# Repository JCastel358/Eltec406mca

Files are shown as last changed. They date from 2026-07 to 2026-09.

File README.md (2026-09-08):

# Eltec sensor test rigs

Bench rigs and software that qualify Eltec pyroelectric IR sensors. Two rigs
live in this repository, one top-level folder each:

- **`single_detector_rig/`** — an ESP32 chops an IR emitter and streams a
  24-bit ADS1256 ADC to a laptop; one Python desktop application runs the
  test procedure for the sensor model chosen in a dropdown, judges each part,
  and writes a CSV row per sensor.
- **`array_rig/`** — fifty detectors at once: a 50-position buffer PCB read
  by an ACCES USB-AIO16-64MA DAQ; the same selector-plus-model-directory
  structure, testing offset and noise per tray (sensitivity waits for the
  emitter board).

Windows 11 and Xubuntu are both supported.

| Sensor model | Procedure | Status (2026-09-02) | Results folder (`Documents\…`) |
| --- | --- | --- | --- |
| **405 M22** (1 Hz) | TP412 — offset, emitter-off noise, sensitivity/polarity | production; sensitivity factor 4.30 from lot 500 | `Eltec_405M22_Test_Results\405m22_esp32` |
| **406 MCA** (10 Hz) | offset, sensitivity/polarity, v6.1 stability policy | production; factor 1.582 from lot 520 | `Eltec_406MCA_Test_Results\v6_1_esp32` |
| **449 M18** (5 + 18 Hz) | TP443 frequency tracking | **calibration pending** (K_5 / K_18 not derived; needs firmware v3.2, not yet flashed) | `Eltec_449M18_Test_Results\449m18_esp32` |
| **40623 array** (50 positions, DAQ) | TP120 offset check + noise, fifty at a time | **calibration pending** (noise limits not derived, offset limits provisional; raw captures saved for the paired lot) | `Eltec_40623_Test_Results\40623_array_daq` |

---

## I'm a technician — run a batch

1. Laptop on AC power, ESP32 USB cable in, both batteries connected, no fans near the fixture.
2. Double-click the **Eltec Test Rig** desktop icon (or `single_detector_rig\run_eltec_rig_tester.cmd` / `.sh`). For a tray of fifty on the array rig use the **Eltec Array Rig** icon (`array_rig\run_eltec_array_tester.cmd` / `.sh`) — runbook §3b.
3. Pick the sensor model → **Start tester** → batch number, your name, filter setup → load a part → **Enter**.
4. Read the banner (PASS / PASS · NEAR LIMIT / FAIL) → load the next sensor →
   **Next (Enter)**. The number only advances when a part passes.

Everything else — verdicts, the Stop / Next buttons, where files go,
what to do when something fails — is in
**[docs/TECHNICIAN_RUNBOOK.md](docs/TECHNICIAN_RUNBOOK.md)**.

## I'm the engineer taking over

Start with **[docs/ENGINEER_HANDOVER.md](docs/ENGINEER_HANDOVER.md)** (what
you are inheriting, architecture, the copy-per-model rule, firmware lifecycle,
open work). Then **[docs/CALIBRATION_RECORD.md](docs/CALIBRATION_RECORD.md)**
before touching any limit.

## Repository map

```
README.md                    this file — the index
CHANGELOG.md                 dated history, newest first (one entry per behavioural change)
CLAUDE.md                    ground rules for AI-assisted sessions
run_all_tests.py|.cmd|.sh    runs every test suite of both rigs, prints a summary
docs/
  TECHNICIAN_RUNBOOK.md      operator instructions
  ENGINEER_HANDOVER.md       engineering manual + open work
  CALIBRATION_RECORD.md      every limit/factor/gate state with provenance  ← source of truth for numbers
  DATA_MAP.md                where results & evidence live (outside the repo) + backup routine
  TP120(40623).pdf           test procedure of the 40623 (array rig); daq_usb_aio16_64ma/ = DAQ vendor docs
single_detector_rig/         THE single-detector application — selector + one directory per sensor model
  eltec_rig_tester.py        selector GUI (dropdown → launches the model app)
  sensor_versions.py         model registry + required firmware
  attempt_history.py         per-batch attempt log (shared)
  v1_single_sensor/          vendored signal-math engine (shared, frozen)
  m405m22/ m406mca/ m449m18/ one qualified tester each: GUI, backend, analysis, tests, launchers, README
  run_eltec_rig_tester.*     launchers; install_*_launcher.* = optional desktop icon
array_rig/                   THE array application — selector + one directory per detector model (same pattern)
  eltec_array_tester.py      selector GUI (model dropdown → launches the model app)
  sensor_versions.py         model registry + required hardware (DAQ)
  tray_history.py            per-lot tray event log (shared)
  m40623/                    the 40623 build: GUI, DAQ backend (ctypes AIOUSB.dll), numpy noise port, probe, bench readout + live viewer, tests, launchers
Arduino/Eltec/               firmware (single rig today; the array rig's emitter board will use it later)
  Eltec.ino                  live sketch (v3.2)        README.md = protocol, flashing, troubleshooting
  versions/                  frozen copy of every build + which firmware belongs on which rig
  flash_firmware.py          one-command compile/upload/verify (+ run_flash_firmware.cmd/.sh)
  esp32_rig_readout.py, live_waveform.py   bench tools
  ESP32_ADS1256_Wiring_v2_0.md             current wiring (…_legacy_v1_9.md = retired standalone 406 rigs)
engineer_tools/              engineering-only tools, one folder per topic (README.md inside lists them)
  noise_band/                replot_noise_capture.py (replay raw noise captures under any band), filter_response_analysis.py
  array_parity/              array_noise_parity.py (derive the array rig's pin-level noise limits from a paired lot)
  emitter/                   emitter_waveform_comparison.py (legacy chopper vs rig emitter waveform shape)
  reference_unit/            reference_candidate_qualifier.py (pick the detector to mount as the AIN1 reference unit)
analysis/
  405M22_Data/               lot-500 paired-fixture data behind the 4.30 factor
  reports/                   noise-filtering explainer, historical buffer/SNR write-ups
assets/eltec_logo.png        logo loaded by the apps
```

Retired applications (LabJack-era v1–v4, ESP32 v5/v6/v6.1, the standalone
405m22 build, the pre-v2.0 unified app) were removed from the tree on
2026-08-28 and are preserved at git tag **`archive/pre-cleanup-2026-08-28`**:
`git show archive/pre-cleanup-2026-08-28:<path>`.

## Firmware

The single-detector bench board must run `Arduino/Eltec/Eltec.ino` **v3.2** for all three
models (the array rig has no firmware: its DAQ loads its own from the ACCES driver package) (it currently runs v3.1; the 405 M22 and 406 MCA modes work on
v2.1–v3.2, the 449 M18 mode needs v3.2). Flash and verify with one command:

```
python Arduino/Eltec/flash_firmware.py          # --check to only ask what the board runs
```

Firmware guide: [Arduino/Eltec/README.md](Arduino/Eltec/README.md). Which
build belongs on which rig (legacy 406 rigs stay on v1.9):
[Arduino/Eltec/versions/README.md](Arduino/Eltec/versions/README.md).

## Tests

```
python run_all_tests.py
```

Six `unittest` suites (four for the single rig, two for the array rig), 705
tests, no hardware needed. On Windows the 406 MCA suite reports two known
environment-only cases (they pass on Xubuntu) — see the handover doc §7.

## Where the data is

Results, attempt logs, waveform snapshots, raw noise captures and calibration
files are written **outside this repository** under
`Documents\Eltec_<model>_Test_Results\`. They are the only copy of the evidence
behind the production constants — the backup routine is in
[docs/DATA_MAP.md](docs/DATA_MAP.md).

## Documentation index

| Document | Audience | Contents |
| --- | --- | --- |
| [docs/TECHNICIAN_RUNBOOK.md](docs/TECHNICIAN_RUNBOOK.md) | technician | start, run a batch, read verdicts, troubleshoot |
| [docs/ENGINEER_HANDOVER.md](docs/ENGINEER_HANDOVER.md) | engineer | architecture, policies, procedures, open work, conventions |
| [docs/CALIBRATION_RECORD.md](docs/CALIBRATION_RECORD.md) | engineer | constants + provenance + gate states per model |
| [docs/DATA_MAP.md](docs/DATA_MAP.md) | engineer | results layout, evidence, backup |
| [single_detector_rig/README.md](single_detector_rig/README.md) | engineer | the selector app, launchers, v2.0 skip/attempt features |
| [m405m22/README.md](single_detector_rig/m405m22/README.md) · [m406mca/README.md](single_detector_rig/m406mca/README.md) · [m449m18/README.md](single_detector_rig/m449m18/README.md) | engineer | per-model test mechanics |
| [array_rig/README.md](array_rig/README.md) · [m40623/README.md](array_rig/m40623/README.md) | engineer | the array rig: selector, DAQ chain, the 40623 flow, colours, files, PENDING status, the engineering tools (bench probe, readout, live viewer) |
| [docs/TP120(40623).pdf](docs/TP120(40623).pdf) · [docs/daq_usb_aio16_64ma/](docs/daq_usb_aio16_64ma/) | engineer | the 40623 test procedure; DAQ datasheet, DAQ-PACK guide, letter of volatility |
| [Arduino/Eltec/README.md](Arduino/Eltec/README.md) · [versions/README.md](Arduino/Eltec/versions/README.md) | engineer | firmware, protocol, flashing, version archive |
| [CHANGELOG.md](CHANGELOG.md) | both | what changed, when, why |

## Dependencies

Python 3 with `tkinter`, `numpy`, `pyserial`, `matplotlib` (optional, nicer
snapshots). The array rig additionally needs the ACCES **USB-AIO16-64MA
Install** driver package (provides `AIOUSB.dll`) and a **64-bit** Python; no
extra Python packages. Xubuntu: `sudo apt install python3 python3-tk python3-numpy
python3-serial python3-matplotlib`, user in `dialout`. Flashing needs the
Arduino IDE 2.x installed (its bundled `arduino-cli` is used).

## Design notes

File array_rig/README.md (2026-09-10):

# Eltec Array Rig — fifty detectors at once on a USB DAQ

The second test rig of this repository. A 50-position PCB (5 rows × 10
columns, one unity-gain buffer per position) feeds the 64 single-ended inputs
of an **ACCES I/O USB-AIO16-64MA DAQ-PACK**; one Python desktop application
tests a whole tray of detectors per run. It mirrors the single-detector rig
(`../single_detector_rig/`) in structure: a **selector** with a model
dropdown, a **registry**, and **one directory per detector model** that is a
deliberate near-copy of its siblings. The two rigs share nothing but the
repository, the docs and (later) the ESP32 firmware for the emitter board.

| Model | Procedure | What it measures today | Status | Results (`Documents\…`) |
| --- | --- | --- | --- | --- |
| **40623** | TP120 rev W | offset check (0.3–1.2 V) and noise, fifty at a time | **CALIBRATION PENDING** — noise limits not derived, offset limits provisional | `Eltec_40623_Test_Results\40623_array_daq` |

Sensitivity / polarity (TP120's 3 Hz chopper test) waits for the emitter
board. The operator screen focuses on offset and noise, with the Eltec logo
and a 5 × 10 map of round detector sockets labelled by row and column.
Sockets always show numerical offsets and, after capture, noise alongside status.
**Show more** adds assigned sensor numbers. **Choose loaded sockets** supports
partial trays; changes require a fresh offset measurement.

## Technician flow

1. Enter **Tech name** and **Batch number**. Load up to fifty detectors.
2. Use the rig's **physical power switch immediately before pressing
   Measure offset**. The app connects to the DAQ and reads the signals; it
   does not switch detector power or vacuum. Empty-looking sockets are
   rechecked together after two seconds and marked grey automatically.
   Green means offset in range; red means out of range. Low or dead-looking
   readings can still settle: recheck before discarding a part.
3. Replace red parts and press **Measure offset** again, as often as needed.
   If replacements run out, remove the remaining bad parts and measure
   offset again so empty sockets are detected. A socket marked loaded again
   requires a fresh offset read.
4. Turn on the vacuum, wait for the gauge to reach the required setting,
   and confirm both the vacuum setting and that the detected detector count
   and map match the physical tray. Press **Measure noise** once all loaded
   sockets have good offsets. The app checks waveform settling for 3–20
   seconds, then captures sixty seconds of noise.
5. Read the socket colours and status. Use **Show more** for measurements
   and assigned sensor numbers. Results save automatically; use
   **Next tray** after the save completes. **Stop** interrupts a measurement
   so it can be retried.

Tray and sensor numbers are automatic. Every offset read is retained for
audit, including reads taken before a detector is replaced. Automatic empty
detection is an inference: both median offset reads must be within one ADC
code of zero (about 76 µV on the 0–5 V range). A dead or shorted detector can
also read zero, so check the detected map and count before noise. Click a
socket containing a detector to mark it loaded; that manual choice wins
over automatic detection. The vacuum check is the operator's gauge
confirmation; the app has no pressure telemetry or configured vacuum setpoint.

Settling compares each loaded channel's one-second waveform maximum and
minimum. Two consecutive changes within 0.1 mV allow capture to start after
three seconds. At twenty seconds capture starts with a recorded warning
if the signal has not settled. This tolerance schedules capture and does
not decide pass/fail. The user's 2026-09-08 timing decision removes the
app's five-minute countdown: TP120 itself separately calls for five minutes
after power-on and 15–20 seconds after switching detectors on the legacy
fixture. The changed timing policy and settling evidence are logged.

Noise uses the nominal **3 Hz/Q=3 band-pass** from fixture 9000232, with RMS
and rectified metrics. Paired legacy/background qualification is still pending:
valid measurements show amber **REVIEW**, and both the app and CSV explicitly
withhold PASS. Short/clipped/unresolved data remains NOT MEASURED. See
[m40623/NOISE_METHOD.md](m40623/NOISE_METHOD.md) for the method, calibration
contract and replay tool. Simulation demonstrates example passes and failures.

## Run it

- Windows: double-click the **Eltec Array Rig** desktop icon, or
  `array_rig\run_eltec_array_tester.cmd`. Install the icon once with
  `powershell -ExecutionPolicy Bypass -File array_rig\install_windows_launcher.ps1`.
- Xubuntu: `./array_rig/run_eltec_array_tester.sh`; icon via
  `./array_rig/install_xubuntu_launcher.sh` (`--uninstall` removes it).
- The selector remembers the last model (`%LOCALAPPDATA%\eltec-array-rig\state.json`
  / `~/.local/state/eltec-array-rig/state.json`) and launches the model app
  as a **subprocess** with the model directory as cwd. Launcher logs:
  `…\eltec-array-rig\launcher.log`. The model app can also be started
  directly (`array_rig\m40623\run_eltec_40623_array_tester.cmd`). Check
  **Simulation** in the selector, or use `--simulate` (or
  `ELTEC_ARRAY_SIMULATE=1`), to run without hardware.
- Hardware: the ACCES **"USB-AIO16-64MA Install"** driver package must be
  installed (it provides `AIOUSB.dll`; the DAQ loads its firmware from the
  host at every plug-in, so allow a few seconds after connecting). A 64-bit
  Python is required (the 64-bit DLL lives in `System32`). No extra Python
  packages beyond the single rig's (`numpy`, `tkinter`, `matplotlib` for
  the grid snapshot).
- Engineering tools (no verdicts, files only at explicit paths), all in
  `array_rig\m40623\` and all with `--simulate`: `daq_bench_probe.py` (bench
  checks), `daq_rig_readout.py` (offsets, captures to CSV / npz, text-mode
  watch) and `daq_live_waveform.py` (rolling scope of any position) — see the
  m40623 README. Only one program can own the DAQ: close the tester before
  running one of them, and vice versa (a second program is not refused — it
  silently takes the stream away from the first).

The single-detector rig and this rig can run at the same time — different
hardware, different state folders.

Simulation shows a **SIMULATION** badge and runs the same operator flow on
a fast virtual clock. Click a red or empty socket to simulate loading a
replacement, then measure offset again; right-click to mark a socket empty.
Demo noise limits belong only to that simulator instance and results carry
a simulation flag and **SIMULATION ONLY** noise-limit provenance. Demo
files go under `tempfile.gettempdir()/eltec-array-simulation`, or the
`simulation` subfolder when `ELTEC_ARRAY_RESULTS_ROOT` is set.

## Layout

```
array_rig/
  eltec_array_tester.py      selector GUI: model dropdown → launches the model app as a SUBPROCESS
  sensor_versions.py         registry (one SensorVersion per model) + REQUIRED_HARDWARE
  tray_history.py            shared: <lot>_attempts.csv writer (tray events) + numbering helpers
  run_eltec_array_tester.*   launchers; install_*_launcher.* = optional desktop icon
  tests/                     selector glue + tray history
  m40623/                    the 40623 build (TP120) — see its README
      eltec_40623_array_tester.py   GUI + flow + limits + CSV/npz/PNG writers (TrayController is the Tk-free core)
      daq_backend.py                ctypes wrapper over AIOUSB.dll, de-interleave, stream integrity, SimulatedDaq
      array_analysis.py             numpy port of the single rig's noise DSP + TP120 offset classes + verdict model
      daq_bench_probe.py            engineering CLI (never issues verdicts)
      daq_rig_readout.py            engineering readout: ArrayRig API + CLI (offsets, captures to CSV / npz, text-mode watch) — the ESP32 readout's counterpart
      daq_live_waveform.py          engineering live viewer: matplotlib rolling scope of any position + the 5 x 10 grid — live_waveform.py's counterpart
      tests/                        unit + flow tests; golden_noise_reference.py is the frozen DSP oracle
      run_… / install_…             per-model launchers
```

Ownership rule inside a model directory: `daq_backend.py` is the hardware
boundary (no Tk), `array_analysis.py` is pure math (no I/O, no hardware), the
tester owns orchestration, UI and files; the probe, the readout and the live
viewer are engineering only — no verdicts, output files only at explicit
paths (never under `Documents`), and only one program on the DAQ at a time.

## Adding a model

The single rig's copy-per-model rule applies here, and additionally
**nothing is imported across the two rigs** (the only link is a frozen copy
of the 405 M22 noise functions used as a test oracle).

1. Copy `m40623/` to `m<model>/`, rename the tester and launcher identities
   (`eltec-<model>-array`, `com.eltec.<model>-array-tester.desktop`), and
   replace the spec constants in `array_analysis.py` (offset window, noise
   limits — `None` until derived) with provenance comments.
2. Append a `SensorVersion` to `sensor_versions.py` and extend the expected
   key set in `tests/test_eltec_array_rig.py`.
3. Add the suite to `run_all_tests.py`, a section to
   `docs/CALIBRATION_RECORD.md` (CALIBRATION PENDING until a paired lot
   exists — the 40623 section shows the pattern) and the results root to
   `docs/DATA_MAP.md`. CHANGELOG entry in the same commit.

## Tests

```
python run_all_tests.py                                        # every suite of both rigs
python -m unittest discover -s array_rig/tests                 # selector glue + tray history
python -m unittest discover -s array_rig/m40623/tests          # backend, analysis (golden parity), tester flow, readout, live viewer (Agg), engineer tools
```

Stdlib `unittest`, from the repository root, no hardware needed (the tests
use a scripted fake DLL and `SimulatedDaq`, and redirect the results root to
a temporary directory).

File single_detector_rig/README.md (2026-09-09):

# Eltec Test Rig — unified sensor tester

**2026-09-02 — two buttons (Stop, Next) and a number only a PASS can spend.**
See [Test flow](#test-flow) below; the v2.0 skip queue it replaced is in
`CHANGELOG.md`. Every
older app (`405m22_esp32`, `v6_1_esp32`, `v6_esp32`, `v5_esp32`, the v1–v4
LabJack apps, `v6_1_failure_calibration`) and a frozen snapshot of this app
as it was before v2.0 (`eltec_rig_v1`) were removed from the working tree on
2026-08-28; they are preserved in full at git tag
`archive/pre-cleanup-2026-08-28`
(`git show archive/pre-cleanup-2026-08-28:tech_app/deprecated/<app>/<file>`).

One desktop application for every sensor model the ESP32/ADS1256 rig can
test. It opens **maximized** and shows a **sensor version dropdown**; picking a
version and pressing **Start tester** runs that model's qualified tester
application unchanged — same test flow, thresholds, per-batch filter-setup dropdowns, CSV
format, and results folders as before. The selection is remembered between
sessions.

```
single_detector_rig/
├── eltec_rig_tester.py          # the selector GUI (this app's entry point)
├── sensor_versions.py           # registry: one entry per testable model
├── attempt_history.py           # per-batch *_attempts.csv event log (shared by all models)
├── m405m22/                     # Model 405 M22 (1 Hz, TP412) tester + its 165-test suite
├── m406mca/                     # Model 406 MCA (10 Hz, v6.1 policy) tester + its 99-test suite
├── m449m18/                     # Model 449 M18 (5 Hz + 18 Hz, TP443 frequency tracking) tester + suite
├── v1_single_sensor/            # shared 406MCA analysis/pass-fail engine (vendored)
├── assets/                      # desktop icon (.png for Linux, .ico for Windows)
├── run_eltec_rig_tester.sh      # Xubuntu launcher        ┐ double-click either
├── run_eltec_rig_tester.cmd     # Windows launcher        ┘ on its platform
├── install_xubuntu_launcher.sh  # opt-in Desktop + menu entry (`--uninstall` removes)
├── install_windows_launcher.ps1 # opt-in Desktop + Start Menu (`-Uninstall` removes)
└── tests/                       # selector/registry/launcher glue tests
```

## Sensor versions

| Dropdown entry | App | Emitter drive | ADS1256 front end | Results |
| --- | --- | --- | --- | --- |
| Model 405 M22 (1 Hz, TP412) | `m405m22/` | DUT 1 Hz, reference phases 10 Hz | firmware boot default (gain 1, buffer off) | `Documents/Eltec_405M22_Test_Results/405m22_esp32` |
| Model 406 MCA (10 Hz) | `m406mca/` | 10 Hz (boot default) | app sends `FE,V19` after connect → gain 2, buffer on (the qualified v1.9 front end) | `Documents/Eltec_406MCA_Test_Results/v6_1_esp32` |
| Model 449 M18 (5 Hz + 18 Hz, TP443) | `m449m18/` | DUT 5 Hz then 18 Hz, **20 % ON / 80 % OFF** (`PWM,DUTY`, firmware **v3.2**); reference phases 10 Hz / 50 % | firmware boot default (gain 1, buffer off) | `Documents/Eltec_449M18_Test_Results/449m18_esp32` |

The 449 M18 entry (added 2026-08-26) runs TP443 "449M18 Frequency Tracking":
sensitivity at 5 Hz, sensitivity at 18 Hz, and the 18/5 ratio, with the
spec-4 "measure the tray 100 %" flag. It is **calibration pending** — the
per-frequency fixture factors have not been derived yet, so it records raw
readings and the raw ratio and does not enforce the TP443 limits. See
[`m449m18/README.md`](m449m18/README.md).

Model-specific dropdowns (filter cap / filter setup, simulator cases, etc.)
live **inside** each model's app, exactly where they were before — choose the
sensor version first, then the batch's filter setup on the Batch information
screen.

## Firmware

The bench board runs the unified **`Arduino/Eltec/Eltec.ino` v3.2** baseline
(single-channel streaming, `PWM,FREQ`, `PWM,DUTY` (v3.2), runtime `FE,...`
front-end switch; the IR telescope's dual-channel code is *not* in it — that
lives in the separate `Eltec_IR_Telescope` workspace on firmware v2.2). The
405 M22 and 406 MCA modes also run on v2.1–v3.1; the 449 M18 mode refuses
anything older than v3.2 because it needs the duty-cycle command. Model
differences are selected at runtime over serial:

- **405 M22**: never sends `FE`; every port open resets the board to the
  boot-default gain-1 unbuffered front end, and the app programs `PWM,FREQ,1`
  for the DUT phases.
- **449 M18**: never sends `FE` either; programs `PWM,FREQ,5` + `PWM,DUTY,20`
  and then `PWM,FREQ,18` + `PWM,DUTY,20` for the two TP443 drives (the legacy
  fixture's 20/80 blade), `PWM,FREQ,10` + `PWM,DUTY,50` for the reference
  phases. A port open resets the board to 50 %, so the other models never
  see the changed duty.
- **406 MCA**: sends `FE,V19` right after the `IDN?` handshake on any
  firmware ≥ v2.1 and hard-verifies the `FE?` read-back — measuring a 406MCA
  on the wrong front end would invalidate every qualified threshold, so a
  mismatch refuses the connection. On a legacy standalone rig still flashed
  with v1.9, no `FE` command is sent (that firmware is natively the
  qualified front end).

Flash/verify - one command, no Arduino IDE needed (it finds the IDE's bundled
`arduino-cli`, auto-detects the board's port, compiles, uploads, then confirms
`IDN?`/`GATE?` over serial):

```bash
python3 Arduino/Eltec/flash_firmware.py
```

Windows: double-click `Arduino\Eltec\run_flash_firmware.cmd`. Xubuntu:
`Arduino/Eltec/run_flash_firmware.sh`. Useful flags: `--list` (show serial
ports), `--check` (report what the board runs, flash nothing), `--port COM7`,
`--sketch versions/Eltec_v2_2` (put the board on an archived build). The
equivalent by hand:

```bash
arduino-cli compile --fqbn esp32:esp32:esp32doit-devkit-v1 Arduino/Eltec
arduino-cli upload -p COM3 --fqbn esp32:esp32:esp32doit-devkit-v1 Arduino/Eltec
# then confirm: IDN? -> ELTEC-ESP32-ADS1256,v3.1
```

## Fixture notes (2026-08-18)

- **Battery monitoring is disabled in both models** (`BATTERY_MONITORING_ENABLED
  = False` in each tester): since the 2026-08-12 rewiring the 6.5 V battery
  drives the emitters only, the 9 V battery drives the sensors, and neither is
  measurable on the legacy AIN7 divider. The header shows "Battery: not
  monitored". Re-enable per model once the sensor battery is measurable (the
  plan is AIN6 through a ≥4:1 divider).
- **All three models' reference gates are live again** (`REFERENCE_GATE_ENABLED
  = True` since 2026-09-09, on the channel-isolated buffer board). AIN1 is
  read before every sensor and must hold its ±25 % window, so a failing
  emitter is caught by the rig instead of showing up as a run of
  low-sensitivity parts. **Every rig must run "Calibrate reference unit"
  before its next batch**: the stored baselines were all recorded through the
  old shared op-amp buffer and are refused on load (schema bump), so testing
  stays locked until a fresh one exists. The crosstalk re-check on the new
  board is still outstanding — if the reference turns out to still follow the
  loaded part, set the flag back to `False` rather than widening the window
  (calibration record §2.4).

## Running it

| | Xubuntu | Windows |
| --- | --- | --- |
| run | `./single_detector_rig/run_eltec_rig_tester.sh` | double-click `single_detector_rig\run_eltec_rig_tester.cmd` |
| desktop icon | `./single_detector_rig/install_xubuntu_launcher.sh` | `powershell -ExecutionPolicy Bypass -File single_detector_rig\install_windows_launcher.ps1` |
| log | `~/.local/state/eltec-rig/launcher.log` | `%LOCALAPPDATA%\eltec-rig\launcher.log` |

Both installers are opt-in and per-user (`--uninstall` / `-Uninstall` to
remove). `ELTEC_PYTHON` overrides the interpreter on both platforms;
`ELTEC_LAUNCHER_NO_DIALOG=1` suppresses the Windows error popup for headless
runs. Dependencies are the same as the individual apps: Python 3 with
`tkinter`, `numpy`, `pyserial`, and `matplotlib` (see each model's README).

The selector remembers the last-used sensor version in
`~/.local/state/eltec-rig/state.json` (Xubuntu) /
`%LOCALAPPDATA%\eltec-rig\state.json` (Windows). Only one tester can run at a
time — both models share the same board and serial port.

## Test flow

### Two screens and two buttons (2026-09-02)

There are two steps — **Batch information** and **Measure & result** — and
the action bar carries exactly two controls:

| Button | Colour | When shown | What it does |
| --- | --- | --- | --- |
| **Stop** / **Stop batch (Esc)** | **red** | every moment of a batch, never disabled | mid-capture: abandons the reading (nothing recorded, the number does not move). Idle: writes an unsaved verdict (no prompt since 2026-09-03), then ends the batch |
| **Start (Enter)** → **Next sensor (Enter)** | blue → **green** | setup → result | reads the sensor that is in the rig now; on a verdict it writes the row first |

The technician loads a part, presses Start (first) or Next (every one after)
and the read begins immediately — there is no "load the next sensor" screen
in between, because the part is loaded before the button is pressed. The old
load STEP's card (rig picture, and the 405's noise-soak toggle) moved onto
the setup screen; the 405 soak toggle also sits on the result card, where it
arms the read **Next** is about to take, and `run_measurement` clears it as
it starts so it never carries into a second part.

**Stop is the only control that is never disabled.** It works mid-capture
because it bumps `measure_token`, which the capture loops already poll
through their `cancelled=` callback: the loop raises at its next chunk
boundary, the worker's own `finally` blocks stop the stream and switch the
emitter off, and every callback that worker posts afterwards is ignored by
the token guard. A `stopped` row goes into the attempt log; no verdict row is
written.

**The bar always fits the window** (`_fit_footer`, all models). Two full-size
buttons fit any rig screen, but the blocked-measure labels ("Calibrate
reference unit to test") still need the ladder the six-button bar did: it
measures what the visible buttons need and takes the first
`FOOTER_VARIANTS` step that fits, preferring big buttons over spelled-out
labels:

1. full labels, one row;
2. drop the `(Enter)` / `(Esc)` hints (the shortcuts still work);
3. compact wording — *Next*, *Stop*, *Calibrate reference first*;
4. wrap the action buttons onto their own row, still full size;
5. only then step the buttons down a size.

It is bound to the footer's `<Configure>`, so it re-fits when the window is
maximized or resized — including growing back to full labels — and it works
the same on Windows and Xubuntu (the fit is measured from the actual font
metrics, not a hardcoded width). The "nothing was recorded" view keeps its
**Record as NOT MEASURED** option (writes the NOT MEASURED verdict row);
Next there simply reads the same sensor again.

There is no Re-measure button, which is a real trade-off: a verdict already
on screen cannot be discarded. It is saved as what it says — on a FAIL that
costs nothing, because the number stays open — or the reading is stopped
before it finishes so nothing is written at all.

### A sensor number is only spent by a PASS

`next_sensor_number_for_batch` returns one past the highest **PASSED** number
in the batch CSV. A FAIL, or a NOT MEASURED row, leaves the number open: the
next part loaded into the rig is tested as the same number, which is what the
bench already does physically — a bad part is set aside and another takes its
place. Whichever part finally passes is the one that ships under that number.

Consequences:

- A batch CSV is **one row per test**, not one row per number. `500-7` can
  appear several times, the last of them the PASS. Yield counts rows, so the
  failures are still all in it.
- **`number_attempt`** (1-based) says which part under that number a row is;
  **`measure_attempts`** counts the reads of one part and starts over for
  each replacement. Both are the last two CSV columns; `number_attempt`
  replaced `skip_count` in the same position on 2026-09-02.
- Deriving from the highest PASSED number (not from a count of passes) leaves
  batches written before the rule intact: their numbers were handed out per
  row, so a file whose last pass is `500-9` continues at `500-10`.

### Attempt history (what happened to this part?)

Each batch has a sibling **`<lot>_attempts.csv`** next to its results CSV
with one row per event: `measured` (every finished measurement with its
verdict, offset, sensitivity, polarity, noise worst pk-pk, fail reasons),
`measure_error` (nothing recorded + the rig error), `stopped` (the
technician pressed Stop during a capture), `saved`. Older batch CSVs keep
their header (rows stay aligned, newer columns are simply absent). Autosave
payloads carry `measure_attempts` and `number_attempt`.

### Shorted / dead sensor vs. empty slot (both models)

A shorted or dead part floats AIN0 exactly like an empty slot. Instead of a
hard "No sensor detected" wiring error, the app now asks **"Is a sensor
loaded?"** — *Yes* records the part as a FAIL with no offset (failure mode
preset to **SB - Sensor bad**, reason "No offset: AIN0 reads x V with a
sensor loaded"), ready to save; *No* keeps the old behaviour (nothing
recorded, seat the sensor and measure again).

### Reference gates disabled (2026-08-17 / 08-24), re-enabled (2026-09-09)

The shared dual op-amp buffer had no channel isolation, so the sensor under
test coupled into AIN1 and the reference could not be calibrated:
`REFERENCE_GATE_ENABLED = False` on the 405 M22 from 2026-08-17 and on the
406 MCA and 449 M18 from 2026-08-24. No calibration was required to test, the
setup card said "Reference gate disabled (op-amp crosstalk)", and the
`reference_*` CSV columns stayed blank.

With the buffer replaced by a channel-isolated **TI OPA2196** (the old one
let a shorted DUT pull AIN1 down ~90 %), all three flags went back to
`True` on **2026-09-09** and the `reference_*` columns are populated again;
a reference lockout now also writes a `measure_error` row to `_attempts.csv`.
The stored baselines are refused (schema 4 → 5 on the 405/449, 2 → 3 on the
406) because they were measured through the old shared buffer, so each rig
locks testing until "Calibrate reference unit" is run fresh; the old files
stay in the results folders as evidence. The gate-off path is still
unit-tested in every model, so the flag can go back to `False` in one line if
the outstanding crosstalk re-check shows AIN1 still following the DUT — that,
not a wider `REFERENCE_TOLERANCE_PERCENT`, is the correct response.

### Selector opens full screen (2026-08-25)

`eltec_rig_tester.py` starts maximized like each model's tester (Windows
`state("zoomed")`, X11 `-zoomed` applied once mapped, screen-sized geometry
as a last resort), and re-applies it when a tester closes and the selector
un-minimizes. The window is resizable now (a fixed-size window cannot be
maximized) with a 640×520 floor, and its one content block is centered by
weighted spacer rows/columns so a wide monitor grows the margins, not the
card. Type is a step larger to stay readable full screen.

### Tests

`tests/test_attempt_history.py` (23 tests: the attempt-log module, and the
earned-number rule plus the Stop / Next flow driven through ALL THREE
models' real `EmitterTesterApp` methods, plus the footer palette). Each
model suite carries the same numbering / Stop / Next checks against its own
copy of the app. Existing verdict logic, thresholds and calibrations are
untouched.

## Tests

```bash
python3 -m unittest discover -s single_detector_rig/tests            # selector glue
python3 -m unittest discover -s single_detector_rig/m405m22/tests    # run from the repo root
python3 -m unittest discover -s single_detector_rig/m406mca/tests    # run from the repo root
python3 -m unittest discover -s single_detector_rig/m449m18/tests    # run from the repo root
```

On Windows the m406mca suite reports one long-standing environment-only
error (the POSIX bash-installer test); it passes on Xubuntu.

## Adding the next sensor version

See the docstring at the top of `sensor_versions.py`. Short version: add an
app directory (copy the closest model), append one `SensorVersion` entry, and
extend the firmware with runtime commands only if the model needs behavior
the unified v3.x firmware cannot already select over serial. Also register the
suite in `run_all_tests.py` and add the model to `docs/CALIBRATION_RECORD.md`
and `docs/DATA_MAP.md`.

## History

Created 2026-08-18 by unifying `tech_app/405m22_esp32` and
`tech_app/v6_1_esp32` behind one selector. Those original directories were
kept untouched as the qualified standalone builds (moved to
`tech_app/deprecated/` with v2.0 on 2026-08-24) until 2026-08-28, when the
whole deprecated tree was removed from the working tree — it is preserved at
git tag `archive/pre-cleanup-2026-08-28`. New work on every model happens
**here**. The changes made to the bundled copies relative to the originals:

- `m406mca/esp32_backend.py`: selects the qualified front end (`FE,V19` +
  `FE?` verification) on firmware ≥ v2.1.
- `m406mca/eltec_406mca_esp32_tester.py` and `m406mca/stability_calibration.py`:
  battery gate behind `BATTERY_MONITORING_ENABLED = False` (mirroring the
  405 M22 build), because the unified fixture has no battery on AIN7.
- `m406mca` tests updated for both changes (99 tests); `m405m22` is
  byte-identical to `405m22_esp32` apart from the removed `prompt.txt`.
- `v1_single_sensor/eltec_406mca_tester.py` vendored so the package is
  self-contained.

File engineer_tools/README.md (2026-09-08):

# engineer_tools — engineering-only tools, one folder per topic

Nothing here issues a part verdict or is run by a technician. Every tool is
run from the repository root with the bench Python (stdlib + numpy;
matplotlib optional for plots) and reads the production code of the rig it
belongs to **by import, never by copy**, so a change in an app is picked up
automatically. Outputs go to explicit paths or to their own folder under
`Documents` — never into an `Eltec_*_Test_Results` evidence folder unless the
tool's docstring says so (the parity tool writes `calibration/` under the
array results root, by design; see `docs/DATA_MAP.md`).

| Folder | Tool | What it is for | Rig |
| --- | --- | --- | --- |
| `noise_band/` | `replot_noise_capture.py` | Replay saved raw noise captures (405 `*_noise_raw.npz`, array `tray_*_raw.npz`) through the production pipeline and any other band / boxcar; verdict comparison table + PNG per capture. | 405 M22, 40623 array |
| `noise_band/` | `filter_response_analysis.py` | Measure the noise pipeline's real passband and aliasing; test legacy-amplifier passband hypotheses against a capture's spectrum. | 405 M22 |
| `array_parity/` | `array_noise_parity.py` | Derive the array rig's pin-level noise limits from a lot measured on both the legacy fixture and the array rig (CALIBRATION_RECORD §4b.2). | 40623 array |
| `emitter/` | `emitter_waveform_comparison.py` | Legacy chopper vs rig emitter waveform *shape* (rise/fall, harmonics) — the 18 Hz pre-qualification for the 449 M18 app. | 449 M18 |
| `reference_unit/` | `reference_candidate_qualifier.py` | Measure candidate 406MCA detectors through the production 406 MCA path (offset settling, 10 Hz response stabilization, repeatability, drive-hold drift, post-emitter recovery) and rank them for the permanently mounted AIN1 reference unit. `README.md` in the folder is the bench procedure. | 406 MCA (single rig) |

Each moved tool keeps its own docstring with the exact command lines. Tests:
`array_rig/m40623/tests/test_engineer_tools_array.py` (parity, replot) and
`single_detector_rig/m406mca/tests/test_reference_candidate_qualifier.py`
(reference-unit qualifier, simulated round trip).

Adding a tool: put it in the folder of the topic it belongs to (or a new
folder if none fits), set `REPO_ROOT = Path(__file__).resolve().parents[2]`
and import the production module it needs from the model directory, add a
row here and in `docs/DATA_MAP.md` §4 / `docs/ENGINEER_HANDOVER.md` §9, and
give it a test in the suite of the rig whose code it imports.

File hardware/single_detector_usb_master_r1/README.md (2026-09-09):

# Single detector rig — USB master power, revision 1

**Routed engineering prototype candidate. Not a fabrication release.**

This separate project replaces the supplied ESP32 carrier while preserving the original files in `source_reference/`. Its required behavior is that the upstream USB switch starts and stops the complete rig, including both HeyFuture LiFePO4 6.4 V, 6 Ah battery domains, with the ADC protected throughout startup and shutdown. The emitter maximum stated current is 200 mA. Component selection is independent of the IRLB8748s available for the earlier perfboard idea.

The deliverable is an editable, electrically connected KiCad design with routed PCB, project libraries, assembly BOM/CPL, assembly views, draft fabrication exports, and reproducible ERC/DRC/parity checks. All physical board components are to be populated except the ESP32 module, ADS1256 module, and two barrel jacks. Module sockets are populated components. Original wire solder lands are copper features, not fictitious purchased parts.

Use `PLAN.md` for milestone status, `DECISIONS.md` for choices and assumptions, and `research/` for source-backed engineering evidence. Reports must identify the design revision/hash they validate. Absence of an error report is not a pass.

The original board is 86 × 103 mm. Until mating-part and enclosure evidence is confirmed, trial layouts using those coordinates remain preliminary. No enclosure fit, prototype timing, actual module internals, production sourcing, or manufacturing release is implied by CAD checks.

The trial outline is 86 × 145 mm, growing only perpendicular to the ESP32's
long axis. The 213-symbol schematic passes native ERC and 272 exported
connectivity checks. All 15 schematic PDF pages have been visually reviewed.
The 206-footprint, four-layer board is fully routed: native KiCad 10.0.6 reports
zero DRC violations, zero unrouted connections and zero schematic mismatches
after filling its ten ground/thermal zones. Exact report hashes identify the
checked revision. These are CAD results; physical sequencing is not yet tested.

Start with `single_detector_usb_master/single_detector_usb_master.kicad_pro`.
Keep the adjacent `libraries/` directory with the project. `REPRODUCE.md`
describes validation; `BRINGUP.md` records the unperformed hardware checks.
Use the separate `firmware/Eltec_USB_Master/Eltec_USB_Master.ino` for the R1
carrier after confirming the ESP32 configuration. It compiled and passed 24
host-protocol checks; nothing was flashed.

The draft assembly contains 195 fitted components in 68 BOM groups. Seven exact
manufacturer part numbers (nine references) need JLC catalog/sourcing
confirmation, and C12's identified catalog entry was out of stock at the public
check. Prepared sourcing requests are in `research/global_sourcing_prepared.csv`;
none was submitted. All vendor placement rotations still need assembly-preview
confirmation. These files are not an immediately approved populated-board order.

Mechanical fit, actual battery endpoints, module internals, USB switch behavior,
thermal performance and measurement calibration remain unverified. In particular,
the stacked static ADC supply corner leaves only 4.64 mV below its 5.25 V
operating ceiling; actual module AVDD transients must be measured before using
the prototype for accepted detector measurements.

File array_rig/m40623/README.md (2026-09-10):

# Eltec 40623 Array Tester (TP120) — 50 positions on the DAQ array rig

The 40623 build of the array rig. It measures the two TP120 tests that need
no emitter, fifty detectors at a time: the **offset check** and the **noise
test**. Sensitivity / polarity (the 3 Hz chopper test) waits for the emitter
board. Everything it records is **CALIBRATION PENDING / PROVISIONAL** — see
"Limits" below and `docs/CALIBRATION_RECORD.md` §4b.

Normally launched from the array selector (`../eltec_array_tester.py`); runs
standalone with this directory as cwd:

```
array_rig\m40623\run_eltec_40623_array_tester.cmd          (Windows)
./array_rig/m40623/run_eltec_40623_array_tester.sh         (Xubuntu)
python array_rig/m40623/eltec_40623_array_tester.py --simulate   (no hardware; ELTEC_ARRAY_SIMULATE=1 does the same)
```

`ELTEC_ARRAY_RESULTS_ROOT=<dir>` redirects the results folder. For a
hardware-free demonstration, check **Simulation** in the array selector or
use `--simulate` above. The demo uses a fast virtual clock and isolated
example noise limits to show red and green results; production noise limits
remain unset. The badge reads **SIMULATION**; files carry a simulation flag
and **SIMULATION ONLY** noise-limit provenance. Demo files go under
`tempfile.gettempdir()/eltec-array-simulation`, or `<dir>/simulation` when
`ELTEC_ARRAY_RESULTS_ROOT` is set.

## September 10 readout and noise update

Offset checks now use the working waveform viewer's bulk stream, preserving
channel order and discarding startup/MUX transients. Numerical offset and noise
readings remain visible on each socket. Choose loaded sockets provides an
explicit partial-tray map and requires a fresh offset check after changes.

Noise now uses a nominal **3 Hz/Q=3 band-pass** with RMS and rectified metrics.
No paired legacy/background references are available yet; valid noise readings
remain **REVIEW / CALIBRATION PENDING**, including in CSV, never PASS.
See [NOISE_METHOD.md](NOISE_METHOD.md) for the measurement, qualification,
replay instructions and the bench check still required for the readout repair.

## Hardware chain

```
detector (row r, column c)  ->  unity-gain buffer  ->  DAQ single-ended input CH((r-1)*10 + (c-1))
5 rows x 10 columns                                    ACCES USB-AIO16-64MA DAQ-PACK, USB 2.0
positions labelled row-col (TP120: "1-3" = row 1, part 3)   two DB37s: CH0-CH49
```

The two DB37 cables are **not** a contiguous split of the fifty channels, and
this is the easiest thing on the rig to get wrong. The DAQ splits its 64
single-ended inputs across the two connectors in two blocks of sixteen each
(DAQ-PACK M Series guide, tables 5-1 and 5-2), so each cable carries two
disjoint blocks of the tray rather than one half of it:

| DAQ DB37 | DB37 pins 1-8, 10-17 | DB37 pins 20-35 | array positions |
| --- | --- | --- | --- |
| J2 (AIMUX-64 J3) | CH0-CH15 | CH32-CH47 | 1-1 .. 2-6 and 4-3 .. 5-8 |
| J1 (AIMUX-64 J4) | CH16-CH31 | CH48, CH49, rest unused | 2-7 .. 4-2 and 5-9, 5-10 |

Pins 9, 18, 19 and 36 of each DB37 are AGND, so the channel numbers step over
them. The breakout PCB already follows this pinout - the mapping above is the
board as fabricated, traced from the KiCad netlist - which is why the software
needs no remap: it asks the DAQ for the contiguous scan CH0-CH49 and the
driver returns them in channel order whichever cable each one arrived on. The
connector split matters when you meter a pin by hand, not when you read a
capture.

DAQ facts the code is built around (`docs/daq_usb_aio16_64ma/`, bench-verified
2026-09-02): 16-bit SAR behind two multiplexer stages; the input range is
set per **group of four** channels; the scan is one **contiguous** range;
hardware oversampling = extra back-to-back conversions per channel that
arrive **raw** in streamed mode; **no anti-alias filter**; the device loads
its firmware from the host at plug-in and re-enumerates. Volts are always
computed here from raw counts with our own range table, never taken from
the driver's `ADC_GetScanV` (a `-HG` high-gain unit would mis-scale those;
the bench probe's known-voltage check tells the two apart). Two more facts
found on the unit 2026-09-02: the DLL's immediate-read entry points
(`ADC_GetScan` / `ADC_GetScanV`) rewrite the device's configuration block
(trigger byte 0x05 → 0x04: the pacing clock no longer triggers a scan) and
never restore it, so `AiousbDaq._reassert_config()` re-writes and
read-back-verifies the block after every immediate read and before every
stream start; and a stream that delivers nothing for `STREAM_NO_DATA_TIMEOUT_S`
(5 s) during the quiet wait or the capture is abandoned into the retry path
(`StreamTimeoutError`, "no data from the stream …") instead of holding the
tray.

## DAQ configuration (recorded on every row)

| Constant | Value | Why |
| --- | --- | --- |
| `DAQ_RANGE_CODE` | 2 = 0–5 V on all groups | TP120 offsets (0.3–1.2 V) and a railed part (~5 V) both visible; 76.3 µV/LSB |
| `DAQ_SCAN_HZ` | 1000 scans/s per channel | the noise pipeline then runs with the single rig's exact numbers (decimate 20, 621 taps, 310-sample edge context) |
| `DAQ_OVERSAMPLE` / `DAQ_DROP_CONVERSIONS_AFTER_MUX` | 3 / 1 | 4 conversions per channel per scan, the first (right after the mux hop) dropped, the rest averaged; 200 kS/s aggregate, 400 KB/s USB (~40 % of each ceiling) |
| `STREAM_BUFFER_BYTES` × `STREAM_BUFFER_COUNT` | 64 000 × 32 | multiple of 512 B and of the 400-byte scan; ~5 s of slack before the driver reports data loss |
| `STREAM_RETRY_LIMIT` | 2 | a stream that fails the integrity check (rate off > 1 %, driver pool exhausted, callback error) is retried, then the tray is NOT MEASURED |
| `STREAM_NO_DATA_TIMEOUT_S` | 5.0 s | a stream that delivers nothing for this long during the quiet wait or the capture is abandoned (`StreamTimeoutError`, "no data from the stream …") so the retry policy above runs and the tray ends NOT MEASURED instead of hanging; generous next to the ~0.16 s callback buffers |
| trigger byte | 0x05 | onboard 8254 pacing clock triggers one whole scan per tick |
| engineering immediate reads (operator now uses bulk) | `ADC_GetScan` | the DLL rewrites the trigger byte on every immediate read (0x05 → 0x04, scan mode without the timer; oversample forced to at least 1) and never restores it; the backend re-writes its block after each read and before every stream start (bench finding 2026-09-02: three offset reads followed by a stream started without re-writing the block gave 0 scans in 12 s) |

`daq_bench_probe.py` proves these on the real unit (`info`, `selfcal`,
`config`, `scan` = own-scale volts per channel (the -HG question is settled
only by a known, metered voltage on an input: the driver's `ADC_GetScanV`
uses the same counts × span / 65536 formula, so its column is a sanity check
of our arithmetic, never a gain check), `slots` = which conversion slot is
unsettled, `floor` = instrument noise via the onboard full-scale reference
(the ground reference clips at code 0 on a unipolar range), `stream 60` =
rate / pool / leftover, `crosstalk`). Its numbers go into
`docs/CALIBRATION_RECORD.md` §6.

## The flow (what the technician sees)

The Eltec-branded screen has two entry fields, **Tech name** and **Batch
number**, and a 5 × 10 map of round sockets. Each socket keeps its row-column
position label, numeric offset/noise and result status visible by default.
**Show more** adds assigned sensor numbers; **Show less** hides those numbers.
Click a completed socket for measurements and quality/calibration details. Shading gives the sockets depth
while keeping every row and column visible.

1. **Load the tray.** Load as many detectors as needed, up to fifty. Tray
   and sensor numbers are assigned automatically.
2. **Measure offset.** Switch the rig's physical power on immediately
   before pressing the button. The app connects, configures and calibrates
   the DAQ on demand, then reads all fifty offsets. Empty-looking sockets
   are rechecked together after two seconds and marked grey automatically.
   Green means in range;
   red means out of range. Low or dead-looking readings may still be
   settling after power-on: recheck before discarding a detector. Every
   offset read is retained for audit, including reads before replacements.
3. **Replace and repeat.** Replace red detectors and press **Measure
   offset** again until the loaded sockets are green. If replacements run
   out, remove the remaining bad detectors and measure offset again to
   detect the newly empty sockets.
   Marking a socket loaded again requires a new offset read before noise.
   In simulation, click a red or empty socket to simulate loading a
   replacement; right-click to mark a socket empty.
4. **Confirm vacuum.** Turn on the vacuum yourself and wait for the gauge
   to reach the required setting, then confirm the vacuum setting and that
   the detected count and socket map match the physical tray. This records
   operator confirmation; there is no pressure
   telemetry or configured setpoint. The app only observes detector signals
   and does not switch rig power or vacuum.
5. **Measure noise.** This becomes available only after successful offsets
   for every loaded socket and vacuum/map confirmation. The app runs an
   adaptive waveform settling check (3–20 s), then a
   sixty-second capture at 1000 scans/s per channel, with 310 samples of real
   context on either side for the anti-alias filter. Integrity failures are
   retried. **Stop** interrupts the run and allows a retry.
6. **Read the results.** The map shows failures in red and passes in green
   when limits are defined. Production noise limits are pending, so a part
   with valid data and no other failure shows amber **REVIEW**. Measurements
   remain visible; **Show more** displays assigned sensor numbers.
   The settled offset (mean of the last two seconds) is checked again;
   HO / LO / D fail. Results save automatically: CSV rows, raw capture
   (`.npz`), grid snapshot (`.png`) and the tray event log. **Next tray** is
   available after saving completes.

The operator does not need separate connect, lock, save, capture-duration or
skip-wait controls. `TrayController` retains its legacy engineering API;
the desktop workflow above applies the fixed operator procedure.

Automatic empty detection uses two median-of-three offset reads, separated
by two seconds on hardware (the simulator advances virtually). Both must
be at or below one ADC code above zero, about 76 µV on the 0–5 V range.
This is a provisional empty inference, not proof of physical absence: a
dead/shorted detector or an unpowered fixture can produce the same signal.
The existing vacuum confirmation therefore also confirms the detector
count and map. A manual **loaded** choice always wins over the inference;
if a grey socket contains a detector, click it and recheck its offset.
The existing < 0.05 V dead-detector threshold and offset limits are unchanged.

The settling check compares both raw maxima and minima in consecutive
one-second blocks, on loaded channels only. Capture can begin after three
seconds when both extrema changed by at most 0.1 mV across two consecutive
block pairs. Monitoring minima as well as maxima catches changes in
amplitude or baseline that equal block means could miss. Noise transients
can use the full twenty seconds; reaching that deadline records a warning
and starts the full sixty-second capture, without changing the verdict.
Callback chunks are split at the settling boundary so the final quiet
samples, captured waveform and filter edge context remain contiguous.

This is an explicit operator-requested timing change dated 2026-09-08.
TP120's photographed noise procedure specifies five minutes after power-on
and separately 15–20 seconds after selecting a detector on the switch box.
The array app now uses `NOISE_STABILISATION_S = 0` and the bounded check
above rather than another five-minute countdown. The policy is archived as
`adaptive_extrema_v1_2026-09-08`; the inherited 0.1 mV tolerance schedules
capture only and is not a calibrated noise acceptance limit.

## Limits and what "provisional" means

| Test | Applied now | Provenance | Status |
| --- | --- | --- | --- |
| Offset | 0.3–1.2 V; < 0.05 V on a loaded socket = D; ≥ 4.9 V = HO (railed) | TP120 rev W offset check (fixture 9000054: +8 V, 100 kΩ source resistor) | **PROVISIONAL** until the PCB loading is confirmed to match 9000054 |
| Noise | none — `NOISE_PP_LIMIT_LOW_MV = NOISE_PP_LIMIT_HIGH_MV = None` | TP120's 10.0–37.9 mV are DMM readings behind amplifier 9000232 + rectifier-hold 9000272 (under vacuum, 60 s hold); no pin-level equivalent exists | **PENDING** — qualify a named 3 Hz metric with paired legacy/background readings, then supply a versioned calibration JSON (NOISE_METHOD.md) |

The active noise measurement is the causal 3 Hz/Q=3 method in
`legacy_noise.py`; see [NOISE_METHOD.md](NOISE_METHOD.md). Qualification
requires paired legacy readings and a demonstrated background/resolution
floor for a named software metric. A strict JSON calibration can be supplied
through `ELTEC_ARRAY_NOISE_CALIBRATION`; malformed/mismatched records cannot
silently enable acceptance. The old 0.85-22 Hz windowed peak-to-peak pipeline
and its frozen golden tests remain diagnostics and simulator-demo behavior.
Its 15% window allowance is not the hardware 40623 noise acceptance rule.

Because the raw capture is saved, `replay_legacy_noise.py` can produce 3 Hz
JSON/CSV evidence from an existing NPZ without changing the original.

## Colours

| Socket | Meaning |
| --- | --- |
| neutral, **WAITING** / **RECHECK** | loaded, awaiting its first or a fresh measurement |
| red | offset out of range (HO / LO / D), or failed noise when limits are defined |
| green | offset OK during screening; overall PASS after noise when limits are defined |
| amber, **REVIEW** | noise measured, but production noise limits are not set; not a noise pass |
| grey, **EMPTY** | marked empty or inferred near zero; confirm against the physical tray |
| **NOT READ** | incomplete measurement or rig fault; retry after resolving the cause |

## Files written (outside the repository — `docs/DATA_MAP.md`)

```
Documents\Eltec_40623_Test_Results\40623_array_daq\
├── 40623_array_lot_<lot>.csv               one row per loaded position per tray attempt
├── 40623_array_lot_<lot>_attempts.csv      tray events, offset-read audit and capture/save history
├── noise_captures\lot_<lot>\tray_<n>_raw.npz   waveform_v float32 [50, N] + left/right_context_v [50, 310],
│                                               channels, positions, sensor_numbers, occupancy, metadata strings
└── grid_snapshots\lot_<lot>\tray_<n>.png       the coloured grid as a data sheet
```

The GUI calls the lot identifier **Batch number**; filenames and CSV fields
retain `lot` for compatibility. Every screening read remains in the offset
audit even when the detector is replaced before noise. Each
`offset_measured` event stores all fifty position readings, occupancy,
offset class and applied bounds in its JSON `detail`, together with the
read number, out-of-range positions and simulation flag. The empty-detection
policy, threshold, both reads, recheck wait, occupancy source and inferred
empty positions are retained as well. Screening reads
do not reserve sensor numbers; the final loaded sockets receive their
numbers when noise starts.

CSV columns (`CSV_FIELDS`): identity (lot, tray, attempt, position, row,
col, DAQ channel, sensor number/id, tester, model, procedure, occupancy),
offsets (insertion read, settled value, settle delta, class, limits, gate
status), noise (worst/median pk-pk mV, windows total/over/clipped, limits,
allowance, provenance, verdict, band note), timing (stabilisation wait,
quiet wait + settled flag, capture seconds, versioned noise timing policy,
settling criterion/delta/block count, minimum/maximum wait and stop reason), verdict (pass_fail, verdict,
verdict_status, structured fail reasons, warnings, failure-mode tag,
comments), stamps (`calibration_status`, `calibration_id`), DAQ (serial,
range code, oversample, dropped conversions, scan rate, granted timer Hz,
pool events, stream attempts), file paths, app version, simulated flag.
Older files keep their header when columns are added.

The `noise_settled` tray event and raw capture's `quiet_diagnostics_json`
retain the loaded channel list and every one-second window's maxima,
minima, corresponding deltas, elapsed time and settled/deadline outcome.
These records preserve the evidence even when an older batch CSV header
does not include the new timing columns.

## Failure modes (TP120 page 7)

HO high offset, LO low offset, SH shorted FET, D dead / no output (→ replace
FET); N noisy (→ replace crystal); NL noise low (this rig's name for "under
the low limit"); NM not measured (rig fault); Drop (handling). The saved
failure tag is derived from the measurement verdict.

## Engineering

Engineering tools only: none issues a verdict, none writes a file unless
given an explicit output path (never under `Documents`), and only one
program can own the DAQ at a time — close the tester before running the
probe, the readout or the viewer, and vice versa. The DLL does not refuse a
second program (bench check 2026-09-02): its configuration and stream calls
go through and the first program's stream silently stops delivering (its
integrity check then fails, or the tester's no-data timeout trips), and a
self-calibration attempted while another program streams fails with Win32
status 13. All three take
`--simulate` (no hardware) and default to the tester's acquisition constants
(`--range --hz --oversample --drop --start --end --connect-timeout`; the
readout and the viewer also `--no-selfcal`).

- `daq_bench_probe.py` — see above; `--simulate` runs every command on `SimulatedDaq`.
- `daq_rig_readout.py` — the array rig's counterpart of
  `Arduino/Eltec/esp32_rig_readout.py`, built on `daq_backend.py` only.
  Python API: `ArrayRig(simulate=False, range_code=2, scan_hz=1000,
  oversample=3, drop_first=1, start_channel=0, end_channel=49,
  self_calibrate=True, …)` with `connect()` (connect → configure →
  `ADC_SetCal(':AUTO:')` → configure, the tester's order), `close()` / a
  context manager, `read_offset_voltage(position, reads=24)` and
  `read_offsets()` (median of 24 immediate scans — the ESP32 `OFFSET?`
  depth — all fifty from one read set), `capture(seconds, positions=None,
  quiet_wait_s=0)` → `Capture` (own-scale volts `[channels, N]`; `t_s` /
  `t_us` synthesised from the granted pacing-clock frequency — the DAQ has
  no per-sample timestamps; `channel()`, `means()`, `peak_to_peak_mv()`,
  `band_limited_pp_mv()` = the tester's judged-band pipeline, `subset()`,
  `to_csv()` = `t_us,<position>,…` volts to 6 decimals, `to_npz()` = the
  bench probe's key layout + `drop_first`, replayable by
  `engineer_tools/noise_band/replot_noise_capture.py` given the file path),
  `set_range(code)`, `live_stream(buffer_s=60)` → `LiveStream` (a thread
  owning every device call: `start()`, `wait_ready()`, `snapshot()`,
  `latest()`, `stats()` — the delivery rate between the first and the newest
  chunk, lag, chunks, error, diagnostics — and `stop()`). A capture whose
  stream diagnostics report a problem raises. Honest differences from the
  ESP32 tool: no emitter / PWM / gate / sync (no emitter board yet — the
  tester's `DriveDevice` slot is where it will plug in), and all fifty
  channels always stream together, so selecting a position is free. CLI
  (positions as `row-col`, `CHn` or a channel number; the acquisition
  options above plus `--reads`, accepted before or after the command; exit
  0, 2 on a DAQ error):

  ```
  python array_rig/m40623/daq_rig_readout.py info
  python array_rig/m40623/daq_rig_readout.py offset                 # all fifty as a 5 x 10 table (context flags, never a verdict)
  python array_rig/m40623/daq_rig_readout.py offset 2-4 CH13 13     # one line per position
  python array_rig/m40623/daq_rig_readout.py stream -s 8 [-p 2-4 3-6] [-o cap.csv] [--npz cap.npz]
  python array_rig/m40623/daq_rig_readout.py noise -s 20 [--quiet-wait 3] [-p ...] [-o ...] [--npz ...]
  python array_rig/m40623/daq_rig_readout.py watch [-p 2-4 4-7] [-s 30] [--interval 1]   # text-mode live readout, Ctrl+C
  python array_rig/m40623/daq_rig_readout.py test -s 20             # identity -> offsets -> noise capture
  ```

- `daq_live_waveform.py` — counterpart of `Arduino/Eltec/live_waveform.py`:
  a matplotlib rolling scope of ANY position, switched live. Panels: (1) the
  wideband trace of the selected position with a stats box (mean, raw pk-pk,
  judged-band worst/median, rate, lag, chunks, errors); (2) the 5 × 10 grid
  of all positions coloured by the live offset in TP120's PROVISIONAL bands
  (grey < 0.05 V, amber < 0.3 V, blue 0.3–1.2 V, red > 1.2 V, dark red
  ≥ 4.9 V — context, never a verdict) or, with `g`, by judged-band pk-pk
  with NO limit (sequential colour, never pass/fail); (3) the judged-band
  trace of the selected position (the tester's pipeline on the displayed
  window, per-window pk-pk listed), in place of the ESP32 viewer's
  cycle-average panel. Keys: arrow keys move the selection on the grid
  (wrapping), `n` / `p` next / previous channel, a click on a tile, or the
  "Pos" button; SPACE = Hold / Run (the display freezes, the stream keeps
  running); `]` / `+` / `=` wider, `[` / `-` / `_` narrower, the "Window"
  button cycles the ladder 0.25 0.5 1 2 4 6 8 10 15 20 30 45 60 s clamped to
  `--max-window`; `g` toggles the grid metric; `s` saves the whole buffer of
  all channels to `<save-dir>/daq_live_<YYYYmmdd_HHMMSS>.npz` (the readout's
  npz layout); `q` closes. Options: `--position 1-1|CH13|13`,
  `-w/--window 4`, `--max-window 60`, `--grid-metric mean|noise`,
  `--save-dir DIR` (default: the current working directory), `--save-on-exit`,
  `--exit-after SECONDS` (unattended runs; works headless with
  `MPLBACKEND=Agg`), `--fps 20`, plus the acquisition options above. The
  closing line — "Stream closed: N scans received, rate …, lag …, chunks,
  <diagnostics>, integrity OK" — is the stream's health record. Drawing is a
  canvas timer with blitting, and the y-scale holds with hysteresis like a
  scope.

  ```
  python array_rig/m40623/daq_live_waveform.py --position 2-4 -w 8
  python array_rig/m40623/daq_live_waveform.py --simulate --exit-after 4     # unattended / headless smoke run
  ```

  Both tools were verified on the real unit 2026-09-02 (every command,
  integrity OK at 999–1000 scans/s; the inputs read ~0 V because the array
  PCB was not connected).
- `engineer_tools/array_parity/array_noise_parity.py` — pairs legacy-fixture readings with
  array captures and proposes the pin-level limits.
- `engineer_tools/noise_band/replot_noise_capture.py --position 2-4` — replays a saved
  tray capture through the production pipeline or alternative bands.

## Tests

```
python -m unittest discover -s array_rig/m40623/tests
```

`test_daq_backend.py` (fake DLL + fake clock, including the immediate-read
side effect and the block re-assert), `test_array_analysis.py` (golden
parity + verdicts), `test_array_tester.py` (paths, CSV, numbering, lock,
noise phase with retries and the no-data timeout, save, re-measure, GUI
smoke; results root redirected to a temporary directory and a guard asserts
nothing lands in Documents), `test_adaptive_settling.py` (extrema stability,
loaded-channel masking, 3–20 s timing, cancellation, contiguous sixty-second
capture across arbitrary callback sizes, and saved diagnostic evidence),
`test_daq_rig_readout.py` (59: position tokens,
connect / configuration / self-cal, immediate reads, captures and their CSV /
npz files with an npz replay through the replot tool, `LiveStream` fill /
wrap / stop / error paths and the rate rule, the CLI parser and every command
under `--simulate`, constants drift against the tester, a Documents guard),
`test_daq_live_waveform.py` (40, Agg backend — no window ever opens: the
window ladder, selection, judged-band trace and grid-metric helpers, tile
colours, the text formatters, viewer updates with hold, grid metric and
save, the CLI parser, the headless `--exit-after` path, a Documents guard)
and `test_engineer_tools_array.py` (the parity and replot tools on synthetic
tray captures).

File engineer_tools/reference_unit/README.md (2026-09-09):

# Choosing the AIN1 reference unit — bench procedure

`reference_candidate_qualifier.py` measures candidate 406MCA detectors the
way the production 406 MCA app measures a part, records everything, and
ranks the candidates for the job of **permanently mounted reference unit**
on AIN1 (the emitter-health gate, `REFERENCE_GATE_ENABLED`). The buffer board
now has one independent op-amp per channel, and the gate went back **on for
all three models on 2026-09-09** — ahead of the crosstalk re-check, which is
still outstanding (CALIBRATION_RECORD §2.4). So the remaining work below is
live production work, not preparation: until the chosen part is mounted and a
fresh **Calibrate reference unit** has been run, each rig refuses its stored
(pre-isolation) baseline and locks testing.

## Precision retest on AIN0 (recommended for the final selection)

Use this mode for refD, refC and refA. The part stays in the **AIN0 DUT
socket throughout its session**; no AIN1 access is needed. Close the tester
and other serial-port apps, seat the candidate, then run one command at a
time and swap the candidate only after its command finishes:

```powershell
python engineer_tools/reference_unit/reference_candidate_qualifier.py capture --precision --label refD
python engineer_tools/reference_unit/reference_candidate_qualifier.py capture --precision --label refC
python engineer_tools/reference_unit/reference_candidate_qualifier.py capture --precision --label refA
python engineer_tools/reference_unit/reference_candidate_qualifier.py compare --precision refD refC refA --show
```

Each session takes **30 readings**, all driven at **10 Hz / 50% duty**.
Twenty cycles means two seconds of measurement **after** stabilization;
30 readings means 30 separate emitter activations to test repeatability.

1. Prompt once to seat the part. Let the insertion offset settle once.
2. Start the emitter and acquire the existing production DUT measurement:
   ten confirming deltas at the tracked DUT threshold, then 20 fresh cycles,
   including production stability retries and signal-quality checks.
3. On the same saved waveform, select the **earlier reference reading** using
   the app's reference settings (currently five confirming deltas at 0.250 mV,
   then the mean of five fresh cycle peak-to-peak values). This is a replay
   on AIN0, not a change to the production capture policy or AIN1 routing.
4. Keep the emitter driven for a further **20 s** to measure hold drift and
   exercise heating. Switch it off and take the production offset re-read;
   do not add the screening mode's extra wait for a quiet offset.
5. Leave the part seated. Alternate minimum emitter-off intervals of
   **2, 10 and 60 s** before the remaining readings. This probes rapid use,
   ordinary pauses and longer pauses without grouping all cold readings at
   one end of the session. Actual off-times are saved, including processing
   and offset-read time. The first reading is reported separately as `initial`.

Budget approximately **25 minutes per candidate** with typical 3–6 s driven
captures. This is a repeatable thermal exercise on the reference candidate,
not an exact replay of every model's DUT sequence. Keep optics, supply,
airflow and the test options the same for all three candidates. A second
complete session on another day adds useful evidence about longer-term
consistency; do not reseat during either session.

`--runs N`, `--hold-s S` and `--off-intervals-s 2,10,60` customize this mode.
Use identical options for all candidates. Fewer than 30 readings produces a
warning; one reading cannot estimate precision. `--port COM3` selects a
port explicitly. `--auto` skips the initial seating prompt only.

Results go to **`~/Documents/Eltec_ReferenceCandidates/precision/<label>/`**.
`--out` changes the parent of `precision`, for both capture and compare.
Original insertion-screening results are retained and never pooled with
precision records. Each reading saves its raw NPZ, five-cycle selection,
20-cycle results, interval, run number, planned session length and session ID.
Ctrl+C preserves completed readings. An interrupted session is excluded from
ranking; repeat it in a fresh `--out` folder and use that same folder for the
other candidates. Stream faults still use the production bounded retries;
retry counts remain visible because retries can alter the heating history.

The precision table reports:

| Column | Meaning |
| --- | --- |
| `ref CV %` | Sample standard deviation / mean across complete five-cycle readings, in percent; lower is more repeatable |
| `max dev %` | Largest absolute five-cycle deviation from that candidate's own mean; not an accuracy specification or deviation from a calibrated baseline |
| `ready s`, `worst s` | Median and worst PWM-on time through the fifth fresh cycle; transport/UI completion overhead is excluded |
| `20cy CV %` | Between-reading CV of the later production 20-cycle sensitivities |
| `pause span %` | Highest minus lowest repeated off-interval group mean, divided by the overall reference mean; excludes the initial group |
| `early/late %` | Median signed difference between early reference and later production sensitivity; consistent bias can be calibrated, so this is not ranked as an accuracy error |
| `drift %/min` | Median absolute slope over the 20 s drive holds; a short-hold slope, not a prediction of indefinite drift |
| `retries`, `prod pass` | Recorded stream retries and the original production checks passed |

Condition-specific means, CVs and sample counts print below the table. The
CSV also retains SNR, within-window cycle CV, early/late difference spread
and the original diagnostics. The precision plot shows reading deviations,
completion times, early/late differences and hold drift in acquisition order.

Precision ranking uses weighted metric ranks: five-cycle reading CV **5**,
worst deviation **3**, 20-cycle reading CV **2**, hold drift **2**, worst
ready time **1**, median ready time **1**. Insertion settling and offset
recovery do not earn ranking points. Ranks use 0.01 percentage-point bins
and 0.1 s timing bins to avoid credit for tiny timing differences; full
precision is retained in the files. These are engineering preferences, not
production acceptance limits or statistical significance tests.

All original production disqualifiers remain, including a failed 20-cycle
measurement; a missing five-cycle result or incomplete session also prevents
ranking. The comparison refuses different drive/hold/pause settings,
firmware, channels or mixed hardware/simulation data. Explicitly requested
candidate labels must all have matching data.

After choosing, validate the winner on AIN1 and calibrate it there. AIN0
repeatability cannot establish AIN1 mounting performance or channel isolation.
The production gate flags, thresholds and calibration factors are unchanged.

## Original insertion screening

Without `--precision`, the original three-run reseating procedure below is
preserved. It measures these additional screening properties:

| Property | Why it matters for a reference | Metric in the report |
| --- | --- | --- |
| Offset settles fast after insertion | a reference read is taken at the start of every test; a slow settler keeps the whole bench waiting | `settle s` (time until the level stays within ±10 mV of its final value), `band s`, `prod s` (what the production rule would decide) |
| Offset recovers fast after the emitter | the emitter heats the part every test; the next read must not see the previous test's heat | `recov s`, `shift mV` |
| 10 Hz response stabilizes fast, every time | the reference capture waits for stability inside the 20 s deadline | `stab s`, and any run that never stabilized disqualifies |
| Same amplitude every time | the gate is a ±25 % window around the calibrated baseline; run-to-run spread eats that window | `run CV %` (run-to-run), `cyc CV %` (within the 20 official cycles) |
| No drift while driven | the reference is read while warm | `drift %/min` over the drive hold |
| Clean signal, stable polarity, passes the production test | anything the app itself would reject is no reference | `SNR`, `pol`, `pass` |

## Setup

* Bench ESP32 + ADS1256 rig on COM3 (auto-detected), firmware v2.1 or newer
  (the tool sends `FE,V19` through the production backend exactly as the app
  does; a v1.9 legacy board is refused).
* Candidates go one at a time into the **DUT socket (AIN0)** — the default
  `--channel sensor`. That is the strictest, most discriminating test (DUT
  stability rules) and the socket makes swapping five parts quick.
  `--channel ref` measures a part that is already on the AIN1 mount instead
  (`REF?` / `STREAM,START,REF`, same threshold and cycle count).
* Nothing else on the port: close the tester app, the readout and the live
  viewer first.
* Output root: `~/Documents/Eltec_ReferenceCandidates/<label>/` (change with
  `--out`; a production `Eltec_*_Test_Results` folder is refused).

## Run the insertion screening

For every candidate (label it by its marking, e.g. `refA` … `refE`):

```bash
python engineer_tools/reference_unit/reference_candidate_qualifier.py capture --label refA --runs 3
```

Each run prompts *"remove and RE-SEAT the part, then press Enter"* — do it,
so every run starts with a real insertion event. The run then takes, per
phase:

| Phase | What happens | Typical time |
| --- | --- | --- |
| A | `OFFSET?` polled once a second until the level is quiet for 8 s (max `--offset-max-s`, 60 s) | 10–60 s |
| B | production capture: `PIN,33`, `PWM,ON` (10 Hz / 50 %), `read_waveform_until_stable` with the DUT settings, stream retries and front-end re-checks as in the app | up to 22 s |
| C | drive hold, emitter still on (`--hold-s`, 20 s; `0` skips) | 20 s |
| D | `PWM,OFF`, the production `wait_for_settled_offset` live, then polling until quiet again | 5–60 s |

Three runs of five candidates is roughly 30 minutes. Each run writes
`<label>_run<n>_<stamp>.json` (every number plus the offset and per-cycle
series) and `.npz` (the raw waveforms — `waveform_v`, `sync`,
`sample_rate_hz`, the hold, the offset series).

Then:

```bash
python engineer_tools/reference_unit/reference_candidate_qualifier.py compare
```

prints the table, the weights, the disqualifications and a recommendation,
and writes `comparison_<stamp>.csv` + `.png` (offset settle curves, post-
emitter recovery, per-cycle pk-pk vs PWM-on time, sensitivity per run)
under the output root. `compare refA refC --show` limits it to some labels
and opens the plot window.

## How the ranking works

Candidates are **disqualified** (listed, never ranked) when any run failed
the production test, never stabilized, never entered the 0.3–1.2 V offset
band, or the polarity changed between runs. The rest are ranked per metric
(ties share the average rank; a missing value takes the worst rank), each
rank is multiplied by its weight and the smallest total wins:

| Metric | Weight |
| --- | ---: |
| offset settle s (median over runs) | 3 |
| worst offset settle s | 1 |
| post-emitter recovery s | 2 |
| stabilization s | 2 |
| run-to-run sensitivity CV % | 3 |
| hold drift %/min (absolute) | 2 |
| cycle CV % | 1 |
| 1 / SNR | 1 |

The weights are `SCORE_WEIGHTS` at the top of the script and are printed
with every table. They are an opinion about what a reference is for, not
a calibration constant: read the per-metric columns before deciding, and
treat a recommendation that is "not the best on" a column you care about as
a question, not an answer.

## After choosing

1. Mount the chosen part on AIN1.
2. Re-check crosstalk with the new buffer (TI OPA2196), reproducing the
   original trigger: with a **shorted DUT** seated and the emitter driven,
   `REF?` and an AIN1 stream must not move (the 2026-08-17 finding was
   ~4.94 mV → ~0.30 mV, about −90 %). Through the app only the 406 MCA path
   reads AIN1 with the DUT seated — calibrate first, then load the shorted
   part and Start: clean = "Reference unit passed" then the "Is a sensor
   loaded?" prompt; crosstalk = "outside its window" and a lockout (now also
   a `measure_error` row in `_attempts.csv`). The 405/449 reject a ≈0 V part
   before AIN1 is read, so for them use `Arduino/Eltec/esp32_rig_readout.py ref`
   / `--channel ref` captures with the shorted DUT in place.
3. `REFERENCE_GATE_ENABLED = True` is already set on all three models
   (2026-09-09). Run **Calibrate reference unit** fresh on each rig — the
   schema bump (405/449 v5, 406 v3) refuses every older baseline, so this is
   required before any part can be tested — and record the chosen part, the
   step-2 crosstalk numbers and the new baseline in CALIBRATION_RECORD
   §2.4 / §5 with a CHANGELOG entry.
4. **If step 2 fails** — AIN1 still moves with the DUT — set
   `REFERENCE_GATE_ENABLED = False` again in each model rather than widening
   `REFERENCE_TOLERANCE_PERCENT`: a reference that tracks the loaded part is
   measuring the wrong thing, and no tolerance makes it trustworthy. The
   gate-off path is still unit-tested in all three models.

## Without hardware

```bash
python engineer_tools/reference_unit/reference_candidate_qualifier.py capture --simulate --label demo --sim-profile fast --runs 2 --out <scratch dir>
```

runs a simulated candidate (`fast`, `slow`, `jittery`, `high_offset`,
`never_stable`) on a virtual clock in a second; the suite's round-trip test
does the same.

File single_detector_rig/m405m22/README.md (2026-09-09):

# Eltec 405 M22 ESP32 Tester (1 Hz TP412 evaluation build)

This directory is the **405 M22 model of the unified rig app**
(`single_detector_rig`, normally launched from its selector): the ESP32/ADS1256
tester (derived from the 406MCA v6.1 application) for the **Model 405 M22**
high-gain thermally compensated pyroelectric IR detector, following document
**TP412** (offset, sensitivity/polarity at 1 Hz, and noise). The sensitivity
gate is **live** with the lot-500 pairwise calibration (factor 4.30, see
below); the authoritative list of every limit and its provenance is
[`docs/CALIBRATION_RECORD.md`](../../../docs/CALIBRATION_RECORD.md).

The 406MCA v6/v6.1 standalone applications this build was derived from were
retired on 2026-08-28 (git tag `archive/pre-cleanup-2026-08-28`); the live
406 MCA model is [`../m406mca/`](../m406mca/README.md).

## What is different from the 406MCA builds

| Aspect | 406MCA v6/v6.1 | 405 M22 build |
| --- | --- | --- |
| Emitter chop | fixed 10 Hz / 50% | **1 Hz / 50%** (the 405's responsivity spec frequency) |
| Firmware | v1.7+ (keep on **v1.9**) | **v2.0+** (ADS1256 gain 1, input buffer off, `PWM,FREQ`) |
| Sync validation | 10.0 ± 0.1 Hz | 1.0 ± 0.1 Hz |
| Stability deadline | 20 s | **60 s** (each cycle now takes a full second) |
| DUT qualification | 5 (v6) / 10 (v6.1) deltas ≤ 0.100 mV | 5 consecutive deltas ≤ **0.500 mV** (relaxed for these high-gain parts; the AIN1 reference keeps its own 0.250 mV limit) |
| Measurement window | 10 (v6) / 20 (v6.1) cycles | 10 cycles, 3 attempts (v6.1-style kick/retry) |
| Healthy DC offset | 0.3–1.2 V | **0.8–3.0 V** (full TP412 band; needs firmware v2.0) |
| Filter setups | 406MCA filters | **TP412: -625 / -628 / -629** (see ranges below) |
| Sensitivity gate | calibrated, ±0.10 mV raw near-limit band | calibrated (lot 500, live since 2026-08-17), same ±0.10 mV raw near-limit band |
| Sensitivity factor | 1.582 legacy-equivalent | **4.30** legacy-equivalent (`405m22_tp412_lot500_pairwise_v1`) |
| Noise test | none | **TP412 emitter-off noise test** after the offset gate, BEFORE the sensitivity capture |
| Test order / UI | offset → sensitivity | offset (fail-fast) → noise → sensitivity, with a **step progress bar** |
| Battery gate | 6 V SLA on AIN7 | **disabled — not monitored** (batteries isolated, see below) |
| Reference baseline | own calibration per build | own calibration on firmware v2.0, **reference driven at 10 Hz** (the AIN1 unit is a 406MCA sensor; schema v4) |
| Results root | `~/Documents/Eltec_406MCA_Test_Results/...` | `~/Documents/Eltec_405M22_Test_Results/405m22_esp32/` |

Everything else — the guided flow, mandatory AIN1 reference-unit gate,
serial-integrity checks, robust-peak stability rule, failure modes,
CSV/audit trail, snapshots, and simulator — is carried over intact.

## TP412 sensitivity ranges (operator selects the filter per batch)

| Filter setup | min–max (legacy scope mV) |
| --- | --- |
| -625 filter | 5.99 – 11.98 |
| -628 filter | 4.22 – 8.44 |
| -629 filter | 4.92 – 9.84 |

All three assume the blackened tube + extra -25B filter optics at 10 cm from
the 500 K blackbody. **These ranges gate live since 2026-08-17**, through
the lot-500 pairwise fixture calibration
(`SENSITIVITY_CALIBRATION_ID = 405m22_tp412_lot500_pairwise_v1`):

* 46 sensors were measured on the legacy fixture and on this rig; the
  per-part legacy/raw ratio has median **4.2973** and
  regression-through-origin slope 4.2853 (agreement within 0.3%, spread
  4.4% sd), so `SENSITIVITY_LEGACY_EQUIVALENT_FACTOR = 4.30`.
* Raw near-limit band for -625: FAIL below **1.29 mV**, clean PASS above
  **1.49 mV**, and **PASS · NEAR LIMIT** (passes and keeps its number; no
  quarantine since 2026-08-25) between (5.99 / 4.30 = 1.393 center ± 0.10
  raw).
* Validation on the same lot: the old fixture's one low-sensitivity failure
  (500-10) computes to 4.03 mV legacy-equivalent vs its old reading of
  4.08 and fails; the closest passer (500-15) computes to 6.52 — the exact
  value the old fixture recorded for it; no part lands in the guard band;
  the hottest part (500-41) computes to 10.88 vs 11.30 old, inside the
  11.98 maximum. Legacy-equivalents above the TP412 max fail high.

## Test order and step progress bar (offset first since 2026-08-13)

Each sensor now runs its per-part checks in TP412 order, with a step
progress bar on the measuring screen ("STEP 1/4 — OFFSET", bar filling as
the sequence proceeds, tick marks at the step boundaries):

1. **Offset (quick check)** — a plain DC read with the emitter off, before
   anything else. Since 2026-08-17 the early fail-fast is **high-side
   only**: an offset above 3.0 V fails immediately (a high-offset part
   typically **rails AIN0 at the ~5 V ADC full scale**, and highs never
   settle back into band), but a LOW first read is *not* a verdict —
   lot 500 showed these parts' offsets **rise for tens of seconds after
   insertion** (35 of 48 parts read 0.15–1.1 V below their settled
   legacy-fixture value on the first read; the two parts that got an
   immediate re-measure matched it almost exactly). A low part therefore
   continues, and the offset verdict comes from a **settled re-read taken
   after the sensitivity capture** (~40 s in the fixture); the CSV records
   both (`offset_initial_v` = insertion read, `offset_v` = settled verdict
   value). A near-0 V float still reads as "no sensor", but only after a
   5 s wake-up poll window (a just-inserted part can sit below the floor
   for a few seconds — lot 500's 500-44 was wrongly rejected as an empty
   slot before this). Because a bad high part never reaches the reference
   gate, its AIN1 interference can no longer invalidate the reference
   calibration;
2. **Reference check** (fixture gate, emitter at the reference unit's
   10 Hz). If the reference fails anyway, AIN0 is re-read: a part that has
   drifted/railed above 3.0 V mid-test explains the failure, so the part
   records the HO failure and the calibration is spared — only an in-band
   AIN0 lets a reference failure invalidate the calibration;
3. **Noise (emitter off)** — see below; a noise FAIL also stops the test
   (preselecting **N - Noisy**) without spending up to three 60 s
   stabilization attempts on a part that is already bad;
4. **Sensitivity** — 1 Hz drive, adaptive peak stability, 10 measurement
   cycles.

## TP412 noise test (emitter off)

The noise step runs on the same stream plumbing with the emitter off (it is
turned off after the reference phase). The old settle detection is gone — with
the emitter off there is no signal to stabilize, only the noise being
measured — so the app now:

1. streams an **adaptive quiet wait** (discarded; the live scope keeps
   updating): the capture starts once 2 consecutive per-second mean deltas
   are ≤ `NOISE_BASELINE_SETTLE_DELTA_MV` (~107 µV/s), earliest at 3 s; if
   the DC level is still settling at `NOISE_WAIT_MAX_S` (20 s) the capture
   starts anyway and the report notes it — a slow baseline can **never**
   fail the part from here;
2. keeps the next **20 s** as the noise capture (fixed for now; making the
   length adapt to how noisy the part is remains future work);
3. **band-limits** the capture 20:1 (1000 → 50 SPS, ~22 Hz passband; since
   2026-08-20 an anti-alias FIR — Kaiser windowed-sinc, ≥ 60 dB stopband —
   replaced the original boxcar average, whose −13 dB sidelobes let 60 Hz
   mains fold to 10 Hz at only −16 dB and read as part noise) and gives
   each 1 s window its **own least-squares baseline** (mean and slope — "a
   fresh offset every second"), so residual settling cannot inflate the
   windowed pk-pk;
4. cuts the detrended trace into twenty 1 s windows and computes pk-pk
   per window: **PASS iff at most 15% of the windows (3 of 20) exceed
   the pin-level limit.** Windows whose RAW samples touch the ADC clip
   level count as over-limit (averaging must not hide a railed input).
   The 15% allowance is the 2026-08-17 lot-500 calibration: the one part
   the legacy fixture failed for noise (500-44, 496 mV on the old scope)
   measured 4/20 windows over here and was slipping through the previous
   20% allowance, while every other part measured 0/20 except one isolated
   2-window environmental spike (500-3, mid-pack on the old fixture) that
   must stay tolerated. 4 windows over now fails, 2 still passes.

**Extended noise soak (2026-08-18, per-part opt-in).** The 08-18 re-run of
lot 500 proved 500-44's burst noise is INTERMITTENT: it measured 4/20
windows over on 08-17 but 0/20 (worst 38% *below* the limit) on 08-18,
while the same re-run threw environmental transients at clean parts
(500-1 reached 3/20 over at 1.03 mV). No threshold separates those two —
tightening would false-fail clean parts *and* still miss 44's quiet
stretches. The discriminator is observation time: a load-step toggle runs
that part's noise capture at **60 s with the allowed over-window count held
at the same absolute 3** (3 of 60, deliberately NOT 15% of 60 = 9). One
environmental bang still spans only 1–3 windows regardless of length, while
genuine recurring bursts accumulate windows across the longer watch
(~50% catch per 20 s on 44's history → ~90% per soak). The toggle resets
after every sensor; use it on suspect or historically noisy parts. The CSV
records the actual capture length in `noise_capture_s` and the window count
in `noise_windows_total`.

Because noise now precedes the driven capture, an Unstable part still
records its real measured noise report (not a SKIPPED placeholder), and the
CSV's historical `noise_settle_s` column records the (now adaptive) quiet
wait; `noise_analysis_rate_hz` documents the band-limited rate the verdict
used and `noise_baseline_settled` records whether the level settled before
the capture started.

**Keeping the raw capture for analysis (2026-08-17).** The RAW 1000 SPS
noise record of the current part stays in memory until the next sensor is
loaded, and the result screen's **"Save noise capture"** button writes it to
`noise_captures/lot_<batch>/<sensor>_noise_raw.csv` (one `#` metadata line,
then `sample,t_s,volts`) plus a matching `.npz` — opt-in per part, for
offline spike-morphology work (rise times, widths, spike-to-spike
comparison) that the 50 SPS band-limited verdict trace cannot support.
Since 2026-08-18 the raw capture is also saved **automatically the moment
ANY window goes over the limit — PASS or FAIL** (each over-window event is
either a burst episode or an environmental transient, and both are too rare
to lose; the 08-18 re-run would have banked six such captures). The file
paths land in the batch CSV's `waveform_snapshot_paths` column either way,
and the metadata line records whether the save was operator-requested or
automatic. Note when
analyzing: at 1000 SPS the ADS1256's digital filter settles in ~1 ms, so
measured spike rise times shorter than ~1–2 ms are the ADC's step response,
not the spike's.

**On screen the noise result is a verdict, not a number:** the details tile
shows `PASS` / `FAIL` / `Skipped`, and a failure reason gives window counts
without voltages. This rig measures at the sensor pin in µV while the
legacy station reads mV behind its amplifier chain, so an on-screen
magnitude invites a false comparison. All levels remain in the `noise_*`
CSV columns and in the auto-saved failure snapshot; the waveform view still
plots the trace against its red ±limit/2 cutoff lines with a numeric
readout.

### The pin-level limit and the ADS1256's resolution (recalibrated 2026-08-13)

TP412's **300 mV pk-pk** scope limit is read **behind the legacy bench
amplifier chain** (TL084-based; nominal ×4000). A same-part
cross-measurement showed the nominal gain is NOT the effective one: the
part read ~240–270 µV at the pin over the scope-equivalent 50 s / 20 Sa/s
view while the legacy scope displayed only ~150–200 mV (a true ×4000
would show ~1 V). The **measured effective factor is ~620–830×**, adopted
as `NOISE_EFFECTIVE_CHAIN_FACTOR = 700`, so the pin-level limit is
300 mV / 700 ≈ **0.429 mV = 429 µV pk-pk** (single-part derivation;
refine with more parts and by checking the legacy scope's CH2 probe
setting and the amp's range switches). Whether the ADS1256 can see
signals at this scale:

- **Quantization is fine.** At PGA 1 (±5 V full scale) one LSB is
  10 V / 2²⁴ ≈ **0.6 µV**. (Higher PGA gain is not available for headroom:
  the DUT rides on a 0.8–3.0 V DC offset, which clips any gain above ~1.6
  single-ended.)
- **The ADC's own noise sets the floor.** At 1000 SPS / gain 1 the
  ADS1256's input-referred noise is ~4–8 µV RMS, i.e. ~30–50 µV pk-pk per
  1 s window raw, and the raw ~500 Hz bandwidth also admits mains/EMI the
  band-limited legacy chain never saw.
- **Band-limiting fixes it.** The 20:1 decimation (`NOISE_DECIMATION_FACTOR`;
  an anti-alias FIR since 2026-08-20 — flat to the boxcar's old 22 Hz corner
  (its own −3 dB point is 24.4 Hz) with ≥ 60 dB of stopband so out-of-band
  mains/EMI can no longer fold into the judged band; seated on 0.31 s of
  real edge context per side since 2026-08-31) cuts the floor to a
  bench-measured **4.2 µV
  median window pk-pk (~1% of the 429 µV limit)**, and the resulting 50 SPS
  view closely matches the legacy scope's own roll-mode 20 Sa/s
  acquisition. A pk-pk noise spec is only meaningful in the bandwidth it
  was written for.

Bench-verified 2026-08-13 (captures + scripts in the results folder under
`noise_experiments/`): fixture floor 4.2 µV @ 20:1 (electronics clean); a
desk fan near the rig adds ~19 Hz / ~200 Hz microphonic peaks plus mV
transients through the part (pyros are piezoelectric — no fans during
noise tests); the resident good part reads ~120–140 µV median per window,
~60% of the legacy band on both fixtures with the ×700 factor.

## Scope views (live + result)

Both waveform panels overlay the PWM sync square wave ON the signal trace
(orange, scaled to the same band, "HIGH = EMITTER ON") so polarity can be
read directly: a POSITIVE part peaks while the overlay is high. X (seconds)
and Y (volts) axes carry numeric tick labels on a 1/2/5-step grid, and
traces draw as per-pixel min/max envelopes so narrow spikes survive
downsampling.

**Noise displays are relative (2026-08-12 rework):** during the noise step
the live scope — and the result screen's dedicated noise scope — plot the
**band-limited** trace as its **range around the mean, in µV** (not
absolute volts), with **solid red cutoff lines at ± half the pk-pk limit**
(±214 µV for the 429 µV limit) and the numeric pk-pk range in the corner, so
"is it crossing the red lines" is the whole reading. The y-axis stays
symmetric around 0 and never spans less than 2x the pk-pk limit so ordinary
noise cannot be auto-zoomed into looking large, and the time axis follows
the decimated 50 SPS rate.

TP412 itself allows **no** excursion over the limit (largest excursion
rule); the 15% window allowance is a deliberate engineering relaxation because
these sensors are extremely sensitive and a few excursions are expected.
All noise metrics go to the batch CSV (`noise_*` columns, mV units), and a
failing noise capture is preserved as a PNG snapshot automatically.

## Power / battery monitoring (changed 2026-08-12)

The emitter-induced spike was fixed by isolating the supplies:

- **6.5 V battery → emitters ONLY** (via the MOSFET module);
- **9 V battery → sensors** (DUT and AIN1 reference buffer supplies).

Neither battery is measurable on the legacy AIN7 divider, so the battery
gate is **disabled** (`BATTERY_MONITORING_ENABLED = False`); the header pill
shows "Battery: not monitored" and no `BAT?` reads are issued.
**TODO (hardware):** measure the sensor battery on **AIN6** through a ≥4:1
divider (e.g. 300k/100k) and re-enable the gate with thresholds for the
actual supply — the plan is to step the sensor supply down to ~8 V (or use
an 8 V battery) so the noise readings stay comparable to TP412's +8 V bench
supply. All the battery machinery is kept in the code for that re-enable.

## Firmware requirement

Flash `Arduino/Eltec/Eltec.ino` **v2.0** or newer. v2.0 changes the ADS1256
front end for the TP412 offset band:

```text
sensor channels AIN0/AIN1: PGA gain 2 -> 1  (full scale +/-5 V, LSB 596 nV)
input buffer: ON -> OFF                     (removes the AVDD-2 V = 3.0 V ceiling)
IDN? -> ELTEC-ESP32-ADS1256,v2.0
```

so DC offsets up to and past 3.0 V read linearly (v1.9 clipped at 2.5 V).
This build refuses to connect to pre-v2.0 firmware, and flashing v2.0
invalidates any reference baseline recorded before it (calibration schema
v3) — run **Calibrate reference unit** once after the flash.

**Do not flash v2.0 on rigs running the 406MCA v6/v6.1 apps** without
re-verifying their thresholds: they were qualified on v1.9's gain-2 buffered
front end (halved LSB, different noise floor, and `BAT?` loses accuracy with
the buffer off).

## Quick signal checks with the Arduino/Eltec tools

The standalone rig tools accept a `--freq` option:

```bash
# Live rolling waveform with the 1 Hz drive on (window auto-widens to ~6 s)
python3 Arduino/Eltec/live_waveform.py --pwm --freq 1

# Guided battery -> offset -> reference -> capture sequence at 1 Hz
python3 Arduino/Eltec/esp32_rig_readout.py test --freq 1 -s 20

# Hold the emitter PWM on at 1 Hz while watching the module LED
python3 Arduino/Eltec/esp32_rig_readout.py pwm on --freq 1
```

Note: the `bat` command and the battery step of `test` read the AIN7 divider,
which no longer sees a battery on this fixture — ignore those readings.

## How to run

The application runs on **both Xubuntu and Windows** from the same checkout —
same code, same CSV format, same results folder layout. Only the launcher
differs. Batch CSVs written on one host are readable on the other.

Normally: start the unified selector (`single_detector_rig/run_eltec_rig_tester.cmd`
/ `.sh`) and pick **Model 405 M22**. The model app can also be started
standalone:

### Xubuntu

From the repository root:

```bash
./single_detector_rig/m405m22/run_eltec_405m22_esp32_tester.sh
```

The optional Xubuntu launcher installer creates only 405 M22 identities:

```bash
./single_detector_rig/m405m22/install_xubuntu_launcher.sh
```

- display name: `Eltec 405 M22 ESP32 Tester`;
- menu ID: `com.eltec.405m22-esp32-tester.desktop`;
- launcher log: `~/.local/state/eltec-405m22-esp32/launcher.log`;
- results: `~/Documents/Eltec_405M22_Test_Results/405m22_esp32/`;
- serial port: `/dev/ttyUSB*` (opened exclusively).

### Windows

Double-click `run_eltec_405m22_esp32_tester.cmd`, or from a terminal:

```bat
single_detector_rig\m405m22\run_eltec_405m22_esp32_tester.cmd
```

It runs the GUI under `pythonw.exe` (no console window), logs to the file
below, and shows an error dialog if the app cannot start — the equivalent of
the Xubuntu launcher's `notify-send`/`zenity` path.

The optional shortcut installer adds a Desktop and a Start Menu entry
(per-user, no admin rights, `-Uninstall` removes both):

```bat
powershell -ExecutionPolicy Bypass -File single_detector_rig\m405m22\install_windows_launcher.ps1
```

- display name: `Eltec 405 M22 ESP32 Tester`;
- Start Menu: `Programs\Eltec\Eltec 405 M22 ESP32 Tester`;
- launcher log: `%LOCALAPPDATA%\eltec-405m22-esp32\launcher.log`;
- results: `%USERPROFILE%\Documents\Eltec_405M22_Test_Results\405m22_esp32\`;
- serial port: `COM*` (Windows already opens COM ports exclusively, so the
  POSIX-only `exclusive=True` flag is skipped there).

Port discovery is by USB VID/PID on both hosts, so the CP210x bridge on the
rig is found automatically either way.

### Serial-stream reliability (Windows fix, 2026-08-12)

The Windows CP210x driver's default receive queue holds only ~100 ms of the
1,000-line/s stream, and once it overflows it drops — and around the ring
wrap even re-delivers — receive data, which the integrity validator reports
as timestamp gaps plus duplicate timestamps with a host/firmware count
mismatch. The app therefore (a) requests a 1 MiB OS receive buffer at
connect, (b) runs a dedicated drain thread while streaming so the OS queue
is emptied even when the GUI thread stalls, and (c) throttles the capture
loops' re-analysis/preview work to once per half PWM period (driven capture)
or once per noise window, because every full-array pass holds the GIL and
starves that drain thread.

Rare residual micro-gaps (a few samples at the USB scheduling level) still
occur even with all of that, and they were failing real 17–23 s captures
("1 timestamp gaps (~6 missing samples); host/firmware sample counts differ
(16533/16539)"). Since 2026-08-12 (evening) the validator therefore
**tolerates bounded micro-gap loss**: at most `STREAM_MAX_MICRO_GAPS` (3)
gaps and `STREAM_MAX_MISSING_SAMPLES` (20 ≈ 20 ms) lost samples per capture,
with the firmware/host counters agreeing within the same budget; a tolerated
gap is noted on the rig object (`last_stream_tolerance_note`), and losing a
few milliseconds cannot change a 1 s-window noise verdict or a robust
per-cycle peak. Duplicate/reordered/torn records, ADC overruns, a >2% rate
error, or anything beyond the budget still reject the capture with nothing
recorded, and every production capture that fails the integrity check — a
reference-calibration reading, the per-test reference gate, the driven DUT
capture, and the noise capture — is retried up to
`REFERENCE_READING_STREAM_RETRIES` (2) times. Nothing from a rejected
capture is ever recorded, so a retry is always a fresh capture; any other
error still aborts immediately.

Tolerated gaps are also **refilled** (2026-08-13): every capture path runs
the incoming samples through a `StreamGapFiller` that uses the firmware's
per-sample `timestamp_us` to rebuild missing slots (linear-interpolated
volts; a sync transition swallowed by a gap lands at the gap midpoint).
Without this, index-based math saw a shortened timeline — a 2-sample gap in
one 100-sample 10 Hz reference cycle read as 1000/98 = 10.204 Hz and failed
the ±0.1 Hz PWM sync validation as a fake "check firmware and GPIO33" rig
error (seen especially with a laptop charger's EMI raising the USB drop
rate). If sync validation still fails while any gap was seen (edge
swallowed, or a gap beyond the fill budget), it is reclassified as a
retryable `StreamIntegrityError`; with a clean stream it remains a hard
rig fault.

### Serial-stream reliability, part 2: battery power throttling (2026-08-17)

Every capture began failing ("13 timestamp gaps … 103 duplicate timestamps;
host/firmware sample counts differ") while the same board, cable, and
backend were **provably clean when driven headlessly** — CLI captures, a
capture with the 1 Hz emitter chopping (EMI ruled out), and this backend
run without the GUI all delivered 23,000+ samples with zero defects. Two
measured facts explain it:

1. **The 1 MiB buffer request never worked.** `GetCommProperties` shows the
   Windows CP210x driver grants a **512-byte** receive queue regardless of
   the `SetupComm`/`set_buffer_size` request — only **~16 ms** of stream.
2. **Windows 11 on battery throttles the backgrounded GUI.** An occluded
   window gets its sleep timers coarsened to ~15.6 ms and the process is
   demoted to EcoQoS (efficiency cores, minimum clock); the event log shows
   USB power management actively targeting the CP210x (hundreds of
   USBHUB3 196 events/day) starting exactly 2026-08-14. A drain thread
   paced by a 2 ms sleep then wakes too late, the 512-byte queue wraps, and
   the driver drops + re-delivers data — the exact gap/duplicate signature.

Fixes shipped in `esp32_backend.py`:

- The drain thread now **blocks inside the driver read** (wakes on byte
  arrival, no sleep pacing) and runs at raised thread priority.
- The process opts out of Windows power throttling AND timer coarsening
  (`SetProcessInformation(ProcessPowerThrottling)`), both at module import
  in the tester and again at rig connect.
- The drain loop reads the driver's own `CE_RXOVER`/`CE_OVERRUN` flags
  (`ClearCommError`); if the driver reported overflow, the failure dialog
  now says the computer stalled — keep the window visible / plug into AC —
  instead of blaming the USB cable.
- `rig.granted_rx_queue_bytes` records what the driver actually granted.

USB selective suspend was also set to Disabled (AC and DC) in the Balanced
power plan on the Windows laptop, 2026-08-17. Operator guidance: keep the
tester window visible during captures when on battery.

### Serial-stream reliability, part 3: stalls are attributed and restarted (2026-09-03)

The Xubuntu bench reported "ESP32 noise stream stalled after 37624 samples"
on part after part (2026-09-02), each cured by Re-measure. A stall is the
host seeing no sample line for `STREAM_TIMEOUT_S` (2 s); until now the
capture raised from inside its loop and the `finally` sent `STREAM,STOP` -
reading, and discarding, the one reply that tells a rebooted board from a
laptop that froze while the board kept streaming. Now:

- `EmitterEsp32Rig._stall_error` stops the stream *first* and reads the
  reply. Firmware count vs the host's live count, the backlog drained after
  the stop, and any `READY` banner among the non-protocol lines pick a tag
  that ends the message:

  | tag | meaning | advice in the message |
  | --- | --- | --- |
  | `[host-stall]` | the board kept sampling; the samples were still queued in the OS buffer (or lost when it overflowed) - the laptop stopped reading | window visible, AC power, close other programs |
  | `[board-reset]` | the firmware counter restarted (usually with its READY banner mid-stream) - the ESP32 rebooted | USB power and cable (a brownout resets it) |
  | `[board-silent]` | the board answered with the same count the host has - the ADS1256 data-ready stopped | power-cycle the rig |
  | `[no-reply]` | no `STREAM,END` at all | cable, power |

  The message also states how long the silence was ("no sample for 2.3 s").
  The reset *reason* is not readable: the ESP32 ROM prints its banner at
  115200 baud, which arrives garbled at our 500000; only the firmware's own
  READY line is legible (a future firmware could put the reset reason in
  that line - handover §10).
- `StreamStalledError` is a `StreamIntegrityError`, so every production
  capture restarts a stalled stream through `call_with_stream_retries`
  (fresh `STREAM,START`, PWM re-armed) up to `REFERENCE_READING_STREAM_RETRIES`
  times with nothing recorded, the way the technician did by hand. A dead
  port (`Esp32ConnectionError`) is still never retried.
- Every restart writes a `stream_retry` row to the batch's `_attempts.csv`
  (reason = phase + the attributed error), so the tag survives even when
  the retry succeeds. That file is the evidence for the "every morning"
  question: `[host-stall]` rows make the laptop the suspect (what else runs
  at that hour? was the tester left open overnight? on battery?),
  `[board-reset]` points at the rig's USB power, `[board-silent]` at the
  ADS1256. A clean bench check before opening the tester is
  `python Arduino/Eltec/esp32_rig_readout.py stream` for a minute.
- What the ESP32 cannot be: nothing on the board accumulates (one latched
  sample, static buffers, no heap use while streaming, `micros()` wrap
  handled), and opening the port resets it, so a night of uptime is wiped
  when the app starts. Only a tester left open all night keeps the board
  un-reset - and even then the wrap is harmless.
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

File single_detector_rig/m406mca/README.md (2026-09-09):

# Eltec 406MCA ESP32 Tester v6.1

V6.1 is an isolated evaluation build of the ESP32/ADS1256 tester. It keeps the
v6 hardware workflow, reference-unit gate, simulator, failure mode selection,
and serial-integrity checks. It also has a stricter DUT stability/measurement
retry policy.

The new-fixture sensitivity gate uses the paired-fixture calibration described
below. Raw sensitivity is always preserved, while the UI and CSV also report a
legacy-equivalent value. Polarity, stability, signal-quality, battery,
reference-unit, and hardware-integrity gates are unchanged; the offset band is
unchanged but is now read at a different point in the test (see *Offset: the
verdict is a settled re-read* below).

This directory is the live **406 MCA model of the unified rig app**
(`single_detector_rig`, normally launched from its selector). The standalone
v6 and v6.1 builds it descends from were retired on 2026-08-28 and are
preserved at git tag `archive/pre-cleanup-2026-08-28`.
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

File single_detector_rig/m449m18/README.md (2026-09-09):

# Eltec 449 M18 ESP32 Tester (TP443 frequency tracking, 5 Hz + 18 Hz)

The **Model 449 M18** entry of the unified rig app
([`single_detector_rig`](../README.md)). It implements document **TP443
page 6, "449M18 Frequency Tracking"**: the part's sensitivity is read at
**5 Hz** and then at **18 Hz**, and the **18 Hz / 5 Hz ratio** is checked.
The build is derived from the 405 M22 tester (same guided flow, adaptive
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

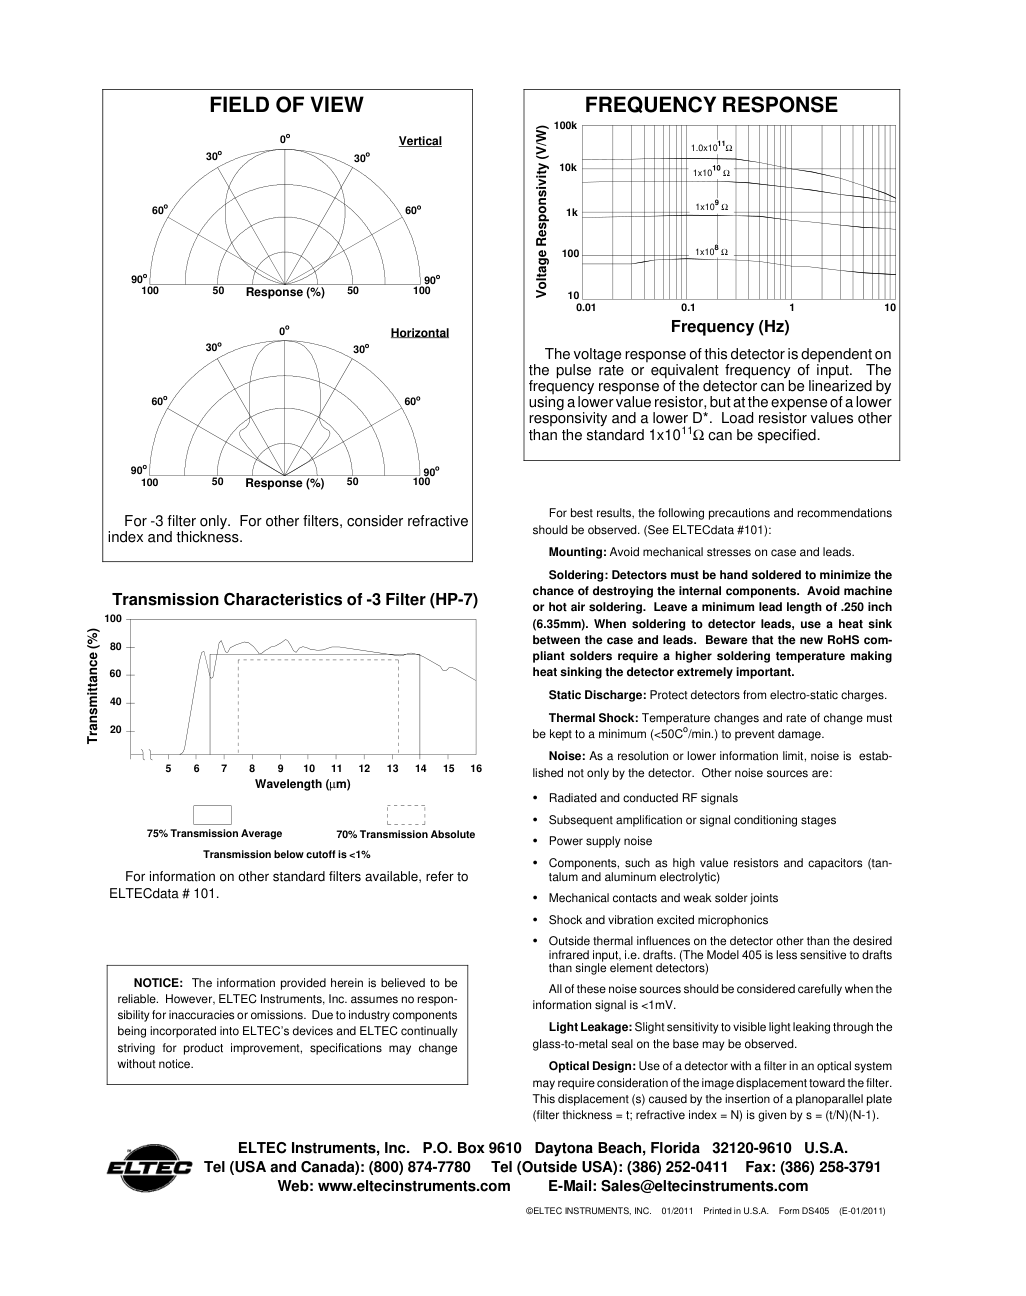
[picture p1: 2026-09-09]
hardware/single_detector_usb_master_r1/reports/detector_pdf_review/Data-Sheet-Model-405_2.png

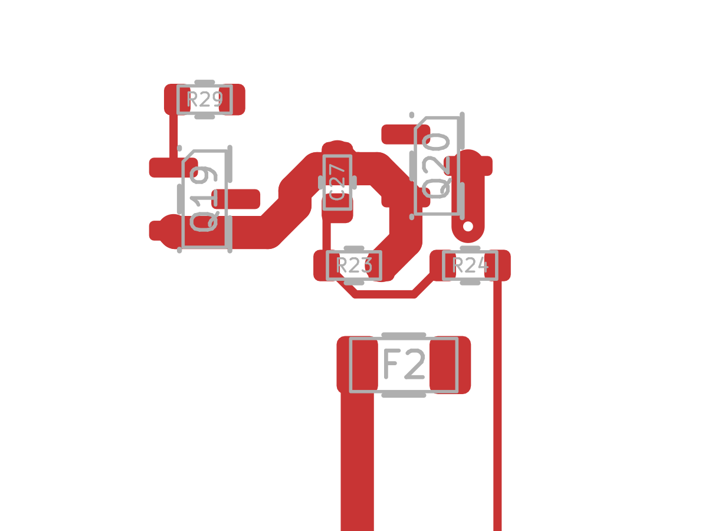
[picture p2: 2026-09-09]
hardware/single_detector_usb_master_r1/reports/routing/trial01/emitter_master_closeup.png

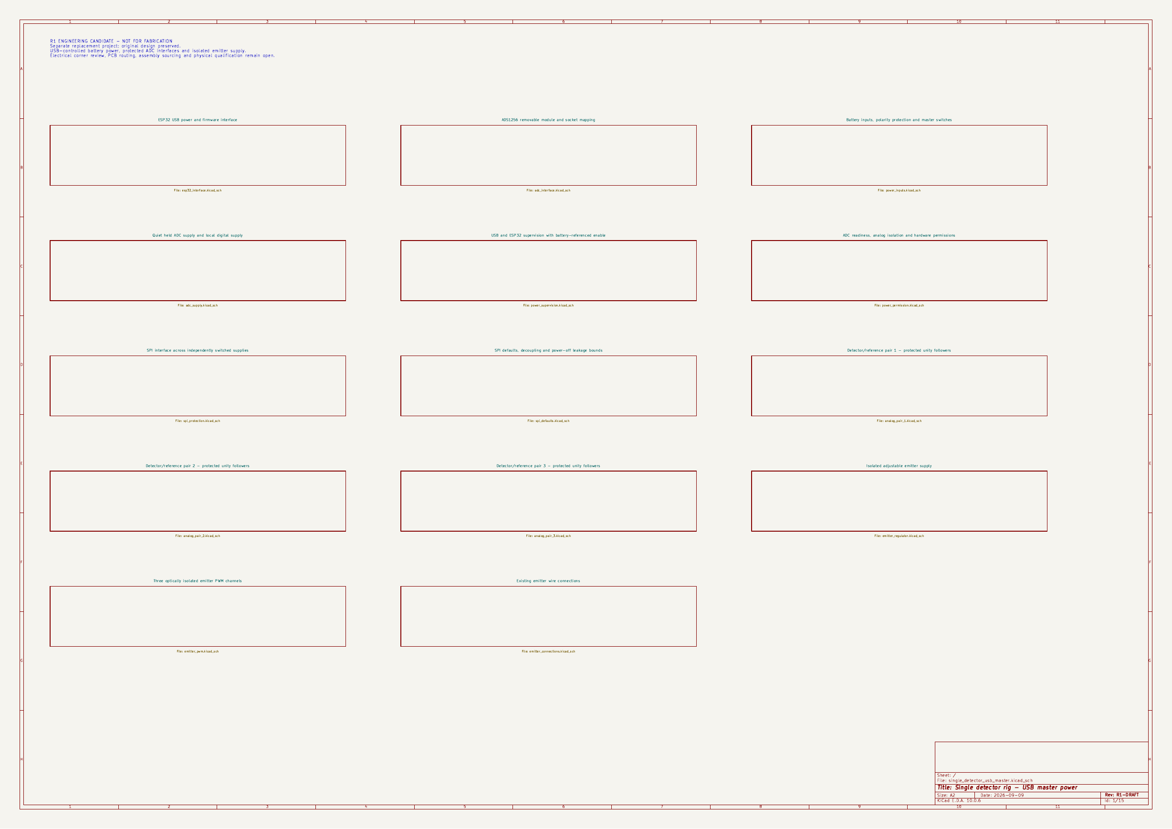
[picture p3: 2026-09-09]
hardware/single_detector_usb_master_r1/reports/schematic_visual/page-01.png

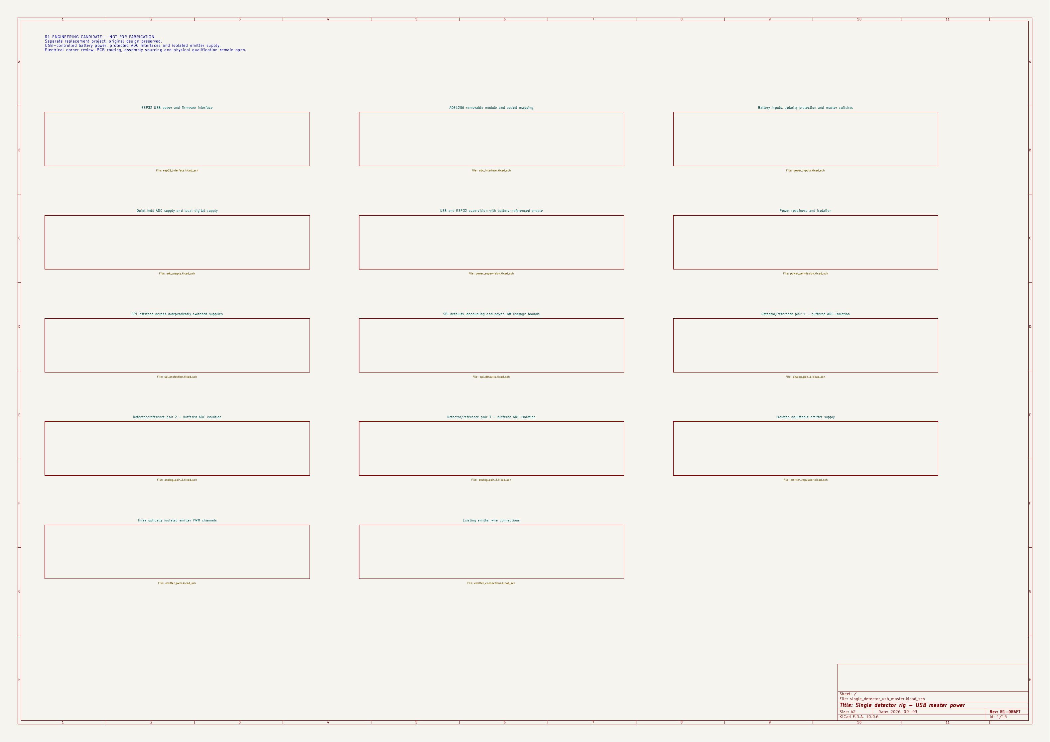
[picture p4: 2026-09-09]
hardware/single_detector_usb_master_r1/reports/schematic_visual_current/page-01.png

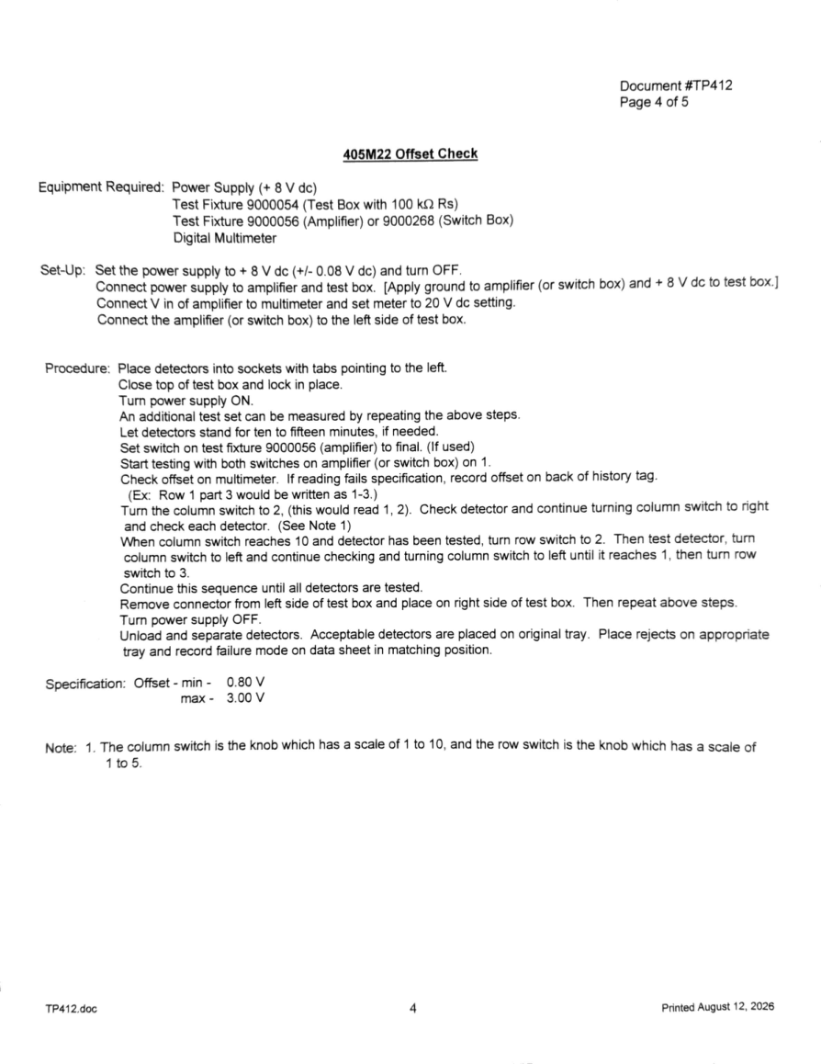
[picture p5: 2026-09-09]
hardware/single_detector_usb_master_r1/reports/detector_pdf_review/405M22_3.png

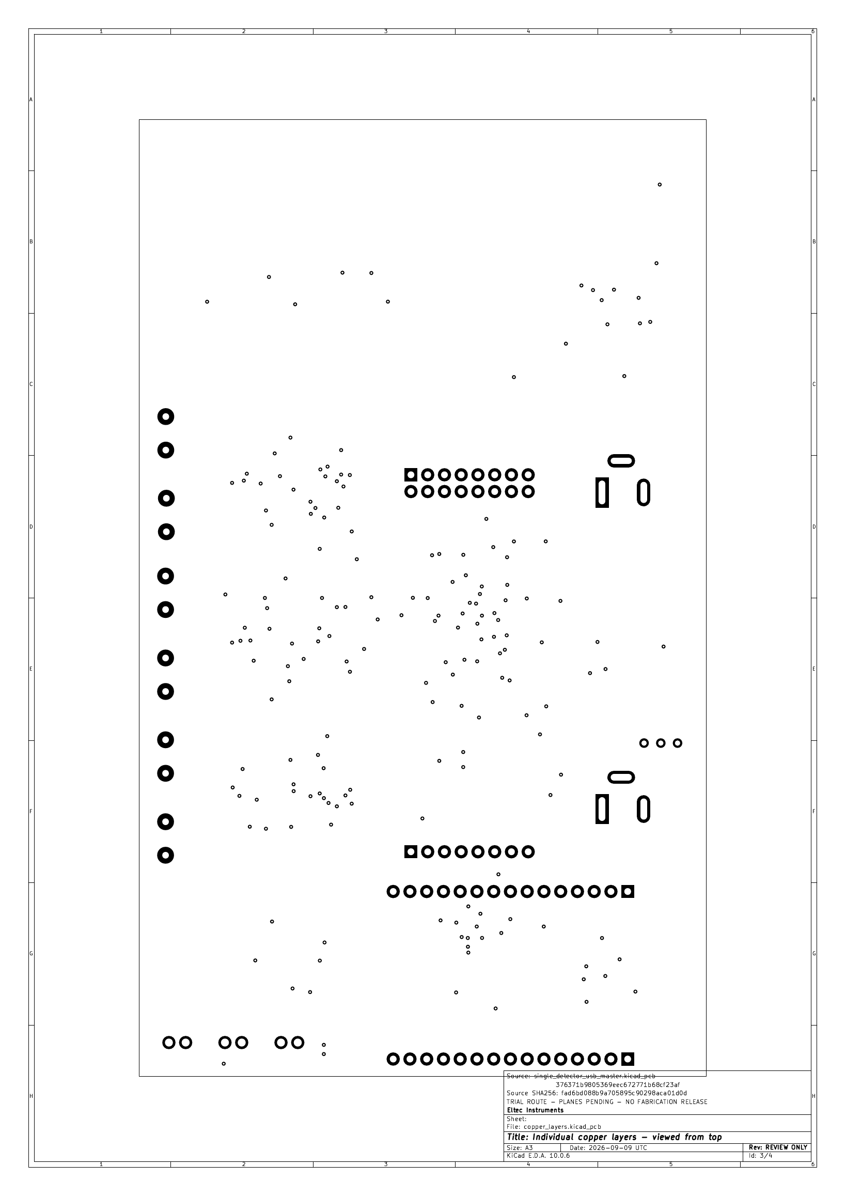
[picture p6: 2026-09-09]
hardware/single_detector_usb_master_r1/exports/board_review/trial01_copper_c/rendered_pages/copper_layers-3.png

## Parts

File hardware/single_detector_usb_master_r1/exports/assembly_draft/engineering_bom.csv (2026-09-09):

Designator | Value | Manufacturer | MPN | Footprint | JLCPCB Part # | Assembly | Catalog source | Assembly status
C10 | 22uF 25V tantalum +/-10% | Kyocera AVX | TPSD226K025R0200 | Eltec_Master:CP_EIA-7343-31_Kemet-D | C284839 | SMT | https://jlcpcb.com/partdetail/KyoceraAVX-TPSD226K025R0200/C284839 | JLC Extended; SMT Assembly; Economic and Standard; allocation unconfirmed
C11 | 22uF 25V X7R +/-10% | Murata | GRM32ER71E226KE15L | Eltec_Master:C_1210_3225Metric | C21397 | SMT | https://www.lcsc.com/product-detail/C21397.html | LCSC identity verified; JLC assembly match and allocation unconfirmed
C12 | 820uF 6.3V polymer +/-20% | Nichicon | PCJ0J821MCL4GS | Eltec_Master:CP_Elec_8x11.9 | C2161767 | SMT | https://www.lcsc.com/product-detail/C2161767.html | LCSC exact MPN and manufacturer identity verified; JLC assembly match and allocation unconfirmed
C13 | 22uF 25V X7R +/-10% | Murata | GRM32ER71E226KE15L | Eltec_Master:C_1210_3225Metric | C21397 | SMT | https://www.lcsc.com/product-detail/C21397.html | LCSC identity verified; JLC assembly match and allocation unconfirmed
C14 | 100nF 5% C0G | Murata | GRM31C5C1H104JA01K | Eltec_Master:C_1206_3216Metric | C398933 | SMT | https://www.lcsc.com/product-detail/C398933.html | LCSC identity verified; JLC assembly match and allocation unconfirmed
C15 | 100nF 50V 5% C0G | Murata | GRM31C5C1H104JA01K | Eltec_Master:C_1206_3216Metric | C398933 | SMT | https://www.lcsc.com/product-detail/C398933.html | LCSC identity verified; JLC assembly match and allocation unconfirmed
C16 | 100nF 50V X7R | Samsung Electro-Mechanics | CL10B104KB8NNNC | Eltec_Master:C_0603_1608Metric | C1591 | SMT | https://www.lcsc.com/product-detail/C1591.html | LCSC identity verified; JLC assembly match and allocation unconfirmed
C17 | 4.7uF 25V X7R | Samsung Electro-Mechanics | CL21B475KAFNNNE | Eltec_Master:C_0805_2012Metric | C98195 | SMT | https://www.lcsc.com/product-detail/C98195.html | LCSC identity verified; JLC assembly match and allocation unconfirmed
C18 | 4.7uF 25V X7R | Samsung Electro-Mechanics | CL21B475KAFNNNE | Eltec_Master:C_0805_2012Metric | C98195 | SMT | https://www.lcsc.com/product-detail/C98195.html | LCSC identity verified; JLC assembly match and allocation unconfirmed
C19 | 100nF 50V X7R | Samsung Electro-Mechanics | CL10B104KB8NNNC | Eltec_Master:C_0603_1608Metric | C1591 | SMT | https://www.lcsc.com/product-detail/C1591.html | LCSC identity verified; JLC assembly match and allocation unconfirmed
C20 | 10nF 5% C0G | Murata | GRM1885C1H103JA01D | Eltec_Master:C_0603_1608Metric | C85973 | SMT | https://www.lcsc.com/product-detail/C85973.html | LCSC identity verified; JLC assembly match and allocation unconfirmed
C21 | 100nF 50V X7R | Samsung Electro-Mechanics | CL10B104KB8NNNC | Eltec_Master:C_0603_1608Metric | C1591 | SMT | https://www.lcsc.com/product-detail/C1591.html | LCSC identity verified; JLC assembly match and allocation unconfirmed
C22 | 10nF 5% C0G | Murata | GRM1885C1H103JA01D | Eltec_Master:C_0603_1608Metric | C85973 | SMT | https://www.lcsc.com/product-detail/C85973.html | LCSC identity verified; JLC assembly match and allocation unconfirmed
C23 | 100nF 5% C0G | Murata | GRM31C5C1H104JA01K | Eltec_Master:C_1206_3216Metric | C398933 | SMT | https://www.lcsc.com/product-detail/C398933.html | LCSC identity verified; JLC assembly match and allocation unconfirmed
C24 | 100nF 5% C0G | Murata | GRM31C5C1H104JA01K | Eltec_Master:C_1206_3216Metric | C398933 | SMT | https://www.lcsc.com/product-detail/C398933.html | LCSC identity verified; JLC assembly match and allocation unconfirmed
C25 | 100nF 50V X7R | Samsung Electro-Mechanics | CL10B104KB8NNNC | Eltec_Master:C_0603_1608Metric | C1591 | SMT | https://www.lcsc.com/product-detail/C1591.html | LCSC identity verified; JLC assembly match and allocation unconfirmed
C26 | 100nF 50V X7R | Samsung Electro-Mechanics | CL10B104KB8NNNC | Eltec_Master:C_0603_1608Metric | C1591 | SMT | https://www.lcsc.com/product-detail/C1591.html | LCSC identity verified; JLC assembly match and allocation unconfirmed
C27 | 100nF 50V X7R | Samsung Electro-Mechanics | CL10B104KB8NNNC | Eltec_Master:C_0603_1608Metric | C1591 | SMT | https://www.lcsc.com/product-detail/C1591.html | LCSC identity verified; JLC assembly match and allocation unconfirmed
C28 | 100nF 50V X7R | Samsung Electro-Mechanics | CL10B104KB8NNNC | Eltec_Master:C_0603_1608Metric | C1591 | SMT | https://www.lcsc.com/product-detail/C1591.html | LCSC identity verified; JLC assembly match and allocation unconfirmed
C29 | 100nF 50V X7R | Samsung Electro-Mechanics | CL10B104KB8NNNC | Eltec_Master:C_0603_1608Metric | C1591 | SMT | https://www.lcsc.com/product-detail/C1591.html | LCSC identity verified; JLC assembly match and allocation unconfirmed
C30 | 100nF 50V X7R | Samsung Electro-Mechanics | CL21B104KBCNNNC | Eltec_Master:C_0805_2012Metric | C1711 | SMT | https://www.lcsc.com/product-detail/C1711.html | LCSC identity verified; JLC assembly match and allocation unconfirmed
C31 | 100nF 50V X7R | Samsung Electro-Mechanics | CL21B104KBCNNNC | Eltec_Master:C_0805_2012Metric | C1711 | SMT | https://www.lcsc.com/product-detail/C1711.html | LCSC identity verified; JLC assembly match and allocation unconfirmed
C32 | 100nF 50V X7R | Samsung Electro-Mechanics | CL21B104KBCNNNC | Eltec_Master:C_0805_2012Metric | C1711 | SMT | https://www.lcsc.com/product-detail/C1711.html | LCSC identity verified; JLC assembly match and allocation unconfirmed
C33 | 100nF 50V X7R | Samsung Electro-Mechanics | CL21B104KBCNNNC | Eltec_Master:C_0805_2012Metric | C1711 | SMT | https://www.lcsc.com/product-detail/C1711.html | LCSC identity verified; JLC assembly match and allocation unconfirmed
C34 | 100nF 50V X7R | Samsung Electro-Mechanics | CL21B104KBCNNNC | Eltec_Master:C_0805_2012Metric | C1711 | SMT | https://www.lcsc.com/product-detail/C1711.html | LCSC identity verified; JLC assembly match and allocation unconfirmed
C35 | 100nF 50V X7R | Samsung Electro-Mechanics | CL21B104KBCNNNC | Eltec_Master:C_0805_2012Metric | C1711 | SMT | https://www.lcsc.com/product-detail/C1711.html | LCSC identity verified; JLC assembly match and allocation unconfirmed
C36 | 22uF 25V X7R +/-10% | Murata | GRM32ER71E226KE15L | Eltec_Master:C_1210_3225Metric | C21397 | SMT | https://www.lcsc.com/product-detail/C21397.html | LCSC identity verified; JLC assembly match and allocation unconfirmed
C37 | 100nF 50V 5% C0G | Murata | GRM31C5C1H104JA01K | Eltec_Master:C_1206_3216Metric | C398933 | SMT | https://www.lcsc.com/product-detail/C398933.html | LCSC identity verified; JLC assembly match and allocation unconfirmed
C38 | 100nF 50V 5% C0G | Murata | GRM31C5C1H104JA01K | Eltec_Master:C_1206_3216Metric | C398933 | SMT | https://www.lcsc.com/product-detail/C398933.html | LCSC identity verified; JLC assembly match and allocation unconfirmed
C39 | 22uF 25V X7R +/-10% | Murata | GRM32ER71E226KE15L | Eltec_Master:C_1210_3225Metric | C21397 | SMT | https://www.lcsc.com/product-detail/C21397.html | LCSC identity verified; JLC assembly match and allocation unconfirmed
C50 | 100nF 50V X7R | Samsung Electro-Mechanics | CL21B104KBCNNNC | Eltec_Master:C_0805_2012Metric | C1711 | SMT | https://www.lcsc.com/product-detail/C1711.html | LCSC identity verified; JLC assembly match and allocation unconfirmed
C51 | 100nF 50V X7R | Samsung Electro-Mechanics | CL21B104KBCNNNC | Eltec_Master:C_0805_2012Metric | C1711 | SMT | https://www.lcsc.com/product-detail/C1711.html | LCSC identity verified; JLC assembly match and allocation unconfirmed
C52 | 100nF 50V X7R | Samsung Electro-Mechanics | CL21B104KBCNNNC | Eltec_Master:C_0805_2012Metric | C1711 | SMT | https://www.lcsc.com/product-detail/C1711.html | LCSC identity verified; JLC assembly match and allocation unconfirmed
C100 | 22uF 25V 10% TPS | Kyocera AVX | TPSD226K025R0200 | Eltec_Master:CP_EIA-7343-31_Kemet-D | C284839 | SMT | https://jlcpcb.com/partdetail/KyoceraAVX-TPSD226K025R0200/C284839 | JLC Extended; SMT Assembly; Economic and Standard; allocation unconfirmed
C101 | 100nF 50V X7R 10% | Samsung Electro-Mechanics | CL21B104KBCNNNC | Eltec_Master:C_0805_2012Metric | C1711 | SMT | https://www.lcsc.com/product-detail/C1711.html | LCSC identity verified; JLC assembly match and allocation unconfirmed
C102 | 22uF 25V 10% TPS | Kyocera AVX | TPSD226K025R0200 | Eltec_Master:CP_EIA-7343-31_Kemet-D | C284839 | SMT | https://jlcpcb.com/partdetail/KyoceraAVX-TPSD226K025R0200/C284839 | JLC Extended; SMT Assembly; Economic and Standard; allocation unconfirmed
C103 | 100nF 50V X7R 10% | Samsung Electro-Mechanics | CL21B104KBCNNNC | Eltec_Master:C_0805_2012Metric | C1711 | SMT | https://www.lcsc.com/product-detail/C1711.html | LCSC identity verified; JLC assembly match and allocation unconfirmed
D10 | 1N4148W | Diodes Incorporated | 1N4148W-7-F | Eltec_Master:D_SOD-123 | C83528 | SMT | https://www.lcsc.com/product-detail/C83528.html | LCSC identity verified; JLC assembly match and allocation unconfirmed
D11 | 1N4148W | Diodes Incorporated | 1N4148W-7-F | Eltec_Master:D_SOD-123 | C83528 | SMT | https://www.lcsc.com/product-detail/C83528.html | LCSC identity verified; JLC assembly match and allocation unconfirmed
D12 | BZT52C6V8GW | Diotec Semiconductor | BZT52C6V8GW | Eltec_Master:D_SOD-123 |  | SMT |  | Allocation and library rotation unverified
F1 | 1A Slo-Blo | Littelfuse | 0468001.NRHF | Eltec_Master:Fuse_1206_3216Metric | C45157 | SMT | https://www.lcsc.com/product-detail/C45157.html | LCSC identity verified; JLC assembly match and allocation unconfirmed
F2 | 1.5A Slo-Blo | Littelfuse | 046801.5NRHF | Eltec_Master:Fuse_1206_3216Metric | C151143 | SMT | https://www.lcsc.com/product-detail/C151143.html | LCSC identity verified; JLC assembly match and allocation unconfirmed
J3 | 1x15 female socket - row A | Kinghelm | KH-2.54FH-1X15P-H8.5 | Eltec_Master:Socket_Kinghelm_1x15_P2.54_H8.5 | C2932676 | THT | https://jlcpcb.com/partdetail/3278197-KH_2_54FH_1X15P_H85/C2932676 | JLC Extended; Wave Soldering; Economic and Standard; allocation unconfirmed
J4 | 1x15 female socket - row B | Kinghelm | KH-2.54FH-1X15P-H8.5 | Eltec_Master:Socket_Kinghelm_1x15_P2.54_H8.5 | C2932676 | THT | https://jlcpcb.com/partdetail/3278197-KH_2_54FH_1X15P_H85/C2932676 | JLC Extended; Wave Soldering; Economic and Standard; allocation unconfirmed
J5 | 1x8 female ADC digital socket | Kinghelm | KH-2.54FH-1X8P-H8.5 | Eltec_Master:Socket_Kinghelm_1x08_P2.54_H8.5 | C2905417 | THT | https://jlcpcb.com/partdetail/3175191-KH_2_54FH_1X8P_H85/C2905417 | JLC Extended; Wave Soldering; Economic and Standard; fixture requirements require quote confirmation; allocation unconfirmed
J6 | 2x8 female ADC analog socket | FG | FG-PM2.54-2-08P-H8.5 | Eltec_Master:Socket_FG_2x08_P2.54_H8.5 | C25687193 | THT | https://www.lcsc.com/product-detail/C25687193.html | LCSC identity verified; JLC assembly match and allocation unconfirmed
Q10 | AO3414 | Alpha & Omega Semiconductor | AO3414 | Eltec_Master:SOT-23 | C48850 | SMT | https://www.lcsc.com/product-detail/C48850.html | LCSC identity verified; JLC assembly match and allocation unconfirmed
Q11 | AO3414 | Alpha & Omega Semiconductor | AO3414 | Eltec_Master:SOT-23 | C48850 | SMT | https://www.lcsc.com/product-detail/C48850.html | LCSC identity verified; JLC assembly match and allocation unconfirmed
Q12 | 2N7002LT1G | onsemi | 2N7002LT1G | Eltec_Master:SOT-23 | C16338 | SMT | https://www.lcsc.com/product-detail/C16338.html | LCSC identity verified; JLC assembly match and allocation unconfirmed
Q13 | 2N7002LT1G | onsemi | 2N7002LT1G | Eltec_Master:SOT-23 | C16338 | SMT | https://www.lcsc.com/product-detail/C16338.html | LCSC identity verified; JLC assembly match and allocation unconfirmed
Q14 | 2N7002LT1G | onsemi | 2N7002LT1G | Eltec_Master:SOT-23 | C16338 | SMT | https://www.lcsc.com/product-detail/C16338.html | LCSC identity verified; JLC assembly match and allocation unconfirmed
Q15 | 2N7002LT1G | onsemi | 2N7002LT1G | Eltec_Master:SOT-23 | C16338 | SMT | https://www.lcsc.com/product-detail/C16338.html | LCSC identity verified; JLC assembly match and allocation unconfirmed
Q16 | AO3401A | Alpha & Omega Semiconductor | AO3401A | Eltec_Master:SOT-23 | C15127 | SMT | https://www.lcsc.com/product-detail/C15127.html | LCSC identity verified; JLC assembly match and allocation unconfirmed
Q17 | AO3401A | Alpha & Omega Semiconductor | AO3401A | Eltec_Master:SOT-23 | C15127 | SMT | https://www.lcsc.com/product-detail/C15127.html | LCSC identity verified; JLC assembly match and allocation unconfirmed
Q18 | 2N7002LT1G | onsemi | 2N7002LT1G | Eltec_Master:SOT-23 | C16338 | SMT | https://www.lcsc.com/product-detail/C16338.html | LCSC identity verified; JLC assembly match and allocation unconfirmed
Q19 | AO3401A | Alpha & Omega Semiconductor | AO3401A | Eltec_Master:SOT-23 | C15127 | SMT | https://www.lcsc.com/product-detail/C15127.html | LCSC identity verified; JLC assembly match and allocation unconfirmed
Q20 | AO3401A | Alpha & Omega Semiconductor | AO3401A | Eltec_Master:SOT-23 | C15127 | SMT | https://www.lcsc.com/product-detail/C15127.html | LCSC identity verified; JLC assembly match and allocation unconfirmed
Q21 | 2N7002LT1G | onsemi | 2N7002LT1G | Eltec_Master:SOT-23 | C16338 | SMT | https://www.lcsc.com/product-detail/C16338.html | LCSC identity verified; JLC assembly match and allocation unconfirmed
Q22 | AO3400A | Alpha & Omega Semiconductor | AO3400A | Eltec_Master:SOT-23 | C20917 | SMT | https://jlcpcb.com/partdetail/Alpha_OmegaSemicon-AO3400A/C20917 | JLC Basic; SMT Assembly; Economic and Standard; allocation unconfirmed
Q23 | AO3414 | Alpha & Omega Semiconductor | AO3414 | Eltec_Master:SOT-23 | C48850 | SMT | https://www.lcsc.com/product-detail/C48850.html | LCSC identity verified; JLC assembly match and allocation unconfirmed
Q24 | AO3414 | Alpha & Omega Semiconductor | AO3414 | Eltec_Master:SOT-23 | C48850 | SMT | https://www.lcsc.com/product-detail/C48850.html | LCSC identity verified; JLC assembly match and allocation unconfirmed
Q26 | AO3414 | Alpha & Omega Semiconductor | AO3414 | Eltec_Master:SOT-23 | C48850 | SMT | https://www.lcsc.com/product-detail/C48850.html | LCSC identity verified; JLC assembly match and allocation unconfirmed
Q50 | MMBT3904LT1G | onsemi | MMBT3904LT1G | Eltec_Master:SOT-23 | C81464 | SMT | https://www.lcsc.com/product-detail/C81464.html | LCSC identity verified; JLC assembly match and allocation unconfirmed
Q51 | MMBT3904LT1G | onsemi | MMBT3904LT1G | Eltec_Master:SOT-23 | C81464 | SMT | https://www.lcsc.com/product-detail/C81464.html | LCSC identity verified; JLC assembly match and allocation unconfirmed
Q101 | AO3400A | Alpha & Omega Semiconductor | AO3400A | Eltec_Master:SOT-23 | C20917 | SMT | https://jlcpcb.com/partdetail/Alpha_OmegaSemicon-AO3400A/C20917 | JLC Basic; SMT Assembly; Economic and Standard; allocation unconfirmed
Q102 | AO3400A | Alpha & Omega Semiconductor | AO3400A | Eltec_Master:SOT-23 | C20917 | SMT | https://jlcpcb.com/partdetail/Alpha_OmegaSemicon-AO3400A/C20917 | JLC Basic; SMT Assembly; Economic and Standard; allocation unconfirmed
Q103 | AO3400A | Alpha & Omega Semiconductor | AO3400A | Eltec_Master:SOT-23 | C20917 | SMT | https://jlcpcb.com/partdetail/Alpha_OmegaSemicon-AO3400A/C20917 | JLC Basic; SMT Assembly; Economic and Standard; allocation unconfirmed
R10 | 51.1k 0.1% 10ppm/K | TE Connectivity | RN73C1J51K1BTDF | Eltec_Master:R_0603_1608Metric | C4226875 | SMT | https://www.lcsc.com/product-detail/C4226875.html | LCSC exact MPN and manufacturer identity verified; JLC assembly match and allocation unconfirmed
R11 | 300 0.1% | Yageo | RT0603BRD07300RL | Eltec_Master:R_0603_1608Metric | C705763 | SMT | https://www.lcsc.com/product-detail/C705763.html | LCSC identity verified; JLC assembly match and allocation unconfirmed
R12 | 4.7k 1% | Yageo | RC0603FR-074K7L | Eltec_Master:R_0603_1608Metric | C99782 | SMT | https://www.lcsc.com/product-detail/C99782.html | LCSC identity verified; JLC assembly match and allocation unconfirmed
R13 | 10k 1% | Yageo | RC0603FR-0710KL | Eltec_Master:R_0603_1608Metric | C98220 | SMT | https://www.lcsc.com/product-detail/C98220.html | LCSC identity verified; JLC assembly match and allocation unconfirmed
R14 | 100k 1% | Yageo | RC0603FR-07100KL | Eltec_Master:R_0603_1608Metric | C14675 | SMT | https://www.lcsc.com/product-detail/C14675.html | LCSC identity verified; JLC assembly match and allocation unconfirmed
R15 | 100k 1% | Yageo | RC0603FR-07100KL | Eltec_Master:R_0603_1608Metric | C14675 | SMT | https://www.lcsc.com/product-detail/C14675.html | LCSC identity verified; JLC assembly match and allocation unconfirmed
R16 | 1k 1% | Yageo | RC0603FR-071KL | Eltec_Master:R_0603_1608Metric | C22548 | SMT | https://www.lcsc.com/product-detail/C22548.html | LCSC identity verified; JLC assembly match and allocation unconfirmed
R17 | 1k 1% | Yageo | RC0603FR-071KL | Eltec_Master:R_0603_1608Metric | C22548 | SMT | https://www.lcsc.com/product-detail/C22548.html | LCSC identity verified; JLC assembly match and allocation unconfirmed
R18 | 10k 1% | Yageo | RC0603FR-0710KL | Eltec_Master:R_0603_1608Metric | C98220 | SMT | https://www.lcsc.com/product-detail/C98220.html | LCSC identity verified; JLC assembly match and allocation unconfirmed
R19 | 0 | Yageo | RC0603JR-070RL | Eltec_Master:R_0603_1608Metric | C95177 | SMT | https://www.lcsc.com/product-detail/C95177.html | LCSC identity verified; JLC assembly match and allocation unconfirmed
R20 | 4.7k 1% | Yageo | RC0603FR-074K7L | Eltec_Master:R_0603_1608Metric | C99782 | SMT | https://www.lcsc.com/product-detail/C99782.html | LCSC identity verified; JLC assembly match and allocation unconfirmed
R21 | 10k 1% | Yageo | RC0603FR-0710KL | Eltec_Master:R_0603_1608Metric | C98220 | SMT | https://www.lcsc.com/product-detail/C98220.html | LCSC identity verified; JLC assembly match and allocation unconfirmed
R22 | 1k 1% | Yageo | RC0603FR-071KL | Eltec_Master:R_0603_1608Metric | C22548 | SMT | https://www.lcsc.com/product-detail/C22548.html | LCSC identity verified; JLC assembly match and allocation unconfirmed
R23 | 10k 1% | Yageo | RC0603FR-0710KL | Eltec_Master:R_0603_1608Metric | C98220 | SMT | https://www.lcsc.com/product-detail/C98220.html | LCSC identity verified; JLC assembly match and allocation unconfirmed
R24 | 1k 1% | Yageo | RC0603FR-071KL | Eltec_Master:R_0603_1608Metric | C22548 | SMT | https://www.lcsc.com/product-detail/C22548.html | LCSC identity verified; JLC assembly match and allocation unconfirmed
R25 | 390 1% | Yageo | RC0603FR-07390RL | Eltec_Master:R_0603_1608Metric | C114620 | SMT | https://www.lcsc.com/product-detail/C114620.html | LCSC identity verified; JLC assembly match and allocation unconfirmed
R26 | 100 1% | Yageo | RC0603FR-07100RL | Eltec_Master:R_0603_1608Metric | C105588 | SMT | https://www.lcsc.com/product-detail/C105588.html | LCSC identity verified; JLC assembly match and allocation unconfirmed
R27 | 100k 1% | Yageo | RC0603FR-07100KL | Eltec_Master:R_0603_1608Metric | C14675 | SMT | https://www.lcsc.com/product-detail/C14675.html | LCSC identity verified; JLC assembly match and allocation unconfirmed
R28 | 100k 1% | Yageo | RC0603FR-07100KL | Eltec_Master:R_0603_1608Metric | C14675 | SMT | https://www.lcsc.com/product-detail/C14675.html | LCSC identity verified; JLC assembly match and allocation unconfirmed
R29 | 100k 1% | Yageo | RC0603FR-07100KL | Eltec_Master:R_0603_1608Metric | C14675 | SMT | https://www.lcsc.com/product-detail/C14675.html | LCSC identity verified; JLC assembly match and allocation unconfirmed
R30 | 1.5k 1% | Yageo | RC0603FR-071K5L | Eltec_Master:R_0603_1608Metric | C114668 | SMT | https://www.lcsc.com/product-detail/C114668.html | LCSC identity verified; JLC assembly match and allocation unconfirmed
R31 | 221 0.1% 25ppm/K | Yageo | RT0603BRD07221RL | Eltec_Master:R_0603_1608Metric | C705749 | SMT | https://www.lcsc.com/product-detail/C705749.html | LCSC exact MPN and manufacturer identity verified; JLC assembly match and allocation unconfirmed
R32 | 1.00k 0.1% 25ppm/K | Yageo | RT0603BRD071KL | Eltec_Master:R_0603_1608Metric | C110776 | SMT | https://www.lcsc.com/product-detail/C110776.html | LCSC identity verified; JLC assembly match and allocation unconfirmed
R33 | 10k 1% | Yageo | RC0603FR-0710KL | Eltec_Master:R_0603_1608Metric | C98220 | SMT | https://www.lcsc.com/product-detail/C98220.html | LCSC identity verified; JLC assembly match and allocation unconfirmed
R34 | 100k 1% | Yageo | RC0603FR-07100KL | Eltec_Master:R_0603_1608Metric | C14675 | SMT | https://www.lcsc.com/product-detail/C14675.html | LCSC identity verified; JLC assembly match and allocation unconfirmed
R35 | 100k 1% | Yageo | RC0603FR-07100KL | Eltec_Master:R_0603_1608Metric | C14675 | SMT | https://www.lcsc.com/product-detail/C14675.html | LCSC identity verified; JLC assembly match and allocation unconfirmed
R38 | 10k 1% | Yageo | RC0603FR-0710KL | Eltec_Master:R_0603_1608Metric | C98220 | SMT | https://www.lcsc.com/product-detail/C98220.html | LCSC identity verified; JLC assembly match and allocation unconfirmed
R39 | 698 0.1% 10ppm/K | TE Connectivity | RN73C1J698RBTDF | Eltec_Master:R_0603_1608Metric |  | SMT |  | Allocation and library rotation unverified
R40 | 150 1% | Yageo | RC0603FR-07150RL | Eltec_Master:R_0603_1608Metric | C114608 | SMT | https://www.lcsc.com/product-detail/C114608.html | LCSC identity verified; JLC assembly match and allocation unconfirmed
R50 | 10k | Yageo | RC0805FR-0710KL | Eltec_Master:R_0805_2012Metric | C84376 | SMT | https://www.lcsc.com/product-detail/C84376.html | LCSC identity verified; JLC assembly match and allocation unconfirmed
R51 | 100k | Yageo | RC0805FR-07100KL | Eltec_Master:R_0805_2012Metric | C96346 | SMT | https://www.lcsc.com/product-detail/C96346.html | LCSC identity verified; JLC assembly match and allocation unconfirmed
R52 | 10k | Yageo | RC0805FR-0710KL | Eltec_Master:R_0805_2012Metric | C84376 | SMT | https://www.lcsc.com/product-detail/C84376.html | LCSC identity verified; JLC assembly match and allocation unconfirmed
R53 | 10k | Yageo | RC0805FR-0710KL | Eltec_Master:R_0805_2012Metric | C84376 | SMT | https://www.lcsc.com/product-detail/C84376.html | LCSC identity verified; JLC assembly match and allocation unconfirmed
R54 | 100k | Yageo | RC0805FR-07100KL | Eltec_Master:R_0805_2012Metric | C96346 | SMT | https://www.lcsc.com/product-detail/C96346.html | LCSC identity verified; JLC assembly match and allocation unconfirmed
R55 | 10k | Yageo | RC0805FR-0710KL | Eltec_Master:R_0805_2012Metric | C84376 | SMT | https://www.lcsc.com/product-detail/C84376.html | LCSC identity verified; JLC assembly match and allocation unconfirmed
R56 | 33 | Yageo | RC0805FR-0733RL | Eltec_Master:R_0805_2012Metric | C126353 | SMT | https://www.lcsc.com/product-detail/C126353.html | LCSC identity verified; JLC assembly match and allocation unconfirmed
R57 | 33 | Yageo | RC0805FR-0733RL | Eltec_Master:R_0805_2012Metric | C126353 | SMT | https://www.lcsc.com/product-detail/C126353.html | LCSC identity verified; JLC assembly match and allocation unconfirmed
R58 | 33 | Yageo | RC0805FR-0733RL | Eltec_Master:R_0805_2012Metric | C126353 | SMT | https://www.lcsc.com/product-detail/C126353.html | LCSC identity verified; JLC assembly match and allocation unconfirmed
R59 | 33 | Yageo | RC0805FR-0733RL | Eltec_Master:R_0805_2012Metric | C126353 | SMT | https://www.lcsc.com/product-detail/C126353.html | LCSC identity verified; JLC assembly match and allocation unconfirmed
R60 | 33 | Yageo | RC0805FR-0733RL | Eltec_Master:R_0805_2012Metric | C126353 | SMT | https://www.lcsc.com/product-detail/C126353.html | LCSC identity verified; JLC assembly match and allocation unconfirmed
R61 | 10k | Yageo | RC0805FR-0710KL | Eltec_Master:R_0805_2012Metric | C84376 | SMT | https://www.lcsc.com/product-detail/C84376.html | LCSC identity verified; JLC assembly match and allocation unconfirmed
R62 | 10k | Yageo | RC0805FR-0710KL | Eltec_Master:R_0805_2012Metric | C84376 | SMT | https://www.lcsc.com/product-detail/C84376.html | LCSC identity verified; JLC assembly match and allocation unconfirmed
R63 | 10k | Yageo | RC0805FR-0710KL | Eltec_Master:R_0805_2012Metric | C84376 | SMT | https://www.lcsc.com/product-detail/C84376.html | LCSC identity verified; JLC assembly match and allocation unconfirmed
R64 | 10k | Yageo | RC0805FR-0710KL | Eltec_Master:R_0805_2012Metric | C84376 | SMT | https://www.lcsc.com/product-detail/C84376.html | LCSC identity verified; JLC assembly match and allocation unconfirmed
R65 | 10k | Yageo | RC0805FR-0710KL | Eltec_Master:R_0805_2012Metric | C84376 | SMT | https://www.lcsc.com/product-detail/C84376.html | LCSC identity verified; JLC assembly match and allocation unconfirmed
R66 | 10k | Yageo | RC0805FR-0710KL | Eltec_Master:R_0805_2012Metric | C84376 | SMT | https://www.lcsc.com/product-detail/C84376.html | LCSC identity verified; JLC assembly match and allocation unconfirmed
R67 | 10k | Yageo | RC0805FR-0710KL | Eltec_Master:R_0805_2012Metric | C84376 | SMT | https://www.lcsc.com/product-detail/C84376.html | LCSC identity verified; JLC assembly match and allocation unconfirmed
R68 | 10k | Yageo | RC0805FR-0710KL | Eltec_Master:R_0805_2012Metric | C84376 | SMT | https://www.lcsc.com/product-detail/C84376.html | LCSC identity verified; JLC assembly match and allocation unconfirmed
R69 | 10k | Yageo | RC0805FR-0710KL | Eltec_Master:R_0805_2012Metric | C84376 | SMT | https://www.lcsc.com/product-detail/C84376.html | LCSC identity verified; JLC assembly match and allocation unconfirmed
R70 | 10k | Yageo | RC0805FR-0710KL | Eltec_Master:R_0805_2012Metric | C84376 | SMT | https://www.lcsc.com/product-detail/C84376.html | LCSC identity verified; JLC assembly match and allocation unconfirmed
R100 | 210R 1% 0.125W | Yageo | RC0805FR-07210RL | Eltec_Master:R_0805_2012Metric |  | SMT |  | Allocation and library rotation unverified
R101 | 7R5 1% 0.125W | Yageo | RC0805FR-077R5L | Eltec_Master:R_0805_2012Metric |  | SMT |  | Allocation and library rotation unverified
R110 | 240R 1% 0.125W | Yageo | RC0805FR-07240RL | Eltec_Master:R_0805_2012Metric | C185292 | SMT | https://www.lcsc.com/product-detail/C185292.html | LCSC identity verified; JLC assembly match and allocation unconfirmed
R111 | 100k 1% 0.125W | Yageo | RC0805FR-07100KL | Eltec_Master:R_0805_2012Metric | C96346 | SMT | https://www.lcsc.com/product-detail/C96346.html | LCSC identity verified; JLC assembly match and allocation unconfirmed
R112 | 100R 1% 0.125W | Yageo | RC0805FR-07100RL | Eltec_Master:R_0805_2012Metric | C105577 | SMT | https://www.lcsc.com/product-detail/C105577.html | LCSC identity verified; JLC assembly match and allocation unconfirmed
R113 | 10k 1% 0.125W | Yageo | RC0805FR-0710KL | Eltec_Master:R_0805_2012Metric | C84376 | SMT | https://www.lcsc.com/product-detail/C84376.html | LCSC identity verified; JLC assembly match and allocation unconfirmed
R115 | 240R 1% 0.125W | Yageo | RC0805FR-07240RL | Eltec_Master:R_0805_2012Metric | C185292 | SMT | https://www.lcsc.com/product-detail/C185292.html | LCSC identity verified; JLC assembly match and allocation unconfirmed
R116 | 100k 1% 0.125W | Yageo | RC0805FR-07100KL | Eltec_Master:R_0805_2012Metric | C96346 | SMT | https://www.lcsc.com/product-detail/C96346.html | LCSC identity verified; JLC assembly match and allocation unconfirmed
R117 | 100R 1% 0.125W | Yageo | RC0805FR-07100RL | Eltec_Master:R_0805_2012Metric | C105577 | SMT | https://www.lcsc.com/product-detail/C105577.html | LCSC identity verified; JLC assembly match and allocation unconfirmed
R118 | 10k 1% 0.125W | Yageo | RC0805FR-0710KL | Eltec_Master:R_0805_2012Metric | C84376 | SMT | https://www.lcsc.com/product-detail/C84376.html | LCSC identity verified; JLC assembly match and allocation unconfirmed
R120 | 240R 1% 0.125W | Yageo | RC0805FR-07240RL | Eltec_Master:R_0805_2012Metric | C185292 | SMT | https://www.lcsc.com/product-detail/C185292.html | LCSC identity verified; JLC assembly match and allocation unconfirmed
R121 | 100k 1% 0.125W | Yageo | RC0805FR-07100KL | Eltec_Master:R_0805_2012Metric | C96346 | SMT | https://www.lcsc.com/product-detail/C96346.html | LCSC identity verified; JLC assembly match and allocation unconfirmed
R122 | 100R 1% 0.125W | Yageo | RC0805FR-07100RL | Eltec_Master:R_0805_2012Metric | C105577 | SMT | https://www.lcsc.com/product-detail/C105577.html | LCSC identity verified; JLC assembly match and allocation unconfirmed
R123 | 10k 1% 0.125W | Yageo | RC0805FR-0710KL | Eltec_Master:R_0805_2012Metric | C84376 | SMT | https://www.lcsc.com/product-detail/C84376.html | LCSC identity verified; JLC assembly match and allocation unconfirmed
R200 | 100k 1% | Yageo | RC0805FR-07100KL | Eltec_Master:R_0805_2012Metric | C96346 | SMT | https://www.lcsc.com/product-detail/C96346.html | LCSC identity verified; JLC assembly match and allocation unconfirmed
R201 | 100k 1% | Yageo | RC0805FR-07100KL | Eltec_Master:R_0805_2012Metric | C96346 | SMT | https://www.lcsc.com/product-detail/C96346.html | LCSC identity verified; JLC assembly match and allocation unconfirmed
R202 | 100k 1% | Yageo | RC0805FR-07100KL | Eltec_Master:R_0805_2012Metric | C96346 | SMT | https://www.lcsc.com/product-detail/C96346.html | LCSC identity verified; JLC assembly match and allocation unconfirmed
R203 | 100k 1% | Yageo | RC0805FR-07100KL | Eltec_Master:R_0805_2012Metric | C96346 | SMT | https://www.lcsc.com/product-detail/C96346.html | LCSC identity verified; JLC assembly match and allocation unconfirmed
R204 | 100k 1% | Yageo | RC0805FR-07100KL | Eltec_Master:R_0805_2012Metric | C96346 | SMT | https://www.lcsc.com/product-detail/C96346.html | LCSC identity verified; JLC assembly match and allocation unconfirmed
R205 | 100k 1% | Yageo | RC0805FR-07100KL | Eltec_Master:R_0805_2012Metric | C96346 | SMT | https://www.lcsc.com/product-detail/C96346.html | LCSC identity verified; JLC assembly match and allocation unconfirmed
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

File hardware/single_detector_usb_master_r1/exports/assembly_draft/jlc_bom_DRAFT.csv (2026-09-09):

Comment | Designator | Footprint | JLCPCB Part #
TPSD226K025R0200 | C10 | CP_EIA-7343-31_Kemet-D | C284839
GRM32ER71E226KE15L | C11,C13,C36,C39 | C_1210_3225Metric | C21397
PCJ0J821MCL4GS | C12 | CP_Elec_8x11.9 | C2161767
GRM31C5C1H104JA01K | C14,C23,C24 | C_1206_3216Metric | C398933
GRM31C5C1H104JA01K | C15,C37,C38 | C_1206_3216Metric | C398933
CL10B104KB8NNNC | C16,C19,C21,C25,C26,C27,C28,C29 | C_0603_1608Metric | C1591
CL21B475KAFNNNE | C17,C18 | C_0805_2012Metric | C98195
GRM1885C1H103JA01D | C20,C22 | C_0603_1608Metric | C85973
CL21B104KBCNNNC | C30,C31,C32,C33,C34,C35,C50,C51,C52 | C_0805_2012Metric | C1711
TPSD226K025R0200 | C100,C102 | CP_EIA-7343-31_Kemet-D | C284839
CL21B104KBCNNNC | C101,C103 | C_0805_2012Metric | C1711
1N4148W-7-F | D10,D11 | D_SOD-123 | C83528
BZT52C6V8GW | D12 | D_SOD-123
0468001.NRHF | F1 | Fuse_1206_3216Metric | C45157
046801.5NRHF | F2 | Fuse_1206_3216Metric | C151143
KH-2.54FH-1X15P-H8.5 | J3 | Socket_Kinghelm_1x15_P2.54_H8.5 | C2932676
KH-2.54FH-1X15P-H8.5 | J4 | Socket_Kinghelm_1x15_P2.54_H8.5 | C2932676
KH-2.54FH-1X8P-H8.5 | J5 | Socket_Kinghelm_1x08_P2.54_H8.5 | C2905417
FG-PM2.54-2-08P-H8.5 | J6 | Socket_FG_2x08_P2.54_H8.5 | C25687193
AO3414 | Q10,Q11,Q23,Q24,Q26 | SOT-23 | C48850
2N7002LT1G | Q12,Q13,Q14,Q15,Q18,Q21 | SOT-23 | C16338
AO3401A | Q16,Q17,Q19,Q20 | SOT-23 | C15127
AO3400A | Q22,Q101,Q102,Q103 | SOT-23 | C20917
MMBT3904LT1G | Q50,Q51 | SOT-23 | C81464
RN73C1J51K1BTDF | R10 | R_0603_1608Metric | C4226875
RT0603BRD07300RL | R11 | R_0603_1608Metric | C705763
RC0603FR-074K7L | R12,R20 | R_0603_1608Metric | C99782
RC0603FR-0710KL | R13,R18,R21,R23,R33,R38 | R_0603_1608Metric | C98220
RC0603FR-07100KL | R14,R15,R27,R28,R29,R34,R35 | R_0603_1608Metric | C14675
RC0603FR-071KL | R16,R17,R22,R24 | R_0603_1608Metric | C22548
RC0603JR-070RL | R19 | R_0603_1608Metric | C95177
RC0603FR-07390RL | R25 | R_0603_1608Metric | C114620
RC0603FR-07100RL | R26 | R_0603_1608Metric | C105588
RC0603FR-071K5L | R30 | R_0603_1608Metric | C114668
RT0603BRD07221RL | R31 | R_0603_1608Metric | C705749
RT0603BRD071KL | R32 | R_0603_1608Metric | C110776
RN73C1J698RBTDF | R39 | R_0603_1608Metric
RC0603FR-07150RL | R40 | R_0603_1608Metric | C114608
RC0805FR-0710KL | R50,R52,R53,R55,R61,R62,R63,R64,R65,R66,R67,R68,R69,R70 | R_0805_2012Metric | C84376
RC0805FR-07100KL | R51,R54 | R_0805_2012Metric | C96346
RC0805FR-0733RL | R56,R57,R58,R59,R60 | R_0805_2012Metric | C126353
RC0805FR-07210RL | R100 | R_0805_2012Metric
RC0805FR-077R5L | R101 | R_0805_2012Metric
RC0805FR-07240RL | R110,R115,R120 | R_0805_2012Metric | C185292
RC0805FR-07100KL | R111,R116,R121 | R_0805_2012Metric | C96346
RC0805FR-07100RL | R112,R117,R122 | R_0805_2012Metric | C105577
RC0805FR-0710KL | R113,R118,R123 | R_0805_2012Metric | C84376
RC0805FR-07100KL | R200,R201,R202,R203,R204,R205 | R_0805_2012Metric | C96346
RC0805FR-0710KL | R210,R211,R212,R213,R214,R215 | R_0805_2012Metric | C84376
RT0805BRD07499RL | R220,R221,R222,R223,R224,R225,R250,R251,R252,R253,R254,R255 | R_0805_2012Metric | C865521
RC0805FR-07220RL | R230,R231,R232,R233,R234,R235 | R_0805_2012Metric | C114519
RT0805BRD0733KL | R240,R241,R242,R243,R244,R245,R260,R261,R262,R263,R264,R265 | R_0805_2012Metric | C728650
3296W-1-102LF | RV100 | Potentiometer_Bourns_3296W_Vertical | C57089
LT3041ADE#TRPBF | U10 | DFN-14-1EP_3x4mm_P0.5mm_EP1.7x3.3mm | C7452883
AP2112K-3.3TRG1 | U11 | SOT-23-5 | C51118
TPS3840PL42DBVR | U12 | SOT-23-5
TPS3840PL30DBVR | U13 | SOT-23-5
TPS3840PL34DBVR | U14 | SOT-23-5 | C2871627
SN74LVC1G14DBVR | U15 | SOT-23-5 | C7835
LTV-817S-TA1-B | U16 | SMDIP-4_W7.62mm | C109226
LM4050AIM3-4.1/NOPB | U17 | SOT-23 | C2156509
TLV3601DCKR | U18 | SOT-353_SC-70-5 | C2974371
SN74LVC1G132DBVR | U19 | SOT-23-5 | C403723
ADG4613BRUZ | U30,U31,U32 | TSSOP-16_4.4x5mm_P0.65mm
OPA2325IDR | U33,U34,U35 | SOIC-8_3.9x4.9mm_P1.27mm | C2058909
SN74LVC2G125DCTR | U50,U51,U52 | TI_DCT0008A_SSOP8 | C206035
LT1963AEQ#PBF | U100 | TO-263-5_TabPin3 | C20415348
LTV-847S | U101 | SMDIP-16_W9.53mm | C114599

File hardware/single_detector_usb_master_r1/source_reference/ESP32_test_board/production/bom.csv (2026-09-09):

Designator | Footprint | Quantity | Value | LCSC Part #
C1, C2, C3, C4 | 805 | 4 | 100nF | C49678
C5, C6, C7 | 1206 | 3 | 22uF | C12891
D1 | D_SOD-123 | 1 | 1N4007 | C2892681
O1, O2, O3 | SOIC-8_3.9x4.9mm_P1.27mm | 3 | OPA2196 | C2057972
Q2, Q3, Q4 | SOT-23 | 3 | AO3400A | C20917
R1, R10, R11, R12, R13, R14, R20, R22, R24, R9 | 805 | 10 | 100K | C149504
R15 | 805 | 1 | 220 | C17557
R16, R17, R18 | 805 | 3 | 330 | C17630
R19, R21, R23 | 805 | 3 | 100 | C17408
R2 | 805 | 1 | 300k | C17616
R3, R4, R5, R6, R7, R8 | 805 | 6 | 500 | C2828857
U3 | SOT-223-3_TabPin2 | 1 | AMS1117 | C6188
U4 | SMDIP-16_W9.53mm | 1 | LTV-847S | C114599

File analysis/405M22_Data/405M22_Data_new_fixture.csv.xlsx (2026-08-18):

timestamp | batch_number | sensor_number | sensor_id | tester_name | model | filter_setup | pwm_channel | pwm_hz | pwm_duty | offset_v | sensitivity_mv | sensitivity_raw_mv | sensitivity_legacy_equivalent_mv | sensitivity_correction_factor | sensitivity_calibration_id | sensitivity_gate_outcome | sensitivity_raw_fail_below_mv | sensitivity_raw_pass_above_mv | polarity | polarity_good_bad | pass_fail | fail_reasons | failure_mode_tag | failure_mode_reason | operator_comments | waveform_snapshot_paths | battery_v | noise_rms_mv | snr_db | reference_calibrated_at | reference_calibration_mv | reference_lower_mv | reference_upper_mv | reference_check_mv | reference_drift_pct | stabilized | stability_timeout | stability_threshold_mv | stability_required_deltas | stabilization_cycle | stabilization_seconds | stability_window_max_delta_mv | last_peak_delta_mv | capture_cycles | measurement_cycles | stability_phase | measurement_attempt | measurement_failures | active_stability_required_deltas | active_measurement_cycles_required | pwm_on_seconds | data_source | noise_test_outcome | noise_windows_total | noise_windows_over | noise_over_percent | noise_worst_pp_mv | noise_median_pp_mv | noise_settle_s
2026-08-17T12:46:03 | 500 | 1 | 500-1 | Jose | 405M22 | -625 filter | GPIO25 | 1 | 50 | 1.44877 | 2.177 | 2.177 | 2.177 | 1 | 405m22_tp412_uncalibrated_v0 |  | 5.89 | 6.09 | POSITIVE | GOOD | PASS |  |  |  |  |  |  | 0.0494 | 24.59 |  |  |  |  |  |  | YES | NO | 0.5 | 5 | 6 | 6.503 | 0.3785 | 0.0915 | 16 | 10 | complete | 1 | 0 | 5 | 10 | 16.807 | esp32_405m22 | PASS | 20 | 0 | 0 | 0.184989 | 0.121501 | 20
2026-08-17T12:48:16 | 500 | 2 | 500-2 | Jose | 405M22 | -625 filter | GPIO25 | 1 | 50 | 1.03494 | 1.7955 | 1.7955 | 1.7955 | 1 | 405m22_tp412_uncalibrated_v0 |  | 5.89 | 6.09 | POSITIVE | GOOD | PASS |  |  |  |  |  |  | 0.0963 | 16.61 |  |  |  |  |  |  | YES | NO | 0.5 | 5 | 6 | 6.502 | 0.036 | 0.0995 | 16 | 10 | complete | 1 | 0 | 5 | 10 | 16.794 | esp32_405m22 | PASS | 20 | 0 | 0 | 0.159005 | 0.12034 | 20
2026-08-17T12:51:58 | 500 | 3 | 500-3 | Jose | 405M22 | -625 filter | GPIO25 | 1 | 50 | 0.81816 | 1.913 | 1.913 | 1.913 | 1 | 405m22_tp412_uncalibrated_v0 |  | 5.89 | 6.09 | POSITIVE | GOOD | PASS |  |  |  |  |  |  | 0.1923 | 11.42 |  |  |  |  |  |  | YES | NO | 0.5 | 5 | 6 | 6.502 | 0.254 | 0.003 | 16 | 10 | complete | 1 | 0 | 5 | 10 | 16.795 | esp32_405m22 | PASS | 20 | 2 | 10 | 0.938184 | 0.129836 | 20
2026-08-17T12:55:09 | 500 | 4 | 500-4 | Jose | 405M22 | -625 filter | GPIO25 | 1 | 50 | 1.26236 | 2.045 | 2.045 | 2.045 | 1 | 405m22_tp412_uncalibrated_v0 |  | 5.89 | 6.09 | POSITIVE | GOOD | PASS |  |  |  |  |  |  | 0.1786 | 13.01 |  |  |  |  |  |  | YES | NO | 0.5 | 5 | 6 | 6.503 | 0.3605 | 0.035 | 16 | 10 | complete | 1 | 0 | 5 | 10 | 16.842 | esp32_405m22 | PASS | 20 | 0 | 0 | 0.222974 | 0.130744 | 20
2026-08-17T12:58:18 | 500 | 5 | 500-5 | Jose | 405M22 | -625 filter | GPIO25 | 1 | 50 | 1.31658 | 2.0065 | 2.0065 | 2.0065 | 1 | 405m22_tp412_uncalibrated_v0 |  | 5.89 | 6.09 | POSITIVE | GOOD | PASS |  |  |  | this sensor showed "low offset" when i first tested it, showing 0.6 V but I clicked re-measure and it went throguh the second time reading 1.3 V so this is something that needs to be fixed to allow some time for offset to settle. |  |  | 0.253 | 9.75 |  |  |  |  |  |  | YES | NO | 0.5 | 5 | 6 | 6.503 | 0.3725 | 0.1625 | 16 | 10 | complete | 1 | 0 | 5 | 10 | 16.865 | esp32_405m22 | PASS | 20 | 0 | 0 | 0.133167 | 0.104252 | 3
2026-08-17T13:00:34 | 500 | 6 | 500-6 | Jose | 405M22 | -625 filter | GPIO25 | 1 | 50 | 1.31497 | 2.0635 | 2.0635 | 2.0635 | 1 | 405m22_tp412_uncalibrated_v0 |  | 5.89 | 6.09 | POSITIVE | GOOD | PASS |  |  |  |  |  |  | 0.1611 | 14 |  |  |  |  |  |  | YES | NO | 0.5 | 5 | 6 | 6.504 | 0.492 | 0.049 | 16 | 10 | complete | 1 | 0 | 5 | 10 | 16.842 | esp32_405m22 | PASS | 20 | 0 | 0 | 0.19263 | 0.12689 | 20
2026-08-17T13:02:22 | 500 | 7 | 500-7 | Jose | 405M22 | -625 filter | GPIO25 | 1 | 50 | 0.91087 | 2.065 | 2.065 | 2.065 | 1 | 405m22_tp412_uncalibrated_v0 |  | 5.89 | 6.09 | POSITIVE | GOOD | PASS |  |  |  |  |  |  | 0.047 | 24.58 |  |  |  |  |  |  | YES | NO | 0.5 | 5 | 6 | 6.503 | 0.459 | 0.053 | 16 | 10 | complete | 1 | 0 | 5 | 10 | 16.868 | esp32_405m22 | PASS | 20 | 0 | 0 | 0.15387 | 0.111467 | 3
2026-08-17T13:03:54 | 500 | 8 | 500-8 | Jose | 405M22 | -625 filter | GPIO25 | 1 | 50 | 1.16106 | 1.873 | 1.873 | 1.873 | 1 | 405m22_tp412_uncalibrated_v0 |  | 5.89 | 6.09 | POSITIVE | GOOD | PASS |  |  |  |  |  |  | 0.1116 | 16.44 |  |  |  |  |  |  | YES | NO | 0.5 | 5 | 6 | 6.504 | 0.347 | 0.0955 | 16 | 10 | complete | 1 | 0 | 5 | 10 | 16.821 | esp32_405m22 | PASS | 20 | 0 | 0 | 0.22041 | 0.128432 | 20
2026-08-17T13:08:28 | 500 | 9 | 500-9 | Jose | 405M22 | -625 filter | GPIO25 | 1 | 50 | 0.84249 | 1.781 | 1.781 | 1.781 | 1 | 405m22_tp412_uncalibrated_v0 |  | 5.89 | 6.09 | POSITIVE | GOOD | PASS |  |  |  |  |  |  | 0.0883 | 17.42 |  |  |  |  |  |  | YES | NO | 0.5 | 5 | 6 | 6.503 | 0.388 | 0.0415 | 16 | 10 | complete | 1 | 0 | 5 | 10 | 16.874 | esp32_405m22 | PASS | 20 | 0 | 0 | 0.171906 | 0.11272 | 20
2026-08-17T13:09:55 | 500 | 10 | 500-10 | Jose | 405M22 | -625 filter | GPIO25 | 1 | 50 | 1.75562 | 0.938 | 0.938 | 0.938 | 1 | 405m22_tp412_uncalibrated_v0 |  | 5.89 | 6.09 | POSITIVE | GOOD | PASS |  |  |  | this part should fail for low sensitivity after the scale factor is found and applied. |  |  | 0.0981 | 8.92 |  |  |  |  |  |  | YES | NO | 0.5 | 5 | 6 | 6.503 | 0.073 | 0.017 | 16 | 10 | complete | 1 | 0 | 5 | 10 | 16.843 | esp32_405m22 | PASS | 20 | 0 | 0 | 0.254676 | 0.156474 | 19
2026-08-17T13:11:01 | 500 | 11 | 500-11 | Jose | 405M22 | -625 filter | GPIO25 | 1 | 50 | 1.62082 | 2.0825 | 2.0825 | 2.0825 | 1 | 405m22_tp412_uncalibrated_v0 |  | 5.89 | 6.09 | POSITIVE | GOOD | PASS |  |  |  |  |  |  | 0.2265 | 11.05 |  |  |  |  |  |  | YES | NO | 0.5 | 5 | 6 | 6.503 | 0.4925 | 0.1525 | 16 | 10 | complete | 1 | 0 | 5 | 10 | 16.861 | esp32_405m22 | PASS | 20 | 0 | 0 | 0.175513 | 0.127059 | 20
2026-08-17T13:13:01 | 500 | 12 | 500-12 | Jose | 405M22 | -625 filter | GPIO25 | 1 | 50 | 1.14787 | 2.4005 | 2.4005 | 2.4005 | 1 | 405m22_tp412_uncalibrated_v0 |  | 5.89 | 6.09 | POSITIVE | GOOD | PASS |  |  |  |  |  |  | 0.0798 | 21.03 |  |  |  |  |  |  | YES | NO | 0.5 | 5 | 6 | 6.503 | 0.482 | 0.0795 | 16 | 10 | complete | 1 | 0 | 5 | 10 | 16.853 | esp32_405m22 | PASS | 20 | 0 | 0 | 0.142312 | 0.113926 | 3
2026-08-17T13:14:44 | 500 | 13 | 500-13 | Jose | 405M22 | -625 filter | GPIO25 | 1 | 50 | 1.39745 | 2.32 | 2.32 | 2.32 | 1 | 405m22_tp412_uncalibrated_v0 |  | 5.89 | 6.09 | POSITIVE | GOOD | PASS |  |  |  |  |  |  | 0.0545 | 24.37 |  |  |  |  |  |  | YES | NO | 0.5 | 5 | 7 | 7.503 | 0.0845 | 0.078 | 17 | 10 | complete | 1 | 0 | 5 | 10 | 17.856 | esp32_405m22 | PASS | 20 | 0 | 0 | 0.141573 | 0.116131 | 20
2026-08-17T13:16:35 | 500 | 14 | 500-14 | Jose | 405M22 | -625 filter | GPIO25 | 1 | 50 | 0.99818 | 2.089 | 2.089 | 2.089 | 1 | 405m22_tp412_uncalibrated_v0 |  | 5.89 | 6.09 | POSITIVE | GOOD | PASS |  |  |  |  |  |  | 0.2173 | 11.51 |  |  |  |  |  |  | YES | NO | 0.5 | 5 | 7 | 7.503 | 0.173 | 0.058 | 17 | 10 | complete | 1 | 0 | 5 | 10 | 17.87 | esp32_405m22 | PASS | 20 | 0 | 0 | 0.151071 | 0.117542 | 20
2026-08-17T13:18:08 | 500 | 15 | 500-15 | Jose | 405M22 | -625 filter | GPIO25 | 1 | 50 | 1.41625 | 1.5165 | 1.5165 | 1.5165 | 1 | 405m22_tp412_uncalibrated_v0 |  | 5.89 | 6.09 | POSITIVE | GOOD | PASS |  |  |  |  |  |  | 0.1776 | 9.15 |  |  |  |  |  |  | YES | NO | 0.5 | 5 | 6 | 6.503 | 0.1905 | 0.0345 | 16 | 10 | complete | 1 | 0 | 5 | 10 | 16.898 | esp32_405m22 | PASS | 20 | 0 | 0 | 0.191995 | 0.14475 | 18
2026-08-17T13:20:00 | 500 | 16 | 500-16 | Jose | 405M22 | -625 filter | GPIO25 | 1 | 50 | 1.07028 | 1.965 | 1.965 | 1.965 | 1 | 405m22_tp412_uncalibrated_v0 |  | 5.89 | 6.09 | POSITIVE | GOOD | PASS |  |  |  |  |  |  | 0.3071 | 7.71 |  |  |  |  |  |  | YES | NO | 0.5 | 5 | 7 | 7.503 | 0.167 | 0.142 | 17 | 10 | complete | 1 | 0 | 5 | 10 | 17.854 | esp32_405m22 | PASS | 20 | 0 | 0 | 0.38198 | 0.112407 | 20
2026-08-17T13:21:26 | 500 | 17 | 500-17 | Jose | 405M22 | -625 filter | GPIO25 | 1 | 50 | 1.60117 | 2.4725 | 2.4725 | 2.4725 | 1 | 405m22_tp412_uncalibrated_v0 |  | 5.89 | 6.09 | POSITIVE | GOOD | PASS |  |  |  |  |  |  | 0.3216 | 8.95 |  |  |  |  |  |  | YES | NO | 0.5 | 5 | 6 | 6.503 | 0.4665 | 0.01 | 16 | 10 | complete | 1 | 0 | 5 | 10 | 16.845 | esp32_405m22 | PASS | 20 | 0 | 0 | 0.237873 | 0.142086 | 20
2026-08-17T13:22:53 | 500 | 18 | 500-18 | Jose | 405M22 | -625 filter | GPIO25 | 1 | 50 | 1.70394 | 2.0155 | 2.0155 | 2.0155 | 1 | 405m22_tp412_uncalibrated_v0 |  | 5.89 | 6.09 | POSITIVE | GOOD | PASS |  |  |  |  |  |  | 0.099 | 17.63 |  |  |  |  |  |  | YES | NO | 0.5 | 5 | 6 | 6.503 | 0.3085 | 0.0725 | 16 | 10 | complete | 1 | 0 | 5 | 10 | 16.828 | esp32_405m22 | PASS | 20 | 0 | 0 | 0.254343 | 0.127979 | 20
2026-08-17T13:25:29 | 500 | 19 | 500-19 | Jose | 405M22 | -625 filter | GPIO25 | 1 | 50 | 0.91919 | 2.0855 | 2.0855 | 2.0855 | 1 | 405m22_tp412_uncalibrated_v0 |  | 5.89 | 6.09 | POSITIVE | GOOD | FAIL | Signal-to-noise too low: SNR 1.01, 0.1 dB (minimum 1.5). This looks like sensor noise with no emitter response - check the emitter drive. | N | Noisy |  |  |  | 0.7881 | 0.09 |  |  |  |  |  |  | YES | NO | 0.5 | 5 | 7 | 7.503 | 0.4445 | 0.2515 | 17 | 10 | complete | 1 | 0 | 5 | 10 | 17.85 | esp32_405m22 | PASS | 20 | 0 | 0 | 0.157351 | 0.1116 | 20
2026-08-17T13:27:40 | 500 | 20 | 500-20 | Jose | 405M22 | -625 filter | GPIO25 | 1 | 50 | 1.44219 | 2.1195 | 2.1195 | 2.1195 | 1 | 405m22_tp412_uncalibrated_v0 |  | 5.89 | 6.09 | POSITIVE | GOOD | PASS |  |  |  |  |  |  | 0.1108 | 16.97 |  |  |  |  |  |  | YES | NO | 0.5 | 5 | 7 | 7.504 | 0.209 | 0.059 | 17 | 10 | complete | 1 | 0 | 5 | 10 | 17.875 | esp32_405m22 | PASS | 20 | 0 | 0 | 0.173873 | 0.114611 | 20
2026-08-17T13:28:59 | 500 | 21 | 500-21 | Jose | 405M22 | -625 filter | GPIO25 | 1 | 50 | 1.52384 | 1.762 | 1.762 | 1.762 | 1 | 405m22_tp412_uncalibrated_v0 |  | 5.89 | 6.09 | POSITIVE | GOOD | PASS |  |  |  |  |  |  | 0.2339 | 9.3 |  |  |  |  |  |  | YES | NO | 0.5 | 5 | 6 | 6.503 | 0.437 | 0.0995 | 16 | 10 | complete | 1 | 0 | 5 | 10 | 16.884 | esp32_405m22 | PASS | 20 | 0 | 0 | 0.217078 | 0.129831 | 20
2026-08-17T13:30:35 | 500 | 22 | 500-22 | Jose | 405M22 | -625 filter | GPIO25 | 1 | 50 | 1.03672 | 2.1235 | 2.1235 | 2.1235 | 1 | 405m22_tp412_uncalibrated_v0 |  | 5.89 | 6.09 | POSITIVE | GOOD | PASS |  |  |  |  |  |  | 0.1214 | 16.65 |  |  |  |  |  |  | YES | NO | 0.5 | 5 | 6 | 6.503 | 0.432 | 0.008 | 16 | 10 | complete | 1 | 0 | 5 | 10 | 16.87 | esp32_405m22 | PASS | 20 | 0 | 0 | 0.189544 | 0.129332 | 20
2026-08-17T13:32:24 | 500 | 23 | 500-23 | Jose | 405M22 | -625 filter | GPIO25 | 1 | 50 | 1.59464 | 2.052 | 2.052 | 2.052 | 1 | 405m22_tp412_uncalibrated_v0 |  | 5.89 | 6.09 | POSITIVE | GOOD | PASS |  |  |  |  |  |  | 0.2027 | 11.73 |  |  |  |  |  |  | YES | NO | 0.5 | 5 | 6 | 6.504 | 0.474 | 0.114 | 16 | 10 | complete | 1 | 0 | 5 | 10 | 16.856 | esp32_405m22 | PASS | 20 | 0 | 0 | 0.170001 | 0.122219 | 3
2026-08-17T13:34:01 | 500 | 24 | 500-24 | Jose | 405M22 | -625 filter | GPIO25 | 1 | 50 | 1.62035 | 1.995 | 1.995 | 1.995 | 1 | 405m22_tp412_uncalibrated_v0 |  | 5.89 | 6.09 | POSITIVE | GOOD | PASS |  |  |  |  |  |  | 0.3018 | 8.13 |  |  |  |  |  |  | YES | NO | 0.5 | 5 | 7 | 7.504 | 0.2305 | 0.1495 | 17 | 10 | complete | 1 | 0 | 5 | 10 | 17.845 | esp32_405m22 | PASS | 20 | 0 | 0 | 0.205514 | 0.133084 | 17
2026-08-17T13:35:25 | 500 | 25 | 500-25 | Jose | 405M22 | -625 filter | GPIO25 | 1 | 50 | 1.48399 | 2.143 | 2.143 | 2.143 | 1 | 405m22_tp412_uncalibrated_v0 |  | 5.89 | 6.09 | POSITIVE | GOOD | PASS |  |  |  |  |  |  | 0.1662 | 13.78 |  |  |  |  |  |  | YES | NO | 0.5 | 5 | 7 | 7.503 | 0.1505 | 0.0415 | 17 | 10 | complete | 1 | 0 | 5 | 10 | 17.809 | esp32_405m22 | PASS | 20 | 0 | 0 | 0.184121 | 0.123209 | 20
2026-08-17T13:37:10 | 500 | 26 | 500-26 | Jose | 405M22 | -625 filter | GPIO25 | 1 | 50 | 0.83862 | 2.0125 | 2.0125 | 2.0125 | 1 | 405m22_tp412_uncalibrated_v0 |  | 5.89 | 6.09 | POSITIVE | GOOD | PASS |  |  |  |  |  |  | 0.1024 | 17.21 |  |  |  |  |  |  | YES | NO | 0.5 | 5 | 6 | 6.503 | 0.253 | 0.124 | 16 | 10 | complete | 1 | 0 | 5 | 10 | 16.82 | esp32_405m22 | PASS | 20 | 0 | 0 | 0.324191 | 0.135949 | 20
2026-08-17T13:38:42 | 500 | 27 | 500-27 | Jose | 405M22 | -625 filter | GPIO25 | 1 | 50 | 3.23957 |  |  |  | 1 | 405m22_tp412_uncalibrated_v0 |  | 5.89 | 6.09 |  |  | FAIL | Offset out of range: 3.240 V, expected 0.8 to 3.0 V. | HO | High offset | should fail for noise as well but since I detected a high offset, noise was skipped |  |  |  |  |  |  |  |  |  |  |  |  |  |  |  |  |  |  |  |  |  |  |  |  |  |  |  | SKIPPED
2026-08-17T13:40:31 | 500 | 28 | 500-28 | Jose | 405M22 | -625 filter | GPIO25 | 1 | 50 | 1.05774 | 1.9285 | 1.9285 | 1.9285 | 1 | 405m22_tp412_uncalibrated_v0 |  | 5.89 | 6.09 | POSITIVE | GOOD | PASS |  |  |  |  |  |  | 0.149 | 13.49 |  |  |  |  |  |  | YES | NO | 0.5 | 5 | 6 | 6.503 | 0.236 | 0.0465 | 16 | 10 | complete | 1 | 0 | 5 | 10 | 16.828 | esp32_405m22 | PASS | 20 | 0 | 0 | 0.159405 | 0.113658 | 20
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

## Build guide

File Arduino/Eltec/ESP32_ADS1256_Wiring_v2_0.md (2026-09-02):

# Eltec ESP32 + ADS1256 wiring (firmware v2.0 — 405 M22 / TP412 fixture)

This is the wiring reference for the **unified bench rig** — every model in
`single_detector_rig` — on firmware v2.0 and later (v3.2 today: ADS1256 sensor
channels boot at PGA gain 1 with the input buffer OFF, so the TP412 0.8-3.0 V
offset band reads linearly; the 406 MCA mode switches the front end at runtime
with `FE,V19`). A legacy standalone rig still running the retired 406MCA
v6/v6.1 applications stays on firmware v1.9 and
`ESP32_ADS1256_Wiring_legacy_v1_9.md`. The historical `ESP32_ADS1256_Wiring.docx`
(9 V/AIN1/bare-MOSFET arrangement) must not be used; it was removed from the
repository on 2026-08-28 and is preserved at git tag `archive/pre-cleanup-2026-08-28`.

## Power (batteries isolated 2026-08-12 — this fixed the emitter spike)

| Battery | Powers | Monitored? |
|---|---|---|
| 6.5 V battery | Emitters ONLY (through the MOSFET module DC+/DC-) | No |
| 9 V battery | Sensors: DUT buffer + AIN1 reference buffer supplies | No (TODO: AIN6) |

The two supplies share only ground. Neither battery is measurable on the
legacy AIN7 divider: a 9 V pack through the ~2:1 divider would sit near
4.5 V on the pin, and with the v2.0 unbuffered front end the resistive
divider is loaded anyway. The host applications therefore run with the
battery gate disabled ("Battery: not monitored").

**TODO (hardware):** measure the sensor battery on **AIN6** through a >=4:1
divider (e.g. 300k/100k -> 9.6 V taps at 2.4 V), then update the firmware
(new mux entry + ratio) and re-enable the host battery gate. The plan is to
step the sensor supply down to ~8 V (or use an 8 V battery) so noise
readings stay comparable to TP412's +8 V bench supply.

## ESP32 to ADS1256

| ESP32 DevKit pin | GPIO | ADS1256 module | Purpose |
|---|---:|---|---|
| VIN | — | 5V | ADS1256 module power |
| GND | — | GND | Common ground |
| D18 | 18 | SCLK | SPI clock |
| D23 | 23 | DIN | SPI MOSI |
| D19 | 19 | DOUT | SPI MISO |
| D5 | 5 | CS | Chip select |
| D4 | 4 | DRDY | ADC data-ready interrupt |
| 3V3 | — | PDWN | Tie high; module has no separate RESET pin |

The production board is a 30-pin DOIT ESP32 DevKit V1 with a CP2102 USB bridge.
Firmware target: `esp32:esp32:esp32doit-devkit-v1`.

## Rig signals

| Source | Destination | Firmware use (v2.0) |
|---|---|---|
| Buffered DUT 405 M22 output | ADS1256 AIN0, ground beside AIN0 | Offset, driven waveform, and emitter-off noise; PGA x1 (±5 V), buffer off |
| Fixed reference sensor | ADS1256 AIN1, ground beside AIN1 | `REF?` and `STREAM,START,REF`, PGA x1 |
| (legacy) 99.7k/99.6k divider tap | ADS1256 AIN7 | `BAT?` still answers but is inaccurate and unused on this fixture |
| ESP32 D33 | Dual-MOSFET module PWM/TRIG | 1 Hz, 50% emitter drive (`PWM,FREQ,1` sent by the 405 M22 app) |
| 6.5 V battery | MOSFET module DC+/DC- | Emitter power (emitters only) |
| Emitter | MOSFET module OUT+/OUT- | Chopped IR source |

GPIO33 connects directly to the installed dual-MOSFET trigger module because
that module has its own input conditioning. The gate moved D25 -> D33 on
2026-08-25 (firmware v3.1 boots on GPIO33); a board still wired to D25 works
if the host sends `PIN,25` after connect.

All grounds must be common: ESP32, ADS1256, sensor buffers (9 V side), and
MOSFET module (6.5 V side).

## Digital PWM sync

Do not wire the old AIN2 loopback. The ESP32 includes its commanded PWM state
as the final `0` or `1` field in every streamed ADC record. With the emitter
off (the TP412 noise capture) this field is a constant `0` by design.

## Safety

- Never drive an ADS1256 analog input above AVDD (+5 V) or below ground.
  With the input buffer OFF there is no AVDD-2 V linearity ceiling anymore,
  but the absolute AVDD limit still stands.
- The unbuffered inputs present a switched-capacitor load. AIN0/AIN1 are
  driven by low-impedance op-amp buffers, which is fine; high-impedance
  sources (like the legacy AIN7 resistive divider) read low — do not trust
  `BAT?` on this fixture.
- Disconnect power before changing fixture wiring.

## Bring-up on Xubuntu

1. Flash `Eltec.ino` **v2.0** with board **DOIT ESP32 DEVKIT V1**.
2. Close Arduino Serial Monitor; only one process can own the port.
3. Confirm the board and the DUT offset:

   ```bash
   cd Arduino/Eltec
   python3 esp32_rig_readout.py ports
   python3 esp32_rig_readout.py offset
   python3 live_waveform.py --freq 1        # SPACE toggles the emitter
   ```

4. Start the app from **Eltec 405 M22 ESP32 Tester** on the desktop and run
   **Calibrate reference unit** (mandatory after flashing v2.0 — older
   baselines are rejected by schema version).

The expected Linux port is `/dev/ttyUSB0`; auto-discovery validates the
board's `ELTEC-ESP32-ADS1256,v2.0` identity before using it. The signed-in
user must be in the `dialout` group.

## Current open items

- Sensor-battery monitoring on AIN6 (divider + firmware channel + host
  thresholds) — see the Power section.
- The TP412 sensitivity ranges gate only after the ~50-sensor comparison
  batch yields the fixture calibration factor; the 300 mV noise limit is
  provisional for the same reason.

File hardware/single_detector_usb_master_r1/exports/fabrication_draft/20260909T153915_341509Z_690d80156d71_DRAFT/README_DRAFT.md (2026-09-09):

# Draft fabrication data - do not order

Generated from the fully routed, saved-fill, native DRC/parity-validated PCB. The manifest identifies the exact source and assembly hashes. Four copper layers, both solder masks, both legends, both paste layers and Edge.Cuts are included. An unused legend/paste layer may contain no artwork. Native Excellon plated and non-plated holes, routed slots, PDF drill maps and drill report are included.

Gerber, drill and assembly share native origin (12,115) mm: positive X right and positive Y up, without mirroring. Three round-hole witnesses and outline vertices were checked against plotted coordinates; full CAM review remains necessary.

This is not a manufacturing release. No fabricator stackup, copper weight, dielectric, finished thickness, impedance, finish, drill process capability, assembly allocation/rotation, physical fit or electrical/thermal qualification is asserted. Any KiCad Gerber job stackup fields are design metadata, not a confirmed fabrication specification. No upload or order occurred.

fabrication_manifest_DRAFT.json hashes all payload files except itself. SHA256SUMS_DRAFT.json separately hashes that manifest and the ZIP; neither checksum document claims to contain its own recursive digest.

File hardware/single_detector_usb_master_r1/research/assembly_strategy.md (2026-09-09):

# Assembly strategy and sourcing evidence

Date checked: 2026-09-09. Status: preliminary engineering research, not a quote, approved BOM, or fabrication release. Only public read-only sources were consulted; nothing was uploaded, purchased, reserved, or sent to a manufacturer.

## Population boundary

The user's required assembly boundary is all board components populated except the ESP32 development module, the ADS1256 module, and the two barrel jacks. Treat **module sockets as populated components separate from the omitted modules**. The native source audit established that the detector/emitter interfaces are copper wire solder lands, not purchased connectors. Preserve these lands and the existing harness; no fictitious connector belongs in the assembly BOM. Do not silently widen the customer soldering list to every through-hole part.

Recommended project representation:

| Item | Board representation | Assembly treatment |
| --- | --- | --- |
| ESP32 development board | Separate documentation/physical envelope plus two electrically named female socket strips | Socket strips populated; ESP32 module customer supplied and inserted |
| ADS1256 breakout | Separate documentation/physical envelope plus individually identified socket headers matching its actual pins | Sockets populated; module customer supplied and inserted |
| Two barrel jacks | Electrical symbols and exact footprints once their mechanical drawing is confirmed | Excluded from assembly BOM/CPL; listed in customer installation BOM |
| Detector/reference and emitter connections | Original three/two-wire copper solder lands with native pin coordinates | Copper features; excluded from purchased BOM/CPL |
| Sequencer, protection, regulators, passives, trim control, indicators | Ordinary electrical symbols and exact sourced footprints | Populated |

An existing combined module footprint does not by itself procure or locate separate socket strips correctly. The editable design and exported BOM/CPL must identify each physically assembled connector. Likewise, a symbol's generic `Barrel_Jack` value is insufficient to select a drill pattern.

## Viable service and layout strategy

JLCPCB currently lists mixed SMT and through-hole assembly under **both Economic and Standard PCBA**. Economic permits placement on one side; Standard permits both sides. Thus THT sockets do not by themselves require Standard. A top-side component layout with through-hole female sockets and all semiconductors/passives in SMD is a viable starting point. The current Economic capability table lists 2/4/6 layers, 0.8-1.6 mm thickness, minimum 0402 packages and 0.4 mm IC lead pitch. These are service limits rather than recommended routing dimensions. [JLCPCB PCBA capabilities](https://jlcpcb.com/capabilities/pcb-assembly-capabilities)

Parts explicitly marked **Wave Soldering** in JLCPCB's library are covered by its through-hole/manual assembly flow. Check this per actual manufacturer part number. Some connector pages additionally require an assembly support fixture. That is a quoting/manufacturing consideration, not a reason to mark the connector unpopulated. [JLCPCB assembly FAQ](https://jlcpcb.com/help/article/pcb-assembly-faqs)

Use 0603 or 0805 passives as electrical/space needs warrant; avoiding 0402 here improves visual inspection and later rework. Prefer SOIC/TSSOP/SOT packages for newly selected analog and sequencing parts where the required electrical behavior exists. This is a design recommendation, not a restriction on using a necessary leadless component. Do not downgrade shutdown protection, precision, voltage rating, dissipation, or capacitor effective value to reduce feeder fees.

Keep the socket bodies and future module envelopes clear of the rework access area around the sequencer and input protection. Place assembly references, pin-1 markers, battery polarity, and module insertion orientation where installed modules will not hide every marking. Treat ESP32 antenna clearance, USB plug access, and the ADS1256 module underside component height as mechanical dependencies.

## Catalog classes and procurement interpretation

JLCPCB distinguishes Basic, Preferred Extended, and Extended parts. Its FAQ says Preferred Extended parts are exempt from Economic feeder loading charges. The current price policy charges feeder setup for Extended parts on Economic, and for both Basic and Extended parts on Standard. Part classes change; record the checked date and confirm them when obtaining the eventual quote. Do not embed a fixed assembly price in the release package. [JLCPCB assembly FAQ](https://jlcpcb.com/help/article/pcb-assembly-faqs), [JLCPCB assembly price policy](https://jlcpcb.com/help/article/pcb-assembly-price)

An LCSC catalog entry establishes a concrete component identity and potential supply route, **not** a confirmed JLCPCB assembly match or available allocation. Final sourcing needs the actual MPN, package, JLC part number, approved supply source, stock for the chosen build quantity plus attrition, and assembly type. JLC requires sourced/consigned parts to be received and selected before assembly. No supply source or quantity has been reserved for this project. [JLCPCB component matching guidelines](https://jlcpcb.com/help/article/component-matching-guidelines-for-pcba-orders)

## Existing-circuit candidate evidence

These entries help preserve the original circuitry while selecting assembled packages. They are not electrical approval of the old design or automatic substitution authority. The original schematic PNG identifies OPA2196 buffers, AO3400A emitter FETs, an LTV-847 optocoupler and an adjustable AMS1117 regulator.

| Circuit function | Concrete candidate | What is verified | What remains |
| --- | --- | --- | --- |
| Existing emitter low-side FET | Alpha & Omega AO3400A, **C20917**, SOT-23 | JLC part page lists **Basic**, SMT Assembly, Economic and Standard. Manufacturer datasheet available. | Confirm the chosen gate drive, current, dissipation and pin mapping in the new circuit. It is not a direct positive-lead switch with a USB-only gate drive. |
| Existing four-channel optocoupler | Lite-On **LTV-847**, **C10794**, DIP-16 | JLC page lists **Extended**, Wave Soldering, Economic and Standard. This is a real Lite-On component entry. | Electrical design must check CTR at actual LED current and required off-state behavior; confirm exact DIP lead span/footprint. |
| Existing dual precision buffers | TI **OPA2196IDR**, **C2057972**, SOIC-8 | LCSC identifies this MPN/package. TI lists it active, SOIC D package, 8 pins, 4.5-36 V operating supply. | JLC assembly availability/class was not verified. Keep this sourcing item open; do not substitute a similarly named op amp without analog review. |
| Existing emitter regulator | Exact manufacturer and suffix of AMS1117 adjustable part unresolved | The PNG is not sufficient to distinguish compatible manufacturer/package/capacitor requirements. | Select a datasheet-backed part and check dropout, minimum load, capacitor stability, reverse bias and thermal dissipation under the new two-6.5 V-battery conditions. |

Evidence links: [AO3400A JLC entry](https://jlcpcb.com/partdetail/Alpha_OmegaSemicon-AO3400A/C20917), [AO3400A manufacturer datasheet](https://www.aosmd.com/res/data_sheets/AO3400A.pdf), [LTV-847 JLC entry](https://jlcpcb.com/partdetail/LiteOn-LTV847/C10794), [Lite-On datasheet hosted by LCSC](https://datasheet.lcsc.com/lcsc/1810161110_Lite-On-LTV-847_C10794.pdf), [OPA2196IDR LCSC entry](https://www.lcsc.com/product-detail/operational-amplifier_texas-instruments-opa2196idr_C2057972.html), [TI OPA2196IDR package and status](https://www.ti.com/product/OPA2196/part-details/OPA2196IDR).

**Sourcing trap:** the search result `LTV-847S / C9900002565 / Manufacturer: JLCPCB Assembly` is an assembly-service entry. It does not identify a sourced Lite-On chip. Do not use it as a purchased semiconductor MPN. [JLC assembly-service listing](https://jlcpcb.com/partdetail/JIALICHUANGSMT-LTV847S/C9900002565)

New power-path and sequencing components require their own sourcing check after the electrical architecture is chosen. Large TO-220 IRLB8748 devices are not required by the user's new-board request; their earlier mention concerned an interim perfboard retrofit.

## Socket candidates and mechanical limits

The repository wiring note identifies a 30-pin DOIT ESP32 DevKit V1, but that does not prove its row spacing or USB connector placement. The selected socket for each 15-position row is **Kinghelm KH-2.54FH-1X15P-H8.5, C2932676**. Its manufacturer drawing specifies 2.54 mm pitch, 8.5 mm insulator height, a recommended 1.02 mm PCB hole, 35.56 mm first-to-last pin distance and 38.10 mm overall row length. JLC's exact part page confirms Extended, Wave Soldering, and Economic/Standard assembly. This closes the catalog/process identity for J3/J4, not their physical fit or allocation. [Kinghelm drawing](https://www.kinghelm.net/upload/file/20221115/KH-2.54FH-1X15P-H8.5.pdf), [JLC assembly entry](https://jlcpcb.com/partdetail/3278197-KH_2_54FH_1X15P_H85/C2932676)

J5 uses **Kinghelm KH-2.54FH-1X8P-H8.5, C2905417**. Its exact JLC page likewise confirms Extended, Wave Soldering, and Economic/Standard. A search snapshot included an assembly-fixture notice that was absent from the subsequently opened live page; fixture requirements and cost remain quote-dependent. J6 uses **FG-PM2.54-2-08P-H8.5, C25687193**, a 2×8, 2.54 mm, 8.5 mm-high female header with an LCSC-hosted manufacturer drawing. A JLC assembly match for J6 was not verified. All four sockets remain populated in the assembly boundary. [J5 JLC entry](https://jlcpcb.com/partdetail/3175191-KH_2_54FH_1X8P_H85/C2905417), [J6 LCSC entry](https://www.lcsc.com/product-detail/C25687193.html), [FG manufacturer drawing hosted by LCSC](https://lcsc.com/datasheet/lcsc_datasheet_2407051524_FG-FG-PM2-54-2-08P-H8-5_C25687193.pdf)

Another manufacturer-identified 1x15 option is **Ckmtw B-2200S15P-A120, C124408**. The LCSC entry identifies 2.54 mm pitch and a through-hole 15-position single row. It is a candidate, not a footprint-equivalent replacement until the drawing is checked. [Ckmtw/LCSC entry](https://www.lcsc.com/product-detail/C124408.html)

A concrete example proving the assembly route is **XYECONN PM2.54-1-16P-Z, C53244566**: its JLC entry explicitly lists Wave Soldering, Economic and Standard, and an assembly fixture. It has 16 positions and is **not** a substitute for a 15-pin module row. Its public page showed zero stock and a preorder requirement when checked, so it should not be treated as immediately available. [JLC connector entry](https://jlcpcb.com/partdetail/XYECONN-PM2_54_1_16PZ/C53244566)

The native source and module evidence, rather than the schematic symbol pin ordering alone, govern the ADS1256 socket geometry. The selected socket identities above do not replace the integration team's mechanical checks against the original footprints and actual module.

Detector/reference and emitter copper-land positions and numbering are preserved from the native board audit. They are not purchased screw terminals. Any future connector addition would require a separate drawing and harness compatibility check.

## Export contract

Generate a complete engineering BOM and a separately filtered **JLC assembly BOM**. The assembly BOM should use at least `Comment,Designator,Footprint,LCSC Part #`, plus manufacturer/MPN fields in the engineering BOM. Use exactly one unambiguous part/value/package per line and list all fitted reference designators for that part. Keep the module and barrel-jack omissions in a customer-install list, with their exact footprints and orientation in the assembly drawing. [JLC BOM requirements](https://jlcpcb.com/help/article/bill-of-materials-for-pcb-assembly), [JLC KiCad BOM/CPL guidance](https://jlcpcb.com/help/article/how-to-generate-bom-and-centroid-files-from-kicad-8)

The CPL must include each populated SMT **and THT** component, with `Designator,Mid X,Mid Y,Layer,Rotation`, millimeter coordinates, and counterclockwise-positive degrees. A footprint origin at connector pin 1 is not necessarily its body centroid. Exporter logic must use the intended placement point rather than blindly assuming every origin is already a centroid. Record any part-specific rotation/offset correction and compare it against a top-side assembly view. [JLC pick-and-place requirements](https://jlcpcb.com/help/article/pick-place-file-for-pcb-assembly)

Automated checks should prove that the BOM designator set equals the CPL set, both equal the populated footprint set, no reference appears twice, all coordinates are finite millimeter values within the design envelope, and every omitted item is justified by the user-requested assembly boundary. JLC recognizes assembly parts only when designators are present consistently in both files. Do not let an unmatched socket silently disappear. [JLC BOM/CPL preparation recommendations](https://jlcpcb.com/help/article/advice-for-bom-and-cpl-files-preparation)

Draft fabrication deliverables should include the exact-revision Gerbers, plated/non-plated drill data, board drawing, assembly views with polarity/pin-1 marking, BOM/CPL and omitted-part list, plus reproducible source-to-export checks. Include top/bottom solder mask and paste layers as applicable. A future online placement preview/quote is additional manufacturing evidence; no such online review occurred during this research.

## Material open items for the project decision log

1. Confirm the exact removable ESP32 and ADS1256 module geometry and mating pin lengths from supplied files; keep the initial mechanical model preliminary where uncertain.
2. Confirm the two user-installed barrel-jack MPNs and physical pin polarity. They are omitted from assembly but must still fit the fabricated board.
3. Preserve detector/emitter wire-land polarity and verify existing harness/case-ground connections. No additional connector is selected by this revision.
4. Complete JLC assembly matching for OPA2325IDR and all selected sequencing/protection parts. LCSC identity alone does not close this item.
5. Confirm economic versus standard eligibility after all parts, sides, board geometry and assembly fixture requirements are known. Do not infer the service from through-hole presence alone.
6. Recheck part class and availability against the eventual build quantity before any separately authorized order. Current research provides no reservation or delivery guarantee.

No electrical timing, fit, solderability of an unselected connector, PCB DRC/ERC result, or production qualification is claimed by this note.

## Updated analog sourcing

The revised held-rail driver is OPA2325IDR, not the original OPA2196. LCSC's product metadata identifies [OPA2325IDR/C2058909](https://www.lcsc.com/product-detail/C2058909.html), SOIC-8. This is a procurement identity, not an allocated assembly order. The similarly retrieved C2877688 belongs to a single OPA325 and must not be used for these dual packages.

The precision 33 kΩ resistors are [Yageo RT0805BRD0733KL/C728650](https://www.lcsc.com/product-detail/Chip-Resistor-Surface-Mount_YAGEO-RT0805BRD0733KL_C728650.html), 0805, 0.1%, 25 ppm/°C. The exact 499 Ω counterpart is [RT0805BRD07499RL/C865521](https://www.lcsc.com/product-detail/Pre-ordered-RLCs_YAGEO_C865521.html), also 0805, 0.1%, 25 ppm/°C. These are verified identities; displayed stock varied between product and related-item snapshots, so no available quantity is asserted.

**ADG4613 remains the material sourcing gap.** Analog Devices lists ADG4613BRUZ and ADG4613BRUZ-REEL7 in the same 16-lead TSSOP RU-16 package. No exact LCSC/JLC part number was verified after bounded searches and direct public-page checks. A cached JLC DG412LEDQ page mentions ADG4613BRUZ-REEL7 as a related item but does not expose its ID; the page's **C3008913 belongs to Vishay DG412LEDQ-T1-GE3**, not ADG4613. Similarly, C207399 and C657391 belong to ADG4612, whose control truth table differs. Leave the selected ADG4613 assembly ID blank until a manufacturer- and package-matched JLC sourcing or consignment path is confirmed. Do not call the current BOM fully sourceable. [ADI product models](https://www.analog.com/en/products/adg4613.html), [ADI ordering table](https://www.analog.com/media/en/technical-documentation/data-sheets/adg4612_4613.pdf), [JLC page with the misleading related-item search result](https://jlcpcb.com/partdetail/VishayIntertech-DG412LEDQ_T1GE3/C3008913)

## Verified catalog data and remaining gaps

`verified_catalog.json` is the machine-readable exact-MPN mapping for the exporter. Each record includes the manufacturer, a verified public source, UTC check time, and assembly status. Catalog identity and JLC assembly allocation are separate. No part in this work has been reserved or approved for a build quantity. The exporter must compare manufacturer as well as MPN and package: several suppliers reuse an identical MPN string.

| Item | Verified identity or remaining issue |
| --- | --- |
| Held regulator | LT3041ADE#TRPBF = C7452883; LCSC identity verified, JLC allocation unconfirmed. |
| Reference/comparator | LM4050AIM3-4.1/NOPB = C2156509; TLV3601DCKR = C2974371. The selected AIM reference has an 85°C upper operating envelope. |
| Reference qualifier | TPS3840PL34DBVR = C2871627. Other selected TPS3840 thresholds need their own exact order codes; a different threshold is not a supply substitution. |
| Low-voltage NMOS | Alpha & Omega AO3414 = **C48850**, verified from current LCSC Product metadata. C557941 is a **VBsemi** device and does not prove the AOS 1.8 V on-resistance/capacitance specifications used in the design. JLC allocation remains unconfirmed. |
| ADC 3.3 V LDO | Diodes AP2112K-3.3TRG1 = C51118. C23380830 is **TECH PUBLIC**, a different manufacturer's device with the same MPN text. |
| Remaining power procurement | Current verified identities are in the machine-readable catalog; remaining exact identity and availability items are listed in the final sourcing section below. An empty ID must not be filled by a similar value alone. |
| Remaining assembly approval | J6, ADG4613, and all LCSC-only parts still need a confirmed JLC supply/process match. Every populated part must survive the assembly BOM/CPL filtering. |

The specific links for verified IDs are in `verified_catalog.json`; the electrical/package evidence remains in the emitter and independent power review files. The master manifest was changing during this sourcing pass, so a hard-coded count of missing passive MPNs would be stale. The final exporter should report unresolved identities directly from the regenerated populated-part list.

## Exact USB switch and battery assumptions

The user's [Amazon ASIN B0FCS47Y8Q](https://www.amazon.com/RIITOP-Type-C-Extension-Support-Charging/dp/B0FCS47Y8Q) identifies manufacturer/model **RIITOP USBCFOF-1FT**. The RIITOP product page's structured variant SKU is the same. RIITOP explicitly advertises USB data, including USB 2.0 backward compatibility, plus video and PD support. It describes the switch's marked side as connecting and its unmarked side as disconnecting the USB device. This supports using a data-capable cable for the serial connection; it is not inferred from a charging-only title. [RIITOP manufacturer description](https://www.riitop.com/products/riitop-usb-type-c-extension-cable-with-on-off-switch-1ft-usb-3-1-type-c-male-to-female-extension-cable-with-on-off-switch-support-vid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)

Neither source supplied a contact schematic or stated exactly whether VBUS, CC, D+/D−, SuperSpeed pairs, or ground are switched. Consequently, **VBUS-only switching and all-conductor switching are both unverified**. Commissioning must verify that the actual cable removes the ESP32's 5 V power and that the serial port reappears reliably with both USB plug orientations used by the rig. RIITOP's page says 20 V/3 A while the Amazon listing advertises up to 20 V/5 A; this discrepancy does not establish the contact behavior. No 100 W claim is needed for this rig.

For the user's HeyFuture label **6.4 V, 6 Ah, 38.4 Wh LiFePO4**, an exact manufacturer model/datasheet was not found. The official HeyFuture product catalog examined during this pass listed seven products, with 12 V batteries and a 24 V 6 Ah battery, but no matching 6.4 V 6 Ah pack. Thus full-charge voltage, charger tolerance, BMS undervoltage cutoff, short-circuit current and cutoff timing remain **unverified for this actual pack**. A third-party mention of a 6 V 6 Ah pack supplied with a 7.4 V charger was not accepted as exact-model evidence. [HeyFuture manufacturer catalog](https://heyfuturepower.com/collections/all)

The 6.4 V label is nominal voltage, not a maximum. Any provisional 7.3 V upper-bound calculation in the circuit notes remains an assumption until the actual pack and charger are identified or measured under the relevant conditions. The detector supply remains the user's battery rail as requested; source uncertainty must not silently change its calibration supply.

## Final bounded SPI and power-passive catalog pass

The selected SPI buffer and enable transistor identities are TI SN74LVC2G125DCTR/C206035 and onsemi MMBT3904LT1G/C81464. Their package maps remain DCT-8 and SOT-23 respectively; a generic quad buffer or another manufacturer's transistor is not selected by this sourcing lookup. All ordinary SPI 10 kΩ, 100 kΩ and 33 Ω resistors now have exact Yageo RC0805FR catalog matches. Integration approved changing only ordinary analog C30–C35 and SPI C50–C52 bypass capacitors to Samsung CL21B104KBCNNNC/C1711, 0805 100 nF/50 V/X7R/10%. Timing, SET and LDO stability capacitors are outside that substitution.

New exact capacitor matches: GRM32ER71E226KE15L/C21397 (1210 22 µF/25 V/X7R/10%); CL21B475KAFNNNE/C98195 (0805 4.7 µF/25 V/X7R/10%); GRM31C5C1H104JA01K/C398933 (1206 100 nF/50 V/C0G/5%); GRM1885C1H103JA01D/C85973 (0603 10 nF/50 V/C0G/5%); CL10B104KB8NNNC/C1591 (0603 100 nF/50 V/X7R/10%). The K suffix of the selected 1206 C0G part is significant for catalog matching; do not attach the older L-suffix C97946 to the K MPN.

F1/F2 catalog identities are Littelfuse 0468001.NRHF/C45157 and 046801.5NRHF/C151143. Their 50 A interrupt rating still has to be reconciled with the actual battery pack's prospective short current; verifying their IDs does not prove that pack-level protection condition. The selected emitter-master optocoupler is now the exact packaged Lite-On LTV-817S-TA1-B/C109226.

The obsolete Diodes BZT52C6V8-7-F is no longer the selected D12. The power owner changed it to Diotec BZT52C6V8GW after manufacturer review. No verified LCSC/JLC identity for that Diotec order code was found in this bounded pass. Do not use the earlier Diodes catalog ID with the Diotec MPN.

Most remaining ordinary power resistors now have verified exact Yageo RC0603FR/JR IDs in the JSON file. Remaining unresolved special identities include ADG4613BRUZ, Diotec BZT52C6V8GW, TPS3840PL42DBVR/PL30DBVR, the two TE 10 ppm SET resistors, Nichicon PCJ0J821MCL4GS, precision 221 Ω, and the emitter 210 Ω/7.5 Ω orders. Recompute the final exact list from the regenerated manifest rather than this dated narrative. These parts are not declared unavailable; this research did not establish their exact JLC/LCSC assembly path.

## Final exact-gap closure and prepared global sourcing

Checked 2026-09-09T14:55:23Z. Three additional exact manufacturer/MPN records are now in `verified_catalog.json`: [TE RN73C1J51K1BTDF/C4226875](https://www.lcsc.com/product-detail/C4226875.html), [Yageo RT0603BRD07221RL/C705749](https://www.lcsc.com/product-detail/C705749.html), and [Nichicon PCJ0J821MCL4GS/C2161767](https://www.lcsc.com/product-detail/C2161767.html). Each was validated against the public page's Product metadata, including MPN, manufacturer and SKU. This brings the independent catalog to 53 exact records. C12's public metadata showed out of stock when checked; its resolved identity is not an availability assurance.

The 195-fitted-component export supplied for this pass had 12 unresolved references. These three matches leave **nine references / seven unique MPNs** without verified JLC/LCSC IDs: D12 BZT52C6V8GW; R39 RN73C1J698RBTDF; R100 RC0805FR-07210RL; R101 RC0805FR-077R5L; U12 TPS3840PL42DBVR; U13 TPS3840PL30DBVR; U30/U31/U32 ADG4613BRUZ. This is a research calculation against the supplied export; regenerate the exporter report to update its stored count.

`global_sourcing_prepared.json` and the matching CSV give each exact MPN, designators, per-board quantity, verified manufacturer/distributor order identity, source links and unresolved fields. They include the seven identity gaps plus C12 as an availability fallback. Build quantity, attrition, purchase quantity, JLC library ID and allocation remain blank/null. No row was submitted, purchased, reserved or approved by JLC.

For ADG4613, the ADI ordering guide places **ADG4613BRUZ** and **ADG4613BRUZ-REEL7** in the same RU-16 TSSOP and temperature grade, so the reel suffix changes procurement packaging without changing the intended electrical/package model. The prepared row favors REEL7 for assembly. Verified distributor identities are **505-ADG4613BRUZ-REEL7TR-ND** (tape/reel) and **ADG4613BRUZ-ND** (tube). The LFCSP BCPZ order has a different footprint; ADG4612 has a different truth table. Neither is an approved substitution. [ADI ordering guide, page 22](https://www.analog.com/media/en/technical-documentation/data-sheets/adg4612_4613.pdf), [DigiKey reel order identity](https://www.digikey.com/en/products/detail/analog-devices-inc/ADG4613BRUZ-REEL7/2506915), [DigiKey tube order identity](https://www.digikey.com/en/products/detail/analog-devices-inc/ADG4613BRUZ/2507326)

JLC's documented Global Sourcing route starts with an exact manufacturer-part-number search, supplier selection and an assembly review; accepted parts become available to assembly only after warehouse receipt. Per-board quantities here are not purchase quantities because build size and process attrition remain unresolved. The service documentation establishes a possible route, not acceptance of these specific parts. No supplier option, lead time or quotation for this board has been confirmed. [JLC Global Sourcing process](https://jlcpcb.com/help/article/how-to-use-jlcpcb-global-sourcing-parts-service)

Two rows have only manufacturer order identity, so their procurement uncertainty is larger: Diotec lists BZT52C6V8GW active with zero stock and minimum order 3,000; TE lists RN73C1J698RBTDF active as internal **9-1676970-4**, but the public product page says it is not currently available. No manufacturer inquiry was sent. These remain unresolved sourcing work, not a completed assembly path. [Diotec exact product](https://diotec.com/en/product/BZT52C6V8GW.html), [TE exact product](https://www.te.com/en/product-9-1676970-4.html)

The exact R101 Yageo RC0805FR-077R5L DigiKey page also showed out of stock at the final check. Its listed order identity remains useful for a sourcing search, but does not establish immediate supply. [DigiKey exact R101](https://www.digikey.com/en/products/detail/yageo/RC0805FR-077R5L/728115)

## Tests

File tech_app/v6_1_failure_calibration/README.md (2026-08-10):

# Eltec 406MCA Failure Calibration — v6.1 Base

This is an isolated engineering build for comparing the v6.1 tester's verdicts
with technician-confirmed ground truth. It keeps the normal ESP32/ADS1256
hardware sequence and v6.1 measurement policy, then collects structured
feedback on the verdict page.

> **Experiment only — not for production acceptance.** Use
> `tech_app/v6_1_esp32/` for ordinary v6.1 evaluation work and
> `tech_app/v6_esp32/` for the current production workflow. This build collects
> evidence; it does not automatically change thresholds or production code.

## What this build is for

Use the known-failed sensor set, including any sensor that may actually pass,
to answer two separate questions:

1. Did the application produce the correct PASS/FAIL verdict?
2. If it failed the sensor, did it give the correct failure reason?

The application prediction and the technician annotation must remain separate.
Do not change a ground-truth answer merely to agree with the application. Mark
an uncertain sensor as uncertain and explain why; uncertainty is more useful
than a forced label.

The full study folder is the deliverable. Keep the batch CSV, autosave data,
waveform images, and sample/cycle diagnostic CSV files together so a later code
change can be checked against the original signals instead of only the final
labels.

## Technician workflow

1. Give every physical sensor a permanent, unique specimen ID such as `S01`
   through `S20`. Reuse that ID for every repeat measurement.
2. Start a study/batch, enter the technician name, and choose the normal filter
   setup.
3. If required, calibrate the fixed reference unit with a known-good/new
   emitter. Do not use one of the unknown DUTs as the reference standard.
4. Load and measure the DUT exactly as in v6.1. The reference check, offset
   read, adaptive DUT capture, and PASS/FAIL calculation are unchanged.
5. On the verdict page, record the technician's ground-truth verdict. Confirm
   whether the application verdict and reason were correct; when they were not,
   select the expected reason and explain the disagreement.
6. Save the record before moving to the next sensor. For another independent
   acquisition, use **Save + Repeat Same Specimen**; the app requires every run
   to be reviewed first so a later measurement cannot hide an earlier verdict.

Hardware versus simulator mode is frozen when the batch starts. If the app is
closed before a reviewed result reaches the batch CSV, starting that same batch
again offers to recover the immutable run evidence and the autosaved review
fields; declining recovery leaves them untouched and prevents overwrite.

A PASS ground truth is valid even when the sensor arrived in the suspected-fail
set. A sensor can also be marked uncertain when its independent diagnosis is
not strong enough to call.

## Recommended 20-sensor study

- Run each specimen at least twice, preferably three times, reseating it
  between runs.
- Add independently confirmed known-good DUT controls and repeat them across
  the session. A mostly-failed 20-sensor set is useful for correcting failure
  reasons, but by itself cannot estimate the false-reject rate on good parts.
- Randomize the order rather than testing all repeats back-to-back.
- Keep the filter/setup fixed unless the study intentionally evaluates more
  than one setup; document every intentional change.
- Record the expected electrical symptom separately from a physical history
  such as “dropped.” The tester can learn from waveform, offset, sensitivity,
  polarity, noise, and stability evidence; it cannot directly observe a
  handling history.
- Record ambiguity and mixed symptoms in the explanation instead of forcing a
  single overconfident cause.
- Reserve several specimens as a holdout set. Do not use their labels while
  tuning rules; use them afterward to check that an apparent improvement
  generalizes beyond the sensors used for tuning.
- Do not mix simulator rows with hardware evidence. Simulator mode is for UI
  training and automated checks only.

After collection, preserve or archive the entire
`v6_1_failure_calibration` results directory. The raw diagnostic sidecars are
needed to replay proposed threshold and classification changes.

## Study handoff checks

`calibration_dataset.py` is a standalone, read-only standard-library utility.
Summarize the hardware batch rows (the `simulator/` directory and synthetic
rows are excluded automatically):

```bash
python3 tech_app/v6_1_failure_calibration/calibration_dataset.py summarize
python3 tech_app/v6_1_failure_calibration/calibration_dataset.py summarize /path/to/v6_1_failure_calibration
```

It prints JSON counts for saved rows, unique physical specimens, app-versus-
ground-truth verdicts, review classifications, and app-mode-to-truth-mode
comparisons.

Before copying the study, verify the complete finalized record chain:

```bash
python3 tech_app/v6_1_failure_calibration/calibration_dataset.py verify
python3 tech_app/v6_1_failure_calibration/calibration_dataset.py verify /path/to/v6_1_failure_calibration
```

For each hardware run, `verify` requires exactly one matching batch row and a
sibling `review.json`. It verifies the manifest and review hashes recorded in
the CSV, cross-checks the run/specimen/app-prediction/ground-truth fields across
all three records, checks exported measurement/reference/stability/policy
values against the manifest, and recomputes every evidence artifact's size and SHA-256.
Simulator folders and synthetic rows are excluded. Missing, mismatched, or
unreadable entries are printed as JSON and produce a nonzero exit.

Bring back the **entire**
`~/Documents/Eltec_406MCA_Test_Results/v6_1_failure_calibration/` folder—not
only the summary JSON or batch CSV. Keep its `evidence/` run directories,
`run_manifest.json`, `review.json`, waveform images, and sample/cycle CSVs in
place. Current manifests and CSV rows contain portable relative paths, so the
copied folder can be verified at its new location; legacy absolute-only
artifact entries are safely rebased to their manifest's run directory.

## V6.1 measurement policy retained by this build

The DUT is captured in one uninterrupted AIN0/PWM-sync stream. Every attempt
requires 10 consecutive robust-peak deltas at or below `0.100 mV`, followed by
20 measurement cycles that must remain at or below the same threshold.

At startup this build verifies the expected hashes of the shared verdict
engine, stability analysis, and tracked settings. If any rule source changes,
measurement is blocked until a new calibration app/ruleset version is created,
preventing two decision policies from being mixed in one study.

| Attempt | Qualification | Official measurement | Over-threshold measurement delta |
| --- | ---: | ---: | --- |
| 1 | 10 consecutive deltas | 20 cycles | Discard and start attempt 2 |
| 2 | 10 consecutive deltas | 20 cycles | Discard and start attempt 3 |
| 3 | 10 consecutive deltas | 20 cycles | Report unstable |

The 20-second deadline governs qualification and requalification. A complete
measurement window that starts after timely qualification may finish after the
deadline. Sensitivity, polarity, noise, and SNR use only the successful
attempt's 20-cycle window.

## Reference gate

The AIN1 reference-unit gate remains mandatory:

1. Check the 6 V battery and force PWM off.
2. Turn PWM on and immediately stream AIN1.
3. Require five consecutive robust-peak deltas at or below `0.250 mV`.
4. Average the next five complete cycles.
5. Require the result to remain inside the fixed `+/-25%` reference window
   before accessing AIN0.

Calibration files created with the former `+/-10%` policy are automatically
loaded with the current `+/-25%` window; a new reference calibration is not
required solely for this policy change. The calibration-study application is
versioned as `.4`, so use a new batch ID if an existing batch contains `.1`,
`.2`, or `.3` rows. This keeps acquisition and failure-selection policies
distinguishable during later analysis.

The default primary failure mode follows measurement order: out-of-range
offset (`HO`, `D`, or `LO`) takes priority, followed by instability, then
waveform failures. Waveform capture still continues after an official offset
failure so secondary sensitivity, polarity, SNR, and stability evidence is
retained. With an in-range offset, low sensitivity plus failed SNR/no coherent
response is classified as `GO/D`; a coherent under-amplitude response remains
`LS`.

This build's writable calibration location is isolated with its other results:

```text
~/Documents/Eltec_406MCA_Test_Results/v6_1_failure_calibration/reference_sensor_calibration.json
```

If a compatible v6.1/v6 calibration is offered as a read-only fallback, its
source must remain unchanged. Calibration and invalidation performed by this
build write only to the failure-calibration location.

## Data and launcher isolation

```text
Results:      ~/Documents/Eltec_406MCA_Test_Results/v6_1_failure_calibration/
Launcher log: ~/.local/state/eltec-406mca-failure-cal-v6-1/launcher.log
Menu entry:   ~/.local/share/applications/com.eltec.406mca-failure-cal-v6-1.desktop
Desktop icon: ~/Desktop/Eltec 406MCA Failure Calibration — v6.1 Base.desktop
```

Do not move study CSVs into the v6 or v6.1 results directories. Their schemas
and purposes differ, and mixing them would make agreement analysis unreliable.

## Run

From the repository root:

```bash
./tech_app/v6_1_failure_calibration/run_eltec_406mca_esp32_tester.sh
```

Or from this directory:

```bash
./run_eltec_406mca_esp32_tester.sh
```

Install the optional per-user Xubuntu desktop/menu launcher:

```bash
./tech_app/v6_1_failure_calibration/install_xubuntu_launcher.sh
```

Remove only this experimental launcher:

```bash
./tech_app/v6_1_failure_calibration/install_xubuntu_launcher.sh --uninstall
```

## Hardware and dependencies

Use `Arduino/Eltec/Eltec.ino` v1.7 or newer and the current fixture wiring in
`Arduino/Eltec/ESP32_ADS1256_Wiring_v1_7.md`:

- GPIO25: fixed 10 Hz / 50 percent emitter PWM;
- ADS1256 AIN0: buffered DUT sensor;
- ADS1256 AIN1: permanently mounted reference sensor;
- ADS1256 AIN7: 6 V SLA battery divider.

Required packages are Python 3, Tkinter, NumPy, and pyserial. Matplotlib is
optional for higher-quality waveform snapshots.

```bash
sudo apt install python3 python3-tk python3-numpy python3-serial
sudo apt install python3-matplotlib libnotify-bin desktop-file-utils xdg-user-dirs
```

The signed-in user must be able to access `/dev/ttyUSB*` or `/dev/ttyACM*`,
normally through the `dialout` group. Close Arduino Serial Monitor,
`live_waveform.py`, production testers, and other serial applications before
starting this build.

`stability_calibration.py` is a separate engineering utility for collecting
known-good peak-delta evidence. It does not collect verdict ground truth, issue
production verdicts, or edit `stability_settings.json`.

## Verification

Run the isolated suite from the repository root:

```bash
python3 -m unittest discover -s tech_app/v6_1_failure_calibration/tests -v
```

Before field use, also rerun the unchanged v6.1 and v6 suites to confirm that
the experimental fork did not alter either existing application.

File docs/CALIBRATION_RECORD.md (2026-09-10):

# Calibration record — every production constant and where it came from

This file is the **single authoritative home** for every number that decides a
PASS or FAIL on the Eltec test rig: the value, the line of code that holds it,
how it was derived, and the state of each gate per sensor model. The model
READMEs explain the *mechanics*; this file records the *evidence*.

**Rule for changing any constant here:** update the code, update this file,
and add a dated entry to [`CHANGELOG.md`](../CHANGELOG.md) — in the **same
commit**. For sensitivity factors also bump the model's
`SENSITIVITY_CALIBRATION_ID` so every CSV row says which calibration produced
it.

Last reconciled against the code: **2026-09-02**.

---

## 1. Gate status at a glance

| Gate | 405 M22 | 406 MCA | 449 M18 |
| --- | --- | --- | --- |
| Offset band | **ON** 0.80–3.00 V | **ON** 0.3–1.2 V | OFF (placeholder 0.3–3.0 V, TP443 page not available) |
| Emitter-off noise | **ON** ≈429 µV pk-pk, 15 % window rule | not part of the 406 test | not part of the TP443 test |
| Sensitivity | **ON** factor 4.30 (lot 500) | **ON** factor 1.582 (lot 520) | **OFF — CALIBRATION PENDING** (K_5, K_18 not derived) |
| Near-limit band | ±0.10 mV raw → PASS + warning | ±0.10 mV raw → PASS + warning | n/a until the gate is on |
| Polarity | POSITIVE required | POSITIVE required | POSITIVE required at both frequencies (assumed — verify on the bench) |
| SNR | ≥ 1.5 | ≥ 1.5 | ≥ 1.5 at both frequencies |
| Stability (peak delta) | 0.500 mV, 5 deltas, 10 cycles, 3 attempts, 60 s | 0.100 mV, 10 deltas, 20 cycles, 3 attempts, 20 s | 0.100 mV, 5 deltas, 20 cycles @5 Hz / 4 blocks of 9 @18 Hz, 3 attempts, 30 s |
| Reference unit (AIN1 emitter health) | **ON** again since 2026-09-09 | **ON** again since 2026-09-09 | **ON** again since 2026-09-09 |
| Battery | **OFF** (no battery on AIN7 since 2026-08-12) | OFF in the unified copy | OFF |
| Emitter drive | 1 Hz / 50 % (reference phases 10 Hz) | 10 Hz / 50 % | 5 Hz then 18 Hz, **20 %** duty (reference 10 Hz / 50 %) |
| ADS1256 front end | boot default: gain 1, buffer OFF (±5 V) | app sends `FE,V19`: gain 2, buffer ON (±2.5 V) | boot default (±5 V) |
| Minimum firmware | v2.0 | v1.7 (legacy standalone rigs stay on **v1.9**) | **v3.2** |

Code locations: `single_detector_rig/<model>/eltec_<model>_esp32_tester.py`
(gates, limits, factors), `<model>/esp32_backend.py` (drive frequency, duty,
gate pin, minimum firmware), `<model>/stability_settings.json` (peak-delta
threshold). The three model directories are deliberate near-copies — see the
copy-per-model policy in [`ENGINEER_HANDOVER.md`](ENGINEER_HANDOVER.md).

**Array rig (50 positions, ACCES USB-AIO16-64MA DAQ) — model 40623, TP120** — see §4b:

| Gate | 40623 array |
| --- | --- |
| Offset band | **ON, PROVISIONAL** 0.3–1.2 V (TP120); < 0.05 V on a loaded socket = D; ≥ 4.9 V = HO (railed). Operator screening requires every loaded offset in band before noise; the final verdict also checks the settled reading. |
| Noise | **PENDING** — pin-level limits `None` (measured and recorded only; TP120's 10.0–37.9 mV are DMM readings behind amplifier 9000232 + rectifier-hold 9000272). Structural rules when limits exist: 15 % window rule (high), median rule (low). |
| Sensitivity / polarity | **not implemented** (no emitter board) |
| Front end | unity-gain buffer per position → DAQ 0–5 V single-ended, 1000 scans/s per channel, oversample 3 with the first conversion dropped |

Code: `array_rig/m40623/array_analysis.py` (limits, verdict model),
`array_rig/m40623/eltec_40623_array_tester.py` (DAQ and timing constants).

---

## 2. Model 405 M22 (TP412, 1 Hz)

Tester: `single_detector_rig/m405m22/eltec_405m22_esp32_tester.py`.
Test procedure document: **TP412** (offset, sensitivity/polarity at 1 Hz, noise).
Detailed mechanics: [`m405m22/README.md`](../single_detector_rig/m405m22/README.md).

### 2.1 Constants

| Constant | Value | Where | Provenance |
| --- | --- | --- | --- |
| `OFFSET_MIN_V` / `OFFSET_MAX_V` | 0.80 / 3.00 V | tester ≈ l.124 | TP412 offset band. Needs firmware ≥ v2.0 (unbuffered gain-1 front end reads linearly to ~5 V). |
| `SENSOR_OFFSET_MIN_PLAUSIBLE_V` | 0.05 V | tester ≈ l.315 | Near-0 V float = empty slot / dead buffer. Polled for `OFFSET_WAKE_TIMEOUT_S` = 5 s before deciding (2026-08-17: lot-500 part 500-44 was wrongly rejected as an empty slot before the poll existed). The old 3.5 V high-side "no sensor" rail was removed 2026-08-13: a railed ~5 V AIN0 **is** the high-offset failure signature. |
| Offset policy | high-side fail-fast; low side judged on a **settled re-read** after the sensitivity capture | tester | 2026-08-17, lot 500: offsets rise for tens of seconds after insertion — 35 of 48 parts read 0.15–1.1 V *below* their settled legacy value on the insertion read. CSV keeps both: `offset_initial_v` and `offset_v`. Settled offsets match the old fixture to +0.018 ± 0.032 V (2026-08-18 re-run). |
| `NOISE_LEGACY_PP_LIMIT_MV` | 300 mV | tester ≈ l.387 | TP412's scope limit, read **behind the legacy bench amplifier**. |
| `NOISE_LEGACY_AMPLIFIER_GAIN` | 4000 (nominal, **not** used for the verdict) | tester ≈ l.386 | Sticker gain of the TL084-based legacy amplifier. |
| `NOISE_EFFECTIVE_CHAIN_FACTOR` | **700** | tester ≈ l.390 | See §2.2. |
| `NOISE_PP_LIMIT_MV` | 300 / 700 ≈ **0.429 mV (429 µV) pk-pk at the sensor pin** | tester ≈ l.391 | Derived. Displayed as red cutoff lines at ±214 µV. |
| `NOISE_DECIMATION_FACTOR` | 20 (1000 → 50 SPS, passband flat to ~22 Hz) | tester ≈ l.392 | Chosen 2026-08-13 (fixture floor 5.6 % of limit at 20:1; ≥10:1 suffices; raw is unusable at 36 %). Since **2026-08-20** the decimator is a Kaiser windowed-sinc anti-alias FIR (`stability_analysis.decimate_antialiased`, ≥ 60 dB stopband from 28 Hz) — the original boxcar's −13 dB sidelobes folded 60 Hz mains to 10 Hz at only −16 dB (41 % phantom energy on the interference-heavy `test-22` capture). Same passband and timeline; all nine archived raw captures replay to identical verdicts. **2026-08-31:** precision — the Kaiser's passband edge is 22.15 Hz but its −3 dB corner is **24.4 Hz** (22.17 Hz was the boxcar's; with the detrend the verdict's −3 dB band is 0.852–24.4 Hz), and the FIR now seats on **real edge context** (0.31 s per side: quiet-wait tail + extra streamed samples, archived in the capture NPZ) instead of reflection padding, which had let out-of-band interference into the first/last judged window at only ~11–21 dB. No-context replays (all pre-existing captures) are bit-identical. |
| Judged band | ≈ **0.85–22 Hz** | analysis | Per-window detrend = high-pass −3 dB at 0.85 Hz; decimation = low-pass at 22.17 Hz (`engineer_tools/noise_band/filter_response_analysis.py`, 2026-08-20). |
| `NOISE_WINDOW_S` | 1 s windows | tester ≈ l.385 | |
| `NOISE_MAX_OVER_FRACTION` | **0.15 → PASS iff ≤ 3 of 20 windows exceed the limit** | tester ≈ l.410 | Tightened from 20 % on **2026-08-17** (lot 500): the one part the legacy fixture failed for noise (500-44, 496 mV on the old scope) measured 4/20 windows over and was slipping through at 20 %; every other part was 0/20 except 500-3's isolated 2-window environmental spike, which must stay tolerated. 4 over fails, 2 passes. **Single-part anchor — refine with more known-noisy parts.** |
| `NOISE_CAPTURE_SECONDS` | 20 s | tester ≈ l.411 | Fixed for now; adaptive length is future work. |
| `NOISE_SOAK_CAPTURE_SECONDS` / `NOISE_SOAK_MAX_OVER_FRACTION` | 60 s / allowed count held at the **same absolute 3 (3 of 60)** | tester ≈ l.425 | **2026-08-18**: 500-44's burst noise is intermittent (4/20 over on 08-17, 0/20 on 08-18) while clean parts take environmental transients (500-1 hit 3/20). No threshold separates them; observation time does. Operator-selectable per part on the load step. |
| Quiet wait | adaptive: `NOISE_WAIT_BEFORE_CAPTURE_S` 3 s min, `NOISE_WAIT_MAX_S` 20 s, start when 2 consecutive 1 s mean deltas ≤ limit/4 (≈107 µV/s) | tester ≈ l.441 | 2026-08-13. Can only delay the capture, never fail the part (`noise_baseline_settled` column records a deadline start). |
| Per-window detrend | each 1 s window judged against its own least-squares baseline (mean + slope) | `stability_analysis.detrend_window_segments` | 2026-08-13 — residual DC settling cannot inflate the pk-pk (mirrors the legacy AC-coupled amplifier). |
| `NOISE_CLIP_LIMIT_V` | 98 % of the ±5 V input range | tester ≈ l.445 | A window whose RAW samples touch the clip counts as over-limit; the FIR's ~0.3 s ring-through from a railed window can also push its neighbour over (emergent, not a coded rule). |
| Raw-capture auto-save | whenever any window goes over, PASS or FAIL | tester | 2026-08-18. Files under `noise_captures/lot_<lot>/`; see [`DATA_MAP.md`](DATA_MAP.md). |
| `SENSITIVITY_LEGACY_EQUIVALENT_FACTOR` | **4.30** | tester ≈ l.452 | See §2.3. |
| `SENSITIVITY_CALIBRATION_ID` | `405m22_tp412_lot500_pairwise_v1` | tester ≈ l.459 | Stamped on every CSV row. |
| TP412 filter limits (legacy-scope mV) | -625: 5.99–11.98 · -628: 4.22–8.44 · -629: 4.92–9.84 | tester ≈ l.141–147 | TP412; blackened tube + extra -25B optics, 10 cm from the 500 K blackbody. Raw limit = legacy limit / 4.30. Over-max also fails. |
| `SENSITIVITY_RAW_NEAR_LIMIT_HALF_WIDTH_MV` | ±0.10 mV raw (≈ ±0.43 mV legacy) | tester ≈ l.458 | Within the factor's margin of error → the part **PASSES** with a re-measure suggestion (`PASS · NEAR LIMIT`, `sensitivity_gate_outcome` = NEAR LIMIT in the CSV). Was a `RETEST / QUARANTINE` verdict until **2026-08-25**. For -625 the band is 1.29–1.49 mV raw around the 1.393 mV centre; no lot-500 part fell inside it. |
| `MIN_SIGNAL_TO_NOISE_RATIO` | 1.5 (≈3.5 dB) | tester | Inherited from the 406 build; guards against an undriven emitter. Not yet tuned on real data. |
| Polarity | POSITIVE | tester | Every Eltec model tested so far peaks while the emitter is on. |
| `peak_delta_threshold_mv` | **0.500 mV** | `m405m22/stability_settings.json` | Relaxed from 0.100 mV on **2026-08-12**: the inherited 406 limit kept these high-gain parts timing out as Unstable. Provisional — review percentiles with `stability_calibration.py`. |
| `DUT_STABILITY_CONFIRMATION_DELTAS` / `SENSITIVITY_MEASUREMENT_CYCLES` / attempts / `STABILITY_TIMEOUT_S` | 5 / 10 / 3 / 60 s | tester ≈ l.466 | 1 s cycles: qualification + 10 cycles needs ≥ ~16 s, so 60 s instead of the 406's 20 s. |
| `REFERENCE_PEAK_DELTA_THRESHOLD_MV` / `REFERENCE_TOLERANCE_PERCENT` | 0.250 mV / ±25 % | tester ≈ l.498 | Reference unit's own gate; deliberately independent of the DUT threshold. Live again since 2026-09-09. |
| `REFERENCE_CALIBRATION_SCHEMA_VERSION` | **5** since 2026-09-09 | tester ≈ l.558 | Bumped with the gate re-enable so pre-isolation baselines are refused. See §5. |
| `PWM_FREQUENCY_HZ` / `REFERENCE_PWM_FREQUENCY_HZ` / duty | 1 Hz / 10 Hz / 50 % | `esp32_backend.py` l.66–68 | TP412 specifies responsivity at 1 Hz. The AIN1 reference unit is a **406MCA sensor**, so reference phases drive its qualified 10 Hz (told by the user 2026-08-12). Only 1 and 10 Hz are accepted. |
| `PWM_GPIO` | 33 | `esp32_backend.py` | Emitter gate moved D25 → D33 on 2026-08-25 (firmware v3.1). The app sends `PIN,33` after every connect. |
| `MINIMUM_FIRMWARE_VERSION` | (2, 0, 0) | `esp32_backend.py` l.74 | Needs the gain-1 unbuffered front end. |
| `STREAM_MAX_MICRO_GAPS` / `STREAM_MAX_MISSING_SAMPLES` / `REFERENCE_READING_STREAM_RETRIES` | 3 / 20 samples / 2 | tester ≈ l.504 | Bounded USB micro-gap tolerance (2026-08-12); gaps are refilled from firmware timestamps (2026-08-13). Anything else (duplicates, overruns, > 2 % rate error) rejects the capture. |
| `BATTERY_MONITORING_ENABLED` | False | tester ≈ l.282 | No battery on AIN7 since the 2026-08-12 rewiring (6.5 V → emitters only, 9 V → sensors). Re-enable when the sensor battery is measurable on AIN6 (≥ 4:1 divider). |
| `REFERENCE_GATE_ENABLED` | **True** since 2026-09-09 | tester ≈ l.309 | See §2.4. |

### 2.2 Why the noise limit is 300 mV ÷ 700, not ÷ 4000

TP412's 300 mV pk-pk is read on a scope behind the legacy bench amplifier
whose paperwork says ×4000 — that would put the pin-level limit at 75 µV, the
figure the app used for a few hours on 2026-08-13. A **same-part
cross-measurement** the same evening disproved it: the resident good part
showed ~150–200 mV on the legacy station (GW Instek GDS-1054B, CH2 at
100 mV/div, ±150 mV cursors, roll mode 5 s/div at 20 Sa/s — itself a ~20 SPS
low-frequency view, closely matching this rig's decimation) while this rig
measured ~240–270 µV at the pin over the same 50 s / 20 SPS view. A true
×4000 chain would have painted ~1 V (ten divisions); it demonstrably did not.
The **effective** end-to-end factor is therefore ~620–830×; **700** was
adopted. Two further scope photos (50 and 100 mV/div, spans ~150–250 mV) are
consistent with 600–800.

The 2026-08-20 passband analysis (`engineer_tools/noise_band/filter_response_analysis.py`)
showed no physically sensible 1 Hz-centred band-pass can turn 4000 into 700
(best achievable ratio 0.235 vs the required 0.175, order-1 models), so the
gap was attributed to a **real gain difference** (10:1 probe setting, an
amplifier range switch, or a wrong nameplate) — not a bandwidth effect.
Partially superseded by the 2026-08-31 addendum below: the response has now
been measured, "wrong nameplate" and "10:1 probe" are effectively cleared,
and the gain-scale conclusion itself stands.

**2026-08-31 addendum — the amplifier's frequency response was measured
directly** (11-point sine sweep, ~1 mV injected; output amplitudes 0.1 Hz →
340 mV, 0.2 → 1.16 V, 0.5 → 3.06 V, 1 → 4.14 V, 2 → 4.10 V, 5 → 2.56 V,
10 → 1.14 V, 20 → 336 mV, 50 → 63 mV, 100 → 17 mV, 200 → 5 mV):

- The amp is a **band-pass peaking ×4140 at ~1.4 Hz** (−3 dB 0.46–4.1 Hz,
  ≈2 real poles per side — two cascaded AC-coupled stages; gain ≥ 4000 only
  over 0.86–2.2 Hz; |H| = 700 only at 0.15 and 13.2 Hz). The **nameplate
  ×4000 is its real midband gain** (+0.5 dB) *if* the ~1 mV injection level
  was accurate; a 10:1 probe is disfavoured on arithmetic (it over-explains).
- **Bandwidth still cannot produce 700**: weighting the archived pin spectra
  by the measured response gives effective factors 3400–6000 (clean lot-500
  parts ≈ 4200), not 620–830 — the 08-20 conclusion survives its order-1
  modelling limitation.
- The measured **shape** validates against the archive: scaled by a flat
  ≈3.2× it reproduces all 14 archived capture verdicts, 500-44's 496 mV
  legacy reading (predicts 492 mV) and the 150–200 mV good-part reading.
  The residual is a **frequency-flat ~3–6× in-service scale**; prime
  suspect: **source-impedance loading** (the high-impedance pyro element
  into the amp's input network — the sweep drove it from a stiff
  generator), which would make nameplate, sweep and 700 simultaneously
  consistent.
- **Open action (updated):** record where the sweep was injected (amp input
  terminals vs the fixture's sensor socket) and how the 1 mV was verified
  (measured at the node vs generator dial; amplitude vs pk-pk). Then repeat
  1 Hz and 0.2 Hz through a ~10–50 pF series capacitor or ~1 GΩ series
  resistor emulating the pyro source (expect ≈14 dB drop at 1 Hz under the
  loading hypothesis). Most informative extra sweep points: 0.03, 15,
  500 Hz. The 08-13 cross-measurement's probe ratio and amp range-switch
  position are unrecorded — capture them next time the legacy station is up.
- **Decision (2026-08-31): the rig is not required to replicate the amp's
  spectral response.** The acceptance criterion is verdict-level agreement
  with the legacy fixture (parts that pass there pass here, parts that fail
  for noise there fail here), which the flat-band ÷ 700 architecture meets
  on the lot-500 comparison and the archived captures. The scalar 700 and
  the judged band stay; the per-tone divergence (more lenient than the amp
  below ~13 Hz, stricter above, sub-0.85 Hz discounted) is accepted and
  documented here.

Bench facts behind the choice of band (2026-08-13, raw data in
`noise_experiments/`, see [`DATA_MAP.md`](DATA_MAP.md)): fixture floor with
the part removed = **4.2 µV** median window pk-pk at 20:1 (≈1 % of the limit —
the electronics are not the problem); a desk fan near the rig adds ~19 Hz and
~200 Hz microphonic peaks plus mV transients through the part (pyroelectric
elements are piezoelectric — **no fans near the fixture during noise tests**);
covering the sensor lowered the reading only ~13 %, so the 0.5–5 Hz noise is
intrinsic to the part or its bias chain.

### 2.3 Sensitivity factor 4.30 — the lot-500 pairwise calibration (2026-08-17)

50 sensors of lot 500 were measured on the legacy fixture and on this rig in
the same order; raw data in [`analysis/405M22_Data/`](../analysis/405M22_Data/)
(`405M22_Data_old_fixture.xlsx`, `405M22_Data_new_fixture.csv.xlsx`).

- 46 usable pairs; per-part legacy/raw ratio: **median 4.2973**,
  regression-through-origin slope 4.2853 (agreement within 0.3 %), sd 4.4 %,
  range 3.67–4.66 → factor set to **4.30**.
- Replaying the lot reproduces every old-fixture verdict: 500-10 (the only
  low-sensitivity part) computes to 4.03 mV legacy-equivalent vs 4.08 old and
  fails; the closest passer 500-15 computes to 6.52 — the exact old reading;
  500-41 computes to 10.88 vs 11.30 old, inside the 11.98 mV maximum; parts
  27/33/37 fail high offset and 44 fails noise on both fixtures. The only extra
  failure was 500-19's SNR gate on 08-17, which the 08-18 re-run showed was a
  bad capture (it passes cleanly).
- **Independent re-run 2026-08-18:** median 4.324, repeatability sd 2.5 %.
- The near-limit band (§2.1) is the factor's margin of error expressed in raw
  mV.

### 2.4 Reference gate — disabled 2026-08-17 for op-amp crosstalk, re-enabled 2026-09-09

**The finding (2026-08-17).** The fixture's original buffer/voltage-follower
stage was a **dual op-amp with no channel isolation**, so the sensor under
test coupled into the AIN1 reference channel. The trigger was a **shorted
DUT**: with one seated, the reference reading collapsed by ~90 %, from
~4.94 mV to ~0.30 mV (lot 500, 2026-08-17 10:50), and tracked whichever part
was inserted. The app then demanded a recalibration for a fault that was the
part's — by design, not by bug: the reference-failure suppression is
one-sided (`high_offset_dut_explains_reference_*`: only an *above*-window
spike with a *high*-offset DUT is forgiven), so a collapsed reading with a
≈0 V DUT correctly refused to blame the part and invalidated the baseline.
That logic is unchanged; what was wrong was the hardware underneath it. No
recalibration could fix that, so
`REFERENCE_GATE_ENABLED = False` skipped the reference phase entirely and the
operator rule was "several low-sensitivity failures in a row → suspect the
emitter before condemning parts". The same crosstalk disabled the 406 MCA
(2026-08-24) and 449 M18 gates. Verdicts were never affected — everything is
measured on AIN0; only automatic emitter-health monitoring was lost. The
contaminated 405 baseline was archived as
`reference_sensor_calibration_crosstalk_contaminated_20260817.json.bak`.

**The re-enable (2026-09-09).** The buffer was replaced with a **TI OPA2196**
dual precision op-amp (the `hardware/single_detector_usb_master_r1` notes
list the fitted part as OPA2196IDR, SOIC-8), chosen for its channel
isolation, so `REFERENCE_GATE_ENABLED = True` on all three models, edited by
hand in each. The reference unit is read before every
sensor and must stay inside its ±25 % window (§3); the test is back to four
phases (405: reference → offset → noise → sensitivity; 449: offset →
reference → 5 Hz → 18 Hz; 406: reference → offset → sensitivity → settled
offset re-read).

> **The crosstalk re-check on the new board is still outstanding.** The gate
> was turned on ahead of it at the user's request, with the verification to
> follow immediately, reproducing the original trigger: **seat a shorted DUT
> and confirm the AIN1 reading does not move** (pass = still inside the
> ±25 % window, ideally within a few percent of the fresh baseline; the old
> board gave −90 %). Only the **406 MCA** path reads AIN1 with the DUT seated,
> so that is the model that exercises it through the app (calibrate first,
> then load the shorted part and Start: a clean board gives "Reference unit
> passed" followed by the "Is a sensor loaded?" prompt; crosstalk gives
> "Reference unit is outside its window" and a lockout — which now also
> lands in the batch's `_attempts.csv`). The 405 M22 and 449 M18 read the
> offset first and reject a ≈0 V part before AIN1 is touched, so for those
> two drive the emitter with the shorted DUT in place and watch AIN1 with
> `Arduino/Eltec/esp32_rig_readout.py ref`. Record the before/after numbers
> here when it is done. **If the reference still tracks the loaded part, set
> the flag back to `False` — do not widen `REFERENCE_TOLERANCE_PERCENT`.** A gate that moves with the DUT is not
> mis-tolerated, it is measuring the wrong thing, and no tolerance makes it
> trustworthy. The gate-off path stays unit-tested in all three models so
> that reversal is a one-line change.

**Every stored baseline is refused.** All of them were measured through the
shared dual op-amp, so their means and windows describe the crosstalk rather
than the emitter. `REFERENCE_CALIBRATION_SCHEMA_VERSION` was bumped in the
same change — 4 → **5** on the 405 and 449 (kept equal, so those two builds
still interchange baselines) and 2 → **3** on the 406 — which makes each rig
refuse its old file and lock testing until **Calibrate reference unit** is run
fresh on the isolated hardware (expect a baseline near ~5 mV). The old files
are left in the results folders as evidence; nothing is deleted or
overwritten. A superseded file reports a hardware mismatch, not corruption.

**Choosing the reference part (2026-09-04).** The isolated buffer board is
installed; the reference unit is picked from candidate 406MCA parts with
`engineer_tools/reference_unit/reference_candidate_qualifier.py`, which runs
each candidate through the production 406 MCA path (offset settling from
insertion, the 10 Hz / 50 % stabilization and sensitivity, a drive hold, the
post-emitter offset recovery) and ranks on settling time, stabilization time
and run-to-run repeatability — never on the sensitivity value itself. The
chosen part, the crosstalk re-check on the new board and the fresh baseline
go here as they are completed; the ±25 % window (§3) and the 0.250 mV
reference threshold are unchanged by the choice.

**Precision retest (2026-09-08):** `capture --precision` leaves each candidate
seated on AIN0 for 30 readings at 10 Hz / 50% duty. Each retains the production
20-cycle measurement and 20 s hold, plus an early five-cycle replay using the
existing reference algorithm. After one insertion settle, minimum emitter-off
intervals alternate 2/10/60 s. These are engineering test defaults, not new
acceptance limits. `compare --precision` ranks five-cycle CV / worst deviation
ahead of timing and keeps the retests separate from original reseating data.
See `engineer_tools/reference_unit/README.md` for the procedure and outputs.
The selected detector still needs verification and a fresh AIN1 calibration.
The production gate was nevertheless **turned on 2026-09-09** ahead of that
work (§2.4): the schema bump forces the fresh calibration before any part can
be tested, and the crosstalk re-check follows immediately. Record the chosen
part and its baseline here once both are done.

---
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

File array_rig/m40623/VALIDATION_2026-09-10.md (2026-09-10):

# Array app 0.4 validation, September 10, 2026

Changes were made in the user-requested checkout:
`C:/Users/JoseCastelblanco/Documents/Eltec_TestRig/array_rig`.
No DAQ hardware was opened, no detector acceptance limits were invented, and
no changes were committed or pushed.

## Evidence for the readout repair

The user had all ten fifth-row sockets populated. September 9 offset history
showed inconsistent in-range readings at other positions and all 50 positions
classified as loaded, preventing noise capture. The waveform viewer's bulk
path worked for the user; operator offsets had used immediate `ADC_GetScan`.
The app now uses the bulk path for operator offsets. The immediate API's
documented 128-word buffer/indexing contract was checked; the precise DLL
failure mechanism has not been established.

`test_offset_stream.py` exercises the actual ctypes callback and deinterleaver
with CH40-49 distinct voltages over three starts, fragmented callbacks,
corrupt first MUX conversions and startup transients. It also checks missing,
malformed and incomplete data, cancellation and stream-integrity failures.
No-data errors cannot become empty-detector measurements.

## Automated checks

- Bundled Python 3.11: 298 model tests ran successfully with one module skipped
  because that runtime does not include matplotlib. The 34 selector/history
  tests passed with no skips.
- Installed Python 3.14.5, NumPy 2.4.6, matplotlib 3.10.9: all **337 model
  tests passed, no skips**, including waveform graphics, Tk operator flow,
  snapshot output, noise processing, replay and retries.
- After the final replay compatibility change (`drop_first` metadata from the
  waveform viewer), all **7 replay tests passed** on the installed runtime.
  This adds one test to the previously passing full model suite; current
  discovery lists 338 model tests. Together with the 34 selector/history
  tests, 372 distinct tests have passed for the delivered changes.
- `git diff --check` passed.

The bundled run emitted a Tk theme-destruction diagnostic during teardown;
its tests still passed. The installed-runtime run completed cleanly.
The readout's pre-existing `Thread._stop` name collision, found by the first
baseline run, was repaired rather than ignored.

Noise checks include independent sinusoidal center gain and -3 dB edges,
DC rejection, rectification without signed cancellation, channel independence,
minimum capture duration, both converter rails, unresolved constant signals,
calibration mismatch, low/pass/high metric bounds and resolution-floor gates.
End-to-end tests prove old wideband peak limits cannot qualify hardware
results, pending/missing noise cannot become PASS, calibration evidence is
retained, and failed CSV schema upgrades leave old files intact.

## Recorded DAQ replay

The existing real capture
`Documents/Eltec_40623_Test_Results/40623_array_daq/noise_captures/lot_Test/tray_1_raw.npz`
was re-analysed at its recorded 1000 Hz actual timer rate. The output is
`output/array_rig_validation/2026-09-10_historical_noise_3hz.json` in the
repository. Its saved map contains seven loaded and 43 empty positions;
all seven loaded noise results remain NO_LIMIT. This historical map is not
assumed to describe the later failed fifth-row run. The original capture was
not changed. The replay is measurement evidence, not fixture qualification.

## Remaining physical checks

Repeat offset reads with the known fifth-row tray and compare its ten values
and positions against the working waveform viewer, with only one DAQ program
running at a time. Then capture under the required vacuum conditions.

Noise acceptance needs paired legacy readings and a measured instrument
background/resolution check through the 1x PCB. The legacy nominal gains and
3 Hz/Q=3 drawing support the implemented measurement band, but do not qualify
TP120 meter thresholds on raw DAQ volts. See [NOISE_METHOD.md](NOISE_METHOD.md).

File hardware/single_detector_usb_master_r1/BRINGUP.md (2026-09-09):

# Engineering acceptance procedure

This procedure is for the separate USB-master R1 prototype. It records the evidence needed after CAD checks; no listed physical test has yet been performed. Use the final schematic, BOM and board revision matching the validation hashes.

## Before module insertion

Confirm the installed jack polarity and exact socket pin numbering against the retained native interface drawing. ESP32 and ADC modules are customer inserted; the two jacks are customer soldered. All other purchased components, including socket strips and the emitter trimmer, belong in the assembly BOM.

Inspect the received board for polarity and pin1 on protection devices, regulators, analog switches, optocouplers and polarized capacitors. Confirm continuity of GND and the separate EM_GND domain; there must be no accidental conductive bridge between them. Confirm neither battery positive reaches ESP VIN/USB5V or ESP3V3.

Initially use current-limited bench supplies at the confirmed nominal6.4V and keep the emitters/detectors disconnected. The pack's actual full-charge voltage and BMS limits must be documented before pack-endpoint qualification. Do not assume a6.4V label is the maximum voltage.
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

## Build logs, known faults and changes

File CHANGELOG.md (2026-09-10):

# Changelog — Eltec Test Rig

Newest first. One dated `##` entry per change that alters behaviour, a
threshold, the firmware, the wiring or the documentation structure — added in
the same commit as the change. This file is **history**: it records what
changed and why, at the time it changed. Durable facts (current constants and
their provenance, wiring, where data lives, how to run things) live in
`docs/` and the per-area READMEs and are kept current there; if an entry below
contradicts a `docs/` file, the `docs/` file wins.

Entries before 2026-08-28 were migrated verbatim from the former `status.md`.
Paths they mention may have moved since; the retired applications they refer
to are preserved at git tag `archive/pre-cleanup-2026-08-28`
(`git show archive/pre-cleanup-2026-08-28:<path>`).

## Array 40623: stable offset acquisition and 3 Hz noise evidence (2026-09-10)

- Operator offset reads use the same continuous bulk path as the working
  waveform viewer, with startup/MUX discard and verified channel frames.
  Saved September 9 readings did not match the user's physically loaded fifth
  row. The exact driver cause is unverified; synthetic repeated row-5 tests
  exercise fragmented callbacks and corrupt initial samples.
- Offsets and noise values are always visible together. A loaded-socket
  selection dialog supports partial trays without widening the empty-voltage
  threshold; a map change requires new offset and vacuum confirmation.
- Added nominal 3 Hz/Q=3 RMS and rectified/10-second-smoothed noise metrics
  from the supplied fixture drawings, per-channel quality evidence, strict
  paired calibration loading and saved-NPZ replay. No paired readings exist
  yet; TP120's final meter limits are not applied to raw detector volts.
- Fixed uncalibrated noise becoming PASS in exported overall results.
  CSV schemas extend atomically with historical rows/custom columns retained;
  raw NPZ files include the measurement method, setup and quality evidence.
- Fixed the live reader's cancellation event overriding `Thread._stop`, which
  caused shutdown/join errors. No real hardware was operated for this change.
- Qualification and source drawings: `array_rig/m40623/NOISE_METHOD.md` and
  `docs/40623_legacy_fixture/`. App version is 0.4; calibration stays pending.

## Single-detector rigs: reference (emitter-health) gate re-enabled (2026-09-09)

- `REFERENCE_GATE_ENABLED = True` again on all three single-detector models
  (405 M22, 406 MCA, 449 M18), each edited by hand. The AIN1 reference unit
  is read before every sensor and must stay inside its ±25 % window, so a
  weak or failing emitter is caught by the rig instead of appearing as a run
  of low-sensitivity parts. The gate had been off since 2026-08-17 (405) /
  2026-08-24 (406, 449) because the shared dual op-amp buffer had no channel
  isolation and the DUT coupled into AIN1 (4.94 → 0.30 mV with a part
  loaded); the channel-isolated buffer board installed in 2026-09 removes
  that coupling path. The array rig has no reference gate and is untouched.
- **The crosstalk re-check on the new board is still outstanding** and is
  being run immediately after this change: drive a DUT and confirm the AIN1
  stream does not follow it. If the reference still tracks the loaded part,
  set the flag back to False — do not widen `REFERENCE_TOLERANCE_PERCENT`, a
  gate that moves with the DUT cannot be calibrated at any tolerance. The
  gate-off path stays covered by tests in all three models for exactly that.
- **Every stored baseline is now rejected on load**:
  `REFERENCE_CALIBRATION_SCHEMA_VERSION` 4 → **5** (405, 449, kept equal so
  the two builds still interchange baselines) and 2 → **3** (406). Those
  files were all measured through the shared dual op-amp, so their means and
  windows describe the crosstalk, not the emitter. Each rig therefore locks
  testing until **Calibrate reference unit** is run fresh on the isolated
  hardware. The old files are left in place in the results folders as
  evidence — nothing is deleted or overwritten.
- A superseded schema now reports itself as a hardware mismatch ("schema v4,
  but this build requires v5 …, run Calibrate reference unit") instead of the
  old "file is malformed", which would have sent technicians looking for a
  damaged results folder. A file with no usable `schema_version` still reads
  as malformed.
- Tests: each model gains a shipping-default class asserting the flag is on,
  that a stale-schema baseline is refused with the hardware-mismatch wording,
  and that `reference_gate_ready()` blocks measurement until a fresh baseline
  exists; the former "gate disabled" classes now patch the flag off
  explicitly and keep covering the fallback. 405 noise-soak and 449
  hardware-flow expectations updated to the four-phase production sequence
  (offset → reference → sensitivity → settled offset). Suite: **936 tests**
  (was 928), one known Windows-only 406 case unchanged.
- Docs: calibration record §1/§2.1/§2.4/§3/§4/§5/§7, both rig READMEs, the
  three model READMEs, engineer handover, technician runbook, data map and
  `engineer_tools/reference_unit/README.md`.
- **Same day, after review.** The hardware facts recorded precisely: the
  old buffer's failure trigger was a **shorted DUT** — it dragged the AIN1
  reference down by ~90 % (4.94 → 0.30 mV) and the app demanded a
  recalibration for a fault that belonged to the part. The replacement
  buffer is a **TI OPA2196** dual precision op-amp (the `hardware/` r1 notes
  list it as OPA2196IDR), chosen for its channel isolation; the user's
  re-check reproduces exactly that shorted-DUT case. Why the old prompt
  fired is by design and unchanged: the reference-failure suppression is
  one-sided (only an *above*-window spike with a *high*-offset DUT is
  forgiven), so a collapsed reading with a ≈0 V DUT correctly refused to
  blame the part and invalidated the calibration — with real crosstalk that
  is the wrong answer, with the OPA2196 it should never arise.
- **A reference lockout now writes a `measure_error` row to the batch's
  `_attempts.csv`** (all three models, by hand). `on_reference_block` only
  showed a warning box and a status line, so the very event the re-check
  looks for would have left no per-part trace once the technician clicked
  OK (the invalidated JSON keeps the reading, not the part). The row carries
  the reading, the drift and the AIN0 re-check from the error text; the 405
  and 449 also keep it in `last_measure_error` for the result screen (the
  406 has no such field). One test per model. Suite: **939 tests**.
- Where the shorted-DUT case can be exercised *through the app*: only the
  **406 MCA** reads AIN1 with the DUT seated; the 405 M22 and 449 M18 read
  the offset first and reject a ≈0 V part ("Is a sensor loaded?") before
  AIN1 is touched. For those two, drive the emitter with the shorted DUT in
  place and watch AIN1 with `Arduino/Eltec/esp32_rig_readout.py ref`
  (engineer handover §4 item 3).

## Array rig: infer empty sockets and shorten noise settling (2026-09-08)

- Automatically mark likely empty sockets after two median-of-three offset
  reads within one ADC code of zero, separated by two seconds on hardware.
  Re-evaluate on every check; preserve manual loaded/empty overrides. The
  physical map/count is confirmed with the existing vacuum confirmation.
  This provisional inference cannot distinguish a zero-output short from
  an empty socket or reliably detect floating empty inputs. All-zero trays
  stay blocked with a power/connection check prompt.
- Remove the five-minute app countdown at the user's request. The supplied
  TP120 photo specifies five minutes after power-on and a separate 15–20 s
  switched-position wait; document this as an intentional timing departure.
  Compare successive one-second maxima and minima on loaded channels: two
  stable deltas permit a start after three seconds; twenty seconds is the
  deadline, with a warning if still moving. Retain the full sixty-second
  capture, noise algorithm, provisional verdict thresholds and calibration ID.
- Preserve contiguous samples at the settle/capture boundary. Extend attempts,
  result CSV and raw NPZ metadata with timing policy, extrema/deltas and stop
  reason. Offset audit retains inferred occupancy, overrides, initial/recheck
  voltages and the loaded interpretation of excluded readings.
  Raw NPZ duration now follows the recorded waveform length, including
  engineering capture-length overrides.
- Keep PASS/FAIL as the default display with numbers under **Show more**.
  Update the runbook, calibration record, data map and model documentation;
  add empty-inference and adaptive-waveform regression coverage.
- Validation: final `python run_all_tests.py` reports **928 tests, RESULT: OK**,
  including **297 array tests** and **34 array glue tests**, with the documented
  Windows-only 406 launcher exception. An unrelated 20 ms single-rig stream
  timeout failed on the initial run and passed both its suite rerun and the
  final full run. Hardware was not connected; physical empty-input behaviour
  still needs bench confirmation. Update the documented test baselines.

## Array rig: show pass/fail first, measurements on request (2026-09-08)

- Simplify the round sockets to pass/fail and current state by default,
  keeping row-column position labels visible. **Show more** reveals numeric
  measurements and assigned sensor numbers; **Show less** hides them again.
- Keep **WAITING**, **EMPTY**, **RECHECK**, **NO LIMIT** and **NOT READ**
  visible where no pass/fail verdict exists. Update the array READMEs and
  technician runbook to describe the optional details view.

## Array rig: two-step operator workflow and hardware-free demo (2026-09-08)

- Replace the crowded 40623 tray controls with an Eltec-branded screen:
  tech name, batch number, **Measure offset**, **Measure noise**, and a
  numbered 5 × 10 map of round detector sockets. Tray and sensor numbers,
  the five-minute stabilisation, sixty-second capture and saving are
  automatic; **Next tray** waits for a successful save. **Stop** permits retry.
- Read offsets on demand and retain every screening read for audit. Repeat
  while replacing red out-of-range detectors, or mark physically empty
  sockets when replacements run out. Low/dead readings can settle and should
  be rechecked; near-zero voltage never automatically means empty. Reloaded
  sockets require a new offset read before noise.
- Prompt for the physical rig power switch immediately before offset and
  require operator confirmation of the vacuum gauge before noise. The app
  observes signals; it does not switch power or vacuum, measure pressure,
  or invent a vacuum setpoint.
- Record vacuum confirmation in the tray history. Retrying a failed save
  reuses completed artifacts and commits CSV/history appends atomically,
  so a storage error followed by **Retry save** does not duplicate rows.
- Add selector **Simulation** and a fast virtual-clock demo via `--simulate`,
  with simulated replacements and red/green noise results. Demo limits are
  isolated to the simulator instance. Results carry a simulation flag and
  demo provenance, with files under the system temp folder's `eltec-array-simulation` directory
  (or `<ELTEC_ARRAY_RESULTS_ROOT>/simulation`). Production noise limits
  remain `None`, shown as amber **NO LIMIT** instead of a pass.
- Update the array READMEs, selector flow description, technician runbook,
  data map and calibration policy notes. Preserve the controller's legacy engineering API and the existing
  acquisition settings, offset limits and production noise calibration.

## Reference candidate retest: seated AIN0 precision sessions (2026-09-08)

- Add `capture --precision` and `compare --precision` to the reference-unit
  qualifier. Keep each candidate seated on AIN0 for 30 readings at 10 Hz /
  50% duty; settle insertion once, then alternate minimum 2/10/60 s emitter-off
  intervals. Preserve production 20-cycle captures and a 20 s driven hold.
- Replay the actual five-cycle reference algorithm on each early AIN0
  waveform. Report between-reading CV, worst deviation, completion times,
  pause-group shifts and early/late differences; rank precision before speed
  without rewarding insertion settling or sub-millisecond timing differences.
- Store retests in `<out>/precision`, separate from prior reseating runs;
  record actual intervals, retries and planned sessions, reject incomplete
  sessions and incompatible acquisition settings from ranking. Preserve raw
  waveforms, production quality checks and per-reading results on interruption.
- Add replay, seated-session, comparison-isolation, timing and failure tests;
  correct virtual simulation elapsed time when an adaptive capture stops early.
  Update the bench instructions and qualification provenance. Production
  gates, thresholds, calibration factors and firmware are unchanged.

## Engineer tools: reference-unit candidate qualifier; folder per topic (2026-09-04)

The channel-isolated buffer board is in, so the AIN1 reference gate can come
back once a reference detector is chosen. Five candidate 406MCA parts are on
the bench; the question is which one settles fastest and reads the same
every time - not which one is most sensitive.

- New `engineer_tools/reference_unit/reference_candidate_qualifier.py`
  (`capture --label <part> --runs 3`, `compare`). Each run walks one
  candidate through the production 406 MCA path with the production code
  imported headless: (A) `OFFSET?` polled at the production 1 s poll from a
  re-seat until quiet (up to 60 s), with the production settle rule
  (`wait_for_settled_offset`) replayed on the reads; (B) `PIN,33` /
  `PWM,ON` 10 Hz / 50 %, `read_waveform_until_stable` with the DUT
  settings, stream retries and front-end re-checks as in the app,
  `analyze_v6_stable_measurement` + `evaluate_result` for the production
  sensitivity, SNR, polarity and PASS/FAIL; (C) a 20 s drive hold for the
  amplitude drift; (D) `PWM,OFF`, the production settled-offset wait live,
  then polling until quiet (recovery time, heat shift). One `.json` (every
  number + the offset and per-cycle series) and one `.npz` (raw waveforms)
  per run under `~/Documents/Eltec_ReferenceCandidates/<label>/` - its own
  folder; an `Eltec_*_Test_Results` path is refused. `compare` aggregates
  per candidate (medians, run-to-run CV), disqualifies a production FAIL /
  never-stabilized / never-in-band / polarity flip, ranks the rest on
  weighted metric ranks (`SCORE_WEIGHTS`, printed with the table), writes
  `comparison_<stamp>.csv|.png` and prints a recommendation. `--channel ref`
  measures a part already on the AIN1 mount (`REF?`, `STREAM,START,REF`).
  `--simulate` runs candidate personalities on a virtual clock.
- `engineer_tools/` reorganised one folder per topic: `noise_band/`
  (`replot_noise_capture.py`, `filter_response_analysis.py`),
  `array_parity/` (`array_noise_parity.py`), `emitter/`
  (`emitter_waveform_comparison.py`), `reference_unit/` (new). `git mv`;
  `REPO_ROOT` in each tool is now `parents[2]`; every path reference in
  `README.md`, `docs/`, the array README / tester / analysis comments, the
  array tests and `analysis/reports/` updated. Older entries below keep the
  paths that were true at the time. `engineer_tools/README.md` is the index.
- Docs: `engineer_tools/reference_unit/README.md` (bench procedure, what a
  reference is judged on, the weights, the steps after choosing),
  CALIBRATION_RECORD §2.4 (how the reference part is chosen; baseline still
  to be recorded when the gate is re-enabled), ENGINEER_HANDOVER §9 / §10.3,
  DATA_MAP §4, the 406 README.
- Tests: `single_detector_rig/m406mca/tests/test_reference_candidate_qualifier.py`
  (24 cases: settle metrics on synthetic series, the production replay
  against `wait_for_settled_offset` itself, cycle series / hold trend,
  aggregation, disqualifiers, ranking with ties and missing values, the
  results-folder guard, a simulated capture -> compare round trip in a temp
  dir, the fake rig's contract). Baseline 857 (406 MCA 203).

## Single-detector rigs: Stop writes the verdict on screen without asking (2026-09-03)

Bench report: ending a batch with **Stop** (or Esc) put up a "save it before
ending the batch?" box for the part still on screen - a third question at
the end of every batch, on a verdict the technician had already judged, with
a wrong answer (or an Esc on the dialog itself) throwing the reading away.

- `stop()` on all three models (405 M22, 406 MCA, 449 M18) now calls
  `save_current_sensor()` directly when a verdict is unsaved, then ends the
  batch. The `askyesnocancel` prompt is gone; there is no way to leave a
  batch and discard a measured part any more. To end a batch *without*
  recording the part in the rig, press Stop **during** the capture - that
  path is unchanged (nothing recorded, the number does not move).
- A write that cannot complete still holds the batch open: `save_current_sensor`
  returns False for a cleared failure mode or a results-folder error and puts
  up its own dialog, so `stop()` returns and the verdict stays on screen.
  A FAIL always arrives with a failure mode pre-selected (`suggest_failure_mode`),
  so this is only reachable if the technician clears the box by hand.
- Ported by hand model by model per `docs/ENGINEER_HANDOVER.md` §4; the array
  rig's tray flow is untouched.
- Docs: `docs/TECHNICIAN_RUNBOOK.md` §3 and `single_detector_rig/README.md`
  action-bar table.
- Tests: `test_stop_offers_to_save_an_unsaved_verdict_first` replaced by
  `test_stop_saves_an_unsaved_verdict_without_asking` (asserts the prompt is
  never called) plus `test_stop_keeps_the_batch_running_when_the_write_fails`,
  in all three suites. Full run: 833 tests, one known Windows-only 406 case.

## 406 MCA: the offset verdict moves to a settled re-read after the capture (2026-09-03)

Bench report: parts failing `HO - High offset` that are inside the
0.3-1.2 V band if they are simply left in the rig a little longer. The 406
was reading the offset once, before the emitter even started, and judging
the part on that number 30-60 s later - while the 405 M22 has judged on a
settled re-read since 2026-08-17 (lot 500: 35 of 48 parts read 0.15-1.1 V
away from their settled value on the insertion read). The 406's parts drift
the other way (down), which is why this shows up as HO rather than LO.

What changed, model 406 MCA only (the 405 and 449 are untouched):

- **The verdict uses an `OFFSET?` re-read taken after the sensitivity
  capture.** No bench time is added: the part has already been powered in
  the rig through the whole stabilization plus the 20-cycle measurement, so
  this is the level TP120's 0.3-1.2 V band describes. The insertion read is
  kept as `offset_initial_v` in the batch CSV.
- **An out-of-band re-read is held, not failed.** The app keeps reading
  (1 s apart, `OFFSET_SETTLE_MAX_WAIT_S` = 20 s) and stops as soon as the
  level is back in band; as soon as it has stopped moving without improving
  (so a genuinely high part still fails in ~2 s); or at the deadline, where
  the last reading is used. "Stopped moving" is a **relative** delta,
  `OFFSET_SETTLE_DELTA_FRACTION` = 10 % of the current reading (62 mV at
  0.624 V) - about 1000x the read-to-read scatter of an `OFFSET?`
  median-of-24, so only real drift can breach it. **A reading still moving
  toward the band never ends the wait early**: "it changed for the better"
  is the case this exists to catch.
- **No noise estimation in this path** (considered and rejected): the
  firmware read is already a median of 24 samples over ~100 ms, so what
  remains is the sensor's own slow wander - the thing being measured - and
  the threshold has three orders of magnitude of margin over the read
  noise. If the wait ever ends early on wander, average three consecutive
  reads per sample before tightening the fraction.
- **In band but still moving = PASS with a warning**, never a failure
  (user decision): a drift limit would be an invented number until a lot's
  worth of `offset_settle_delta_v` exists to derive one from. The result
  card shows an amber "OFFSET WAS STILL SETTLING" note. Note this rig has
  no emitter-off noise test, so that warning is where a drifting part shows
  up.
- **The pre-flight "no sensor" check is low side only.** A high or railed
  AIN0 is a real part whose offset has not settled - it now runs the full
  test and records HO from the settled reading instead of raising the
  empty-slot dialog (the same lesson as the 405's 2026-08-13 change). Near
  0 V still blocks before anything is captured.
- New batch CSV columns: `offset_initial_v`, `offset_settle_s`,
  `offset_settle_delta_v`, `offset_settled`, `offset_settle_reads`. Batch
  files started before today keep their header and stay aligned.
- Simulator: new `Offset settles into band` case (starts at 1.35 V, decays
  into band) exercises the hold without hardware. Stop is honoured inside
  the wait like every capture loop.
- Also fixed in passing: the "Is a sensor loaded?" dialog was missing an
  `f` prefix and printed `{self.current_sensor_id}` literally.

Suite: 830 tests (406 MCA 160 -> 178), one known Windows-only case.

## Single-detector rig: a stalled stream now says which side stopped and restarts itself; the 406 MCA gets the stream-tolerance port and a front-end guard (2026-09-03)

Bench report (Xubuntu, 405 M22, 2026-09-02): "ESP32 noise stream stalled
after 37624 samples" on part after part, the technician pressing Re-measure
each time, and suspected to follow nights the rig stayed powered. The 406
MCA had separately failed a 12 s capture on "1 timestamp gaps (~2 missing
samples); host/firmware sample counts differ (12047/12049)" (2026-08-31).
What the code review found, and what changed:

- **The ESP32 holds no state that ages.** The firmware keeps one latched
  sample and a 48-byte command buffer, allocates nothing while streaming,
  and its 71-minute `micros()` wrap is handled on both sides; every sample
  lives on the laptop. Opening the port resets the board, so the app start
  each morning wipes its uptime anyway. If the overnight correlation is
  real it points at the laptop/USB side - and until today the error could
  not say which. No firmware change.
- **"Stalled" is attributed** (405 M22, 449 M18, 406 MCA). A stall is the
  host seeing no sample for `STREAM_TIMEOUT_S` (2 s). The capture now stops
  the stream *first* and reads the board's `STREAM,END` reply, whose
  numbers (firmware count vs host count, the backlog drained after the
  stop, any READY banner) pick a tag that ends the message: `[host-stall]`
  (the board kept sampling, the laptop stopped reading), `[board-reset]`
  (the counter restarted - the ESP32 rebooted), `[board-silent]` (counts
  match - the ADS1256 data-ready stopped) or `[no-reply]`. The message also
  states the seconds of silence and the advice for that case. The backends
  record `last_sample_monotonic`, the first non-protocol lines
  (`ignored_line_samples`) and `live_samples` for this. The reset *reason*
  is not readable: the ROM banner is emitted at 115200 baud (handover §10).
- **A stall is retried like a micro-gap failure.** `StreamStalledError` is a
  `StreamIntegrityError`, so `call_with_stream_retries` restarts the capture
  (fresh `STREAM,START`, PWM re-armed) up to `REFERENCE_READING_STREAM_RETRIES`
  (2) times - exactly what the technician did by hand - with nothing
  recorded from the silent capture. A dead port is still never retried.
  The status line says "Stream stalled during the noise capture; nothing
  was recorded - restarting the capture (1/2)".
- **Every automatic restart is evidence.** New attempts-log events
  (`attempt_history.py`): `stream_retry` (one row per restart, reason =
  phase + the attributed error) and `rig_note` (something the app put right
  on the rig). Neither moves the attempt count. `on_retry` callbacks now
  receive `(attempt, error)`.
- **406 MCA: the 405's stream work, ported by hand** (handover §4). Its
  backend was the pre-2026-08-12 build (no drain thread, no overflow
  attribution, no power-throttling opt-out) and its validator rejected any
  gap and any count mismatch - the 2026-08-31 failure was a 2 ms USB hiccup
  the 405 and 449 tolerate. The 406 now carries the same bounded budget
  (`STREAM_MAX_MICRO_GAPS` 3 / `STREAM_MAX_MISSING_SAMPLES` 20, refilled by
  `StreamGapFiller`), the same bounded retries around the calibration
  readings, the reference gate and the driven capture, and the
  405-generation backend. Policy decision, user-approved 2026-09-03: the
  same budget as the other two models; 20 ms cannot move a robust
  per-cycle peak. No 406 threshold changed.
- **406 MCA: front-end guard.** `FE,V19` is session state the board drops on
  a reset. `Esp32Rig.ensure_qualified_front_end()` re-reads `FE?` before
  every measurement and calibration and before every stream retry; a
  reverted board is re-programmed and verified as at connect, the status
  line says the board restarted, and a `rig_note` row records it.
- **Tests**: glue 45, 405 M22 200 (4 skipped), 406 MCA 160, 449 M18 135,
  array glue 31, 40623 array 241 - **812**. The 406 backend test
  `test_auto_connect_validates_candidates_and_is_idempotent` gained the
  405's POSIX guard, so on Windows only the bash-installer case remains
  environment-only (`run_all_tests.py` updated).
- Docs: 405/406/449 READMEs (serial-stream reliability), technician runbook
  §5 (the tags, what to tell the engineer), firmware README troubleshooting,
  handover §7/§10, CLAUDE.md. Not changed: thresholds, timeouts, the 2 s
  stall budget, the firmware.

## Single-detector rig: two buttons, and a number only a PASS can spend (2026-09-02)

Behaviour change in all three single-detector testers (405 M22, 406 MCA,
449 M18). The array rig is untouched.

**A sensor number is now earned, not issued.** The skip queue assumed the app
was tracking one physical part through the batch, but the bench does not work
that way: a part that fails is put aside and another one takes its place. So
the number no longer advances on a FAIL - `next_sensor_number_for_batch` is
one past the highest **PASSED** number, and a FAIL or a NOT MEASURED row
leaves its number open for the replacement. Fail on 500-7 and the next part
tested is 500-7 again, whether it is the same part re-seated or a new one out
of the tray; whichever finally passes is the part that ships as 500-7.

Consequences in the data:

- A batch CSV is **one row per test**, not one row per number. `500-7` can
  appear several times, the last of them the PASS. Yield still counts rows,
  so failures are all still in it.
- The `skip_count` column is replaced by **`number_attempt`** (1 = the first
  part tried under this number, 2 = the one loaded after it failed, ...), in
  the same column position. `measure_attempts` now counts the reads of the
  part in front of the technician and starts over for each replacement.
- Reading the highest PASSED number (rather than counting passes) leaves
  batches written before today intact: their numbers were handed out per row,
  so a file whose last pass is 500-9 continues at 500-10 as it always did.

**The action bar is two buttons: Stop and Next.**

- **Next** reads the sensor that is in the rig now. With a verdict on screen
  it writes the row first. There is no "load the next sensor" screen in
  between any more - the technician loads the replacement, then presses Next.
  Start does the same for the first part of a batch, so the load STEP is gone
  entirely and its card (rig picture, and the 405's noise-soak toggle) moved
  onto the setup screen; the 405 soak toggle is also on the result card, where
  it arms the read Next is about to take.
- **Stop** (red) is live at *every* moment, including mid-capture: it bumps
  the measurement token, which the capture loops already poll through
  `cancelled=`, so the reading is abandoned at the next chunk boundary with
  the stream stopped and the emitter switched off by the worker's own
  finally-blocks. Nothing is recorded and the number does not move. With no
  capture running it ends the batch, offering to save an unsaved verdict
  first. Esc is the same control.
- Gone with the skip queue: **Skip part**, **Re-measure**, **Measure
  skipped**, **Back**, **Save + Exit Batch**, and the `skipped` / `resumed` /
  `remeasure` attempt events. A new `stopped` event records an abandoned
  capture. Recording a sensor as NOT MEASURED after a rig fault stays (405 and
  449), renamed off the word "skip" in the UI and in the code
  (`open_not_measured_window`, `save_not_measured_sensor`).

Trade-off, stated because it is a real loss: with Re-measure gone there is no
way to discard a verdict that is already on screen. A suspect reading is
saved as what it says and the part re-tested - which under the new rule costs
nothing on a FAIL, since the number stays open. To abandon a reading without
recording it, press Stop while it is still measuring.

Tests: 753 (glue 44, 405 189, 406 123, 449 125, array glue 31, 40623 241).

## Array rig: DB37 connector split written down (2026-09-02)

Documentation only — no constant, threshold or behaviour changed.

The two DB37 cables between the array PCB and the DAQ carry the fifty
channels in four blocks, not two halves: CH0-CH15 and CH32-CH47 on the DAQ
connector that the guide calls J2, CH16-CH31 and CH48-CH49 on J1 (DAQ-PACK M
Series guide tables 5-1 and 5-2, pins 9/18/19/36 AGND). The breakout PCB was
built to that pinout; its KiCad netlist was re-traced end to end on this date
(sensor-box pin N -> buffer -> series resistor -> DAQ_CH(N-1) -> the DB37 pin
the datasheet assigns to that channel) and agrees with it for all fifty
positions, as does the pre-`norcomp_db37_merge` backup of the board.

Nothing in the software ever assumed a contiguous 0-24 / 25-49 split — the
scan is requested as the one contiguous range CH0-CH49 and the driver returns
the channels in channel order whichever cable each arrived on — but the model
README said only "J2/J1 DB37: CH0-CH49", which reads as though the two cables
divide the tray in half and misled a bench check. The README now carries the
per-connector pin table and the affected array positions, and
`daq_backend.py`'s fixture-geometry block says why no remap belongs there.

The connector split is a bench-metering fact: it matters when probing a DB37
pin by hand, not when reading a capture. `(row-1)*10 + (col-1)` is unchanged.

## Array rig: ESP32-style bench readout and live viewer for the DAQ (2026-09-02)

The bench habits of the single-detector rig (`Arduino/Eltec/esp32_rig_readout.py`'s
`Esp32Rig` API + CLI, `live_waveform.py`'s rolling scope) now exist for the
50-channel DAQ, inside `array_rig/m40623/` and built on `daq_backend.py`
only (nothing shared with the single rig). Both are engineering tools: no
verdicts, output files only at explicit paths, never under `Documents`, one
program on the DAQ at a time.

- `array_rig/m40623/daq_rig_readout.py` - `ArrayRig` (connect -> configure
  -> `ADC_SetCal(':AUTO:')` -> configure, the tester's order;
  `read_offset_voltage(position)` / `read_offsets()` = median of 24
  immediate scans, the ESP32 `OFFSET?` depth; `capture(seconds, positions)`
  -> `Capture` with own-scale volts `[channels, N]`, a synthesised `t_us`
  from the granted pacing-clock frequency (the DAQ has no per-sample
  timestamps), `band_limited_pp_mv()` through the tester's exact judged-band
  pipeline, `to_csv()` (`t_us,<position>,...`) and `to_npz()` (the bench
  probe's key layout + `drop_first`, replayable by
  `engineer_tools/replot_noise_capture.py` given the file path);
  `set_range()`; `LiveStream` = a thread that owns every device call and
  fills a ring buffer (`snapshot`, `latest`, `stats` with the delivery rate
  between the first and the newest chunk - so the driver's buffer latency
  does not read as a shortfall - and the lag behind real time). CLI
  `info | offset [POSITION ...] | stream -s 8 [-p ...] [-o cap.csv]
  [--npz cap.npz] | noise -s 20 [--quiet-wait S] | watch [-p ...] [-s S]
  [--interval 1] | test -s 20`; positions as `row-col`, `CHn` or a channel
  number; `--simulate`; the tester's acquisition constants as defaults
  (mirrored, with a drift test). A capture whose stream diagnostics report
  a problem raises (the ESP32 tool's overrun rule).
- `array_rig/m40623/daq_live_waveform.py` - matplotlib rolling scope of ANY
  position, switched live (arrow keys over the 5 x 10 grid, `n` / `p`, a
  click on a tile, a "Pos" button). Three panels: the wideband trace with
  the stats box (mean, raw pk-pk, judged-band worst/median, rate, lag,
  chunks, errors); the 5 x 10 grid of all positions coloured by the live
  offset in TP120's provisional bands or (`g`) by judged-band pk-pk with no
  limit; and the judged-band trace of the selected position (the tester's
  FIR-decimate-and-detrend pipeline on the displayed window, per-window
  pk-pk listed) in place of the ESP32 viewer's cycle-average panel (no
  emitter board, so no sync to fold on). SPACE = Hold/Run (the slot of the
  ESP32 viewer's emitter toggle), `]` / `[` window ladder 0.25-60 s as
  before, `s` saves the whole buffer as `daq_live_<stamp>.npz` (`--save-dir`,
  default the current directory; `--save-on-exit`), `--exit-after` for
  unattended runs (works headless with `MPLBACKEND=Agg`). Drawing is a
  canvas timer with blitting (a full redraw of the 50-tile figure costs
  ~100 ms); the y-scale holds with hysteresis instead of jumping every
  frame.
- Verified on the real unit 2026-09-02: `info`, `offset`, `test` (offsets,
  then a stream - the order that delivered nothing before the fix in the
  entry below), `stream` 0.5 s / 2 s with CSV and npz, `watch`, and the
  viewer for 6 s under Tk and 4 s headless - all integrity OK at 999-1000
  scans/s. Inputs read ~0 V because the array PCB was not connected.
- Tests: `tests/test_daq_rig_readout.py` (59) and
  `tests/test_daq_live_waveform.py` (40, Agg backend) - token forms,
  connect/config/self-cal, offsets, captures and their files, npz replay
  through the replot tool, `LiveStream` fill/wrap/stop/error paths and the
  rate rule, every CLI command under `--simulate`, the ladder / selection /
  judged-band helpers, viewer updates with hold, grid metric and save, the
  headless `--exit-after` path, constants drift, Documents guards. 40623
  array suite 142 -> 241; `run_all_tests.py` total **705**.
- Pre-commit review fixes (an independent read of the new code): the
  viewer holds its y-scale on a flat trace (a code-0 input used to fail the
  40 % fill rule and force a full figure redraw on every frame - 6 fps with
  the CPU pegged), `LiveStream.snapshot` copies only the wanted rows, the
  END-before-stop flag is decided at delivery on the DLL's thread (the
  consumer could dequeue an early END after the stop was requested), a
  range set between `live_stream()` and `start()` is honoured, duplicate
  `-p` tokens collapse to one, `to_npz('x.NPZ')` returns the file numpy
  writes, and a failing re-assert or stop never masks the read error that
  caused it.
- Docs: README map and test count, `array_rig/README.md` layout,
  `m40623/README.md` engineering + tests, ENGINEER_HANDOVER sections
  3/7/9/10/11, DATA_MAP section 4, CLAUDE.md rule 6 baseline and "easy to
  get wrong" items, runbook (one program on the DAQ at a time - on the bench
  a second program is not refused: it silently takes the stream away from
  the first, whose integrity check then fails).

## Array rig: the DLL's immediate reads clear the trigger byte - backend re-asserts its block; silent streams time out (2026-09-02)

A read-only verification of the DAQ installation and of every assumption in
`daq_backend.py` against the vendor documentation and the DLL's shipped
Delphi source (`C:\Users\Public\Documents\ACCES\USB-AIO16-64MA\Win32\Driver.SRC`)
found the installation clean (driver 3.0.150.9161 CyUSB3, `AIOUSB.dll` 2.4
x64 in System32 loaded by the 64-bit Python, the unit on a root-hub port at
USB 2.0 high-speed, selective suspend disabled on AC and DC; the not-present
"(D15 Lo)" Device Manager entries are the chip's pre-firmware identity and
harmless), every probe command clean again (60 s stream 60 000 scans in
60.00 s, 0 pool events, 0 leftover bytes; one-shot `ADC_BulkAcquire` path
3000/3000; instrument floor 53 uV rms, judged band 50.6 uV median / 77.5 uV
worst), all eleven code-vs-documentation items matching - and one blocker:

- **`ADC_GetScan` / `ADC_GetScanV` rewrite the device's configuration
  block** (`ADC_GetScan_Inner`: scan mode forced, timer and external
  trigger bits cleared, 0x05 -> 0x04, oversample forced to at least 1)
  and never restore any of it. The tester
  polls offsets with `ADC_GetScan` and then starts the noise stream without
  re-writing the block; reproduced on the unit in that exact order: pacing
  clock granted 1000.000 Hz, **0 scans in 12 s**, and the GUI would have
  sat at "quiet wait" until Cancel. The bench spike never saw it because
  every probe command reconfigures first. Fix in `daq_backend.py`:
  `AiousbDaq._reassert_config()` re-writes and read-back-verifies its block
  after every immediate read (`read_scan_counts`, `read_scan_driver_volts`)
  and before every `start_stream` / `bulk_acquire`; the fake DLL in
  `test_daq_backend.py` now models the side effect and three regression
  tests pin the re-assert. Confirmed on the unit: the same sequence now
  streams 3040 scans in 3.04 s with the block reading 0x05 throughout.
- `eltec_40623_array_tester.py`: `STREAM_NO_DATA_TIMEOUT_S = 5.0`
  (`CapturePlan.no_data_timeout_s`) - the quiet wait and the capture loop
  abandon a stream that delivers nothing for 5 s with a
  `StreamTimeoutError`, so the existing retry policy runs and the tray is
  recorded NOT MEASURED instead of hanging (two tests; the runbook's
  troubleshooting row now lists "no data from the stream").
- `StreamDiagnostics`: new `ended_early` - the driver's END flag arriving
  before `stop_stream` asked for it is now a problem ("the record is
  incomplete") and the only case the summary reports as "ended by device
  before stop" (the flag is delivered on every normal stop, so the old
  summary text was noise); pool events reworded to what the flag means (an
  extra buffer had to be inserted: the host fell behind) - still a retry;
  the comment on the END buffer timing corrected (`ADC_BulkContinuousEnd`
  joins the DLL's threads before it returns).
- The "-HG check" was overstated: the DLL's `ADC_GetScanV` uses the same
  counts x span / 65536 formula as our table (source checked), so the
  probe's "driver V" column can never reveal a high-gain variant; only a
  known, metered voltage on an input can. Probe footer, `m40623/README.md`,
  CALIBRATION_RECORD 4b.2 / 4b.3 reworded; `floor` wording corrected to the
  full-scale reference (ground clips at code 0 on a unipolar range);
  "full-speed" -> the link is USB 2.0 high-speed, the 1 MB/s figure is the
  driver's. CALIBRATION_RECORD section 6 array row extended with the
  finding, the driver version and the USB facts. No constant moved.
- Tests: 40623 array suite 134 -> 142 (backend 55 -> 61, tester +2).

## Array rig: bench spike numbers, parity tool, replot of tray captures (2026-09-02)

- **Bench spike on the real DAQ** (`daq_bench_probe.py info -> selfcal ->
  config -> scan -> slots -> floor -> stream 60`, DAQ alone, the PCB inputs
  not connected): the 21-byte configuration block round-trips, self-cal
  takes 0.3 s, the pacing clock grants exactly 1000.000 Hz, a 60 s callback
  stream delivered 60 000 scans in 60.00 s with 0 pool events, 0 leftover
  bytes and 0.4 % CPU in the consumer thread; the driver's end-of-stream
  flag arrives after `ADC_BulkContinuousEnd`. The conversion-slot check on
  floating inputs shows slot 0 off by up to 34 counts (typically 2-7), so
  dropping the first conversion after each multiplexer hop stays. Numbers
  in CALIBRATION_RECORD section 6.
- **Probe fix:** the cal-mode GROUND reference reads exactly code 0 on a
  unipolar range (it clips), so `floor` now uses the onboard full-scale
  reference through the same path (`--floor-source ground` kept for
  bipolar ranges). Instrument floor at the production settings: raw rms
  about 54 uV (0.7 LSB), judged-band window pk-pk median 49 uV, worst
  channel 79 uV.
- Still open on the bench: the -HG scaling check (known voltage on CH0
  with the PCB) and crosstalk (a source on one channel) - section 4b.3.
- `engineer_tools/array_noise_parity.py` - pairs a typed legacy data sheet
  (`sensor_id, legacy_noise_mv[, position, tray]`) with the array rig's lot
  CSV or tray `.npz` captures, fits the legacy chain factor (median ratio
  and regression through origin, on the worst-window and median-window
  metrics), counts how many parts the proposed window classifies like the
  legacy window, replays other bands from the captures (`--replay-band`),
  writes `calibration/parity_<date>.csv|.png` and prints the proposed
  `NOISE_PP_LIMIT_LOW/HIGH_MV`. Never edits the app.
- `engineer_tools/replot_noise_capture.py` understands the array rig's 2-D
  tray captures: each loaded position becomes a capture named
  `tray_<n>_<position>`, `--position` / `--channel` select channels,
  `--model 40623` scans the array root, and captures without a limit show
  "no limit" instead of a verdict. Replays reproduce the tester's numbers
  (the same math on both rigs).
- Tests: `array_rig/m40623/tests/test_engineer_tools_array.py` (parity on
  a synthetic lot with a planted factor, lot-CSV input, tray+position
  fallback, replay band; replot splitting and agreement with the tester's
  numpy port). 40623 array suite: 134; total 598.

## Array rig: 40623 tester, selector, launchers, docs (2026-09-02)

The array rig is complete for offset + noise per TP120 (sensitivity waits
for the emitter board). CALIBRATION PENDING throughout.

- `array_rig/m40623/eltec_40623_array_tester.py` - the model application.
  Tk-free core (`TrayController`, the tests drive it) + Tk GUI. Flow: Start
  lot (connect, configure, self-calibrate) -> Load & offset (offsets polled
  at 2 Hz; parts over 1.2 V or railed turn RED immediately so they are
  pulled before the capture; ~0 V tiles are yellow until the technician
  marks them EMPTY or LOADED; low reads are amber, not a verdict) -> Lock
  tray (occupancy frozen, sensor numbers assigned row-major over the loaded
  positions continuing the lot, the HO parts' FAIL rows written now) ->
  Noise (TP120 5-minute stabilisation countdown, skippable with the actual
  wait recorded; adaptive 3-20 s quiet wait; 60 s capture of all fifty
  channels at 1000 scans/s plus 310 samples of real context each side;
  stream integrity checked, retried up to twice, else NOT MEASURED rows) ->
  Judged (settled offset = mean of the last 2 s is the offset verdict;
  noise per channel in the single rig's band; tiles coloured) -> Save (one
  CSV row per position, raw `.npz` of the tray, grid `.png`, tray events) ->
  Re-measure / Next tray. Disabled "Sensitivity" step and a `drive` slot
  mark where the emitter board plugs in. `--simulate` /
  `ELTEC_ARRAY_SIMULATE=1` run on `SimulatedDaq`; `ELTEC_ARRAY_RESULTS_ROOT`
  redirects the results folder for engineering runs.
- `array_rig/eltec_array_tester.py` + `sensor_versions.py` (selector and
  registry, mirrors of the single rig's; `REQUIRED_HARDWARE` instead of
  firmware), `array_rig/tray_history.py` (tray-event log + numbering
  helpers), launchers/installers with the identities `eltec-array-rig` /
  `com.eltec.array-rig.desktop` / "Eltec Array Rig" and `eltec-40623-array`
  / `com.eltec.40623-array-tester.desktop` / "Eltec 40623 Array Tester"
  (derived from the single rig's templates), icons, `array_rig/README.md`
  and `array_rig/m40623/README.md`.
- Results: `Documents/Eltec_40623_Test_Results/40623_array_daq/`
  (`40623_array_lot_<lot>.csv`, `_attempts.csv`, `noise_captures/lot_<lot>/
  tray_<n>_raw.npz`, `grid_snapshots/lot_<lot>/tray_<n>.png`). CSV columns
  documented in the model README; older files keep their header. Every row
  and capture carries `calibration_status = PENDING`, `calibration_id =
  40623_array50_daq_PENDING`, `verdict_status = PROVISIONAL`, the DAQ
  settings and the stream diagnostics.
- Tests: `array_rig/tests` (selector glue, tray history: 31) and
  `array_rig/m40623/tests/test_array_tester.py` (paths, CSV header
  compatibility, numbering, lock, noise phase with retry and rig-fault
  paths, save, re-measure, limits-defined colouring, GUI smoke; results
  root redirected to a temporary directory with a guard that nothing lands
  under Documents). `run_all_tests.py` now runs six suites: 38 / 175 / 109 /
  111 / 31 / 128 = 592.
- Docs: README (two rigs), CLAUDE.md (rule 1 extended across rigs, six-suite
  baseline, array easy-to-get-wrong items), CALIBRATION_RECORD (§1 array
  mini-table, new **§4b** with every 40623 constant, the TP120 numbers
  verbatim, the derivation plan and the open hardware questions, §6 DAQ
  rows), DATA_MAP (root, layout, tools, backup), ENGINEER_HANDOVER (array
  chain and layout, cross-rig policy, tests, paired-lot procedure, probe,
  open work), TECHNICIAN_RUNBOOK (which rig, **§3b** run a tray,
  troubleshooting, do-nots).
- Bench spike on the real DAQ (probe `info -> selfcal -> config -> scan ->
  slots -> floor -> stream 60 -> crosstalk`) and
  `engineer_tools/array_noise_parity.py` follow in the next commits.

## Array rig: noise analysis port and provisional verdict model (2026-09-02)

`array_rig/m40623/array_analysis.py` - pure math, no I/O.

- The 405 M22 build's emitter-off noise pipeline (Kaiser anti-alias FIR,
  decimate 1000 -> 50 SPS, per-1-s-window least-squares detrend, windowed
  pk-pk with the clip rule re-checked on the raw window, `<=` with the
  1e-12 boundary tolerance) re-expressed in numpy for fifty channels at
  once. Tap values are computed with the same scalar arithmetic so they
  are identical; the rest agrees with the pure-Python original to ~1e-15
  relative. A full 50-channel x 60 s tray analyses in 0.3 s (the original
  would take tens of seconds per tray).
- The original functions are FROZEN verbatim in
  `array_rig/m40623/tests/golden_noise_reference.py` (copied from
  `single_detector_rig/m405m22/stability_analysis.py` at commit d7526b5)
  and used as the oracle by `test_array_analysis.py`; a drift test
  compares that copy with the live 405 module so a change on either side
  is noticed. No code is shared between the two rigs.
- Model 40623 (TP120 rev W) constants with provenance comments: offset
  0.3-1.2 V (PROVISIONAL: PCB loading vs fixture 9000054 unconfirmed),
  +/-0.05 V settle rule, 0.05 V dead floor, 4.9 V rail; legacy noise
  limits 10.0-37.9 mV recorded as what they are (DMM readings behind
  amplifier 9000232 + rectifier-hold 9000272) and the pin-level limits
  `None` until a paired lot derives the chain factor. With `None` limits
  every noise verdict is NO_LIMIT: measured and recorded, never a
  failure. The 405's 15 %-of-windows rule is carried as a structural
  default and marked re-decide.
- Verdict model with enums and structured `FailReason`s (no string-prefix
  sniffing): offset classes OK / HO / HO_RAILED / LO / DEAD / EMPTY (only
  HO and railed fail fast at insertion - offsets settle upward), noise
  verdicts PASS / HIGH (> max_over_fraction of windows over the high limit
  or clipped) / LOW (MEDIAN window pk-pk under the low limit, so one bang
  cannot revive a dead crystal) / NO_LIMIT, position verdicts with the
  precedence EMPTY -> NOT_MEASURED -> FAIL_OFFSET -> FAIL_NOISE_HIGH ->
  NOISE_LOW -> PASS, TP120 failure-mode tags (HO, LO, SH, D, N, NL, NM),
  tile states for the grid, the adaptive quiet-wait rule (never a
  verdict). Every result is stamped calibration_status PENDING,
  calibration_id `40623_array50_daq_PENDING`, verdict_status PROVISIONAL.
- `daq_bench_probe.py floor` and `crosstalk` now report judged-band
  worst/median pk-pk per channel through this module.

## Array rig: DAQ backend, simulator and bench probe (2026-09-02)

First code of the 50-position array rig (`array_rig/m40623/`, model 40623
per TP120). Nothing here issues a verdict yet; this commit is the hardware
boundary and the tool that proves it on the bench.

- `daq_backend.py` - `ctypes` wrapper over the ACCES `AIOUSB.dll` (cdecl,
  Win32 status returns; prototypes from the shipped `AIOUSB.cs`). Fixture
  geometry (`row-col` labels, CH = (row-1)*10 + (col-1)), the range-code
  table with OWN counts-to-volts scaling (never `ADC_GetScanV`, in case the
  unit is a `-HG` variant), the 21-byte configuration block
  (`AdcConfig`, one range on all sixteen 4-channel groups, timer+scan
  trigger 0x05, contiguous scan 0-49, hardware oversample), the bulk byte
  stream de-interleaver (partial-scan carry-over, drop the first conversion
  after each multiplexer hop, average the rest), `StreamDiagnostics` with
  the 1 % scan-rate rule and the driver's "buffer pool exhausted" flag as
  an integrity failure, connect retries while the device re-enumerates
  after its host-loaded firmware, the callback stream
  (`ADC_BulkContinuousCallbackStart` + the 8254 pacing clock; callback only
  copies and enqueues, a consumer thread de-interleaves) and a one-shot
  `ADC_BulkAcquire` fallback. `SimulatedDaq` mirrors the same surface with
  a profiled tray (HO, railed, LO, dead, empty and bursty positions, upward
  offset settling) and injectable stream faults.
- `daq_bench_probe.py` - engineering CLI: `info`, `selfcal`, `config`,
  `scan` (own volts next to the driver's: the -HG check), `slots` (per
  conversion-slot means: is slot 0 the unsettled one?), `floor` (cal-mode
  GROUND = instrument noise), `stream`/`capture` (rate, pool events,
  leftover bytes, CPU; optional raw `.npz`), `crosstalk`; `--simulate` and
  `--oneshot`.
- Production acquisition constants (defaults in both files, explained in
  the tester when it lands): range 0-5 V (76.3 uV/LSB), 1000 scans/s per
  channel, oversample 3 with the first conversion dropped, 64 000-byte
  buffers x 32 -> 200 kS/s aggregate and 400 KB/s over USB (40 % of each
  ceiling).
- Tests: `array_rig/m40623/tests/test_daq_backend.py` (55 cases against a
  scripted fake DLL and a fake clock: block encoding, carry-over at
  arbitrary split points, scaling for every range code, connect retry and
  timeout, read-back mismatch, callback flags and unaligned buffers,
  recorded callback errors, rate check, bulk one-shot, simulator profile).
  `run_all_tests.py` runs it as the fifth suite ("40623 array"); the four
  existing suites are unchanged.
- Bench spike still to do (next entry): `info -> selfcal -> config -> scan
  (known voltage) -> slots -> floor -> stream 60 -> crosstalk` on the real
  DAQ, numbers into `docs/CALIBRATION_RECORD.md`.

## Repository split: single_detector_rig/ + array_rig/ (2026-09-02)

A second test rig is being added: a 50-position detector array (5 rows x 10
columns, one unity-gain buffer per position) read by an ACCES I/O
USB-AIO16-64MA DAQ-PACK, testing offset and noise per TP120 (model 40623)
with an emitter board to follow. The repository now has one top-level
folder per rig; everything they share (firmware, docs, engineer tools,
analysis, assets, the test runner) stays at the top level.

- `tech_app/eltec_rig/` -> **`single_detector_rig/`** (`git mv`, history
  preserved); the now-empty `tech_app/` was deleted. Nothing inside the
  moved tree changed except path text. `array_rig/` arrives in the next
  commits.
- Path references updated: `run_all_tests.py` (the four suite paths; labels
  unchanged), `engineer_tools/replot_noise_capture.py` and
  `emitter_waveform_comparison.py` (`sys.path` inserts), the two 406 MCA
  tests that import the package by name (`single_detector_rig.m406mca`), a
  comment in `m406mca/esp32_backend.py`, and the selector's
  `install_xubuntu_launcher.sh` (its `REPO_ROOT` message climbed two levels
  for a package that is now one level below the root). Docs: `README.md`,
  `CLAUDE.md`, all four `docs/*.md`, the four app READMEs, the noise
  filtering report, `Arduino/Eltec/README.md`, both wiring notes and
  `Arduino/Eltec/versions/README.md` (its two path mentions only - the
  firmware snapshots themselves are untouched).
- Deliberately NOT edited: the `tech_app/v4_emitter` comment in
  `Arduino/Eltec/Eltec.ino` and in every frozen `versions/*/Eltec_v*.ino`
  (hard rule: snapshots are byte-frozen and `Eltec.ino` must stay identical
  to the newest one). Historical paths in this file and in the "History"
  paragraph of `single_detector_rig/README.md` are history and stay as
  written; `archive/pre-cleanup-2026-08-28:tech_app/...` tag paths remain
  valid.
- Evidence added to the repository: `docs/TP120(40623).pdf` (the 40623 test
  procedure, rev W) and `docs/daq_usb_aio16_64ma/` (the DAQ datasheet,
  DAQ-PACK M-series guide, letter of volatility and vendor links).
  `.gitattributes` now marks `*.pdf` binary.
- **Bench PCs: the installed desktop shortcuts point at the old path.**
  Re-run `single_detector_rig\install_windows_launcher.ps1` (Windows) or
  `single_detector_rig/install_xubuntu_launcher.sh` (Xubuntu) once; the
  remembered sensor-version selection is unaffected.
- No behaviour, threshold, CSV or firmware change. Tag
  `archive/pre-array-rig-2026-09-02` marks the tree before the move.
  `python run_all_tests.py` after the move: glue 38, 405 M22 175 (4
  skipped), 406 MCA 109 (the two known Windows-only cases), 449 M18 111 -
  identical to before.

## Live viewer: sync-locked cycle-average panel (2026-08-31)

`Arduino/Eltec/live_waveform.py` — the 449 M18 detector's ~20 mV response at
18 Hz / 20 % sits under a ~50 mV broadband white noise floor (measured by
spectrum on the day's captures: flat ~1 mV/√Hz to ~50 Hz, no mains lines),
so the rolling trace shows hash and the response is invisible live. For
white noise the optimal viewer is averaging, so the viewer now has an
oscilloscope-style average acquisition mode:

- A third panel folds the last N drive cycles (default 64, `--fold-cycles`,
  0 hides the panel) on the firmware sync bit's rising edges and draws the
  mean cycle ±1σ, with the mean-cycle pk-pk in the title. Noise on the
  average falls with √N (64 cycles ≈ 8×; ~3.5 s of history at 18 Hz).
  Cycles are resampled between their own edges, and timestamps are
  modularly unwrapped, so PWM phase restarts and the uint32 micros()
  rollover cannot smear the fold. Needs the ESP32 drive (sync edges); with
  an external drive the panel shows a hint instead.
- The fold uses the whole `--max-window` history buffer, not just the
  displayed window; the rolling trace and sync strip are unchanged (their
  x-axes are now linked explicitly rather than via sharex).
- Viewer-only change - no firmware, threshold or measurement behaviour
  touched. Verified offline (Agg): fold recovers a 12.8 mV synthetic
  18 Hz / 20 % response from 25 mV rms noise, is bit-identical across a
  uint32 timestamp wrap, returns None with no edges; a scripted-stream
  headless run exercises update() in both the 3-panel and `--fold-cycles 0`
  legacy layouts.

## Bench tools: `--duty` on the live viewer, `set_pwm_duty` on the wrapper (2026-08-31)

`Arduino/Eltec/live_waveform.py --duty <percent>` — the bench scope could set
the drive frequency but not the duty cycle, so the 449 M18's 20/80 drive
(TP443 blade equivalent) could not be watched live; only the production app
issued `PWM,DUTY`. Looking at an 18 Hz / 20 % waveform meant running a test.

- `Esp32Rig.set_pwm_duty(percent)` added to `Arduino/Eltec/esp32_rig_readout.py`
  (1–99 %, firmware v3.2+, refuses older builds with a re-flash instruction and
  reports the version found). It mirrors `set_pwm_frequency`: range-checked
  host-side, `PWM,DUTY,<pct>` on the wire, `pwm_duty_percent` tracked on the
  object. Duty survives a later `PWM,FREQ`, and the firmware restarts the PWM
  phase, so the change is clean even mid-drive.
- The viewer applies `--duty` whether or not it starts driving (like `--freq`),
  so a later SPACE toggle uses it, and shows the drive in the plot title and
  the stats box. Out-of-range values and pre-v3.2 boards exit with the message
  instead of a traceback, after the port is closed cleanly.
- The board boots at 50 % and nothing persists, so the 405 M22 and 406MCA
  drives are untouched unless `--duty` is passed. No firmware, threshold or
  measurement behaviour changed — bench viewing only.
- Verified offline against a scripted v3.2 board emulator: `PWM,FREQ,18` then
  `PWM,DUTY,20` then `PWM,ON`, title reads "18 Hz / 20% duty"; a v3.1 board
  exits with the flash instruction; `--duty 0` is rejected host-side before any
  serial IO. The bench board may still be on v3.1 — flash with
  `python Arduino/Eltec/flash_firmware.py` before using the flag.

## Live waveform viewer: the time window is now adjustable while watching (2026-08-31)

`Arduino/Eltec/live_waveform.py` — the rolling window was fixed at launch by
`-w`, so seeing more (or less) time meant closing the plot, restarting the
stream and losing the trace under inspection. It can now be changed live:

- `]` / `+` widens, `[` / `-` narrows, and the new **Window** button next to
  the Emitter button steps up and wraps. Rungs are 0.25, 0.5, 1, 2, 4, 6, 8,
  10, 15, 20, 30, 45, 60 s, plus whatever `-w` was launched with, clamped to
  `--max-window`. The current setting shows in the button and the plot title.
  The sub-second rungs are for the fast drives — 0.25 s is ~4 cycles of an
  18 Hz signal, where the 4 s default packed in 72 and showed only a band.
- The reader's history buffer is now sized from `--max-window` (default 60 s)
  instead of the starting window, so widening shows real samples. It cannot
  invent history: samples older than the window in force were never buffered,
  so a freshly widened plot fills in from the left over the next seconds.
- `-w` is unchanged as the STARTING window (still auto-widened to ~6 cycles
  for a drive below 2 Hz); `--max-window` raises the ceiling and the memory
  the buffer holds (60 s ≈ 75 k samples at 1 kS/s).

No firmware, threshold or measurement behaviour changed — this is a viewer
control only. Verified offline against a synthetic 1 kS/s stream (Agg
backend): each key press moves one rung, clamps at both ends, and the plotted
span and x-limits follow it.

## New engineer tool: legacy-chopper vs rig-emitter waveform comparison (2026-08-31)

`engineer_tools/emitter_waveform_comparison.py` — pre-qualification check
for the 449 M18 app's 18 Hz drive: can the rig's miniature blackbody
emitter (a resistor that must heat/cool every cycle) reproduce the detector
waveform shape the legacy fixture's blackbody + 20/80 chopper blade
produces, or does its thermal time constant round it off?

- `capture --setup legacy` streams AIN0 with the rig PWM forced OFF while
  the LEGACY fixture drives the detector (rig used purely as a recorder;
  detector signal -> AIN0, detector ground -> rig AGND is the one required
  common-ground connection). `capture --setup rig` drives the qualified
  18 Hz (or 5 Hz) / 20 % emitter PWM via the production m449m18 backend,
  waits a thermal warm-up, then streams; the per-sample sync bit gives
  exact cycle edges and the PWM-ON -> detector-peak thermal lag.
- `compare` folds each capture cycle-by-cycle on its own boundaries (sync
  edges when present, fundamental zero-crossings otherwise — a chopper
  motor drifts), normalises the mean cycle to unit pk-pk (amplitude is
  deliberately ignored) and reports 10-90 % rise / 90-10 % fall, width at
  50 %, H2..H5/H1 harmonic ratios, and shape correlation / RMS residual
  against the reference capture, plus an overlay plot.
- Captures land in `~/Documents/Eltec_EmitterComparison` — a new
  engineering-experiment folder, never the `Eltec_*_Test_Results`
  evidence folders. Analysis verified end-to-end on synthetic data (sharp
  25 % trapezoid vs 12 ms-tau first-order lag: rise 1.4 -> 8.5 ms,
  corr 0.886, lag 10 ms recovered).
- Needs firmware v3.2 on the board (backend refuses older at connect);
  the bench board may still be on v3.1 — flash with
  `python Arduino/Eltec/flash_firmware.py` first.
- Same-day usability fix: `compare` with no paths now auto-picks the
  newest `*_legacy_*` capture (reference) and the newest `*_rig_*` capture
  from the default folder and prints what it chose — the placeholder-style
  `compare <legacy.npz> <rig.npz>` example was a PowerShell parser error
  when pasted verbatim, and PowerShell does not expand globs either.

## 405 noise pipeline hygiene + the legacy amplifier measured (2026-08-31)

Follow-up to the 2026-08-31 audit of the noise verdict chain (implementation
verified correct end to end; these are the defects it surfaced). Archived
captures are unaffected — every no-context replay is bit-identical — but
LIVE captures now judge their first/last window with the anti-alias filter
seated on real samples, so a bench re-run on a known part is due before
trusting new edge-window counts near the limit.

- **Edge context for the anti-alias FIR** (the one filtering change):
  `decimate_antialiased` accepts real neighbour samples as filter history;
  reflection padding had let out-of-band interference into judged windows
  0/19 at only ~11–21 dB (vs ≥ 60 dB interior; ≤ 1.4 % effect on all 14
  archived captures). The tester streams 0.31 s extra and seats the FIR on
  the quiet-wait tail (left) + extra samples (right); both slices are
  archived in new `left_context_v`/`right_context_v` NPZ arrays so saved
  captures replay to the live verdict; `replot_noise_capture.py` honours
  them when present.
- **Soak FAIL message fixed**: `apply_noise_gate` computed "allowed" from
  the fixed 15 % and told a 60 s soak FAIL "allowed 9"; it now reports the
  allowance the capture was judged with, and
  `NoiseCaptureReport.max_over_percent` records it (was hard-wired to 15 %).
- `analyze_noise_capture_band_limited`'s `threshold_mv`/`max_over_fraction`
  are now REQUIRED — the old defaults were the withdrawn 75 µV / 20 %
  limits and a new caller that omitted them silently got a retired gate
  (production always passed the constants explicitly). Hand-ported with the
  edge-context change to the dormant m449m18 copy per the porting procedure
  (m406mca has no noise code).
- Stale text swept: five "75 µV" comments → ~429 µV; the live-preview
  comment no longer claims the boxcar preview is the verdict trace; in-app
  help no longer says noise runs after the driven capture nor that the AIN1
  gate is active; "same passband as the boxcar" corrected (same 22 Hz
  passband *edge*; the FIR's −3 dB corner is 24.4 Hz, so the verdict band
  is 0.852–24.4 Hz); the calibration record's noise-row line pointers
  re-reconciled; the clip row's "condemns its ringing neighbour" reworded
  as the emergent effect it is.
- `docs/CALIBRATION_RECORD.md` §2.2 addendum: the legacy amp's frequency
  response was measured (band-pass ×4140 peak at ~1.4 Hz, −3 dB
  0.46–4.1 Hz; nameplate = midband gain; bandwidth still cannot explain
  700 — the residual is a frequency-flat ~3–6×, prime suspect
  source-impedance loading; verification measurements listed). **User
  decision recorded: verdict-level agreement with the legacy fixture is the
  acceptance criterion; the scalar 700 and the judged band stay.**
- Tests: 38 / 175 / 109 / 111 (was 38 / 174 / 109 / 110) — new
  edge-context coverage in both models, soak-message and context-plumbing
  assertions in the 405 integration suite.

## Workspace reorganised for handover (2026-08-28)

- Committed the outstanding work that had only existed in the working tree:
  firmware v3.1/v3.2 snapshots, `flash_firmware.py` and its wrappers, the
  whole 449 M18 tester, the 405/406 GPIO33 backend updates and the
  noise-filtering report.
- Tagged `archive/pre-cleanup-2026-08-28`, then removed from the working tree:
  `tech_app/deprecated/` (v1–v4 LabJack apps, v5/v6/v6.1 ESP32 apps, the
  standalone `405m22_esp32` build, the `eltec_rig_v1` snapshot), the
  LabJack-era `analysis/v1_single_sensor`, `v2_scope_verification`,
  `v3_emitter`, `v4_emitter` scripts, `engineer_tools/eltec_406mca_signal_monitor*`,
  `Arduino/Eltec/siggen_rig_readout.py` and the historical
  `ESP32_ADS1256_Wiring.docx`. Nothing active imported from them
  (205 → 94 tracked files). All four test suites unchanged: 38 / 174 / 109 / 110.
- New documentation set for handover: the root `README.md` rewritten as the
  hub (it still described the LabJack-era 406MCA-only setup);
  `docs/CALIBRATION_RECORD.md` (every constant with provenance — extracted
  from the frozen reference block of the old `status.md`),
  `docs/TECHNICIAN_RUNBOOK.md`, `docs/ENGINEER_HANDOVER.md` (incl. the
  copy-per-model policy and the fix-porting procedure), `docs/DATA_MAP.md`
  (out-of-repo results + backup routine); `Arduino/Eltec/README.md` replaces
  the stale `ESP32_memory.md`; `ESP32_ADS1256_Wiring_v1_7.md` renamed
  `ESP32_ADS1256_Wiring_legacy_v1_9.md`; `status.md` became this file (its
  undated reference block, which contradicted the entries above it on
  firmware version, stability threshold and noise limit, was retired after
  extraction); `CLAUDE.md` added; stale pre-unification paths fixed in the
  model READMEs.
- Hygiene: `run_all_tests.py` (+ `.cmd`/`.sh`) runs all four suites;
  `.gitattributes` line-ending policy; `.gitignore` rules for results and
  captures; the 406 MCA model gained the Windows launchers the other models
  had; stale "v3.0 baseline" comments and the `EMITTER_PWM_CHANNEL` label
  (GPIO25 → GPIO33) fixed in the 405/406 testers.

## 449 M18 frequency-tracking tester + firmware v3.2 `PWM,DUTY` (2026-08-26)

New sensor version in the unified app: **Model 449 M18 (5 Hz + 18 Hz,
TP443)** — `tech_app/eltec_rig/m449m18/`, selectable from the dropdown.

- **Test**: TP443 "449M18 Frequency Tracking" — sensitivity at 5 Hz and at
  18 Hz, both with the legacy fixture's 20/80 blade duty, then the 18/5
  ratio (specs 1–3) and the spec-4 "measure the tray 100 %" flag (ratio
  ≤ 0.72 or a sampled failure). Both drives run back to back per part.
- **Calibration pending**: an electrically pulsed emitter does not modulate
  equally at 5 and 18 Hz, so each frequency needs its own fixture factor
  (`K_5`, `K_18`, paired comparison like the 405's lot-500). Until then
  `SENSITIVITY_GATE_ENABLED = False`: every reading + the raw ratio is
  recorded, the limits are not enforced, and every verdict is stamped
  CALIBRATION PENDING. The offset band is also not gated (TP443 offset page
  not available; placeholder 0.3–3.0 V behind `OFFSET_GATE_ENABLED`).
- **18 Hz sampling**: 55.56 samples per cycle at 1000 SPS — sync validation
  judges the mean cadence (single cycles get a one-sample allowance) and
  stability is judged on blocks of 9 cycles (= 500 samples exactly) so the
  robust peak is repeatable; the 36-cycle window is 4 blocks.
- **Firmware v3.2** (`Arduino/Eltec/Eltec.ino`, archived as
  `versions/Eltec_v3_2/`): `PWM,DUTY,<pct>` (1–99 %, boot default 50 %,
  not persisted) + `pwm_duty` in `STATUS?`. Compiles (290 KB / 22 %).
  **Not yet flashed or bench-verified** — the 449 backend refuses < v3.2,
  the other two models keep working on v3.1. Flash with
  `python Arduino/Eltec/flash_firmware.py`, then confirm `IDN? -> v3.2`
  and `PWM,DUTY,20` -> `OK,PWM,DUTY,20.0`.
- **Tests**: `m449m18/tests` (integration, backend, stability, calibration
  CLI) plus the rig glue/attempt-history suites now cover three models; the
  405/406 suites are untouched.
- **Open**: derive `K_5`/`K_18` (30–50 parts, both fixtures), fill the TP443
  offset band, confirm the 449's polarity convention on the bench (the
  POSITIVE gate is applied at both frequencies, `POLARITY_GATE_ENABLED`),
  and revisit the 0.100 mV peak-delta threshold once real raw amplitudes
  are known.

## Emitter gate moved to GPIO33, firmware v3.1 (2026-08-25)

The emitter PWM/gate output moved from **D25 (GPIO25)** to **D33 (GPIO33)**.
The perf-board wire to the dual-MOSFET module's PWM/TRIG input must move with
it - a board still wired to D25 drives nothing until the wire is moved (or the
host sends `PIN,25`, which the firmware still accepts).

- **Firmware** `Arduino/Eltec/Eltec.ino`: `pinGate = 33`, IDN bumped
  `v3.0 -> v3.1` per the sketch's own rule that every flash-relevant change is
  detectable over serial. Nothing else changed - `PIN,<n>` (2/12/13/14/25/26/
  27/32/33) still retargets at runtime and is not persisted, and GPIO33 gets
  the same RTC-hold release at attach that GPIO25 did. GPIO33 is RTC-capable
  but is NOT a DAC pin (only 25/26 are), so there is no DAC path to detach.
  Archived as `versions/Eltec_v3_1/`.
- **Both host backends**: `PWM_GPIO = 25 -> 33` in `m405m22/esp32_backend.py`
  and `m406mca/esp32_backend.py`. Because each backend already sends
  `PIN,{PWM_GPIO}` after connect, the app - not the boot default - is what
  actually selects the pin; the two now agree. Tests updated to expect
  `PIN,33`.
- **Docs**: `ESP32_ADS1256_Wiring_v2_0.md` (the current guide) and the live
  statements in `ESP32_memory.md` now say D33; the D25-era troubleshooting
  history in that file is left intact and labelled as history.
  `ESP32_ADS1256_Wiring_v1_7.md` is unchanged - it documents the v1.9 legacy
  406MCA rigs, which still gate on D25.
- **Verified on the bench**: flashed COM3, `IDN? -> ELTEC-ESP32-ADS1256,v3.1`,
  `GATE? -> pin=33,drive=0,read=0` at boot, `GATE,ON -> drive=1,read=1` (pad
  readback confirms the pin really drives), `PIN,33` + `PWM,FREQ,1` + `PWM,ON`
  -> `STATUS,pwm=1,pwm_hz=1.000`.
- **`flash_firmware.py`**: new one-command flasher so the sketch can be
  uploaded without the Arduino IDE - it finds the IDE's bundled `arduino-cli`,
  auto-detects the CP210x port, compiles, uploads, then confirms `IDN?` and
  `GATE?` over serial. `--sketch versions/Eltec_v2_2` puts the board back on
  any archived build.
- **Not changed**: the frozen apps under `tech_app/deprecated/` still send
  `PIN,25` and are pinned to older firmware, so a legacy rig keeps its own
  wiring.

## Near-limit sensitivity is a PASS with a warning, both models (2026-08-25)

The `+/-0.10 mV` raw band around the sensitivity limit (405 M22: `1.29-1.49
mV` raw on -625, `~5.99 mV` legacy; 406 MCA: `2.43-2.63 mV` raw, `~4.0 mV`
legacy) used to produce a `RETEST / QUARANTINE`
verdict with its own failure mode and *Save Quarantine* buttons. A reading in
that band is within the margin of error of the `x4.30` conversion factor, so
the app now treats it the way production wants: **the sensor passes**, the
result page shows the green `PASS · NEAR LIMIT` banner plus an amber card
("Passed - sensitivity near the limit ... Suggestion: Re-measure to confirm.
No quarantine is needed - if you move on, this sensor is saved as a PASS"),
the status line says the same, and the normal *Save + Next Sensor* / *Save +
Exit Batch* buttons record a plain `PASS` row. Re-measure stays one click
away in the footer. Code-wise the band is `SENSITIVITY_NEAR_LIMIT`
(`sensitivity_gate_outcome`, still written to the `sensitivity_gate_outcome`
CSV column so the record shows which passes were near the limit); the note
goes to `FinalResult.warnings` instead of `fail_reasons`; `OUTCOME_RETEST`,
the `RETEST - Sensitivity guard band` failure mode, the RETEST summary chip
and the quarantine footer labels are gone. Older batch CSVs that still carry
`RETEST` rows are shown as failures in the summary (they were quarantine
records, not passes). Same change in `m405m22/` and `m406mca/`. 405 M22: 174
tests OK; 406 MCA: 78 with the three long-standing Windows-only environment
errors; unified app: 33 OK.

## Eltec Test Rig v2.0: Skip part, footer Re-measure, attempt history (2026-08-24)

Technician-UI update to `tech_app/eltec_rig/` (both models, same code in
`m405m22/` and `m406mca/`), plus a repository tidy-up:

- **Footer is now the action bar**: Back · Measure skipped (N) │ Skip part
  (amber) · Re-measure (blue outline, moved out of the small tools row) ·
  Save + Exit Batch · **Save + Next Sensor (green)**. Buttons are one size
  larger (`xl`); `RoundButton` gained `success` / `warn` palettes.
- **Skip part** (load or result step): reason dropdown + optional note, then
  the next fresh number loads. The skipped id is NOT spent — the next fresh
  number is derived from the batch CSV AND the attempt log, so a part can
  never be counted twice. Skipped parts form a first-skipped-first-measured
  pile: **Measure skipped (N)** lists the ids in order and loads the first;
  after each save the next skipped id loads automatically until the pile is
  empty, then fresh numbering resumes. Re-skipping sends a part to the back.
  The batch summary and the batch-start status line show what is still
  skipped. The rig-fault view keeps "Record as NOT MEASURED".
- **App renamed "sensor tester" (2026-08-25)**: the header now reads
  `405 M22 SENSOR TESTER` / `406MCA SENSOR TESTER`, the 406 window title is
  "Eltec 406MCA ESP32 Sensor Tester v6.1", and both Xubuntu desktop entries
  say "Adaptive Sensor Tester" (the 406 `Comment=` also said it tests
  "emitters" - now "sensors", matching the 405 entry). Hardware references
  are untouched on purpose: `EMITTER_PWM_*`, the emitter-off noise test, the
  emitter-health/reference wording and the header's "EMITTER RIG" subtitle
  all still describe the fixture's chop source. The internal class name
  `EmitterTesterApp` is unchanged (code only, never displayed).
- **Footer never clips again (2026-08-25)**: full screen on Windows, the
  v2.0 action bar's rightmost button (*Save + Next Sensor*) ran past the edge
  of the content column - it needs ~1715 px where a maximized 1920 screen
  leaves 1490 (the step rail, divider and padding take the rest; a 1366
  screen or 150% scaling is worse). The bar is now two groups (nav left,
  actions right) and `_fit_footer` measures the visible buttons against the
  real width, then takes the first `FOOTER_VARIANTS` step that fits: full
  labels -> drop the `(Enter)`/`(Esc)` hints -> compact wording (*Save +
  Next*, *Save + Exit*, *Skipped (3)*) -> wrap the actions onto a
  second row at full size -> shrink the buttons. Bound to the footer's
  `<Configure>`, so it re-fits (and recovers) on maximize/resize and adapts
  to Xubuntu's font metrics without a hardcoded width. `RoundButton.restyle()`
  re-sizes a button in place. Both models; 6 new tests each (405 M22: 174 OK,
  406 MCA: 109 with the two long-standing Windows-only environment failures).
- **Selector opens maximized (2026-08-25)**: `eltec_rig_tester.py` now
  starts full screen the same way the model testers do (`zoomed` on Windows,
  `-zoomed` after mapping on X11, screen-sized geometry as a fallback) and
  re-applies it when a tester exits and the selector un-minimizes. It had to
  become resizable for that (a fixed-size window cannot be maximized), so
  the content block is centered by weighted spacer rows/columns and its type
  is one step larger; 640x520 minimum. Selector suite 33 tests OK.
- **Same-day follow-ups**: (a) the skip dialog is comment-only (no reason
  dropdown); (b) **406 MCA reference gate disabled** (`REFERENCE_GATE_ENABLED
  = False`, same mechanism/card text as the 405 M22 build) because the
  op-amp crosstalk made the reference uncalibratable — flip back to True and
  recalibrate once the channel-isolated op-amp board is in; the gate code is
  kept and tested with the flag forced on; (c) **shorted/dead sensor**: a
  floating AIN0 now raises `NoSensorDetectedError` and the app asks "Is a
  sensor loaded?" — Yes records a FAIL (no offset, failure mode preset to
  "SB - Sensor bad") that the technician saves normally; No keeps the old
  "nothing recorded" path. Both models.
- **Attempt history**: new shared `eltec_rig/attempt_history.py` writes
  `<lot>_attempts.csv` next to each batch CSV — one row per `measured` /
  `measure_error` / `remeasure` / `skipped` / `resumed` / `saved` event with
  the verdict, offset, sensitivity, polarity, noise worst pk-pk, fail
  reasons, reason and note. Verdict rows gain trailing `measure_attempts`
  and `skip_count` columns (older batch files keep their header).
- **Deprecated folder**: `tech_app/405m22_esp32`, `v6_1_esp32`, `v6_esp32`,
  `v5_esp32`, `v1_single_sensor`, `v2_scope_verification`, `v3_emitter`,
  `v4_emitter`, `v6_1_failure_calibration` moved (git mv, contents unchanged)
  to `tech_app/deprecated/`, plus `deprecated/eltec_rig_v1/` = snapshot of
  the unified app before this change. `engineer_tools/eltec_406mca_signal_monitor*.py`
  and `analysis/v1_single_sensor/test_406mca_analysis.py` repointed at the
  new v1 path; firmware `versions/README.md` paths updated.
- **Tests**: `eltec_rig/tests` 31 (17 glue + 14 new attempt-history / skip
  flow for both models); `m405m22` 166 OK (4 skipped); `m406mca` 99 with the
  same two Windows environment-only failures as before. Both real Tk apps
  were driven through skip → measure → re-measure → save → measure skipped
  in simulator mode without error.

## 405 M22 noise verdict: anti-alias FIR replaces the boxcar (2026-08-20)

The noise gate's band-limiting step had a real aliasing defect, found while
characterizing the pipeline's effective passband (the verdict is judged over
~0.85–22 Hz: the per-window detrend is a high-pass with −3 dB at 0.85 Hz,
the 20:1 decimation a low-pass at 22.17 Hz). After decimation to 50 SPS the
Nyquist is 25 Hz, and the boxcar's ~−13 dB sidelobes let everything above
fold into the judged band: 60 Hz mains landed at 10 Hz attenuated only
16 dB, and on the interference-heavy `test-22` bench capture the folded-in
content measured **62 µV RMS = 41% of the honest in-band signal** (quiet
lot-500 parts: ~2%, harmless). Phantom energy the legacy AC-coupled amp
chain never displayed was being counted as part noise.

- **Fix (unified app only, `eltec_rig/m405m22/stability_analysis.py`):**
  `analyze_noise_capture_band_limited` now decimates through a new
  `decimate_antialiased` — a Kaiser windowed-sinc FIR (621 taps, pure
  stdlib, cached; `math.sumprod` fast path ≈ 12 ms per 20 s capture) with
  the SAME passband (flat to 22 Hz, matching the boxcar's −3 dB corner) and
  the same output timeline (one sample per 20-raw-sample block, so all
  window/clip index math is unchanged), but ≥ 60 dB stopband from 28 Hz
  (60 Hz mains: −84 dB vs the boxcar's −16 dB). Edges use odd-reflection
  padding, which passes a linear settling ramp through EXACTLY (machine
  precision), so the adaptive quiet-start/per-window-detrend behavior for
  still-settling captures is preserved. `decimate_boxcar` stays for the
  live preview (display-only) and for A/B comparisons.
- **Calibration continuity PROVEN by replaying every saved raw capture**
  (`noise_captures/`, old vs new at the production 15% allowance): all nine
  verdicts identical, including the lot-500 anchors — 500-44 reads 502 µV
  worst / 1/20 over (was 501 µV) and stays PASS; 500-27 stays 18/20 FAIL;
  quiet parts move 1–7%. `test-22` (the 41% case) drops 729 → 689 µV worst
  and still fails 20/20 — honestly now: its ~9.7/19.4 Hz spike-train
  components are genuinely inside the declared 22 Hz band (the flat
  passband counts 19.4 Hz at 1.0 where the boxcar drooped it to 0.75).
  Whether 10–22 Hz interference SHOULD count against a part is the separate
  open legacy-amp-passband question below.
- **Squares read slightly higher through the flat passband** (in-band
  harmonics no longer drooped + band-edge Gibbs): the synthetic test
  fixtures' 2 mV square reads 2.356 mV (was exactly 2.000). Window-over
  counts — the thing the verdict uses — are unchanged on every fixture and
  every real capture. A raw-clip rail now also condemns its ringing
  neighbor window (windows_over 2 with 1 clipped window in the unit test);
  production-irrelevant since any clipped window already fails the capture.
- **Tests: 166 discovered (was 165; 4 skipped as before)** — new
  `test_antialias_decimation_rejects_folding_frequencies` (in-band tones
  unity, 40/60/120 Hz crushed ≥ 60 dB, ramp transparency, boxcar-identical
  timeline) plus four updated pinned values with comments explaining the
  physics. Unified glue 17/17. The frozen standalone `405m22_esp32/` build
  keeps the boxcar untouched, per the originals-frozen rule.
- **Engineer tools (new, repo `engineer_tools/`):**
  `replot_noise_capture.py` replays any saved `*_noise_raw.npz/.csv`
  through the exact production pipeline plus arbitrary zero-phase band-pass
  / low-pass / boxcar variants (PNG per capture: raw trace, judged traces
  vs the red limit, raw spectrum; verdict-comparison table; `--boxcar 20`
  reproduces the historical pipeline). `filter_response_analysis.py`
  measures the pipeline's passband/aliasing and tests legacy-amp passband
  hypotheses against a measured capture spectrum.
- **Legacy-amp findings from the same analysis:** no physically sensible
  1 Hz-centered band-pass explains the ~700x effective chain factor from a
  4000x nameplate (best achievable ratio 0.235 vs the required 0.175, and
  only at a degenerate 12 Hz notch) — the 700-vs-4000 gap is a REAL GAIN
  difference (10:1 probe setting, amp range switch, or wrong nameplate),
  not a bandwidth effect. Asking the amp builder for the passband corners
  (input coupling C + feedback C) and the true midband gain / probe setting
  remains the open action; a known passband would let the rig replicate the
  amp's response digitally instead of scaling through one factor.
- Also noticed: `500-27_noise_raw.npz` and `_2` hold byte-identical
  waveforms (duplicate save, both 09:39) — check whether re-measure can
  save a stale buffer.

## Unified test rig: one app for every sensor version (2026-08-18)

The rig now has ONE production application, **`tech_app/eltec_rig/`** ("Eltec
Test Rig"): a selector GUI with a **sensor version dropdown** (Model 405 M22
and Model 406 MCA today; the registry in `sensor_versions.py` is built to
grow) that launches the chosen model's qualified tester unchanged. Each
model keeps its own test flow, thresholds, per-batch filter-setup dropdowns,
CSV format, and results folders. The last-used version is remembered. Runs
on Windows and Xubuntu with launchers and opt-in desktop-icon installers for
both (`run_eltec_rig_tester.cmd|.sh`, `install_windows_launcher.ps1`,
`install_xubuntu_launcher.sh`; identity `Eltec Test Rig` /
`com.eltec.test-rig.desktop`; logs in `%LOCALAPPDATA%\eltec-rig` /
`~/.local/state/eltec-rig`). See `tech_app/eltec_rig/README.md`.

- The bundled models are COPIES: `m405m22/` (= `405m22_esp32`, byte-identical
  apart from the removed prompt.txt) and `m406mca/` (= `v6_1_esp32` + the
  changes below). The original `tech_app/405m22_esp32/` and
  `tech_app/v6_1_esp32/` directories stay untouched as the qualified
  standalone builds; new work happens in `eltec_rig/`.
  `v1_single_sensor/eltec_406mca_tester.py` is vendored inside `eltec_rig/`
  so the package is self-contained.
- **Firmware v3.0** (`Arduino/Eltec/Eltec.ino`, snapshot in
  `versions/Eltec_v3_0/`) is the unified baseline: functionally identical to
  v2.1 (single-channel streaming, `PWM,FREQ`, runtime `FE,...` front-end
  switch) with the IR-telescope dual-channel code REMOVED. Compiled clean
  (290,208 bytes, 22% flash); **not yet flashed** — the bench board still
  runs v2.1, which the unified app fully supports.
- **406MCA on v2.1+/v3.0 firmware**: `m406mca/esp32_backend.py` now sends
  `FE,V19` right after the `IDN?` handshake and hard-verifies the `FE?`
  read-back, restoring the gain-2 buffered front end (±2.5 V) every 406MCA
  threshold was qualified on (each port open resets the board to the v2.0
  front end, which is why it re-applies on every connect). A mismatch
  refuses the connection. On v1.x boards (legacy standalone 406MCA rigs on
  v1.9) no `FE` command is sent. Legacy `v6`/`v6.1` apps must still NOT be
  used on v2.x/v3.x boards — only the unified app selects the front end.
- **406MCA battery gate disabled in the unified copy**
  (`BATTERY_MONITORING_ENABLED = False` in `m406mca`, mirroring the 405 M22
  build): the unified fixture has no battery on the AIN7 divider (6.5 V →
  emitters only, 9 V → sensors). Header shows "Battery: not monitored"; all
  battery machinery is kept intact for re-enable (planned: AIN6 divider).
  `m406mca/stability_calibration.py` got the same flag.
- **Tests**: unified glue 17/17; `m405m22` 165 (4 skipped, as before);
  `m406mca` 99 (4 new front-end-selection tests; on Windows the same two
  long-standing environment-only failures as v6.1 — the POSIX bash-installer
  test and the POSIX exclusive-tty assertion — both pass on Xubuntu).
  Original `405m22_esp32` (165 OK) and `v6_1_esp32` (95, same two
  environment failures) re-verified untouched.

## IR telescope split into its own workspace (2026-08-18)

Everything IR-telescope-related moved to
**`C:\Users\JoseCastelblanco\Documents\Eltec_IR_Telescope`** (its own git
repo, initial commit `859fcb6`): the `ir_telescope` app (49 tests passing),
firmware **v2.2** as `Arduino/Eltec_v2_2/` (the only build with
`STREAM,START,BOTH`), dual-capable copies of `live_waveform.py` /
`esp32_rig_readout.py` under `tools/`, the wiring doc, and the telescope
sections of this file as its `STATUS.md`. That directory was already the
telescope app's session-data root; existing session folders were preserved
and gitignored. In THIS repo, `tech_app/ir_telescope/` was deleted and the
dual-channel features were stripped from `Arduino/Eltec/live_waveform.py`
(no more `--channel both`/`--overlay`) and `esp32_rig_readout.py` (no more
`dual`; `noisecmp`, `--fe`, and `--freq` kept). The board must be flashed
with the telescope workspace's v2.2 for telescope sessions and back to the
rig firmware afterwards (v2.2 is also a drop-in for this rig's apps).

Workspace note: this repository is being renamed from `Eltec406mca` to
**`Eltec_TestRig`** (it tests more than the 406 MCA now). Only the folder
name changes; all in-repo paths are relative.

## Stream-corruption root cause + fix, and the ACTUAL board firmware (2026-08-17, afternoon)

Every 405 M22 capture began failing stream integrity ("timestamp gaps +
duplicate timestamps + host/firmware count mismatch") after the morning's
telescope session. Root-caused and FIXED the same day — it was neither the
firmware nor the telescope work:

- **The bench board on COM3 actually runs v2.1** (live `IDN?` check), not the
  v2.2 this file previously claimed. That is fine: the 405 M22 app needs only
  >= v2.0, and v2.1 contains no telescope code at all. Re-flash v2.2 only when
  the telescope app (which requires `STREAM,START,BOTH`) is next used — it is
  a proven drop-in for 405 M22 testing (single-channel path byte-identical).
- **Root cause:** the Windows CP210x driver grants only a **512-byte receive
  queue** (~16 ms of stream; the app's 1 MiB `SetupComm` request is silently
  ignored — measured via `GetCommProperties`), and Windows 11 **on battery**
  throttles the backgrounded tester GUI (EcoQoS + ~15.6 ms timer coarsening;
  USBHUB3 event 196 began actively power-targeting the CP210x on 2026-08-14).
  The sleep-paced drain thread then wakes too late and the driver queue wraps:
  drops + re-delivered duplicates. Headless captures (CLI, and the app's own
  backend without the GUI, with the 1 Hz emitter chopping) were 100% clean,
  exonerating board, cable, firmware, and EMI.
- **Fix (tech_app/405m22_esp32/esp32_backend.py):** drain thread now blocks in
  the driver read (no timers) at raised priority; the process opts out of
  Windows power throttling and timer coarsening; driver `CE_RXOVER` overflow
  flags are captured so the failure dialog attributes host stalls instead of
  blaming the cable. USB selective suspend disabled (AC+DC) in the power plan.
  Full detail: tech_app/405m22_esp32/README.md "part 2".
- **Reference anomaly explained + gate disabled (same day, later):** the
  4.94 → 0.30 mV reference collapse is CHANNEL CROSSTALK — the fixture's
  buffer/voltage-follower is a dual op-amp with no channel isolation, so the
  DUT couples into AIN1 and the reference reading tracks whichever sensor is
  loaded. No recalibration can fix that, so `REFERENCE_GATE_ENABLED = False`
  now skips the reference phase entirely (3-step test: offset → noise →
  sensitivity; verdicts unaffected — all measured on AIN0). Re-enable the
  flag and recalibrate when the per-channel-isolated buffer board is
  installed. The crosstalk-contaminated calibration JSON and the partial
  lot_500 CSV were archived with dated suffixes; batch 500 restarts at
  500-1. Operator rule meanwhile: several LS failures in a row → suspect
  the emitter first.

## IR telescope firmware verified (2026-08-17)

**Firmware v2.2 was flashed and verified on the bench rig** (Windows host,
COM3) for the telescope session; the board has since been returned to /
verified running **v2.1** (see the section above). **One firmware family runs
everything**: v2.2 satisfies the 405 M22 app's `>= v2.0` gate, and
single-channel streaming is byte-identical to v2.1, so no re-flash is needed
for 405 M22 testing whenever v2.2 is on the board for the telescope.

Hardware testing immediately caught a **real bug in the first v2.2 build**. The
mux-cycling order was the throughput-optimised one from the datasheet — change
the mux and `SYNC` first so the next channel's settling overlaps the SPI read,
then `RDATA`. On this board that is wrong: `SYNC` restarts the converter and the
output register is not safe to read across it. Proof, same physical input: AIN0
is pristine single-channel (sample-to-sample step max 6 mV, no full-scale reads
in 8000 samples) but in dual mode showed **4.8 V single-sample jumps and hit
full scale 7 times in 8474 pairs**. Reading the conversion *before* touching the
mux costs ~50 µs of overlap per pair (397 → 379 SPS) and removes it entirely:
step max 8 mV, zero full-scale reads, zero glitches on both channels. The
`ESP32_memory.md` entry says explicitly not to optimise it back.

Measured on the rig: **379 pairs/s per channel, pair skew 1.32 ms**, 0 timing
gaps over 20 s. The host now measures the delivered rate at session start and
derives every filter coefficient from it instead of the nominal 424.

**Open fixture issue, not a code problem.** Both channels carry very large slow
drift — 135 mV (AIN0) and 170 mV (AIN1) rms below 0.3 Hz — while the crossing
band (1–8 Hz) is quiet at 5.8 and 7.7 mV and above 20 Hz is ~1.2 mV. That drift
leaks past the trigger's highpass and pushes the threshold to ~400 mV, which
costs sensitivity to everything. The `BAT?` reading also wandered 1.04 → 3.71 V
across runs and both sensor DC levels climbed run to run, so the **sensor supply
is the first thing to check**; thermal settling is the second. `check` now
reports this split explicitly so drift is not mistaken for a noisy site.

Note: the telescope's detectors are **not** the 406MCA/405 M22 parts the rest of
this repo tests. The app therefore has no absolute noise expectation and never
compares against those specs — it measures the floor on site and expresses
thresholds relative to it. Whether the threshold is low enough for real targets
is settled by a walk test.

## IR telescope (new, 2026-08-14)

A separate application in `tech_app/ir_telescope/` reads **both** detectors of a
two-element IR telescope at once and reports which way a target crossed, how
fast, and how much to trust the answer. AIN0 is the right-hand detector; AIN1
sits 15 mm to its left and 3 mm below it.

This needed a firmware change: **v2.2** adds `STREAM,START,BOTH`, which
interleaves AIN0 and AIN1 by cycling the ADS1256 mux and emits one `P,` line
per pair at ~424 SPS per channel. It is purely additive — single-channel
streaming is byte-for-byte unchanged, so v2.2 is a drop-in replacement for v2.1
on the 405 M22 rig. Compiled clean; **not yet flashed or run against hardware.**

`Arduino/Eltec/live_waveform.py` gained `--channel both` (and `--overlay`) so
the two detectors can be watched on one scope view, and
`esp32_rig_readout.py` gained a `dual` command that characterises the link
(delivered rate, pair skew, per-channel level).

The app covers the commissioning-kit workflow: `check` (rig health + measured
noise floor), `calibrate` (learns the direction sign from three walks),
`live --walk-test` (beeps plus L/R ground-truth keys, scored in the report),
`record` (headless logging), `replay` (re-analyse a session with new settings)
and `report`. Everything runs with `--simulate` and no hardware.

Three findings from building it, all caught by tests rather than in the field:

- A one-pole highpass in the trigger does not reject slow thermal drift, so the
  detector latches onto the background and misses everything real. A trailing
  boxcar fixes the drift but grows a phantom copy of every target one window
  later. The build uses a delay-matched two-pole exponential baseline.
- Releasing an event on an instantaneous 2 sigma test can essentially never
  succeed — Gaussian noise crosses 2 sigma on 4.6% of samples, so half a second
  of unbroken quiet never accumulates and events run to the 30 s limit. The
  release runs on a smoothed envelope.
- "How long the trigger stayed up" is dominated by filter decay and grows with
  the log of amplitude, so it cannot distinguish a 10 ms glitch from a 250 ms
  crossing. The half-peak width of the band-passed waveform can (0.08 s vs
  0.96 s), and that is what the app reports and gates on.

**Direction sign is a per-installation calibration, not a constant.** It
depends on whether the optics invert the image and on which side of the
telescope you stand. Defaults are documented guesses; `calibrate` turns it into
a measurement, and every report says in bold when it has not been run.

49 tests (`python -m unittest discover -s tests`), no hardware needed.

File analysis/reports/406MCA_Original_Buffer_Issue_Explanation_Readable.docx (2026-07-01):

406MCA Sensor Measurement Issue
and Buffer Solution

Readable explanation of the original LabJack measurement problem, the AM 502 clue, and the unity-gain buffer fix

Bottom line

The LabJack was not just struggling because the signal was small. The stronger evidence is that the AM 502 gave the correct reading even at 1x gain. That points to a source-impedance / settling / buffering problem. A unity-gain buffer should give the LabJack a low-impedance signal while preserving the 0.667 V DC offset and the small AC waveform.

# 1. Quick facts

Item | Value / meaning
Expected sensitivity | About 5.76 to 6.56 mV peak-to-peak.
DC offset | About 0.667 V. This offset must be preserved for this test.
Bad direct readings | Direct LabJack readings were too high, around 15 mV in one setup and around 33 mVpp with the +/-1 V range setting.
Known-good clue | AM 502 at 1x gave the correct sensitivity reading, which means the AM 502 was mainly helping as a buffer.

Measurement goal

Measure the small peak-to-peak sensor waveform accurately with the LabJack T7-Pro while still measuring the 0.667 V DC offset. The first fix should not add gain. It should only buffer the signal.

# 2. What the original measurements showed

The measurements tell a very specific story. Direct connection to the LabJack produced a sensitivity value that was too high. The AM 502 produced the correct value even when set to 1x. That is the key evidence: the AM 502 was not mainly solving the problem by amplifying the voltage. It was isolating the sensor from the LabJack input and driving the LabJack from a stronger, lower-impedance source.

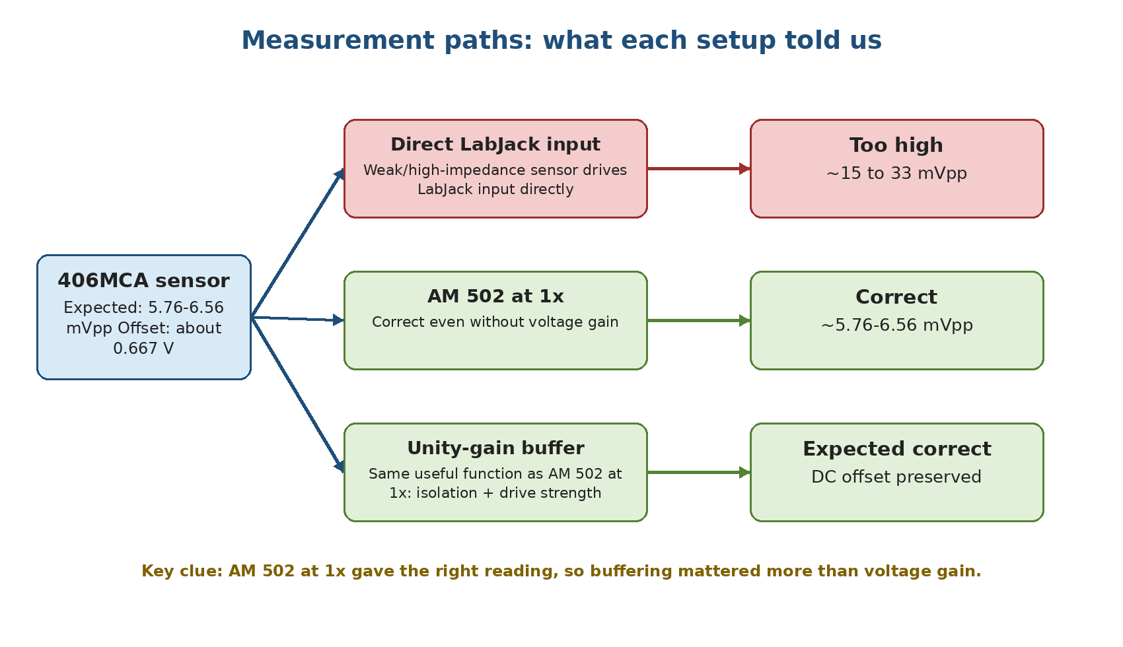
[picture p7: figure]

Figure 1. Comparison of the direct LabJack reading, the AM 502 at 1x, and the intended unity-gain buffer path.

# 3. Why the AM 502 result matters

Setup | Observed result | What it means
Sensor directly into LabJack | Measured too high: about 15 mV in one setup and about 33 mVpp with the +/-1 V input range. | The direct sensor output was not being measured cleanly.
Sensor through AM 502 at 1x | Measured the expected sensitivity range. | The AM 502 helped even without voltage gain, so the useful function was buffering.
Sensor through unity-gain buffer | Expected to match AM 502 at 1x. | This removes the bench amplifier while keeping the important isolation/drive function.

Plain-English version

The AM 502 proved the problem was not simply, "the signal is too small." If that were the whole issue, 1x gain would not have helped. The more likely issue is that the sensor output is too weak/high-impedance for the LabJack input behavior during streaming.

# 4. Likely root cause: LabJack input settling/loading behavior

The LabJack T7 analog inputs are sampled through an internal multiplexer and ADC input network. During streaming, the ADC input has to settle to the correct voltage every time a channel is sampled. If the source connected to AIN0 has high impedance, it may not charge or discharge the ADC input capacitance fast enough. The result is settling error.

That kind of error matters a lot here because the useful AC signal is only a few millivolts peak-to-peak. A small settling error can become large compared with the real waveform, so the software calculates an artificially high peak-to-peak sensitivity.

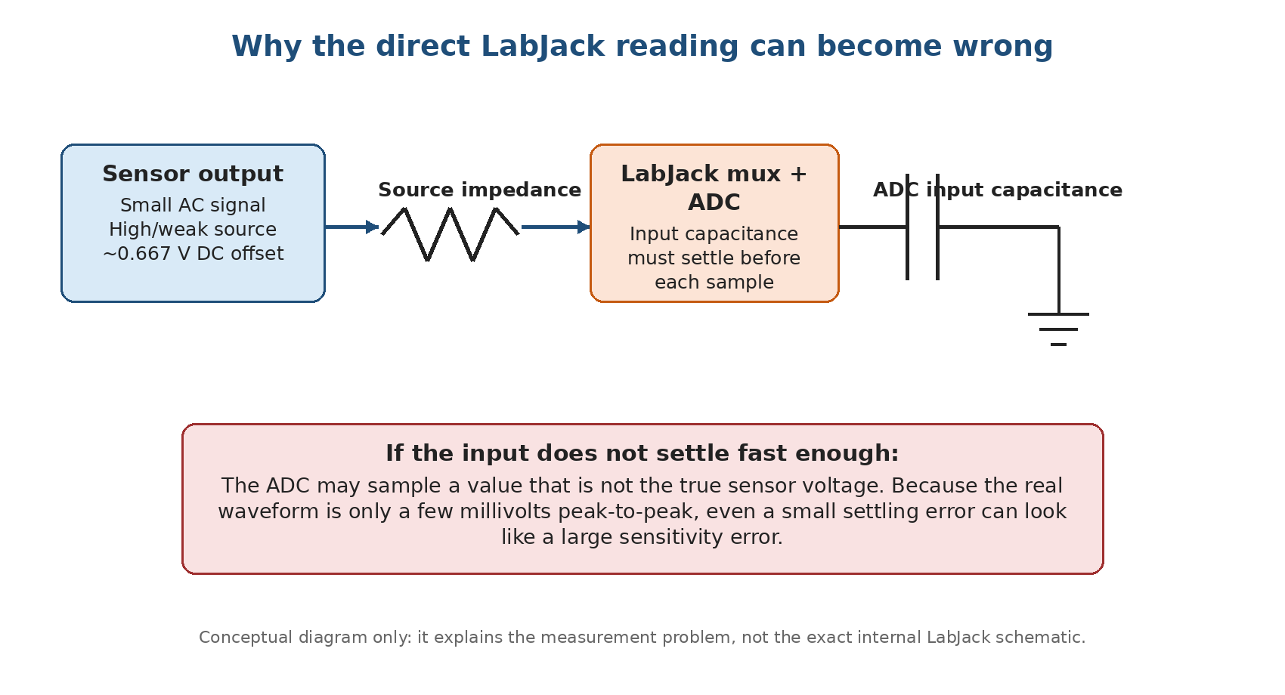
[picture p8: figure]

Figure 2. Conceptual explanation of how a weak/high-impedance source can cause ADC settling error.

# 5. Why changing the LabJack range did not solve it

Setting / idea | What it helps | Why it does not solve this problem
+/-1 V input range | Improves usable resolution compared with a wider range. | It does not make the sensor output lower impedance. The LabJack still has to be driven cleanly.
+/-0.1 V input range | Would give more resolution for a centered small signal. | Not usable here because the sensor sits at about 0.667 V DC offset, which is already outside +/-0.1 V.
External gain in tester app | Corrects the math if a real external amplifier is used. | For the unity-gain buffer test, leave this at 1x because the buffer should not amplify the signal.

Important

Do not use the +/-0.1 V range for the first buffer test unless the 0.667 V offset has been removed or level-shifted. For the first test, use +/-1 V and keep the app external gain at 1x.

# 6. Unity-gain buffer solution

A unity-gain buffer is also called a voltage follower. Its gain is 1, so the output voltage follows the input voltage. The point is not to make the signal bigger. The point is to make the signal easier for the LabJack to measure.

- Very high input impedance: the buffer barely loads the 406MCA sensor output.

- Low output impedance: the buffer can drive the LabJack input, cable capacitance, and ADC front end more cleanly.

- DC-coupled path: the 0.667 V offset is preserved.

- No first-stage gain: the first test should prove the buffering fix before adding any amplification.

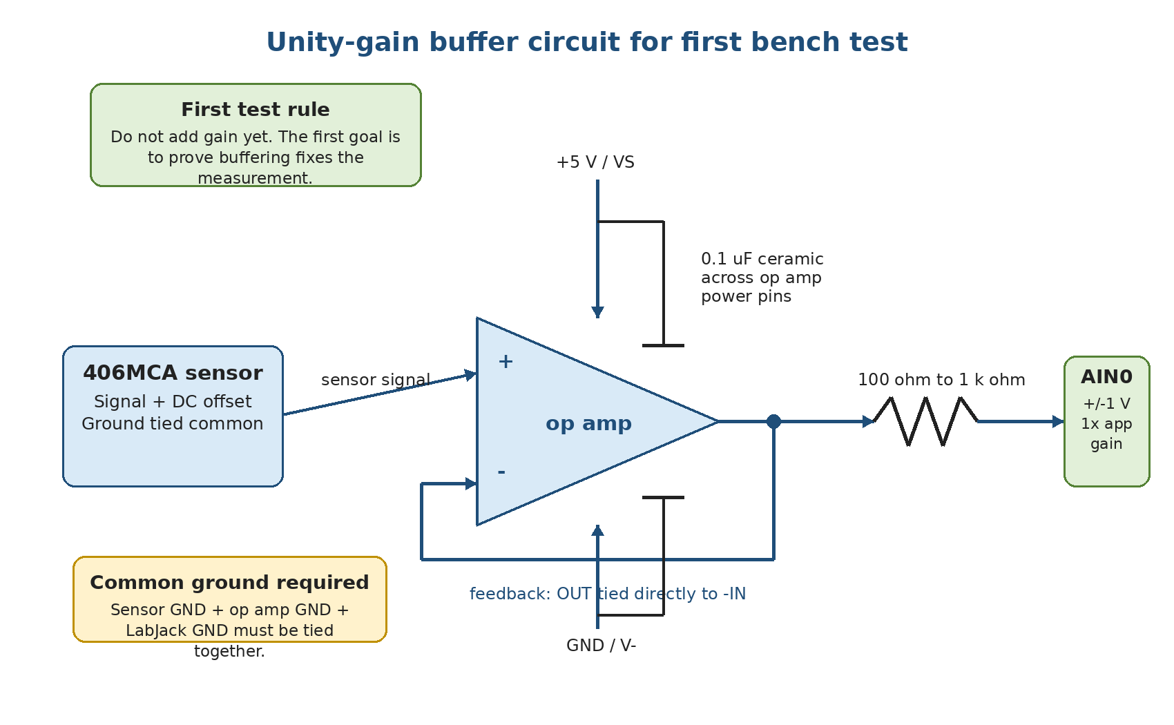
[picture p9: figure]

Figure 3. First-test unity-gain buffer wiring. The 0.1 uF capacitor should be placed close to the op amp power pins.

# 7. Bench wiring checklist

Connection / setting | Instruction
Sensor output | Connect to the op amp non-inverting input (+IN).
Op amp feedback | Connect op amp output directly back to the inverting input (-IN). This makes it a unity-gain buffer.
Buffer output to LabJack | Send the op amp output through a 100 ohm to 1 k ohm series resistor into LabJack AIN0.
Grounds | Tie sensor ground, op amp ground, and LabJack GND together.
Op amp power | Use LabJack VS/GND or a clean external 5 V supply with grounds tied together.
Bypass capacitor | Place a 0.1 uF ceramic capacitor directly across the op amp power pins, physically close to the IC.
LabJack settings | AIN0 range = +/-1 V. Tester app external gain = 1x for the buffer-only test.

What "close to the op amp pins" means

The 0.1 uF capacitor should be connected directly across the op amp power pins with the shortest practical leads/traces. For an MCP6002 DIP-8, that means between pin 8 (+5 V/VDD) and pin 4 (GND/VSS), placed right beside the chip on the breadboard or PCB.

# 8. Op amp requirements

Requirement | Why it matters
CMOS or FET input preferred | Keeps input bias current very low so the buffer does not load the sensor.
Very low input bias current | Important for weak/high-impedance sensor outputs.
Unity-gain stable | Required because this first stage is configured as a voltage follower.
Works from 5 V supply | Allows simple bench testing from LabJack VS/GND or a clean external 5 V source.
Input range includes 0.667 V | The op amp must correctly accept the sensor DC offset.
Stable driving the LabJack/cable | The output should not oscillate when connected through the 100 ohm to 1 k ohm resistor into the LabJack input path.

Example families mentioned for this type of test: LMC6061, MCP6002, OPA320, TLV9062/TLV9064, and similar CMOS/FET-input op amps. The first bench test does not require gain.

# 9. Verification plan

The buffer should be treated as a hypothesis test. The clean way to prove the root cause is to measure the same sensor using the same blade/sync setup in three paths:

Step | Path | Pass/fail meaning
1 | Direct to LabJack | This is the bad comparison path. It has already read too high.
2 | Through AM 502 at 1x | This is the known-good reference path.
3 | Through the new unity-gain buffer | This should match the AM 502 at 1x if the issue is source impedance / settling / buffering.

Expected outcome

If the new buffer matches the AM 502 at 1x, the root cause is strongly confirmed. If it does not, check the op amp wiring, power bypass capacitor, common ground, output oscillation/ringing, and LabJack stream/channel settings before changing the signal-processing code.

# 10. Scaling toward many sensors

For a larger fixture, the preferred architecture is to buffer each sensor before multiplexing or before feeding the DAQ input path. This is better than using one buffer after a mux because each individual sensor is isolated from mux leakage, charge injection, cable capacitance, and LabJack input settling behavior.

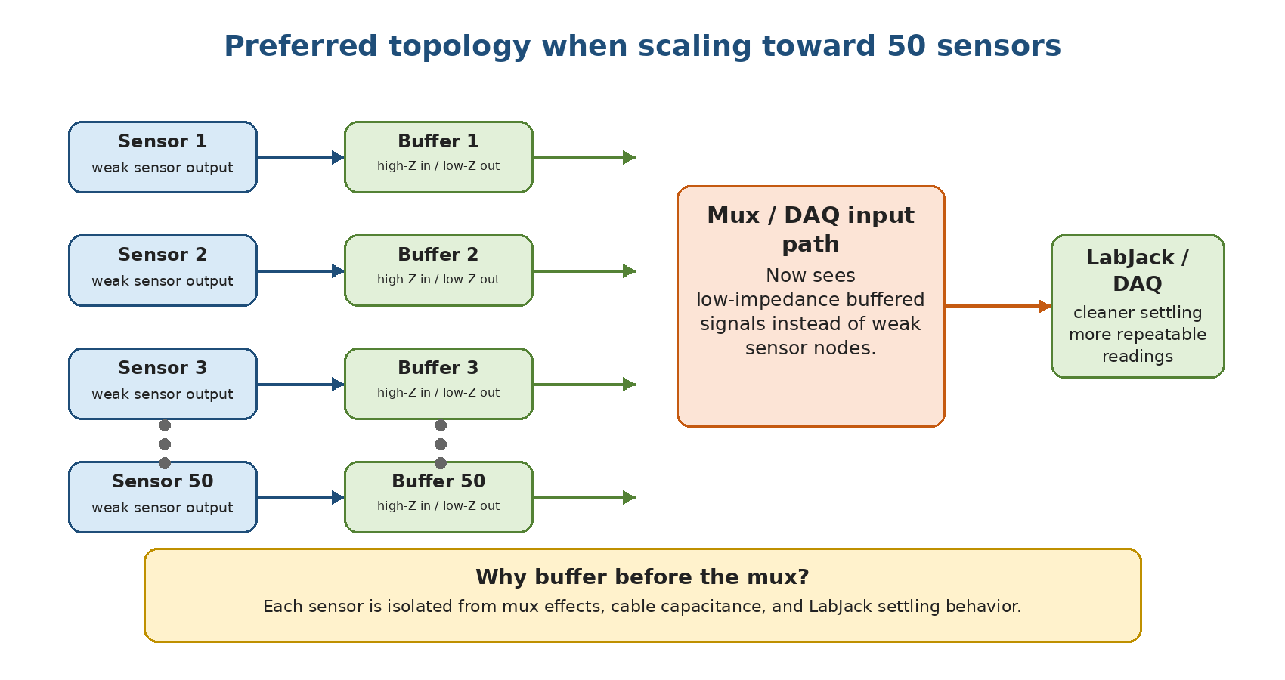
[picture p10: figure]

Figure 4. Preferred topology for scaling: each weak sensor output gets its own buffer before the mux/DAQ path.

# 11. Final summary

- The expected sensor output is only about 5.76 to 6.56 mVpp on top of a 0.667 V DC offset.

- The direct LabJack reading was too high, which means the direct input path was not measuring the waveform cleanly.

- The AM 502 at 1x gave the correct reading, which is the key evidence that the missing function is buffering, not necessarily gain.

- Changing the LabJack range improves resolution, but it does not make the sensor output easier to drive or fix source-impedance/settling behavior.

- A unity-gain op amp buffer gives the sensor a light load and gives the LabJack a low-impedance source. That is the first fix to test.

# 12. References

- LabJack analog input settling/source impedance note (https://support.labjack.com/docs/analog-input-settling-time-app-note)

- LabJack T7 analog input datasheet (https://support.labjack.com/docs/14-3-0-analog-inputs-t7-t-series-datasheet)

- TI LMC6061 datasheet (https://www.ti.com/lit/gpn/lmc6061)

406MCA sensor buffer explanation - revised for readability

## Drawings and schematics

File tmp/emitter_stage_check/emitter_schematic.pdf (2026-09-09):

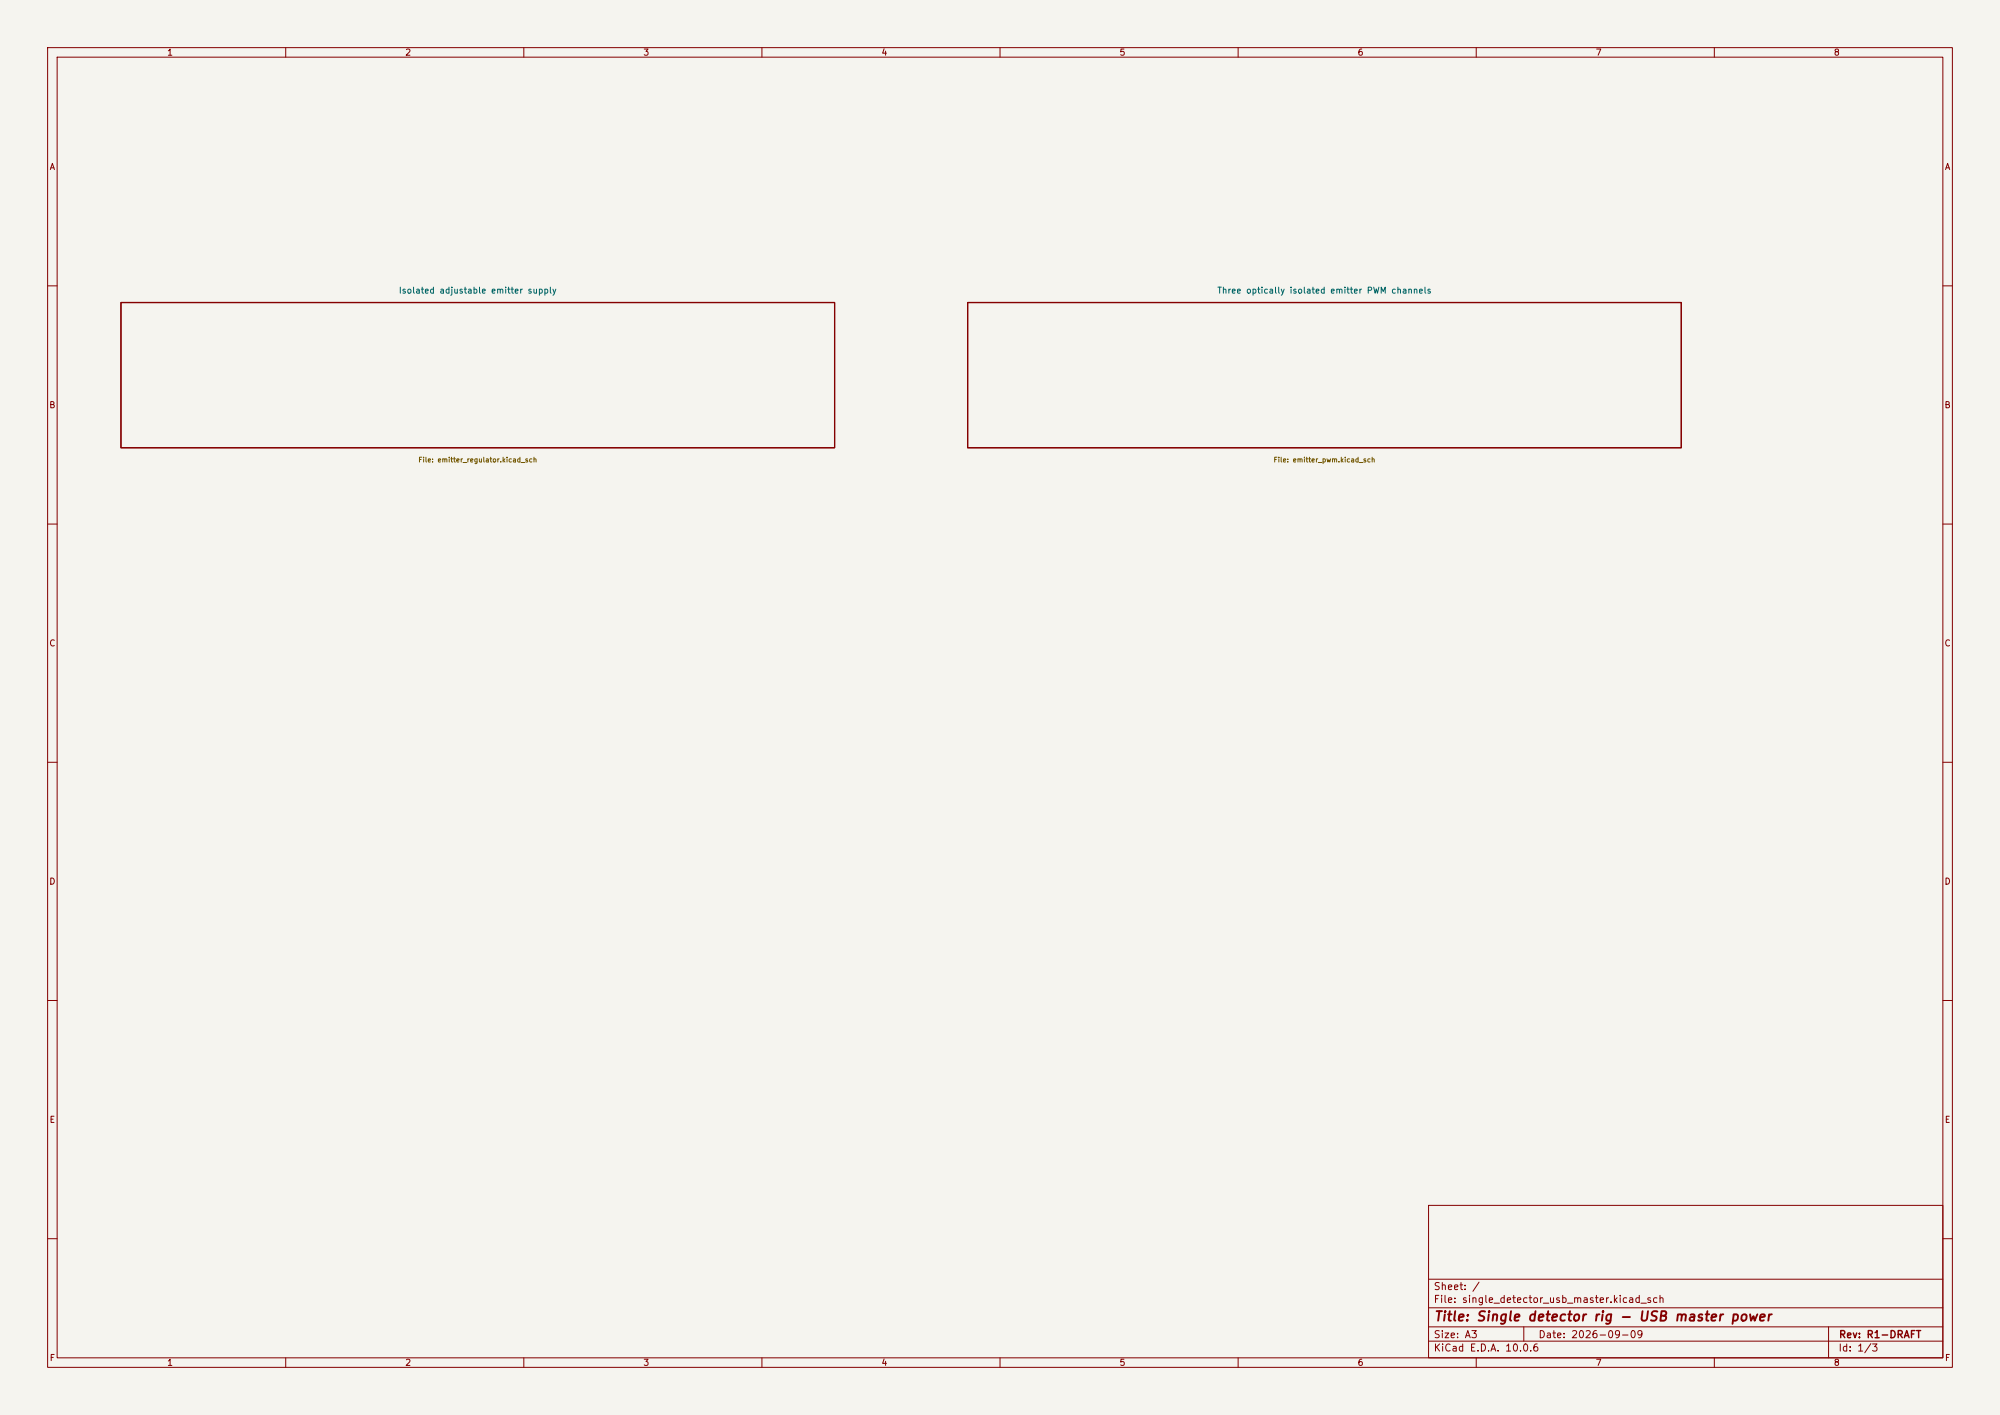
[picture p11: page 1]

Isolated adjustable emitter supply

Sheet: /
File: single_detector_usb_master.kicad_sch
Title: Single detector rig - USB master power

Size: A3 | Rev: R1-DRAFT | F Date: 2026-09-09
KiCad E.D.A. 10.0.6 | Id: 1/3

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
## Title: Isolated adjustable emitter supply

### File: emitter_regulator.kicad_sch

### Sheet: /Isolated adjustable emitter supply/

Eltec Instruments

### ENGINEERING WORK IN PROGRESS - NOT FOR FABRICATION

+

1 | 2 C100
22uF 25V 10% TPS | +
1 | 2 C102

22uF 25V 10% TPS

1 | 2 R101

7R5 1% 0.125W

CCW 1 | WIPER 2 | CW | 3 RV100

1k 25-turn 0.5W

1 | 2 R100

210R 1% 0.125W

1 | 2 C101

100nF 50V X7R 10%

1 | 2 C103

100nF 50V X7R 10%

SHDN_N 1

IN 2 | GND/TAB 3 | OUT | 4
ADJ | 5 U100
LT1963AEQ#PBF EM_GND | EM_REG

EM_BAT_SW

EM_TRIM_TOP

EM_BAT_SW | EM_REG | EM_TRIM_TOP

EM_GND

EM_REG

EM_BAT_SW

EM_GND

EM_GND

EM_GND

EM_ADJ EM_BAT_SW | EM_GND | EM_ADJ | EM_REG

EM_REG
EM_ADJ

THERMAL DESIGN
Three channels: 200mA each electrical design envelope. 600mA at every trim voltage is NOT thermally qualified. P = (Vin-Vout)*Iout + Vin*Ignd. See research/emitter_stage.md. TO-263 tab/pin3: broad EM_GND copper and thermal vias. No solid ground plane may bridge the optical isolation boundary.

SUPPLY INTERFACE
EM_BAT_SW comes from the isolated positive master switch. SHDN_N follows EM_BAT_SW; firmware does not bypass the master. EM_GND remains separate from GND on every copper layer.

Input bypass connects directly IN-to-EM_GND; the original D1/C5 error is removed.

VOLTAGE ADJUSTMENT Vout = 1.21*(1+(7.5+Rtrim)/210) + Iadj*(7.5+Rtrim). Nominal electrical setpoint: 1.253..7.019V, limited by battery/dropout. This preserves the original broad adjustment; it is NOT a safe heater preset. Use the established measured emitter voltage and validated duty/frequency. Mark the chosen setting; do not turn the pot to its end stop to calibrate.

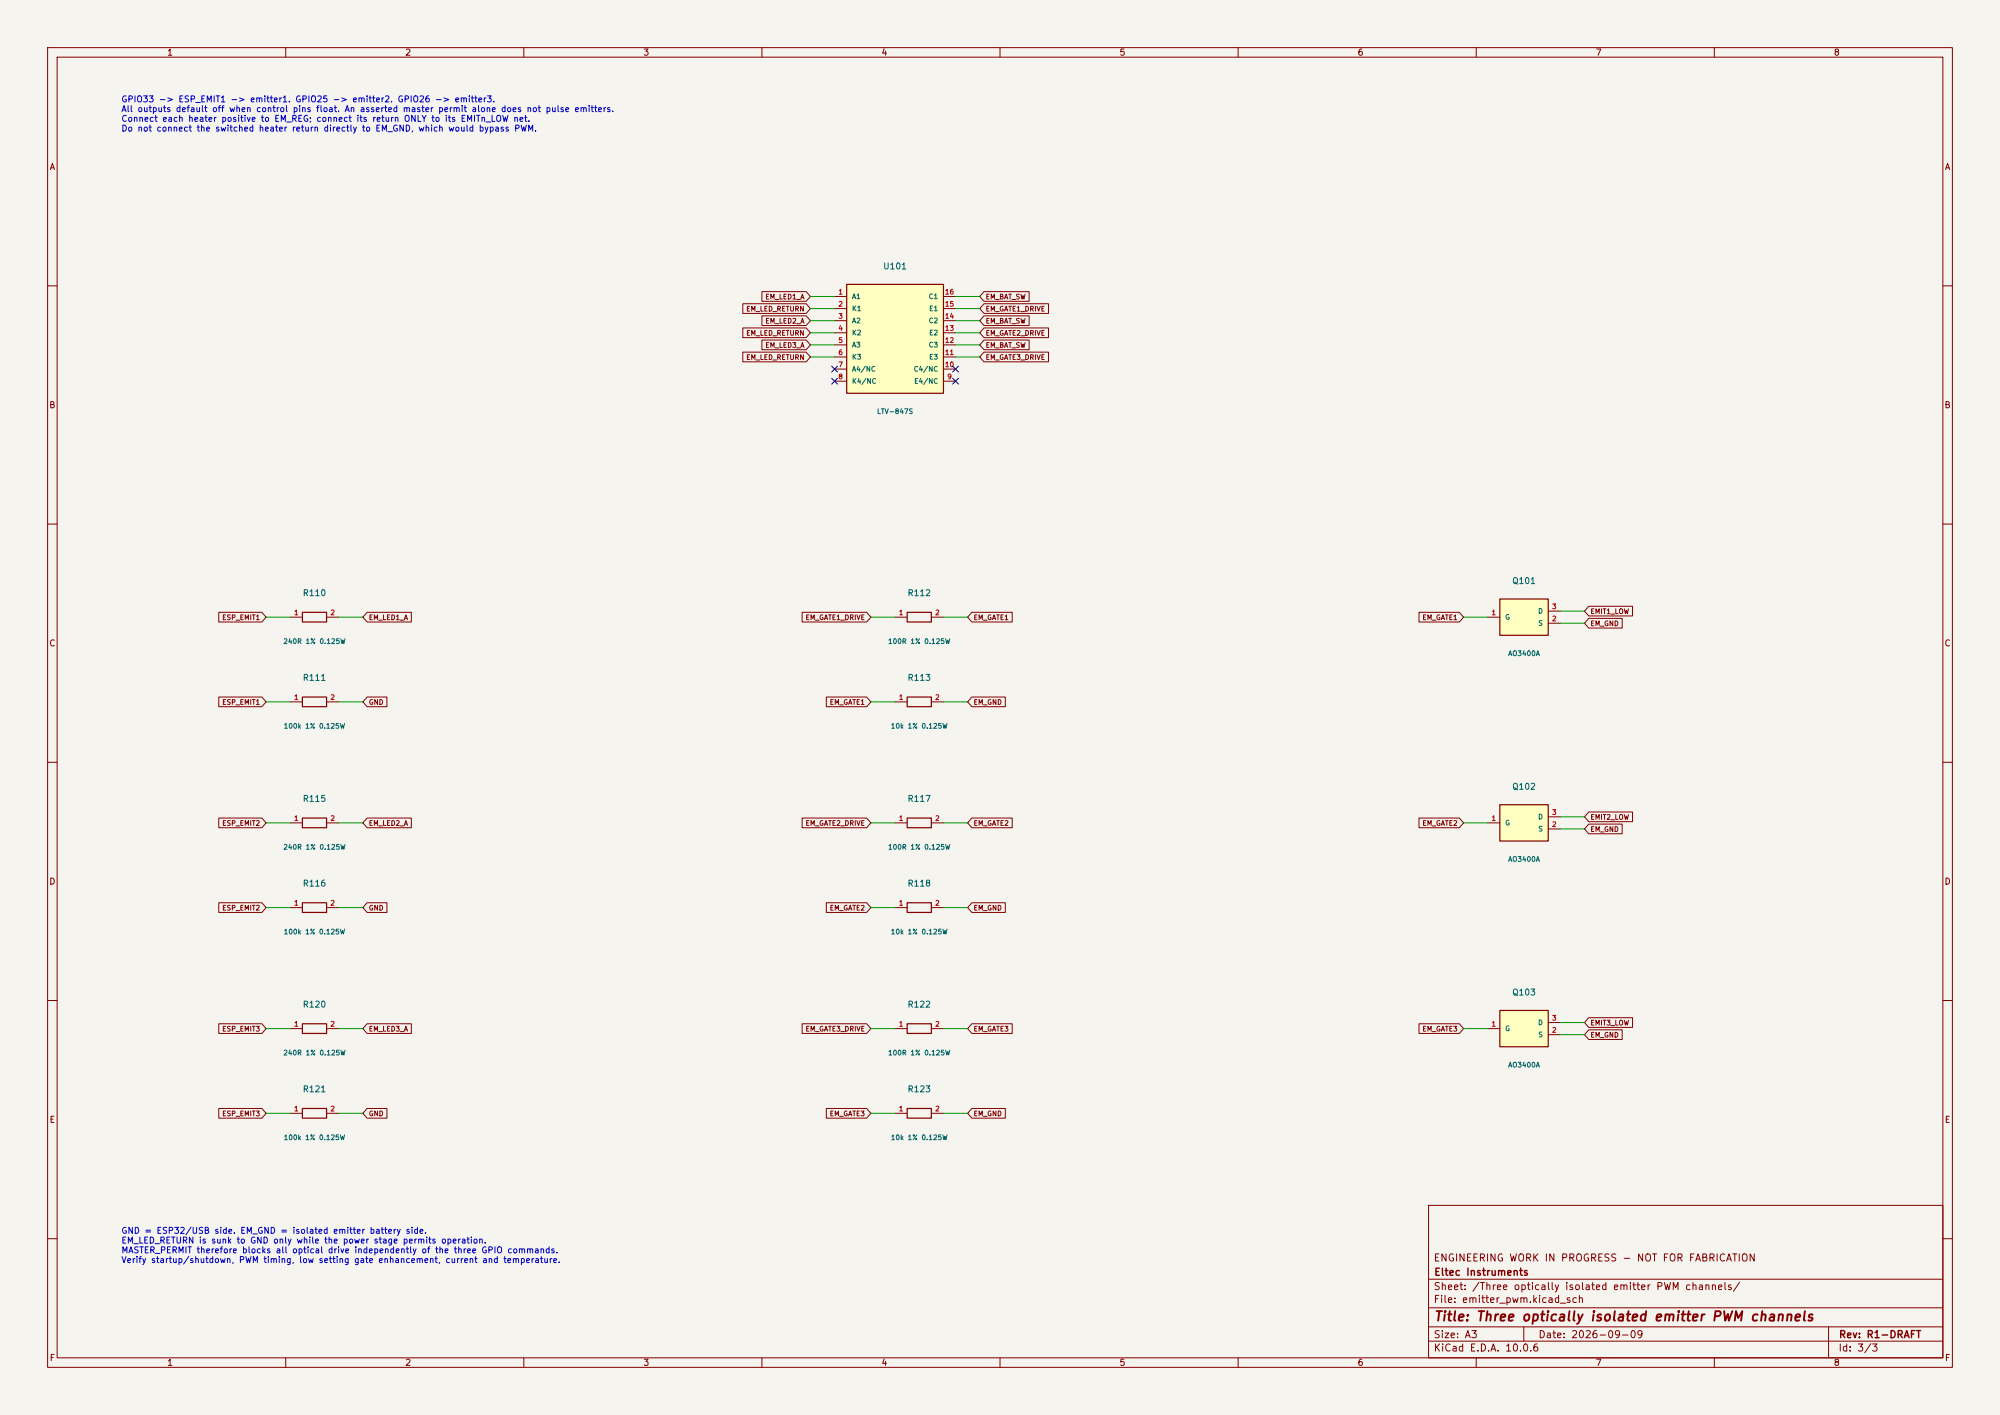
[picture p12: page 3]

GPIO33 -> ESP_EMIT1 -> emitter1. GPIO25 -> emitter2. GPIO26 -> emitter3. All outputs default off when control pins float. An asserted master permit alone does not pulse emitters. Connect each heater positive to EM_REG; connect its return ONLY to its EMITn_LOW net. Do not connect the switched heater return directly to EM_GND, which would bypass PWM.

GND = ESP32/USB side. EM_GND = isolated emitter battery side. EM_LED_RETURN is sunk to GND only while the power stage permits operation. MASTER_PERMIT therefore blocks all optical drive independently of the three GPIO commands. Verify startup/shutdown, PWM timing, low setting gate enhancement, current and temperature.

ENGINEERING WORK IN PROGRESS - NOT FOR FABRICATION
Eltec Instruments
Sheet: /Three optically isolated emitter PWM channels/
File: emitter_pwm.kicad_sch
Title: Three optically isolated emitter PWM channels

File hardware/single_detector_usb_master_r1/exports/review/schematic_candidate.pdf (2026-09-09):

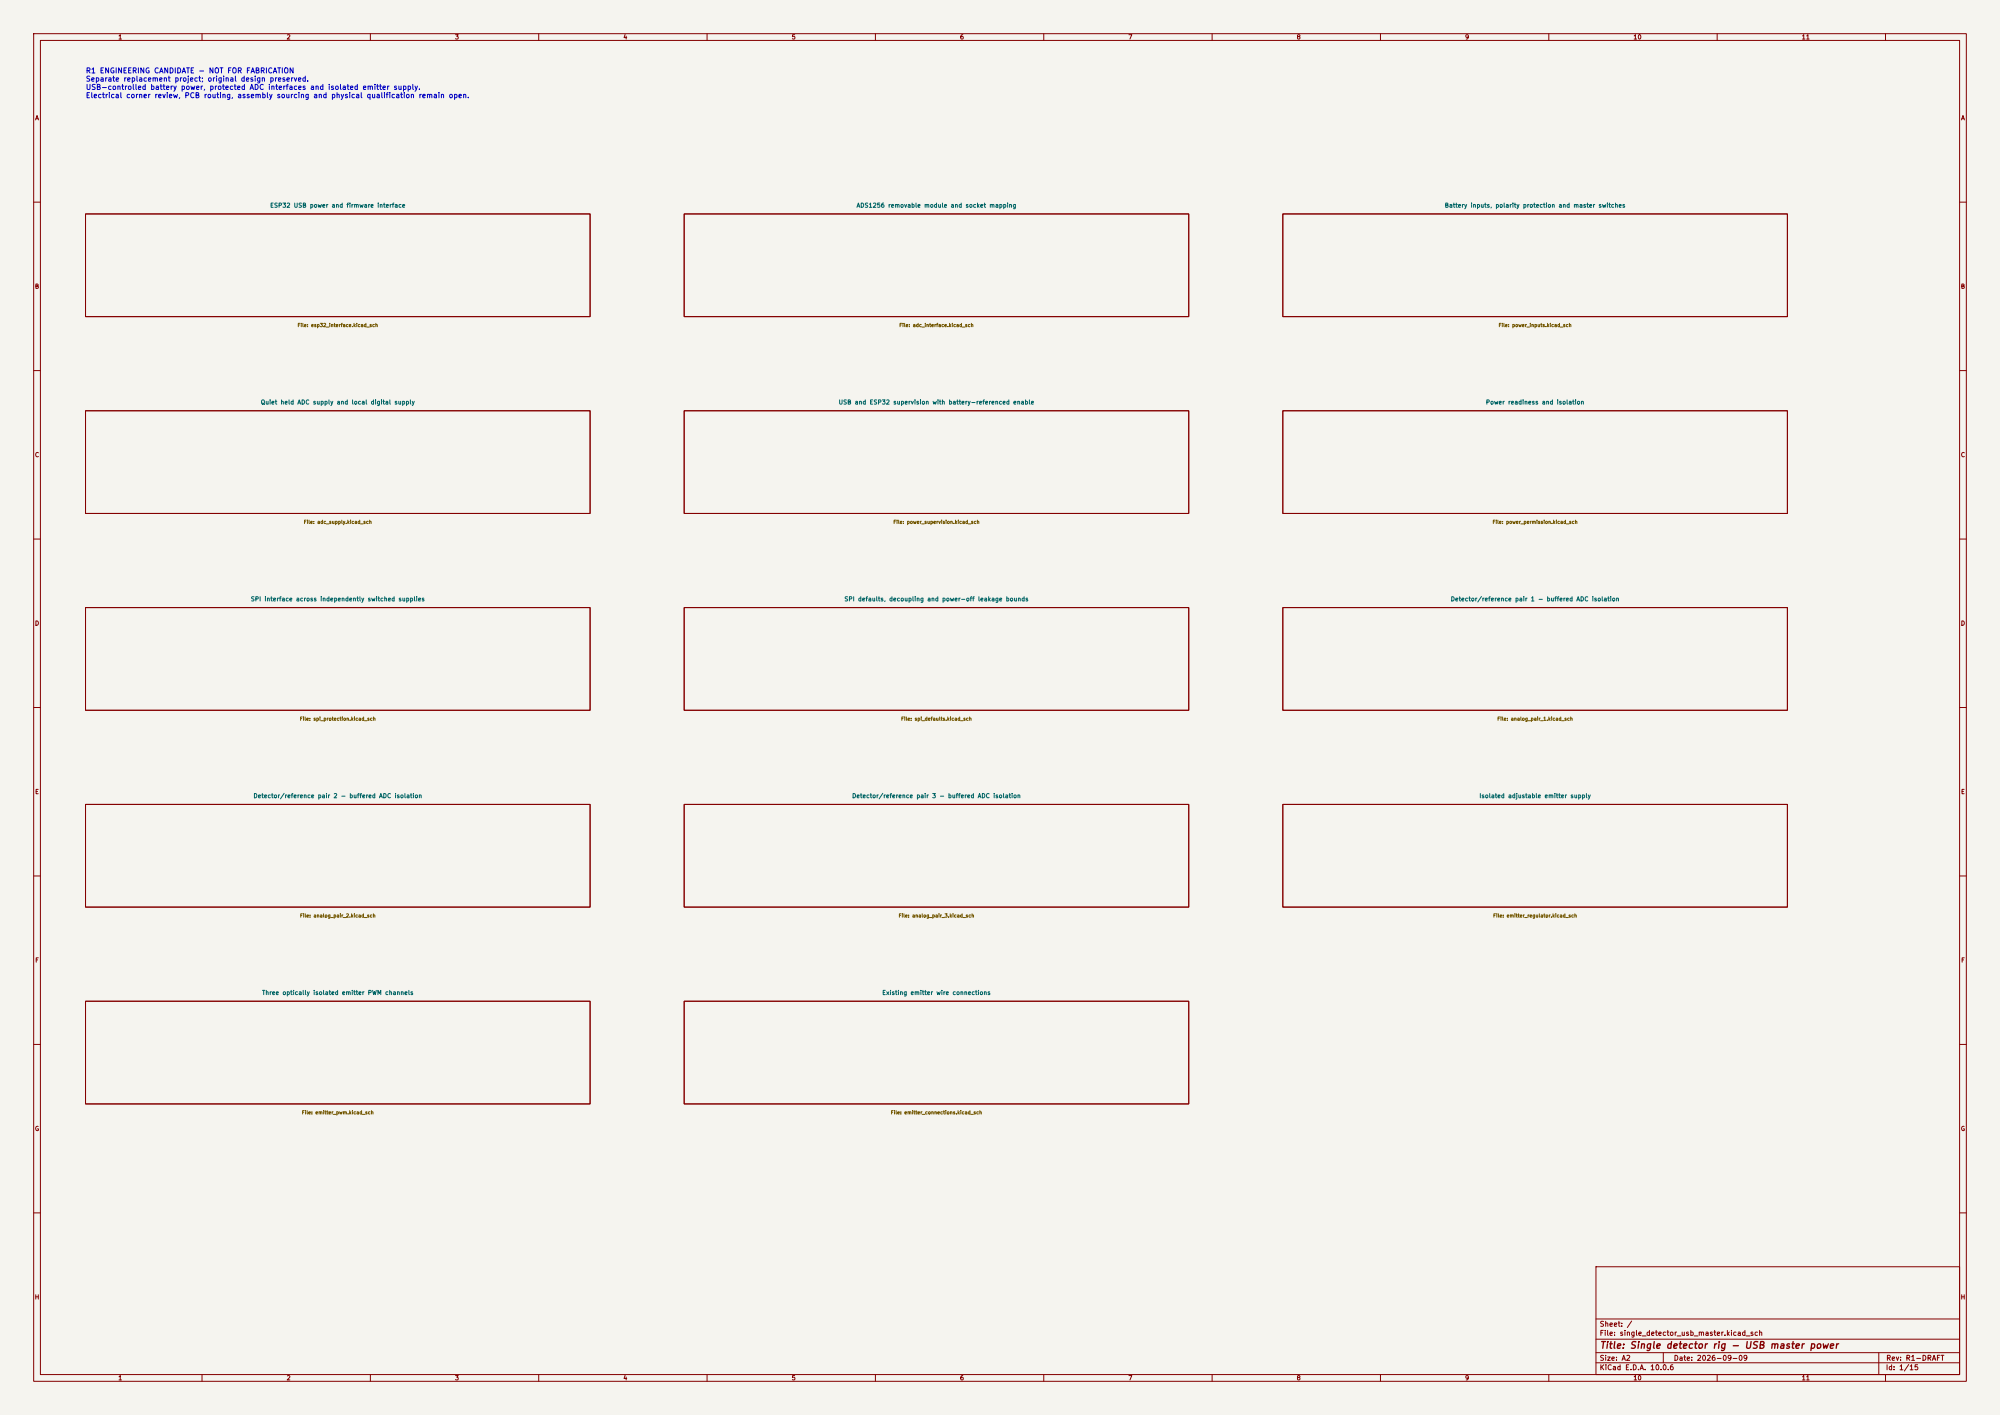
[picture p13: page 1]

R1 ENGINEERING CANDIDATE - NOT FOR FABRICATION
Separate replacement project; original design preserved.
USB-controlled battery power, protected ADC interfaces and isolated emitter supply.
Electrical corner review, PCB routing, assembly sourcing and physical qualification remain open.

ESP32 USB power and firmware interface

ADS1256 removable module and socket mapping

Battery inputs, polarity protection and master switches

File: esp32_interface.kicad_sch Quiet held ADC supply and local digital supply

File: adc_interface.kicad_sch USB and ESP32 supervision with battery-referenced enable

File: power_inputs.kicad_sch Power readiness and isolation

File: adc_supply.kicad_sch SPI interface across independently switched supplies

File: power_supervision.kicad_sch SPI defaults, decoupling and power-off leakage bounds

File: power_permission.kicad_sch Detector/reference pair 1 - buffered ADC isolation

File: spi_protection.kicad_sch Detector/reference pair 2 - buffered ADC isolation

File: spi_defaults.kicad_sch Detector/reference pair 3 - buffered ADC isolation

Isolated adjustable emitter supply

File: analog_pair_2.kicad_sch Three optically isolated emitter PWM channels

File: analog_pair_3.kicad_sch Existing emitter wire connections

Sheet: /
File: single_detector_usb_master.kicad_sch
Title: Single detector rig - USB master power

Size: A2 | Rev: R1-DRAFT
KiCad E.D.A. 10.0.6 | Id: 1/15

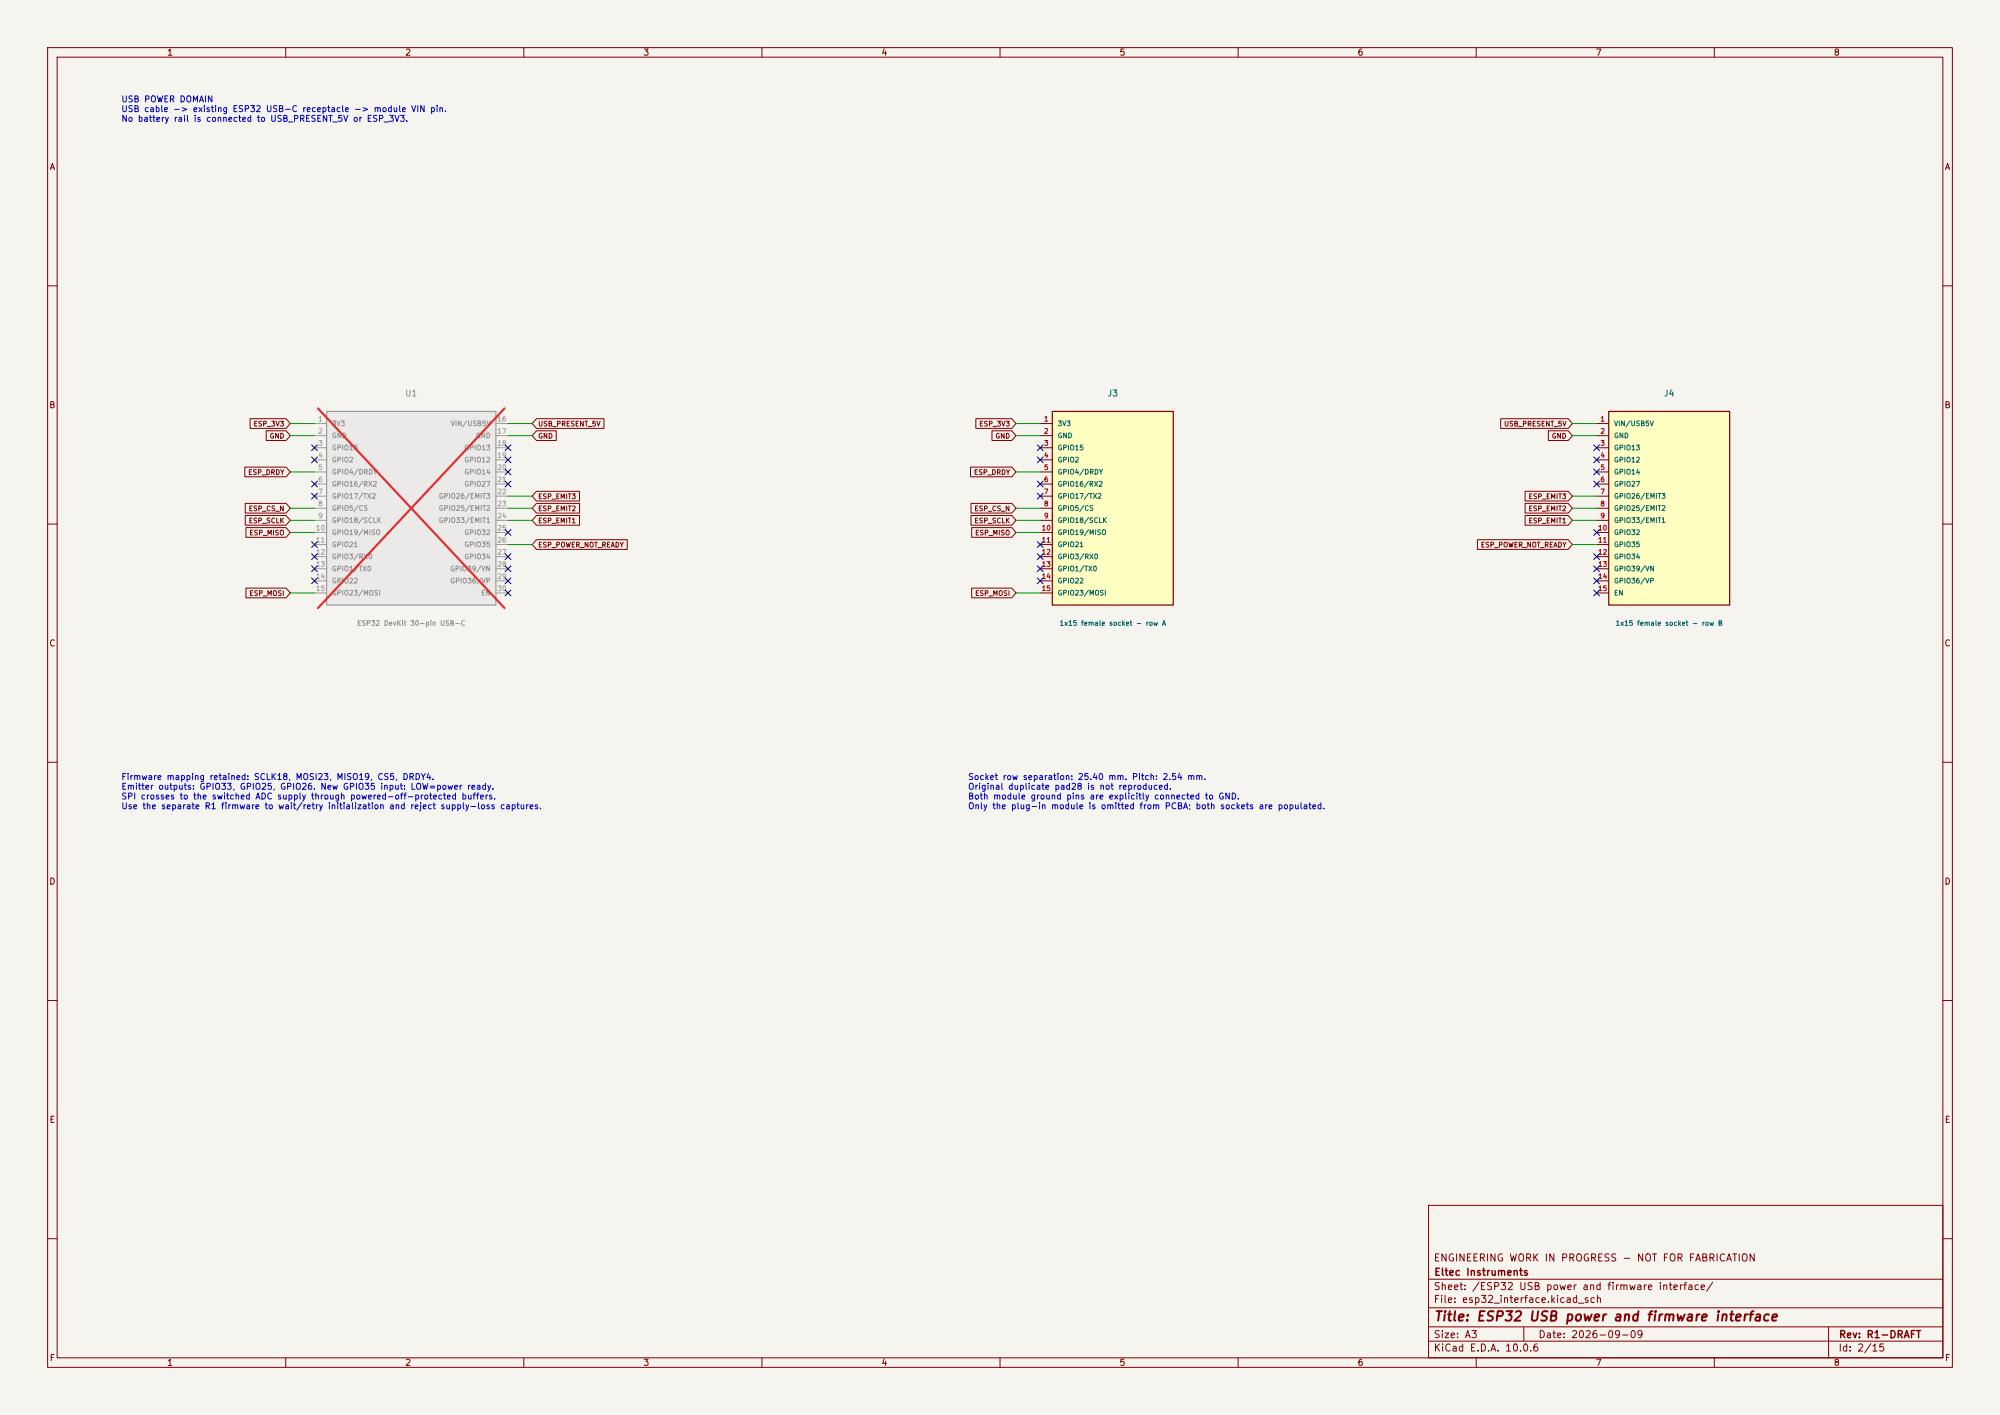
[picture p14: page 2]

USB POWER DOMAIN
USB cable -> existing ESP32 USB-C receptacle -> module VIN pin. No battery rail is connected to USB_PRESENT_5V or ESP_3V3.

Firmware mapping retained: SCLK18, MOSI23, MISO19, CS5, DRDY4. Emitter outputs: GPIO33, GPIO25, GPIO26. New GPIO35 input: LOW=power ready. SPI crosses to the switched ADC supply through powered-off-protected buffers. Use the separate R1 firmware to wait/retry initialization and reject supply-loss captures.

ENGINEERING WORK IN PROGRESS - NOT FOR FABRICATION
Eltec Instruments
Sheet: /ESP32 USB power and firmware interface/
File: esp32_interface.kicad_sch
Title: ESP32 USB power and firmware interface

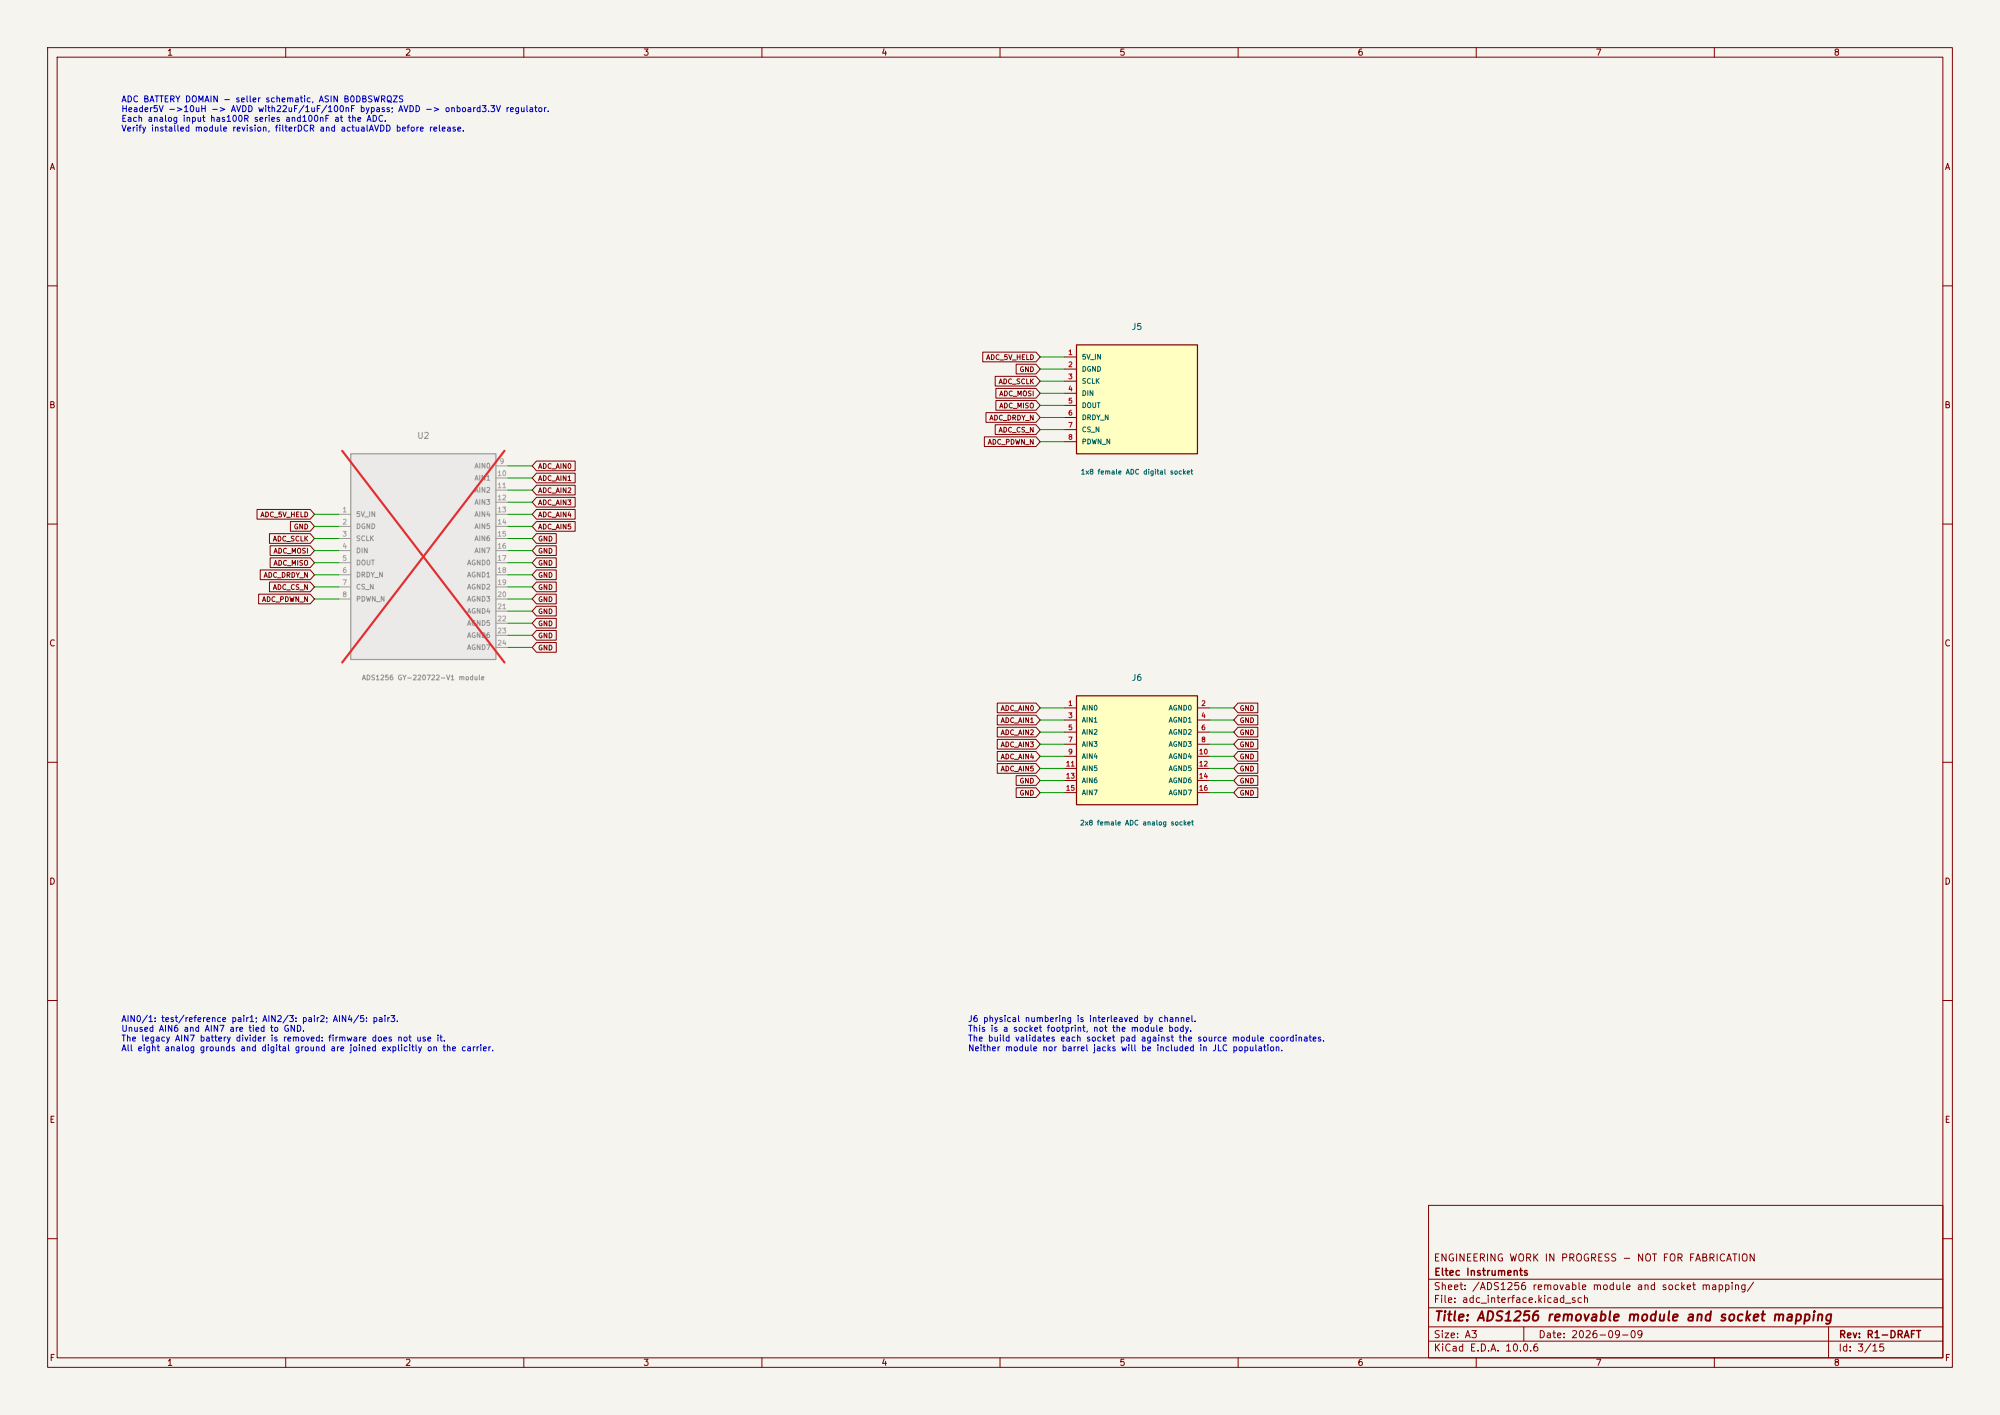
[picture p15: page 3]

ADC BATTERY DOMAIN - seller schematic, ASIN B0DBSWRQZS Header5V ->10uH -> AVDD with22uF/1uF/100nF bypass; AVDD -> onboard3.3V regulator. Each analog input has100R series and100nF at the ADC. Verify installed module revision, filterDCR and actualAVDD before release.

GND AIN0/1: test/reference pair1; AIN2/3: pair2; AIN4/5: pair3. Unused AIN6 and AIN7 are tied to GND. The legacy AIN7 battery divider is removed: firmware does not use it. All eight analog grounds and digital ground are joined explicitly on the carrier.

2x8 female ADC analog socket

J6 physical numbering is interleaved by channel. This is a socket footprint, not the module body. The build validates each socket pad against the source module coordinates. Neither module nor barrel jacks will be included in JLC population.

ENGINEERING WORK IN PROGRESS - NOT FOR FABRICATION
Eltec Instruments
Sheet: /ADS1256 removable module and socket mapping/
File: adc_interface.kicad_sch
Title: ADS1256 removable module and socket mapping

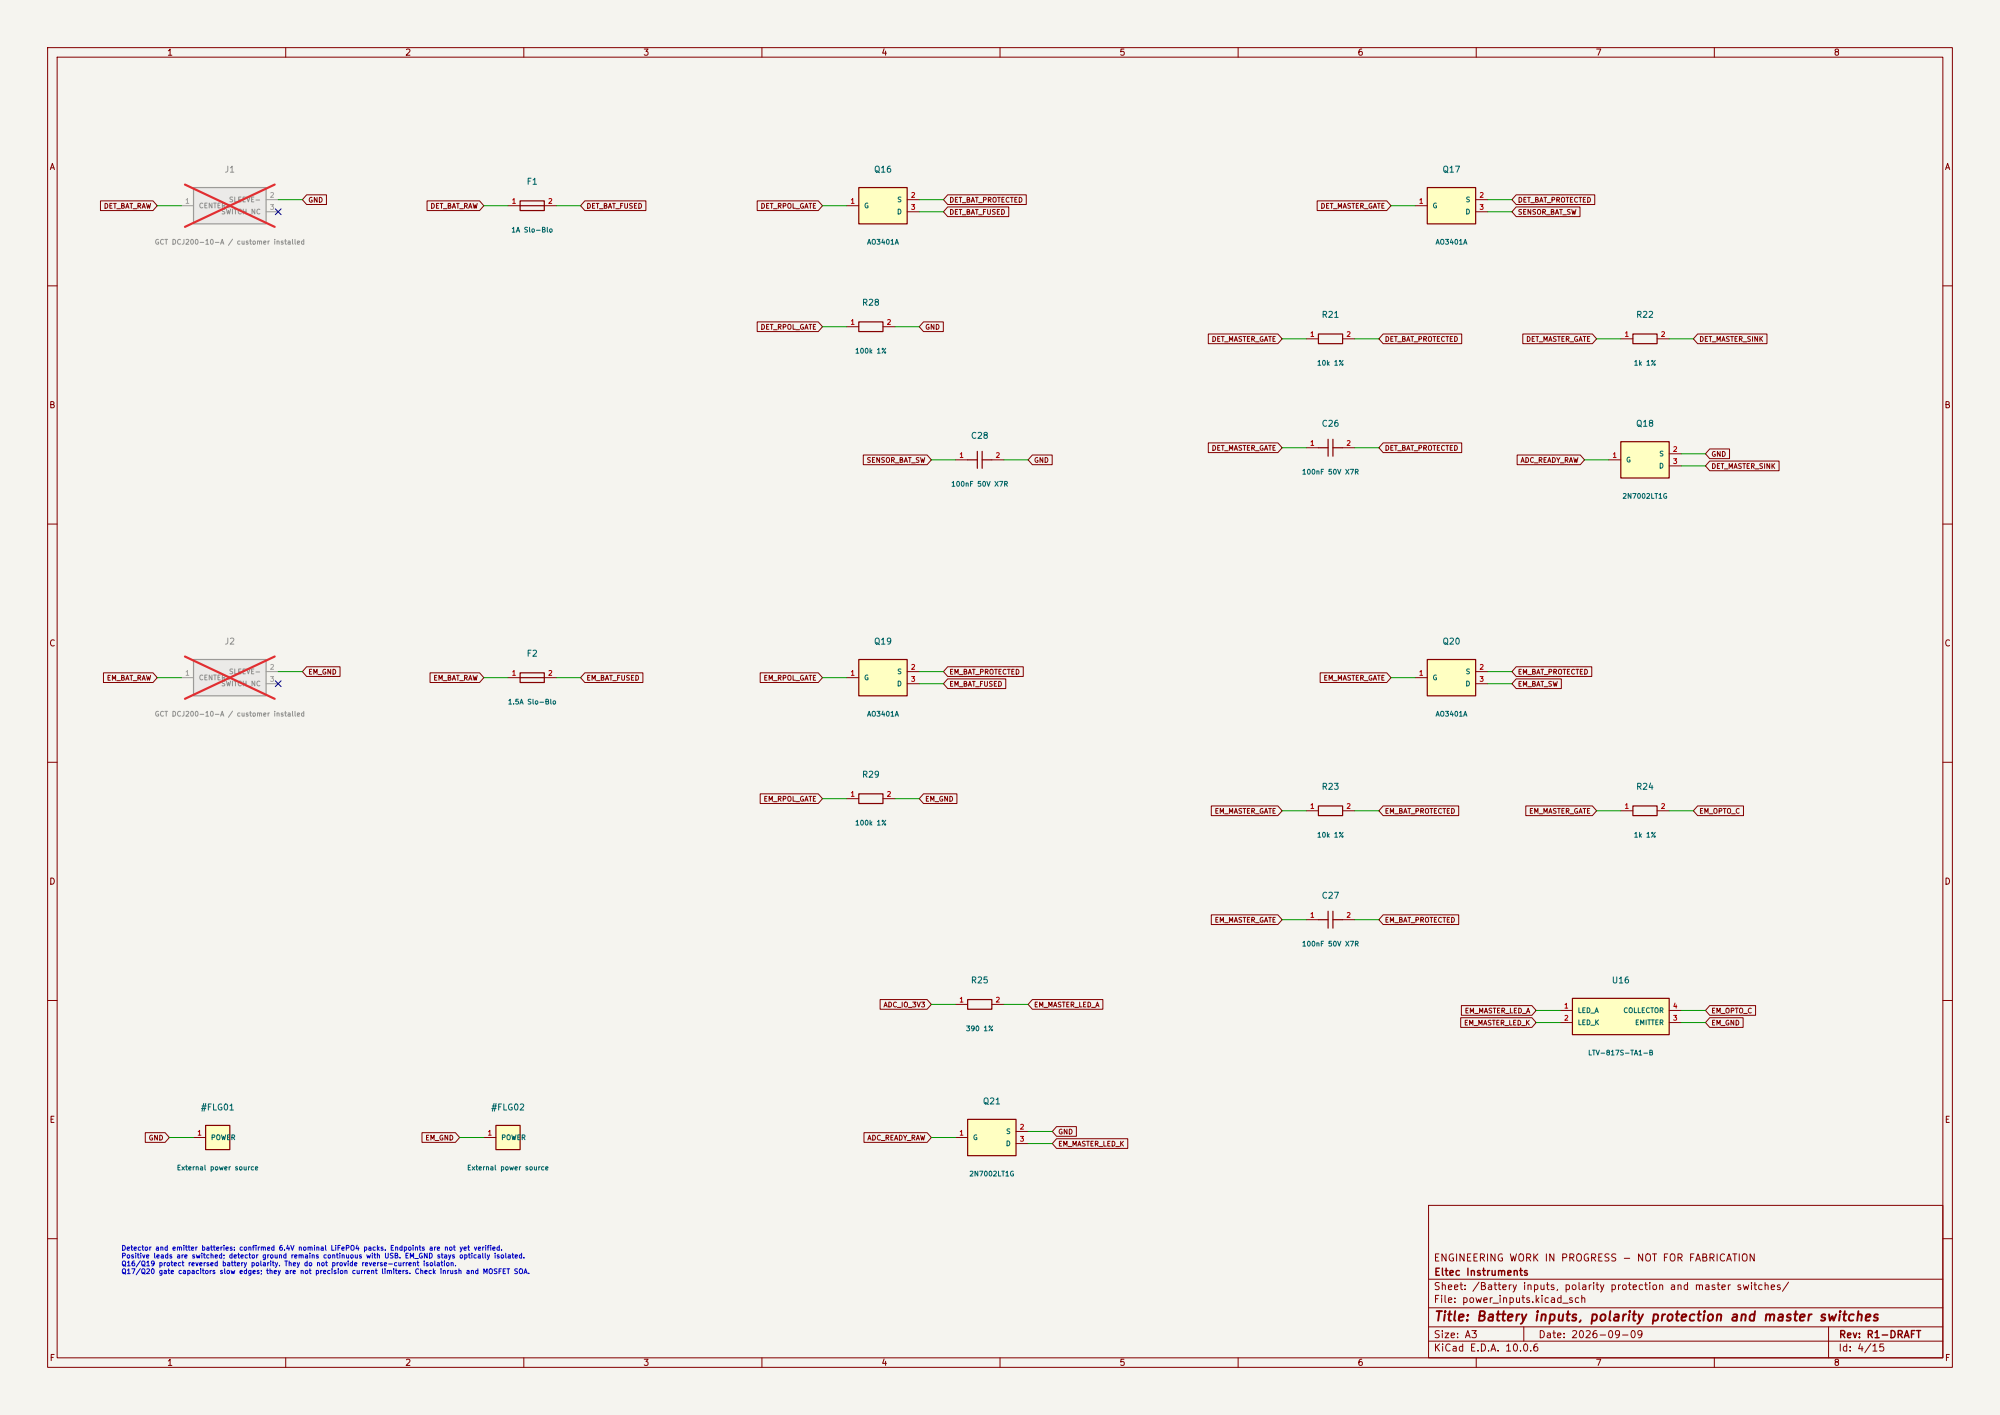
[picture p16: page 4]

Detector and emitter batteries: confirmed 6.4V nominal LiFePO4 packs. Endpoints are not yet verified. Positive leads are switched; detector ground remains continuous with USB. EM_GND stays optically isolated. Q16/Q19 protect reversed battery polarity. They do not provide reverse-current isolation. Q17/Q20 gate capacitors slow edges; they are not precision current limiters. Check inrush and MOSFET SOA.

ENGINEERING WORK IN PROGRESS - NOT FOR FABRICATION
Eltec Instruments
Sheet: /Battery inputs, polarity protection and master switches/
File: power_inputs.kicad_sch
Title: Battery inputs, polarity protection and master switches

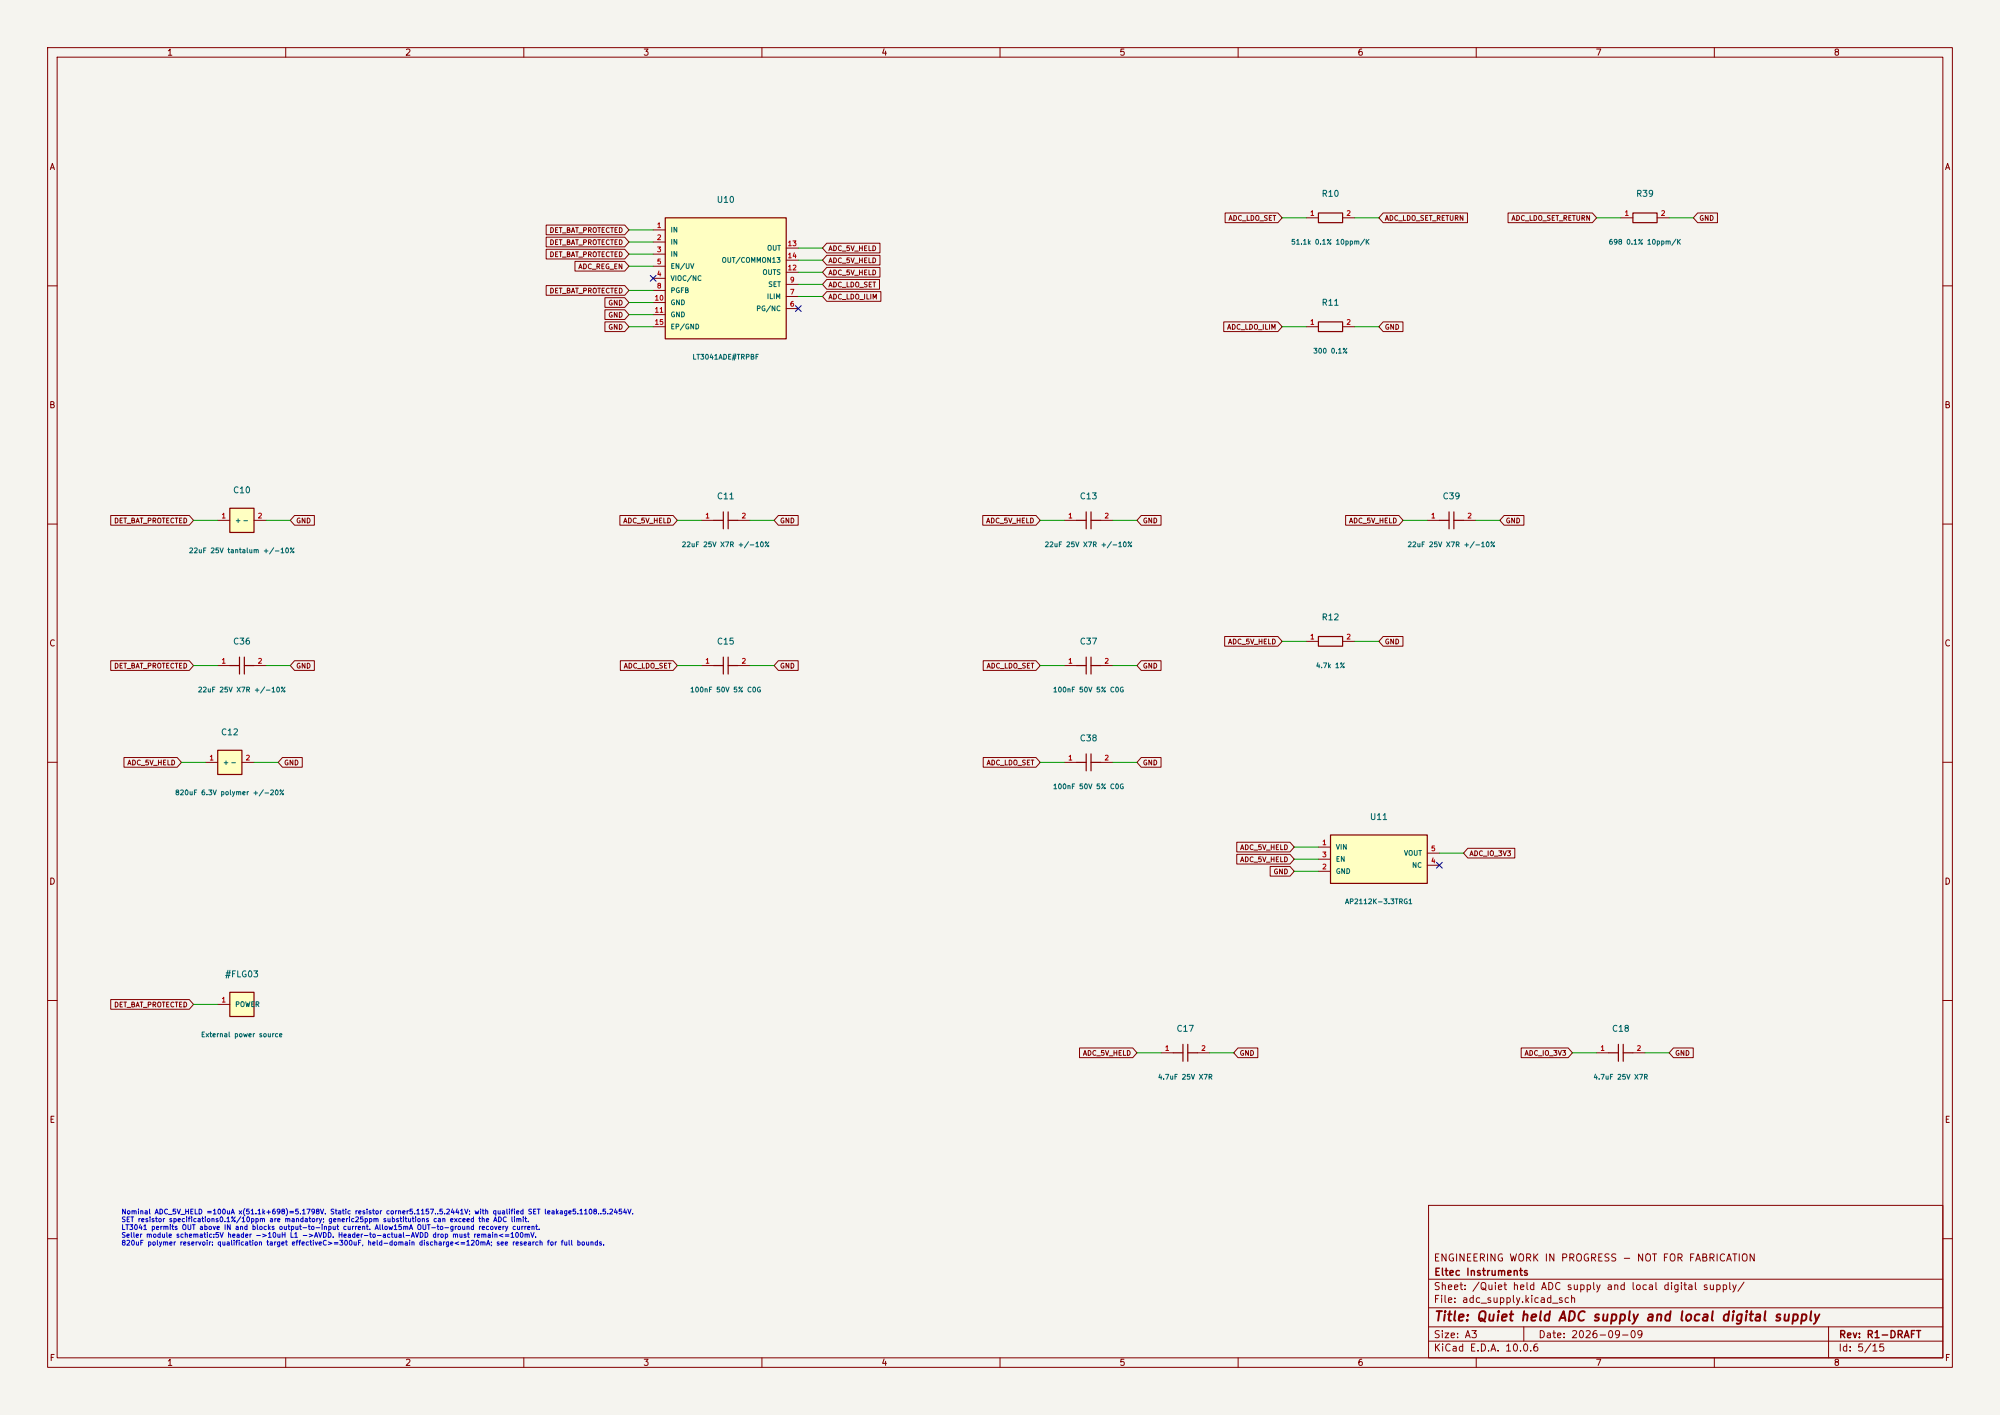
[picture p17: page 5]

Nominal ADC_5V_HELD =100uA x(51.1k+698)=5.1798V. Static resistor corner5.1157..5.2441V; with qualified SET leakage5.1108..5.2454V. SET resistor specifications0.1%/10ppm are mandatory; generic25ppm substitutions can exceed the ADC limit. LT3041 permits OUT above IN and blocks output-to-input current. Allow15mA OUT-to-ground recovery current. Seller module schematic:5V header ->10uH L1 ->AVDD. Header-to-actual-AVDD drop must remain<=100mV. 820uF polymer reservoir: qualification target effectiveC>=300uF, held-domain discharge<=120mA; see research for full bounds.
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

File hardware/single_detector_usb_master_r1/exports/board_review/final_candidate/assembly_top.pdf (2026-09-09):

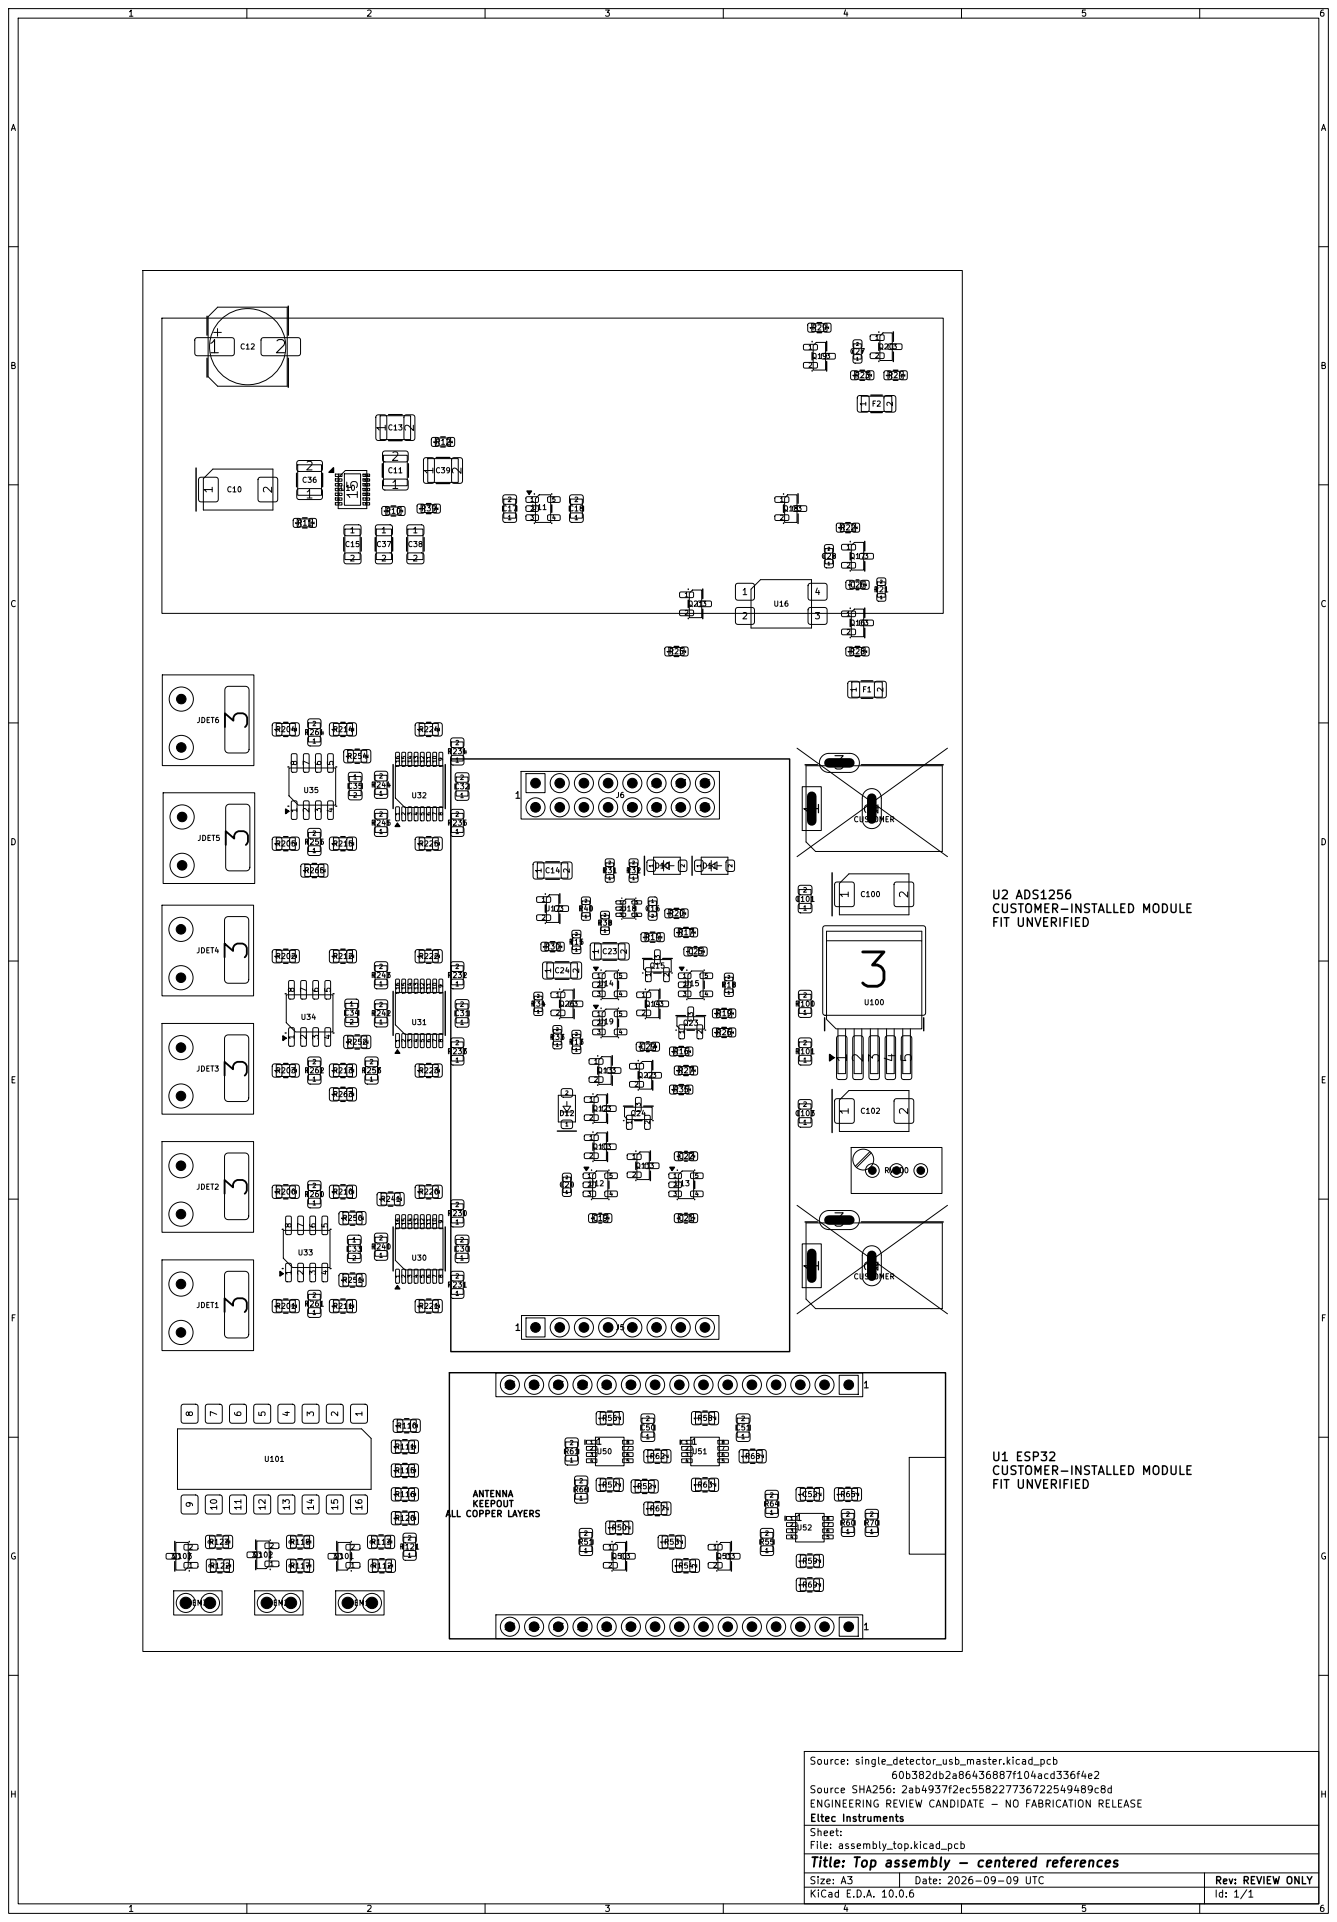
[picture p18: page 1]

Source SHA256: 2ab4937f2ec558227736722549489c8d
ENGINEERING REVIEW CANDIDATE - NO FABRICATION RELEASE
Eltec Instruments
Sheet:
File: assembly_top.kicad_pcb
Title: Top assembly - centered references

Size: A3 | Rev: REVIEW ONLY
KiCad E.D.A. 10.0.6 | Id: 1/1

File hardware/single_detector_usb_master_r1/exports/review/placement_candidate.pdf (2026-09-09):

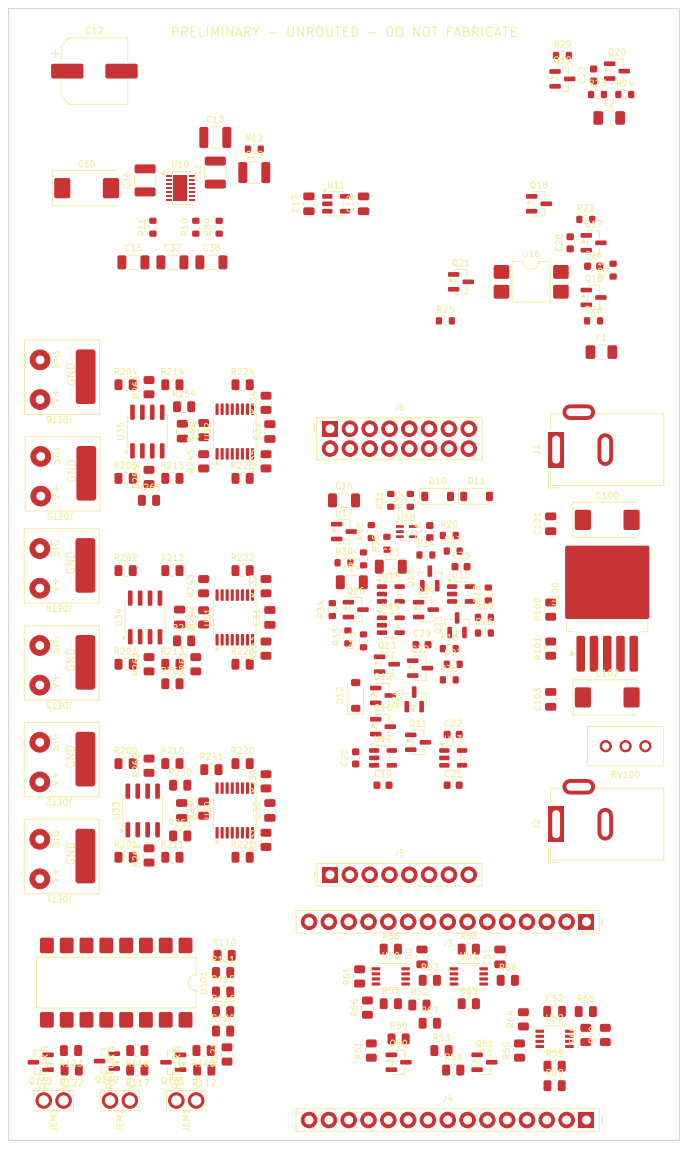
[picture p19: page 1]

PRELIMINARY - UNROUTED - DO NOT FABRICATE U33

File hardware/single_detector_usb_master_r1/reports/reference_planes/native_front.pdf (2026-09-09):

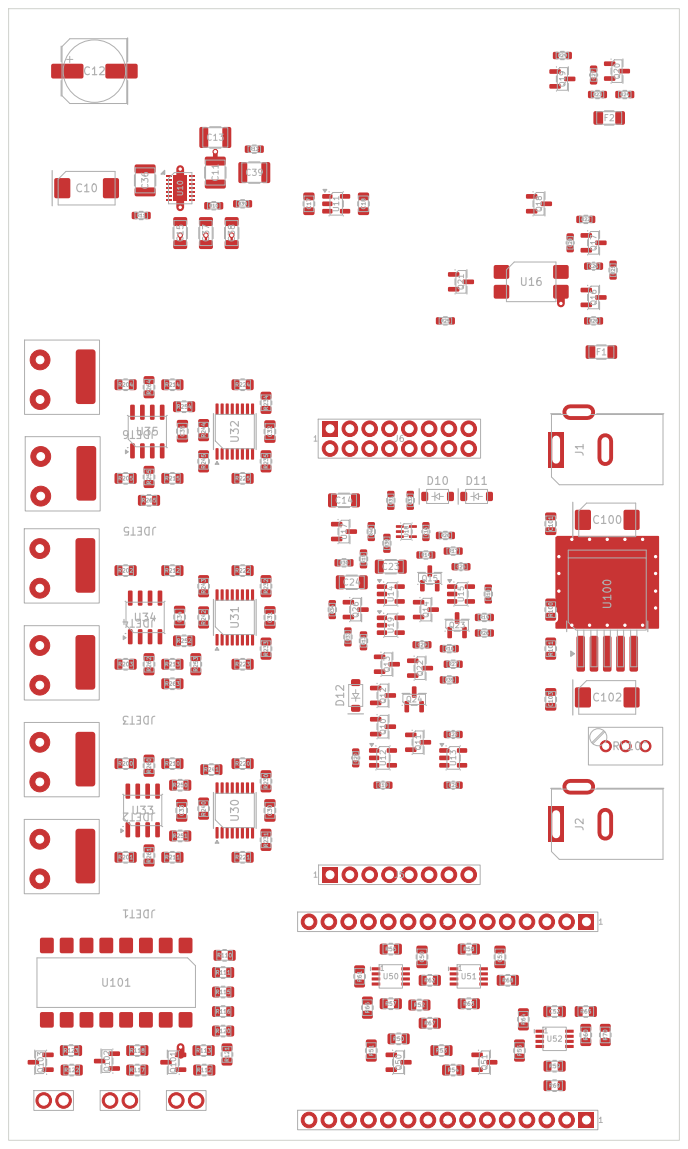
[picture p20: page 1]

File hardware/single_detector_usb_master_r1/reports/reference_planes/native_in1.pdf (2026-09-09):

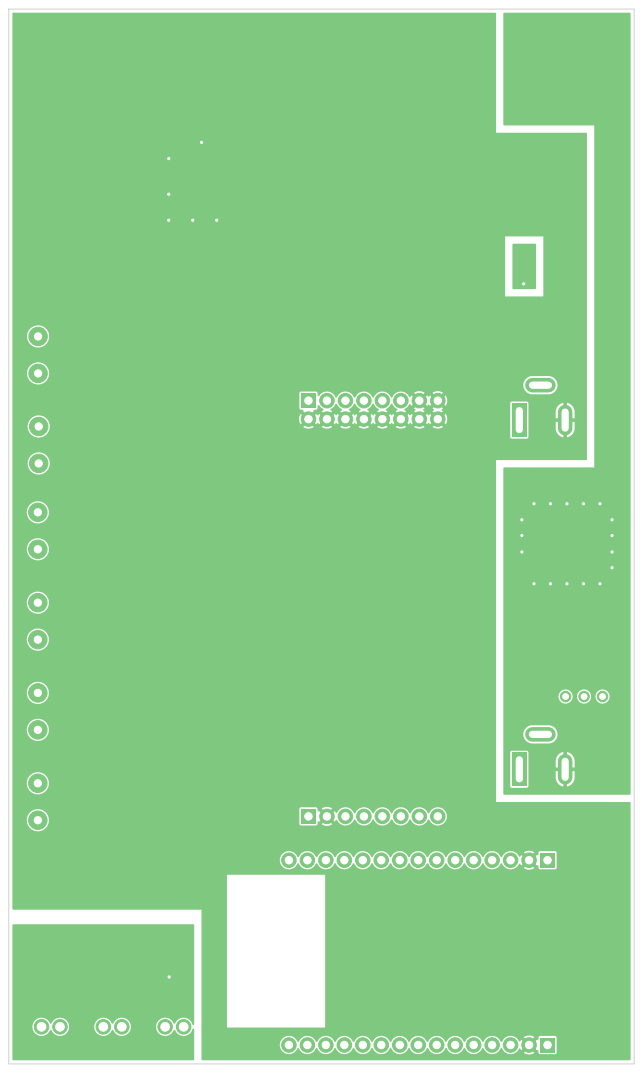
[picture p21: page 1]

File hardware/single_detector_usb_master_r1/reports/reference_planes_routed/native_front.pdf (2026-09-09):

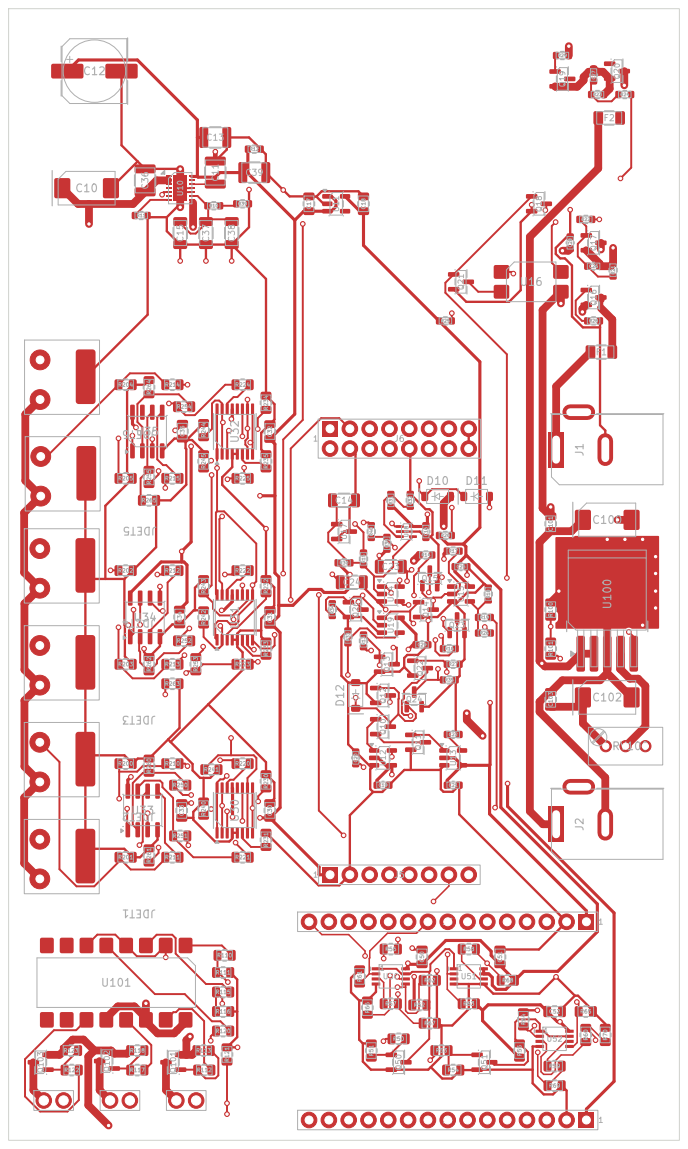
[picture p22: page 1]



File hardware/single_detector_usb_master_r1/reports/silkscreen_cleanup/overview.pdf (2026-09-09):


PRELIMINARY - UNROUTED - DO NOT FABRICATE U33

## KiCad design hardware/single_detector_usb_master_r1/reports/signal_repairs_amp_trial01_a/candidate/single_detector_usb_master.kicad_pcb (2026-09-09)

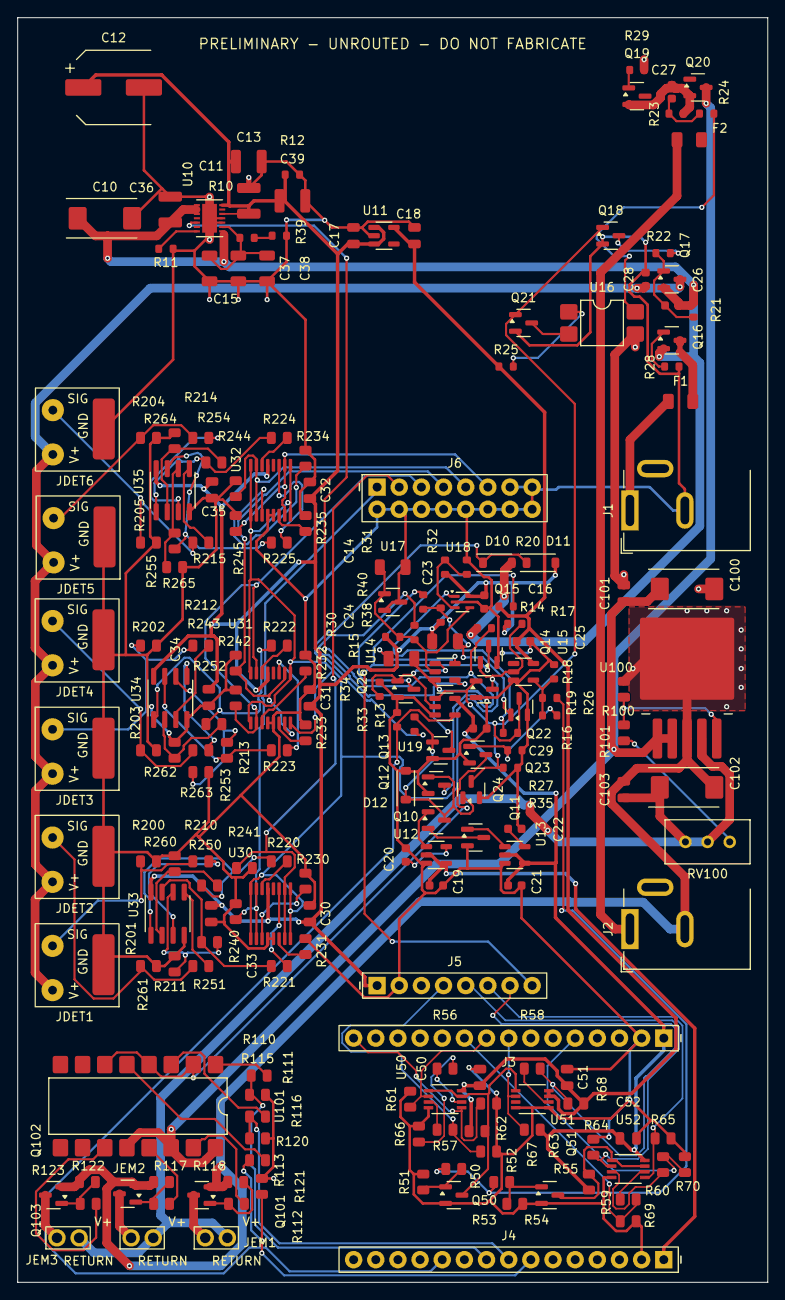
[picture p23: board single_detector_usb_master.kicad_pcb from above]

Board: 4 copper layers, 86.0 x 145.0 mm, 206 parts (0 on the bottom side), 128 nets.

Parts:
C10: 22uF 25V tantalum +/-10%; CP_EIA-7343-31_Kemet-D
C11, C13, C36, C39: 22uF 25V X7R +/-10%; C_1210_3225Metric
C12: 820uF 6.3V polymer +/-20%; CP_Elec_8x11.9
C14, C23, C24: 100nF 5% C0G; C_1206_3216Metric
C15, C37, C38: 100nF 50V 5% C0G; C_1206_3216Metric
C16, C19, C21, C25, C26, C27, C28, C29: 100nF 50V X7R; C_0603_1608Metric
C17, C18: 4.7uF 25V X7R; C_0805_2012Metric
C20, C22: 10nF 5% C0G; C_0603_1608Metric
C30, C31, C32, C33, C34, C35, C50, C51, C52: 100nF 50V X7R; C_0805_2012Metric
C100, C102: 22uF 25V 10% TPS; CP_EIA-7343-31_Kemet-D
C101, C103: 100nF 50V X7R 10%; C_0805_2012Metric
D10, D11: 1N4148W; D_SOD-123
D12: BZT52C6V8GW; D_SOD-123
F1: 1A Slo-Blo; Fuse_1206_3216Metric
F2: 1.5A Slo-Blo; Fuse_1206_3216Metric
J1, J2: GCT DCJ200-10-A / customer installed; BarrelJack_GCT_DCJ200_10_A
J3: 1x15 female socket - row A; Socket_Kinghelm_1x15_P2.54_H8.5
J4: 1x15 female socket - row B; Socket_Kinghelm_1x15_P2.54_H8.5
J5: 1x8 female ADC digital socket; Socket_Kinghelm_1x08_P2.54_H8.5
J6: 2x8 female ADC analog socket; Socket_FG_2x08_P2.54_H8.5
JDET1, JDET3, JDET5: TEST; Detector_Wire_Lands
JDET2, JDET4, JDET6: REFERENCE; Detector_Wire_Lands
JEM1: EMITTER 1; Emitter_Wire_Lands
JEM2: EMITTER 2; Emitter_Wire_Lands
JEM3: EMITTER 3; Emitter_Wire_Lands
Q10, Q11, Q23, Q24, Q26: AO3414; SOT-23
Q12, Q13, Q14, Q15, Q18, Q21: 2N7002LT1G; SOT-23
Q16, Q17, Q19, Q20: AO3401A; SOT-23
Q22, Q101, Q102, Q103: AO3400A; SOT-23
Q50, Q51: MMBT3904LT1G; SOT-23
R10: 51.1k 0.1% 10ppm/K; R_0603_1608Metric
R11: 300 0.1%; R_0603_1608Metric
R12, R20: 4.7k 1%; R_0603_1608Metric
R13, R18, R21, R23, R33, R38: 10k 1%; R_0603_1608Metric
R14, R15, R27, R28, R29, R34, R35: 100k 1%; R_0603_1608Metric
R16, R17, R22, R24: 1k 1%; R_0603_1608Metric
R19: 0; R_0603_1608Metric
R25: 390 1%; R_0603_1608Metric
R26: 100 1%; R_0603_1608Metric
R30: 1.5k 1%; R_0603_1608Metric
R31: 221 0.1% 25ppm/K; R_0603_1608Metric
R32: 1.00k 0.1% 25ppm/K; R_0603_1608Metric
R39: 698 0.1% 10ppm/K; R_0603_1608Metric
R40: 150 1%; R_0603_1608Metric
R50, R52, R53, R55, R61, R62, R63, R64, R65, R66, R67, R68, R69, R70: 10k; R_0805_2012Metric
R51, R54: 100k; R_0805_2012Metric
R56, R57, R58, R59, R60: 33; R_0805_2012Metric
R100: 210R 1% 0.125W; R_0805_2012Metric
R101: 7R5 1% 0.125W; R_0805_2012Metric
R110, R115, R120: 240R 1% 0.125W; R_0805_2012Metric
R111, R116, R121: 100k 1% 0.125W; R_0805_2012Metric
R112, R117, R122: 100R 1% 0.125W; R_0805_2012Metric
R113, R118, R123: 10k 1% 0.125W; R_0805_2012Metric
R200, R201, R202, R203, R204, R205: 100k 1%; R_0805_2012Metric
R210, R211, R212, R213, R214, R215: 10k 1%; R_0805_2012Metric
R220, R221, R222, R223, R224, R225, R250, R251, R252, R253, R254, R255: 499R 0.1%; R_0805_2012Metric
R230, R231, R232, R233, R234, R235: 220R 1%; R_0805_2012Metric
R240, R241, R242, R243, R244, R245, R260, R261, R262, R263, R264, R265: 33k 0.1%; R_0805_2012Metric
RV100: 1k 25-turn 0.5W; Potentiometer_Bourns_3296W_Vertical
U10: LT3041ADE#TRPBF; DFN-14-1EP_3x4mm_P0.5mm_EP1.7x3.3mm
U11: AP2112K-3.3TRG1; SOT-23-5
U12: TPS3840PL42DBVR; SOT-23-5
U13: TPS3840PL30DBVR; SOT-23-5
U14: TPS3840PL34DBVR; SOT-23-5
U15: SN74LVC1G14DBVR; SOT-23-5
U16: LTV-817S-TA1-B; SMDIP-4_W7.62mm
U17: LM4050AIM3-4.1/NOPB; SOT-23
U18: TLV3601DCKR; SOT-353_SC-70-5
U19: SN74LVC1G132DBVR; SOT-23-5
U30, U31, U32: ADG4613BRUZ; TSSOP-16_4.4x5mm_P0.65mm
U33, U34, U35: OPA2325IDR; SOIC-8_3.9x4.9mm_P1.27mm
U50, U51, U52: SN74LVC2G125DCTR; TI_DCT0008A_SSOP8
U100: LT1963AEQ#PBF; TO-263-5_TabPin3
U101: LTV-847S; SMDIP-16_W9.53mm

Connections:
ADC_5V_HELD: C11.1, C12.1, C13.1, C16.1, C17.1, C23.1, C30.1, C31.1, C32.1, C33.1, C34.1, C35.1, C39.1, D11.2, J5.1, R12.1, R17.1, R30.1, R31.1, R38.1, U10.12, U10.13, U10.14, U11.1, U11.3, U18.5, U30.13, U31.13, U32.13, U33.8, U34.8, U35.8
ADC_AIN0: J6.1, R240.1, U30.2, U30.15
ADC_AIN1: J6.3, R241.1, U30.7, U30.10
ADC_AIN2: J6.5, R242.1, U31.2, U31.15
ADC_AIN3: J6.7, R243.1, U31.7, U31.10
ADC_AIN4: J6.9, R244.1, U32.2, U32.15
ADC_AIN5: J6.11, R245.1, U32.7, U32.10
ADC_COMPARATOR_GOOD: R16.1, U18.1
ADC_CS_DRV: R58.1, U51.6
ADC_CS_N: J5.7, R58.2, R68.1
ADC_DRDY_N: J5.6, R65.1, U52.5
ADC_IF_OE_N: Q50.3, R52.2, U50.1, U50.7, U51.1
ADC_IO_3V3: C18.1, C25.1, C50.1, C51.1, R20.1, R25.1, R52.1, R68.2, U11.5, U15.5, U50.8, U51.7, U51.8
ADC_LDO_ILIM: R11.1, U10.7
ADC_LDO_SET: C15.1, C37.1, C38.1, R10.1, U10.9
ADC_LDO_SET_RETURN: R10.2, R39.1
ADC_MISO: J5.5, R64.1, U52.2
ADC_MOSI: J5.4, R57.2, R67.1
ADC_MOSI_DRV: R57.1, U50.3
ADC_OE_BASE: Q50.1, R50.2, R51.1
ADC_PDWN_N: J5.8, Q15.3, R20.2
ADC_RAIL_SENSE: R31.2, R32.1, U18.3
ADC_READY_RAW: Q14.1, Q18.1, Q21.1, Q23.3, Q24.3, R16.2, R35.1, U19.1
ADC_REG_EN: Q12.3, R14.2, U10.5
ADC_SCLK: J5.3, R56.2, R66.1
ADC_SCLK_DRV: R56.1, U50.6
ADC_SUP_CT: C24.1, U14.5
ADC_SUP_MR_N: Q13.3, R15.2, U14.4
AMP_FB0: R250.2, R260.1, U33.2
AMP_FB1: R251.2, R261.1, U33.6
AMP_FB2: R252.2, R262.1, U34.2
AMP_FB3: R253.2, R263.1, U34.6
AMP_FB4: R254.2, R264.1, U35.2
AMP_FB5: R255.2, R265.1, U35.6
AMP_IN0: R210.2, U33.3
AMP_IN1: R211.2, U33.5
AMP_IN2: R212.2, U34.3
AMP_IN3: R213.2, U34.5
AMP_IN4: R214.2, U35.3
AMP_IN5: R215.2, U35.5
AMP_OUT0: R220.1, R250.1, U33.1
AMP_OUT1: R221.1, R251.1, U33.7
AMP_OUT2: R222.1, R252.1, U34.1
AMP_OUT3: R223.1, R253.1, U34.7
AMP_OUT4: R224.1, R254.1, U35.1
AMP_OUT5: R225.1, R255.1, U35.7
AMP_SERIES0: R220.2, U30.14
AMP_SERIES1: R221.2, U30.11
AMP_SERIES2: R222.2, U31.14
AMP_SERIES3: R223.2, U31.11
AMP_SERIES4: R224.2, U32.14
AMP_SERIES5: R225.2, U32.11
CLAMP_GND0: R230.1, U30.3
CLAMP_GND1: R231.1, U30.6
CLAMP_GND2: R232.1, U31.3
CLAMP_GND3: R233.1, U31.6
CLAMP_GND4: R234.1, U32.3
CLAMP_GND5: R235.1, U32.6
DET_BAT_FUSED: F1.2, Q16.3
DET_BAT_PROTECTED: C10.1, C26.2, C36.1, D10.2, Q16.2, Q17.2, R14.1, R21.2, U10.1, U10.2, U10.3, U10.8
DET_BAT_RAW: F1.1, J1.1
DET_MASTER_GATE: C26.1, Q17.1, R21.1, R22.1
DET_MASTER_SINK: Q18.3, R22.2
DET_RPOL_GATE: Q16.1, R28.1
EMIT1_LOW: JEM1.2, Q101.3
EMIT2_LOW: JEM2.2, Q102.3
EMIT3_LOW: JEM3.2, Q103.3
EM_ADJ: R100.1, R101.2, U100.5
EM_BAT_FUSED: F2.2, Q19.3
EM_BAT_PROTECTED: C27.2, Q19.2, Q20.2, R23.2
EM_BAT_RAW: F2.1, J2.1
EM_BAT_SW: C100.1, C101.1, Q20.3, U100.1, U100.2, U101.12, U101.14, U101.16
EM_GATE1: Q101.1, R112.2, R113.1
EM_GATE1_DRIVE: R112.1, U101.15
EM_GATE2: Q102.1, R117.2, R118.1
EM_GATE2_DRIVE: R117.1, U101.13
EM_GATE3: Q103.1, R122.2, R123.1
EM_GATE3_DRIVE: R122.1, U101.11
EM_GND: C100.2, C101.2, C102.2, C103.2, J2.2, Q101.2, Q102.2, Q103.2, R29.2, R100.2, R113.2, R118.2, R123.2, U16.3, U100.3
EM_LED1_A: R110.2, U101.1
EM_LED2_A: R115.2, U101.3
EM_LED3_A: R120.2, U101.5
EM_LED_ENABLE_GATE: Q22.1, R26.2, R27.1
EM_LED_RETURN: Q22.3, U101.2, U101.4, U101.6
EM_MASTER_GATE: C27.1, Q20.1, R23.1, R24.1
EM_MASTER_LED_A: R25.2, U16.1
EM_MASTER_LED_K: Q21.3, U16.2
EM_OPTO_C: R24.2, U16.4
EM_REG: C102.1, C103.1, JEM1.1, JEM2.1, JEM3.1, RV100.1, RV100.2, U100.4
EM_RPOL_GATE: Q19.1, R29.1
EM_TRIM_TOP: R101.1, RV100.3
ENABLE_AND_MID: Q10.2, Q11.3
ESP_3V3: C21.1, C29.1, C52.1, J3.1, R55.1, R63.2, U13.2, U13.4, U19.5, U52.8
ESP_CS_N: J3.8, R63.1, U51.2
ESP_DRDY: J3.5, R60.2, R70.1
ESP_DRDY_DRV: R60.1, U52.3
ESP_EMIT1: J4.9, R110.1, R111.1
ESP_EMIT2: J4.8, R115.1, R116.1
ESP_EMIT3: J4.7, R120.1, R121.1
ESP_IF_OE_N: Q51.3, R55.2, U52.1, U52.7
ESP_MISO: J3.10, R59.2, R69.1
ESP_MISO_DRV: R59.1, U52.6
ESP_MOSI: J3.15, R62.1, U50.5
ESP_OE_BASE: Q51.1, R53.2, R54.1
ESP_POWER_NOT_READY: J4.11, R33.1, U19.4
ESP_SCLK: J3.9, R61.1, U50.2
ESP_SUP_CT: C22.1, U13.5
ESP_VALID_RAW: Q11.1, U13.1
GND: C10.2, C11.2, C12.2, C13.2, C14.2, C15.2, C16.2, C17.2, C18.2, C19.2, C20.2, C21.2, C22.2, C24.2, C25.2, C28.2, C29.2, C30.2, C31.2, C32.2, C33.2, C34.2, C35.2, C36.2, C37.2, C38.2, C39.2, C50.2, C51.2, C52.2, D12.2, J1.2, J3.2, J4.2, J5.2, J6.2, J6.4, J6.6, J6.8, J6.10, J6.12, J6.13, J6.14, J6.15, J6.16, JDET1.3, JDET2.3, JDET3.3, JDET4.3, JDET5.3, JDET6.3, Q11.2, Q12.2, Q13.2, Q14.2, Q15.2, Q18.2, Q21.2, Q22.2, Q23.2, Q24.2, Q26.2, Q50.2, Q51.2, R11.2, R12.2, R18.2, R27.2, R28.2, R32.2, R33.2, R34.2, R35.2, R39.2, R51.2, R54.2, R61.2, R62.2, R64.2, R65.2, R66.2, R67.2, R69.2, R70.2, R111.2, R116.2, R121.2, R200.2, R201.2, R202.2, R203.2, R204.2, R205.2, R230.2, R231.2, R232.2, R233.2, R234.2, R235.2, R240.2, R241.2, R242.2, R243.2, R244.2, R245.2, R260.2, R261.2, R262.2, R263.2, R264.2, R265.2, U10.10, U10.11, U10.15, U11.2, U12.3, U13.3, U14.3, U15.3, U17.2, U17.3, U18.2, U19.3, U30.4, U30.5, U31.4, U31.5, U32.4, U32.5, U33.4, U34.4, U35.4, U50.4, U51.4, U51.5, U52.4
ISOLATE_H: Q14.3, Q15.1, R17.2, U15.2, U30.1, U30.8, U30.9, U30.16, U31.1, U31.8, U31.9, U31.16, U32.1, U32.8, U32.9, U32.16
MASTER_PERMIT: R18.1, R19.1, R26.1, U15.4
OFF_BIAS_RAIL: D10.1, D11.1, R13.1
POWER_OFF_NODE: D12.1, Q10.3, Q12.1, Q13.1, Q24.1, R13.2
PWR_REF_4V096: C14.1, R15.1, R30.2, U14.2, U17.1, U18.4
REF_CLAMP_RELEASE: Q26.3, R40.2
REF_NOT_READY: C23.2, Q23.1, R38.2, R40.1
REF_READY_RAW: Q26.1, R34.1, U14.1, U19.2
SENSOR0: JDET1.2, R200.1, R210.1
SENSOR1: JDET2.2, R201.1, R211.1
SENSOR2: JDET3.2, R202.1, R212.1
SENSOR3: JDET4.2, R203.1, R213.1
SENSOR4: JDET5.2, R204.1, R214.1
SENSOR5: JDET6.2, R205.1, R215.1
SENSOR_BAT_SW: C28.1, JDET1.1, JDET2.1, JDET3.1, JDET4.1, JDET5.1, JDET6.1, Q17.3
SPI_PERMIT: R19.2, R50.1, R53.1
USB_PRESENT_5V: C19.1, J4.1, U12.2, U12.4
USB_SUP_CT: C20.1, U12.5
USB_VALID_RAW: Q10.1, U12.1

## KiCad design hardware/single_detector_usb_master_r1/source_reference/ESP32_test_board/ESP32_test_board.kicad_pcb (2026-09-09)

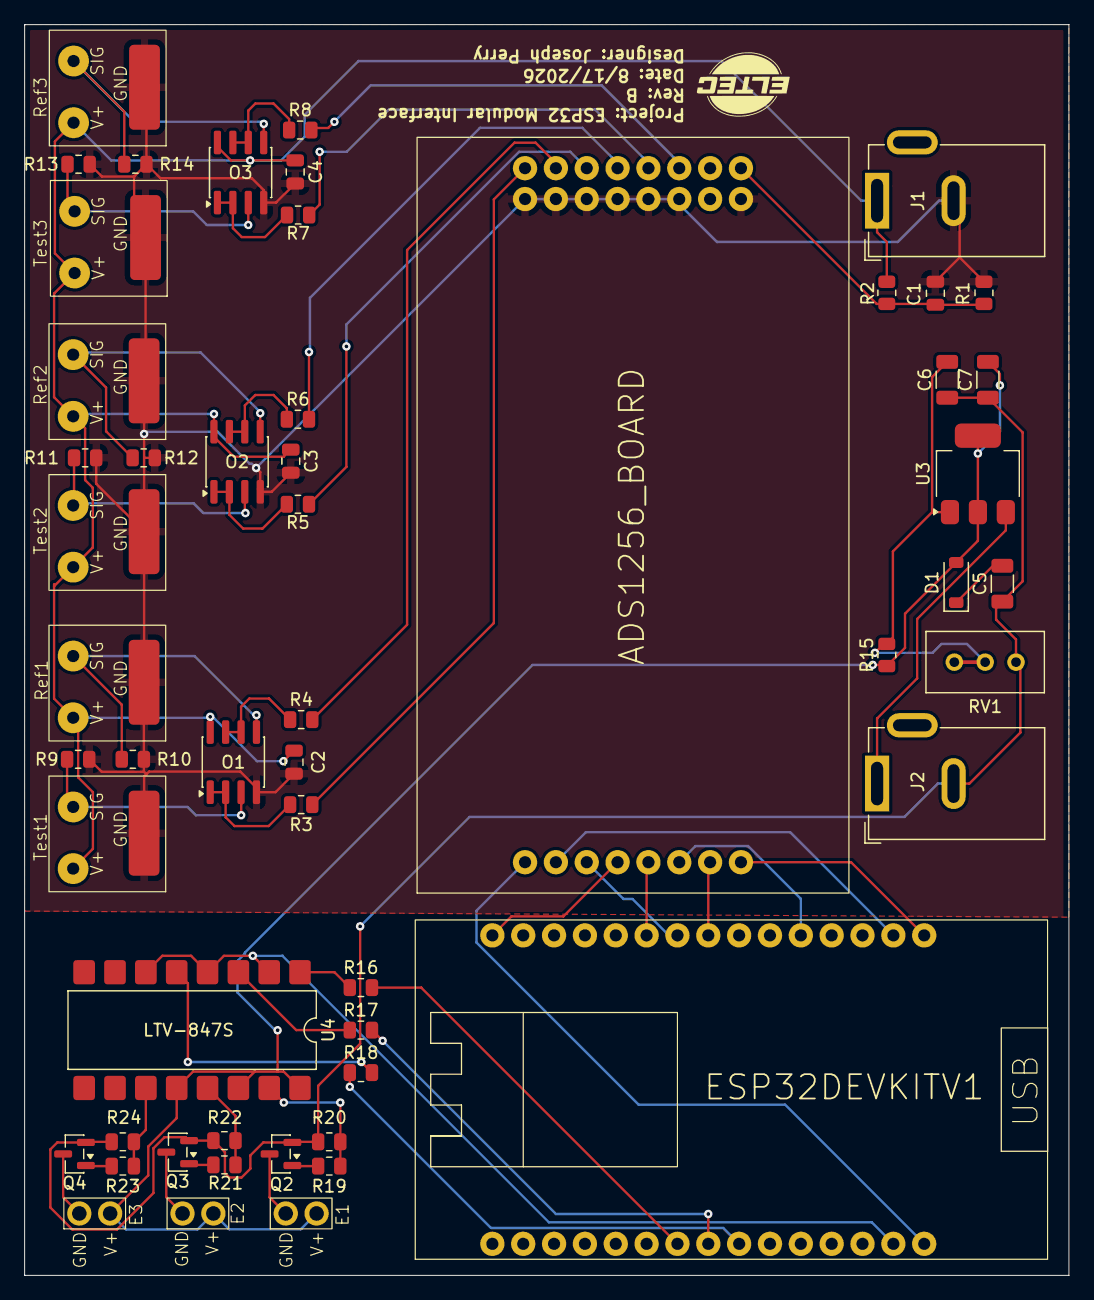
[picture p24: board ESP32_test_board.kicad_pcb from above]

Board: 2 copper layers, 86.0 x 103.0 mm, 54 parts (0 on the bottom side), 50 nets.

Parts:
C1, C2, C3, C4: 100nF; C_0805_2012Metric
C5, C6, C7: 22uF; C_1206_3216Metric
D1: 1N4007; D_SOD-123
E1, E2, E3: IR-56; Emitter
J1, J2: Barrel_Jack_MountingPin; BarrelJack_GCT_DCJ200-10-A_Horizontal
O1, O2, O3: OPA2196; SOIC-8_3.9x4.9mm_P1.27mm
Q2, Q3, Q4: AO3400A; SOT-23
R1: 100K; R_0805_2012Metric
R2: 300k; R_0805_2012Metric
R3, R4, R5, R6, R7, R8: 500; R_0805_2012Metric
R9, R10, R11, R12, R13, R14, R20, R22, R24: 100k; R_0805_2012Metric
R15: 220; R_0805_2012Metric
R16, R17, R18: 330; R_0805_2012Metric
R19, R21, R23: 100; R_0805_2012Metric
RV1: 1k POT; Potentiometer_Bourns_3296W_Vertical
Ref1, Ref2, Ref3: Sensor
Test1, Test2, Test3: Sensor
U1: ESP32DEVKITV1; ESP32_DEVKITV1
U2: ADS1256_BOARD
U3: AMS1117; SOT-223-3_TabPin2
U4: LTV-847S; SMDIP-16_W9.53mm

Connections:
unnamed: C7.2, D1.2 (A), E1.1 (V+), E2.1 (V+), E3.1 (V+), R15.1, U3.2 (VO), U4.12, U4.14, U4.16
unnamed: C5.2, D1.1 (K)
unnamed: E1.2 (GND), Q2.3 (D)
unnamed: E2.2 (GND), Q3.3 (D)
unnamed: E3.2 (GND), Q4.3 (D)
unnamed: O1.3 (+IN_A), R9.1, Test1.2 (OUTPUT)
unnamed: O1.5 (+IN_B), R10.1, Ref1.2 (OUTPUT)
unnamed: O1.1 (OUT_A), O1.2 (-IN_A), R3.2
unnamed: O1.6 (-IN_B), O1.7 (OUT_B), R4.1
unnamed: C2.1, C3.1, C4.1, J1.1, O1.8 (V+), O2.8 (V+), O3.8 (V+), R2.1, Ref1.1 (V+), Ref2.1 (V+), Ref3.1 (V+), Test1.1 (V+), Test2.1 (V+), Test3.1 (V+)
unnamed: C1.2, C2.2, C3.2, C4.2, J1.2, O1.4 (V-), O2.4 (V-), O3.4 (V-), R1.2, R9.2, R10.2, R11.2, R12.2, R13.2, R14.2, Ref1.3 (GND/CASE), Ref2.3 (GND/CASE), Ref3.3 (GND/CASE), Test1.3 (GND/CASE), Test2.3 (GND/CASE), Test3.3 (GND/CASE), U2.17 (GND0), U2.18 (GND1), U2.19 (GND2), U2.20 (GND3), U2.21 (GND4), U2.22 (GND5), U2.24 (GND7)
unnamed: O2.3 (+IN_A), R11.1, Test2.2 (OUTPUT)
unnamed: O2.5 (+IN_B), R12.1, Ref2.2 (OUTPUT)
unnamed: O2.1 (OUT_A), O2.2 (-IN_A), R5.1
unnamed: O2.6 (-IN_B), O2.7 (OUT_B), R6.1
unnamed: O3.3 (+IN_A), R13.1, Test3.2 (OUTPUT)
unnamed: O3.5 (+IN_B), R14.1, Ref3.2 (OUTPUT)
unnamed: O3.1 (OUT_A), O3.2 (-IN_A), R7.1
unnamed: O3.6 (-IN_B), O3.7 (OUT_B), R8.1
unnamed: Q2.1 (G), R19.2
unnamed: C5.1, C6.1, C7.1, J2.2, Q2.2 (S), Q3.2 (S), Q4.2 (S), R20.2, R22.2, R24.2, RV1.3
unnamed: Q3.1 (G), R21.2
unnamed: Q4.1 (G), R23.2
unnamed: R16.1, U4.1
unnamed: R17.1, U4.3
unnamed: R18.2, U4.5
unnamed: R19.1, R20.1, U4.15
unnamed: R21.1, R22.1, U4.13
unnamed: R23.1, R24.1, U4.11
unnamed: U1.1 (3V3), U2.8 (PDWN)
unnamed: U1.5 (D4), U2.6 (DRDY)
unnamed: U1.8 (D5), U2.7 (CS)
unnamed: U1.9 (D18), U2.3 (SCLK)
unnamed: U1.10 (D19), U2.5 (DOUT)
unnamed: U1.15 (D23), U2.4 (DIN)
unnamed: R17.2, U1.23 (D25)
unnamed: R18.1, U1.22 (D26)
unnamed: R16.2, U1.24 (D33)
unnamed: U1.17 (GND), U4.2, U4.4, U4.6
unnamed: U1.16 (VIN), U2.1 (5V)
unnamed: R3.1, U2.9 (AIN0)
unnamed: R4.2, U2.10 (AIN1)
unnamed: R5.2, U2.11 (AIN2)
unnamed: R6.2, U2.12 (AIN3)
unnamed: R7.2, U2.13 (AIN4)
unnamed: R8.2, U2.14 (AIN5)
unnamed: C1.1, R1.1, R2.2, U2.16 (AIN7)
unnamed: U1.2 (GND), U2.2 (GND)
unnamed: C6.2, R15.2, RV1.1, RV1.2, U3.1 (ADJ)
unnamed: J2.1, U3.3 (VI)

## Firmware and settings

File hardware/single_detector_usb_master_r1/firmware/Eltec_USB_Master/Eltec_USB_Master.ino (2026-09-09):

/*
  USB-MASTER R1 REVISION FIRMWARE v3.3 - engineering candidate
  This separate derived sketch is for the new carrier with GPIO35 power status.
  The historical wiring comments below describe the source rig; use the new
  carrier schematic. AIN6/7 are grounded, BAT? is unavailable, PDWN is controlled
  by hardware, and the six detector inputs use held-supply protected buffers.
  Electrical shutdown protection does not depend on this firmware running.
  Do not flash an old carrier with this sketch: its GPIO35 is not connected.
*/
/*
  Eltec sensor test rig — ESP32 + ADS1256 firmware
  ================================================

  Replaces the LabJack T7-Pro in tech_app/v4_emitter. The Ubuntu host talks to
  this board over USB serial (500000 baud, ASCII lines) instead of the LJM
  library. Job-for-job mapping from the LabJack rig:

    LabJack T7                      ESP32 + ADS1256
    ------------------------------  ------------------------------------------
    DIO0  10 Hz / 50% PWM (gate)    PIN_PWM_GATE, software-timed 10 Hz square
    AIN0  buffered sensor, +/-1 V   ADS1256 AIN0 (single-ended vs AINCOM),
          (x10 range), 1000 Hz        PGA = 1 (+/-5 V full scale, v2.0),
          stream                      streamed at 1000 SPS. Input buffer OFF
                                      (v2.0), so the 405 M22's TP412 offset
                                      band of 0.8-3.0 V reads linearly (the
                                      old gain-2 buffered front end clipped
                                      at 2.5 V). AIN0/AIN1 are driven by
                                      low-impedance op-amp buffers, so the
                                      unbuffered input load is fine there.
    AIN1  battery via measured       ADS1256 AIN7, PGA = 1 (+/-5 V full scale).
          99.7k/99.6k divider,         CAVEAT (v2.0): with the input buffer
          +/-10 V range                OFF the unbuffered ADS1256 input loads
                                      the ~50k divider, so BAT? reads LOW and
                                      is only indicative. The current fixture
                                      (2026-08-12) does not use it anyway: the
                                      6.5 V battery drives the emitters ONLY
                                      and the 9 V sensor battery is not on
                                      AIN7 (planned: AIN6 with a >=4:1
                                      divider). NEVER feed the ADS1256 more
                                      than AVDD (+5 V)!
    (new) reference 406MCA sensor   ADS1256 AIN1, PGA = 1 (+/-5 V, v2.0).
                                      Permanently mounted in the fixture; its
                                      pk-pk response to the chopped emitter is
                                      trended over time to detect emitter aging
                                      (no absolute spec, it just has to stay
                                      constant).
    AIN2  PWM looped back as sync   Not needed as an analog channel: the ESP32
                                      generates the PWM itself, so the sync
                                      state is reported as a digital 0/1 with
                                      every streamed sample.

  Counts -> volts
  ---------------
  The ADS1256 returns a 24-bit two's-complement code. Full scale is
  +/- (2 * VREF / PGA), so:

      volts = code * (2.0 * VREF / PGA) / 8388607.0        // 2^23 - 1

  With the usual 2.5 V reference: PGA 1 -> +/-5 V, PGA 2 -> +/-2.5 V.
  Every streamed line carries BOTH the raw code and the converted volts so the
  host can verify the math.

  Serial protocol (each command and reply is one \n-terminated line)
  ------------------------------------------------------------------
    IDN?             -> ELTEC-ESP32-ADS1256,v3.2
                        (v3.2 = runtime-selectable emitter duty cycle via
                         PWM,DUTY,<percent> (1-99 %, boot default 50 %) plus
                         pwm_duty=<%> in STATUS?. Added for the 449 M18
                         frequency-tracking test (TP443), whose legacy
                         fixture chops the source with a 20/80 blade: the
                         unified app drives 5 Hz and 18 Hz at 20 % duty for
                         that model. Every other model keeps the 50 %
                         default because PWM,DUTY is never sent for them and
                         a port open resets the board. Purely additive -
                         PWM,ON/OFF/FREQ behave exactly as in v3.1 at the
                         default duty.
                         v3.1 = emitter gate moved from D25 to D33
                         (GPIO33). Boot default only - everything else is
                         identical to v3.0, and PIN,<n> still retargets at
                         runtime, so a board wired to D25 works on v3.1 by
                         sending PIN,25. The host apps send PIN,33.
                         v3.0 = the unified test-rig baseline. Functionally
                         identical to v2.1; the version bump marks the split
                         of the IR-telescope work into its own workspace
                         (C:\Users\JoseCastelblanco\Documents\Eltec_IR_Telescope,
                         firmware v2.2 with STREAM,START,BOTH) and the move to
                         ONE host application for every sensor version. The
                         unified app selects the sensor model in a dropdown
                         and programs this firmware accordingly: 405 M22 runs
                         on the boot-default v2.0 front end at 1 Hz PWM;
                         406MCA testing sends FE,V19 after connect to restore
                         that model's qualified gain-2 buffered front end and
                         stays at the 10 Hz boot-default PWM. Dual-channel
                         interleaved streaming does NOT exist in this build -
                         flash the telescope workspace's v2.2 for that.
                         v2.1 = runtime-selectable ADS1256 front end via the
                         FE,... commands below, so the v1.9 (gain 2, buffer
                         ON) and v2.0 (gain 1, buffer OFF) configurations can
                         be A/B-compared on the same board without reflashing
                         - e.g. to check whether a noise reading depends on
                         the front end. Boots in the v2.0 configuration, and
                         opening the USB port resets the board, so hosts that
                         do not send FE commands (the 405 M22 app) always get
                         v2.0 behavior. Not persisted.
                         v2.0 = ADS1256 front end changed for the 405 M22
                         TP412 offset band: sensor channels AIN0/AIN1 run at
                         PGA gain 1 (+/-5 V, LSB 596 nV instead of 298 nV)
                         and the input buffer is OFF, so DC offsets to 3.0 V+
                         read linearly. WARNING: 406MCA v6/v6.1 rigs were
                         qualified on v1.9's gain-2 buffered front end - keep
                         them on v1.9 unless their noise floors/thresholds
                         are re-verified on v2.0. BAT? accuracy also drops
                         (unbuffered input loads the resistive divider); the
                         405 M22 host disables its battery gate.
                         v1.9 = runtime-selectable emitter PWM frequency via
                         PWM,FREQ,<hz> (0.1-20 Hz). Boot default stays 10 Hz,
                         so the existing 406MCA apps behave identically without
                         sending the new command; the 405 M22 tools send
                         PWM,FREQ,1 for that model's 1 Hz drive.
                         v1.8 = battery scaling uses the measured divider:
                         99.7 kOhm upper / 99.6 kOhm lower. The 100 nF filter
                         capacitor across the lower resistor does not change
                         the DC divider ratio. v1.4 = gate confirmed on
                         GPIO25/D25 - the perf board
                         is soldered to D25, earlier docs saying D26 were
                         wrong - plus GATE? pad readback and RTC-hold/DAC
                         release at boot. v1.5 = PIN,2 allowed: GPIO2 is the
                         onboard blue LED, so PIN,2 + GATE,ON is a meter-free
                         check that the whole gate-drive path works. v1.6 was
                         an interim DRDY-edge fix. v1.7 also verifies the ADC
                         configuration, respects command timing, and reports
                         stream overruns. Older builds could leave the ADS1256
                         at its 30 kSPS reset default while claiming 1 kSPS.
                         Bump this string on EVERY
                         flash-relevant change so stale firmware is detectable.)
    PIN,<n>          -> OK,PIN,<n>       (retarget gate pin at runtime;
                                          allowed: 2/12/13/14/25/26/27/32/33;
                                          2 = onboard LED, visual gate test)
    STATUS?          -> STATUS,pwm=<0|1>,streaming=<0|1>,vref=<V>,rate=<SPS>,pwm_hz=<Hz>,pwm_duty=<%>
    FE?              -> FE,gain=<1|2>,buf=<0|1>,fs=<V>
                        (current sensor front end; fs = full-scale volts)
    FE,V20           -> OK,FE,gain=1,buf=0  (gain 1, buffer OFF - the v2.0
                                          405 M22 front end; boot default)
    FE,V19           -> OK,FE,gain=2,buf=1  (gain 2, buffer ON - the v1.9
                                          406MCA front end, for A/B noise
                                          comparison. CAVEAT: full scale
                                          drops to +/-2.5 V and the buffer
                                          is linear only to AVDD-2V = 3.0 V,
                                          so offsets above ~2.4 V clip -
                                          exactly why v2.0 exists. Applies
                                          to AIN7/BAT? too, like real v1.9.)
    FE,GAIN,<1|2>    -> OK,FE,...        (change only the PGA gain)
    FE,BUF,<0|1>     -> OK,FE,...        (change only the input buffer)
                        (all FE setters: rejected while streaming; the new
                         configuration is SELFCALed and read back before OK;
                         none of it is persisted - a reset returns to v2.0)
    PWM,ON           -> OK,PWM,ON        (starts the emitter drive at the
                                          current frequency; 10 Hz unless
                                          changed with PWM,FREQ)
    PWM,OFF          -> OK,PWM,OFF
    PWM,FREQ,<hz>    -> OK,PWM,FREQ,<hz> (set drive frequency, 0.1-20 Hz, at
                                          the current duty cycle. Takes effect
                                          immediately; if the PWM is running
                                          its phase is restarted. Not
                                          persisted - boots back to 10 Hz.)
    PWM,DUTY,<pct>   -> OK,PWM,DUTY,<pct> (v3.2: set the ON fraction of each
                                          period, 1-99 %. Same immediate
                                          effect/phase restart as PWM,FREQ.
                                          Not persisted - boots back to 50 %.
                                          The sync bit streamed with every
                                          sample follows the actual ON/OFF
                                          state, so a 20 % drive shows a
                                          20 % high sync.)
    GATE,ON          -> OK,GATE,ON      (hold gate steady HIGH - bring-up/debug)
    GATE,OFF         -> OK,GATE,OFF
    GATE?            -> GATE,pin=<n>,drive=<0|1>,read=<0|1>
                        (drive = level the firmware is commanding, read = the
                         actual pad level via digitalRead. drive=1/read=0
                         means the pin is being held low externally: short to
                         GND, overload, or a damaged output driver.)
    BAT?             -> BAT,<volts>      (median of 12 reads, scaled by the
                                          divider ratio back to the real Vbat)
    OFFSET?          -> OFFSET,<volts>   (median of 24 DUT-sensor reads ~3 ms
                                          apart, PWM state untouched — mirrors
                                          read_offset_voltage() in the app)
    REF?             -> REF,<volts>      (same median read on the reference
                                          sensor, AIN1)
    STREAM,START     -> STREAM,BEGIN,1000,SENSOR  then one line per sample:
                          D,<t_us>,<raw_code>,<volts>,<sync 0|1>
    STREAM,START,REF -> STREAM,BEGIN,1000,REF   (same format, but streams the
                                          reference sensor on AIN1 instead)
    STREAM,STOP      -> STREAM,END,<samples_sent>,<adc_overruns>
                        (adc_overruns must be zero for a valid measurement)
    ERR,<message>    on any bad command or hardware fault

  Wiring (30-pin ESP32 DevKit <-> blue ADS1256 module with
  5V/GND/SCLK/DIN/DOUT/DRDY/CS/PDWN header + GND/AIN0..AIN7 pairs)
  ----------------------------------------------------------------
    D18 (GPIO18)  -> SCLK        D5 (GPIO5)  -> CS
    D23 (GPIO23)  -> DIN         D4 (GPIO4)  -> DRDY (input)
    D19 (GPIO19)  -> DOUT        3V3         -> PDWN (tie high)
    VIN (5V USB)  -> 5V          GND         -> GND
    D33 (GPIO33)  -> MOSFET driver module PWM/TRIG input (emitter drive,
                     direct wire - module accepts 3.3 V logic)
    DUT sensor buffer -> AIN0, reference sensor -> AIN1,
    battery divider tap -> AIN7;
    module GND pins common with ESP32 GND and the rig ground.
    Current wiring guide: ESP32_ADS1256_Wiring_v2_0.md in this folder
    (ESP32_ADS1256_Wiring_v1_7.md matches the v1.9 firmware still used on
    406MCA rigs). ESP32_ADS1256_Wiring.docx is historical (old 9 V/AIN1
    fixture); do not use it to wire this version.
*/

#include <SPI.h>
#include "driver/gpio.h"  // gpio_hold_dis / gpio_reset_pin (GPIO33 is RTC-capable)

// ---------------------------------------------------------------- pins ----
static const int PIN_CS = 5;
static const int PIN_DRDY = 4;
// USB-master R1 carrier only: ESP-powered status gate, LOW means ready.
// GPIO35 is input-only and is never assigned to an emitter output.
static const int PIN_POWER_NOT_READY = 35;
static volatile bool powerFaultSeen = true;
static volatile uint32_t carrierPowerEpoch = 0;

static bool carrierPowerReady() {
  return digitalRead(PIN_POWER_NOT_READY) == LOW;
}

static void IRAM_ATTR onCarrierPowerChange() {
  // Latch the delivered rising edge even if a short pulse has already ended.
  powerFaultSeen = true;
  carrierPowerEpoch++;
}
// Default emitter-gate pin. Moved to D33 (GPIO33) on 2026-08-25; the
// perf-board wire moves with it (it was on D25 from 2026-07-13). GPIO33 is
// RTC-capable (hold latch released at attach) but NOT a DAC pin, unlike
// GPIO25/26. Changeable at runtime with PIN,<n>. Not persisted.
static int pinGate = 33;
// SCLK=18 / MISO=19 / MOSI=23 are the ESP32 VSPI defaults used by SPI.begin().

// ------------------------------------------------- rig constants ----------
// Mirror the Python app (eltec_406mca_emitter_tester.py / eltec_406mca_tester.py)
// Boot default. Changeable at runtime with PWM,FREQ,<hz> (405 M22 uses 1 Hz).
static const float PWM_DEFAULT_FREQUENCY_HZ = 10.0f;  // DEFAULT_EMITTER_PWM_FREQUENCY_HZ
static const float PWM_MIN_FREQUENCY_HZ = 0.1f;
static const float PWM_MAX_FREQUENCY_HZ = 20.0f;
// v3.2: duty cycle (ON fraction of each period). Boot default 50 % - the
// historical fixed drive. Changeable at runtime with PWM,DUTY,<pct> (the 449
// M18 test uses 20 % to mimic its legacy fixture's 20/80 chopper blade).
static const float PWM_DEFAULT_DUTY_PERCENT = 50.0f;
static const float PWM_MIN_DUTY_PERCENT = 1.0f;
static const float PWM_MAX_DUTY_PERCENT = 99.0f;
static const float SAMPLE_RATE_HZ = 1000.0f;   // DEFAULT_SAMPLE_RATE_HZ
static const int OFFSET_READ_SAMPLES = 24;     // OFFSET_READ_SAMPLES
static const int OFFSET_READ_DELAY_MS = 3;     // OFFSET_READ_DELAY_S
static const int BATTERY_READ_SAMPLES = 12;    // BATTERY_READ_SAMPLES
static const int BATTERY_READ_DELAY_MS = 5;    // BATTERY_READ_DELAY_S
// Measured installed divider values. R_TOP runs from battery+ to the AIN7 tap;
// R_BOTTOM runs from the tap to ground. The 100 nF capacitor in parallel with
// R_BOTTOM filters noise but has no effect on the steady-state voltage ratio.
static const float BATTERY_DIVIDER_R_TOP_OHMS = 99700.0f;
static const float BATTERY_DIVIDER_R_BOTTOM_OHMS = 99600.0f;
static const float BATTERY_DIVIDER_RATIO =
    (BATTERY_DIVIDER_R_TOP_OHMS + BATTERY_DIVIDER_R_BOTTOM_OHMS) /
    BATTERY_DIVIDER_R_BOTTOM_OHMS;  // 2.001004016...

// ------------------------------------------------- ADS1256 setup ----------
static const float ADS_VREF = 2.5f;            // on-board reference of the module
// v2.0: gain 1 so the 405 M22's 0.8-3.0 V TP412 offset band (plus noise
// excursions above it) reads linearly on AIN0/AIN1. LSB doubles to 596 nV -
// still ~168 counts per 0.1 mV stability threshold.
// v2.1: these became runtime state so FE,V19 / FE,V20 can A/B-compare the
// two qualified front ends without reflashing. Boot defaults = v2.0; not
// persisted (any reset - including the DTR toggle when a host opens the
// port - returns to v2.0).
static uint8_t pgaSensor = 0;                  // code 0 -> gain 1 -> +/-5 V (AIN0 DUT + AIN1 ref)
static bool adsBufferOn = false;               // ADS1256 STATUS BUFEN (v1.9 = on, v2.0 = off)
static const uint8_t PGA_BATTERY = 0;          // code 0 -> gain 1 -> +/-5 V   (AIN7)
static const uint8_t MUX_SENSOR = 0x08;        // AINP = AIN0, AINN = AINCOM (DUT sensor)
static const uint8_t MUX_REF = 0x18;           // AINP = AIN1, AINN = AINCOM (reference sensor)
static const uint8_t MUX_BATTERY = 0x78;       // AINP = AIN7, AINN = AINCOM (battery divider)
static const uint8_t DRATE_1000SPS = 0xA1;     // datasheet code for 1000 SPS

// ADS1256 command bytes
static const uint8_t CMD_WAKEUP = 0x00, CMD_RDATA = 0x01, CMD_RREG = 0x10,
                     CMD_WREG = 0x50, CMD_SELFCAL = 0xF0, CMD_SYNC = 0xFC,
                     CMD_RESET = 0xFE;
// Registers
static const uint8_t REG_STATUS = 0x00, REG_MUX = 0x01, REG_ADCON = 0x02,
                     REG_DRATE = 0x03;

static const SPISettings ADS_SPI(1500000, MSBFIRST, SPI_MODE1);

// ------------------------------------------------- state ------------------
static bool pwmOn = false;
static bool pwmLevel = false;
static uint32_t pwmNextToggleUs = 0;
static float pwmFrequencyHz = PWM_DEFAULT_FREQUENCY_HZ;
static float pwmDutyPercent = PWM_DEFAULT_DUTY_PERCENT;
// ON and OFF durations of one period in us, derived from frequency and duty
// (50 ms / 50 ms at 10 Hz 50 %; 40 ms / 160 ms at 5 Hz 20 %). Recomputed by
// pwmRecomputeTimings() whenever either setting changes.
static uint32_t pwmOnUs = (uint32_t)(500000.0f / PWM_DEFAULT_FREQUENCY_HZ);
static uint32_t pwmOffUs = (uint32_t)(500000.0f / PWM_DEFAULT_FREQUENCY_HZ);

static volatile bool streaming = false;
static uint32_t streamCount = 0;
static bool streamPowerFault = false;
static uint32_t streamPowerEpoch = 0;
static uint8_t streamMux = MUX_SENSOR;   // which channel STREAM,START points at
static uint8_t streamPga = 0;            // latched from pgaSensor at STREAM,START
// DRDY is an active-low level. A GPIO interrupt latches each real falling edge
// so Serial.printf() cannot make loop() miss the short HIGH phase between ADC
// conversions. If a second conversion arrives before the previous one was
// consumed, record an overrun: the data register only retains the newest value,
// so the host must reject that capture rather than silently use missing data.
static volatile bool streamSampleReady = false;
static volatile uint32_t streamSampleTimestampUs = 0;
static volatile uint32_t streamDrdyOverruns = 0;
static char lineBuf[48];
static uint8_t lineLen = 0;

// Boot heartbeat: repeat the READY/ERR banner every 2 s until the host sends
// its first command, so a serial monitor opened late still shows signs of life.
static bool adsOk = false;
static bool gotFirstCommand = false;
static uint32_t nextHelloMs = 0;
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
void loop() {
  carrierPowerService();
  pwmService();
  serialService();
  carrierPowerService();

  if (!gotFirstCommand && !streaming && (int32_t)(millis() - nextHelloMs) >= 0) {
    if (adsOk) Serial.println("READY,ELTEC-ESP32-ADS1256");
    else Serial.println("ERR,ADS1256 not responding (check wiring/DRDY)");
    nextHelloMs = millis() + 2000;
  }

  // Streaming: consume each interrupt-latched ADS1256 falling edge once. The
  // short critical section prevents an edge between testing and clearing the
  // ready flag from being lost; SPI and serial work remain outside it.
  if (streaming) {
    bool sampleReady;
    uint32_t sampleTimestampUs;
    noInterrupts();
    sampleReady = streamSampleReady;
    sampleTimestampUs = streamSampleTimestampUs;
    streamSampleReady = false;
    interrupts();
    if (sampleReady) {
      int32_t raw = adsReadData();
      if (powerFaultSeen || !carrierPowerReady()) {
        carrierPowerService();
        return;
      }
      float volts = countsToVolts(raw, streamPga);
      Serial.printf("D,%lu,%ld,%.6f,%d\n",
                    (unsigned long)sampleTimestampUs, (long)raw, volts,
                    (pwmOn && pwmLevel) ? 1 : 0);
      streamCount++;
    }
  }
}

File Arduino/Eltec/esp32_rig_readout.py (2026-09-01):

"""
Eltec 406MCA emitter rig - ESP32 + ADS1256 host-side readout.

Companion to Eltec.ino. Talks to the ESP32 over USB serial and mirrors the
LabJack device wrapper the tester app used (offset read, battery read, PWM
control, 1000 Hz waveform stream with sync bit).

Works unchanged on Windows AND Linux/Xubuntu - pyserial abstracts the port:
    Windows:  ports look like COM5           (CH340/CP210x driver)
    Xubuntu:  ports look like /dev/ttyUSB0   (driver is built into the kernel;
              if you get "permission denied" run:
                  sudo usermod -a -G dialout $USER
              then log out and back in)

Install (both platforms):
    pip install pyserial          # or on Ubuntu: sudo apt install python3-serial

Usage:
    python3 esp32_rig_readout.py ports                 # list serial ports
    python3 esp32_rig_readout.py bat                   # battery voltage
    python3 esp32_rig_readout.py offset                # sensor DC offset (PWM off)
    python3 esp32_rig_readout.py pwm on|off            # emitter drive
    python3 esp32_rig_readout.py stream -s 5 -o cap.csv  # raw capture to CSV
    python3 esp32_rig_readout.py ref --set-baseline    # record the reference
                                                      # sensor's known-good level
    python3 esp32_rig_readout.py ref                   # re-measure it and compare
                                                      # (emitter health check)
    python3 esp32_rig_readout.py test --skip-ref       # guided sequence without
                                                      # optional AIN1 reference:
                                                      # battery -> offset -> PWM on
                                                      # -> warmup -> AIN0 capture
                                                      # -> sensitivity analysis
    python3 esp32_rig_readout.py noisecmp              # emitter-off noise, captured
                                                      # back-to-back on the v2.0
                                                      # (gain 1, unbuffered) AND
                                                      # v1.9 (gain 2, buffered)
                                                      # front ends - shows whether
                                                      # a noise figure depends on
                                                      # the front end (fw v2.1+)
    add --fe v19 (or --fe v20) to stream/test/ref/offset to run that
    measurement on the other front end (firmware v2.1+; the board resets
    back to the v2.0 front end whenever the port closes)
    add --port COM5 (or --port /dev/ttyUSB0) to skip auto-detection

Reference sensor / emitter health:
    A second 406MCA is permanently mounted in the fixture on AIN1. It has no
    absolute spec - what matters is that its pk-pk response to the chopped
    emitter stays CONSTANT over the emitter's life. Record a baseline once with
    a known-good emitter (`ref --set-baseline`); every later `ref` or `test`
    run compares against it and flags drift (warn/fail thresholds below).
"""

from __future__ import annotations

import argparse
import csv
import json
import re
import statistics
import sys
import time
from dataclasses import dataclass
from pathlib import Path

try:
    import serial
    from serial.tools import list_ports
except ImportError:
    sys.exit("pyserial is not installed. Run:  pip install pyserial")

BAUD = 500000
MIN_FIRMWARE_VERSION = (1, 7)

# Installed battery-divider measurements. The upper resistor runs from
# battery+ to the AIN7 tap; the lower resistor runs from the tap to ground.
# Firmware v1.8+ uses this ratio natively. For v1.7 boards, the host corrects
# the old nominal x2 result by ACTUAL/NOMINAL so readings stay accurate before
# and after a firmware update. The 100 nF capacitor across the lower resistor
# filters noise but does not affect the DC ratio.
BATTERY_DIVIDER_R_TOP_OHMS = 99_700.0
BATTERY_DIVIDER_R_BOTTOM_OHMS = 99_600.0
BATTERY_DIVIDER_FILTER_CAPACITANCE_F = 100e-9
BATTERY_DIVIDER_RATIO = (
    BATTERY_DIVIDER_R_TOP_OHMS + BATTERY_DIVIDER_R_BOTTOM_OHMS
) / BATTERY_DIVIDER_R_BOTTOM_OHMS
LEGACY_FIRMWARE_BATTERY_DIVIDER_RATIO = 2.0
CALIBRATED_DIVIDER_FIRMWARE_VERSION = (1, 8)

# Mirror the tester app's rig constants (eltec_406mca_emitter_tester.py).
SAMPLE_RATE_HZ = 1000.0
PWM_FREQUENCY_HZ = 10.0               # firmware boot default (406MCA drive)
# Runtime-selectable drive (firmware v1.9+): the 405 M22 sensor is specified
# at 1 Hz, so its checks run with --freq 1. Range enforced by the firmware.
PWM_FREQ_FIRMWARE_VERSION = (1, 9)
PWM_MIN_FREQUENCY_HZ = 0.1
PWM_MAX_FREQUENCY_HZ = 20.0
# Runtime-selectable duty cycle (firmware v3.2+): the ON fraction of each
# period. The board boots at 50 % - the historical drive for the 405 M22 and
# 406MCA models, which is what they are calibrated on. The 449 M18 app drives
# 20 % to imitate the TP443 fixture's 20/80 chopper blade, so a bench session
# reproducing that drive needs the same 20 %. Not persisted: any reset
# (including opening the port) returns the board to 50 %.
PWM_DUTY_FIRMWARE_VERSION = (3, 2)
PWM_DEFAULT_DUTY_PERCENT = 50.0
PWM_MIN_DUTY_PERCENT = 1.0
PWM_MAX_DUTY_PERCENT = 99.0
# Runtime-selectable ADS1256 front end (firmware v2.1+): lets the v2.0
# (gain 1, buffer OFF) and v1.9 (gain 2, buffer ON) configurations be
# A/B-compared on the same board without reflashing - e.g. to check whether
# a noise reading depends on the front end. NOT persisted: any board reset
# (including simply opening the serial port) returns it to v2.0, so the
# switch is only meaningful within one session (--fe / noisecmp).
FE_FIRMWARE_VERSION = (2, 1)
FE_PRESETS = {
    "v20": "gain 1, buffer OFF, +/-5 V full scale (v2.0 / 405 M22, boot default)",
    "v19": "gain 2, buffer ON, +/-2.5 V full scale (v1.9 / 406MCA)",
}
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

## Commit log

2026-06-08 Organize 406MCA tester files
    [406MCA_SNR_Group_Summary.csv]
2026-07-01 Reorganize 406MCA apps and analysis tools
    [406MCA_SNR_Group_Summary.csv]
2026-07-13 Add Arduino/Eltec ESP32 rig sketch and readout scripts
    Include the ESP32 rig code (Eltec.ino), Python readout/waveform
    scripts, wiring doc, and rig notes so they are versioned with the
    406MCA tester project.
2026-07-14 Add v4 emitter tester app and analysis
    v4 is the same emitter rig, measurement engine, and CSV schema as v3
    with an Eltec-branded animated UI, fast/validation/full capture modes,
    and explicit "is it plugged in?" wiring guards. Includes the v4 tech
    app, v4 analysis scripts, and README documentation for v4.
2026-07-16 Improve v6 ESP32 tester reliability
2026-08-10 Add v6.1 ESP32 tester and failure calibration tools
    [esp32_backend.py, esp32_rig_readout.py, live_waveform.py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]
2026-08-18 Unify the tech app behind a sensor-version selector; split out IR telescope
    The rig now has ONE production application, tech_app/eltec_rig ("Eltec Test
    Rig"): a selector GUI with a sensor-version dropdown that launches the chosen
    model's qualified tester unchanged. Model 405 M22 (1 Hz, TP412) and Model
    406 MCA (10 Hz) ship today; sensor_versions.py is a registry built to grow.
    Each model keeps its own test flow, thresholds, per-batch filter-setup
    dropdowns, CSV format, and results folders. Windows and Xubuntu launchers
    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
    [405M22_Data_new_fixture.csv.xlsx, 405M22_Data_old_fixture.xlsx]
2026-08-24 Eltec Test Rig v2.0: skip queue, attempt log, footer action bar
    Technician UI (both models, m405m22 and m406mca):
    - Footer is now the action bar: Back, Measure skipped (N), Skip part
    (amber), Re-measure (moved out of the tools row), Save + Exit Batch,
    Save + Next Sensor (green). Buttons one size larger; RoundButton gained
    success/warn palettes.
    - Skip part sets a part aside without spending its number: the next fresh
    number is derived from both the batch CSV and the attempt log, so a part
    is never counted twice. Skipped parts form a first-skipped-first pile
    reachable from Measure skipped (N), and fresh numbering resumes once the
    pile is empty.
    - Shorted/dead sensor: a floating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
    [eltec_406mca_scope_verification_tester.py, eltec_406mca_signal_monitor.py, eltec_406mca_signal_monitor_ui.py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]
2026-08-25 Near-limit sensitivity passes with a warning; footer fit and rename
    Both models (m405m22 and m406mca):
    - The +/-0.10 mV band around the sensitivity limit no longer produces a
    RETEST / QUARANTINE verdict. A reading there is within the margin of error
    of the x4.30 conversion factor, so the sensor passes: the result page shows
    a green "PASS - NEAR LIMIT" banner plus an amber card suggesting a
    re-measure, and the normal Save buttons record a plain PASS row. The band
    is SENSITIVITY_NEAR_LIMIT and still writes the sensitivity_gate_outcome CSV
    column; the note moves to FinalResult.warnings. OUTCOME_RETEST, the
    "RETEST - Sensitivity guard band" failure mode and the quarantine footer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
    [test_v6_integration.py]
2026-08-28 Archive firmware v3.1 (D33 gate) and v3.2 (PWM,DUTY); add flash_firmware.py one-command flasher
    v3.2 compiled 2026-08-26 (290 KB) but not yet flashed; the bench board runs v3.1. flash_firmware.py finds the Arduino IDE's bundled arduino-cli, auto-detects the CP210x port, compiles, uploads and ve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
2026-08-28 Update 405 M22 / 406 MCA backends for the GPIO33 emitter gate (firmware v3.1)
    PWM_GPIO 25 -> 33 in both backends; the app sends PIN,<n> after connect so the perf-board wire must follow. Tests and READMEs updated to expect PIN,33.
2026-08-28 Add Model 449 M18 frequency-tracking tester (TP443, calibration pending)
    New m449m18/ app in the unified selector: sensitivity at 5 Hz and 18 Hz with the legacy fixture's 20/80 duty (PWM,DUTY, firmware v3.2 required), the 18/5 ratio and the spec-4 tray flag. Sensitivity and offset gates stay disabled until K_5/K_18 are derived; every verdict is stamped CALIBRATION PENDING. Registry, selector README, glue and attempt-history suites now cover three models.
    [esp32_backend.py, stability_analysis.py, stability_calibration.py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]
2026-08-28 Add 405 M22 noise-filtering explainer report
    analysis/reports: the Markdown report, its DOCX render and the two figures from the 2026-08-20 anti-alias FIR work.
2026-08-28 Remove deprecated apps, LabJack-era analysis, and 406MCA signal monitors (preserved at tag archive/pre-cleanup-2026-08-28)
    Deleted from the working tree: tech_app/deprecated/ (v1-v4 LabJack apps, v5/v6/v6.1 ESP32 apps, the standalone 405m22_esp32 build, the eltec_rig_v1 snapshot), analysis/v1_single_sensor + v2_scope_ver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
2026-08-28 Add docs/: calibration record, data map, technician runbook, engineer handover
    docs/CALIBRATION_RECORD.md is the single home for every production constant with its code location, provenance and gate state per model (extracted from the frozen reference block of status.md and reconciled against the code). docs/DATA_MAP.md maps the out-of-repo results/evidence folders and defines the backup routine. docs/TECHNICIAN_RUNBOOK.md is the operator path; docs/ENGINEER_HANDOVER.md the engineering manual, including the copy-per-model policy, the fix-porting procedure, the firmware lifecycle and the open-work list.
2026-08-28 Rewrite the root README as the workspace hub (ESP32 rig, three sensor models)
    The previous README still described the LabJack T7-Pro 406MCA-only setup, called the retired v4 app current and hard-coded another machine's paths. The new one is the index: technician quick start, e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
2026-08-28 Replace ESP32_memory.md with a current firmware guide; clarify the wiring docs' roles
    Arduino/Eltec/README.md carries the still-true content (file inventory, which firmware on which rig, flashing, the v3.2 serial protocol, firmware facts incl. the mux-cycling warning, bench-proven troubleshooting). ESP32_memory.md had drifted (last updated 2026-07-14, pointed at apps that no longer exist). ESP32_ADS1256_Wiring_v1_7.md is renamed ESP32_ADS1256_Wiring_legacy_v1_9.md with a header that says what it is for; the v2.0 wiring doc now names itself as the unified-rig reference.
2026-08-28 Fix stale pre-unification paths and superseded statements in the app READMEs
    m405m22: run/test paths pointed at tech_app/405m22_esp32, the intro said the sensitivity gate was disabled (live since 2026-08-17), the scope-view text quoted the retired 75 uV limit and 20% allowance, and the caveats still described the quarantine band and the removed 3.5 V rail. m406mca: run/calibration/test paths pointed at tech_app/v6_1_esp32; the retest table now describes PASS - NEAR LIMIT; the hardware section distinguishes the unified rig from a legacy v1.9 rig. eltec_rig: v3.0 -> v3.x wording and the extra steps for adding a model.
2026-08-28 Add CLAUDE.md ground rules for AI-assisted sessions
2026-08-28 Fix the stale GPIO25 emitter-gate label and v3.0-baseline comments in the app code
    The emitter gate moved to GPIO33 on 2026-08-25 and both backends already send PIN,33, but the 405 M22 and 406 MCA testers still stamped EMITTER_PWM_CHANNEL = GPIO25 into the CSV pwm_channel column, rig-error messages and scope captions, and their backends' accepted-channel set rejected the GPIO33 name. Both now match the 449 M18 build (accept the 25 and 33 spellings, report GPIO{PWM_GPIO}). Module docstrings in the selector, the registry and the 405 tester no longer describe the v3.0 baseline, the disabled sensitivity gate, the 75 uV limit or the 20% window rule.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
    [esp32_backend.py]
2026-08-28 Add run_all_tests: one command for all four suites
    Runs each suite in its own interpreter (the model directories share module names and must stay isolated), prints a summary table and exits 1 on any unexpected failure. On Windows the two known environment-only 406 MCA cases are reported as such instead of failing the run; --strict counts them. .cmd/.sh wrappers honour ELTEC_PYTHON like the app launchers.
2026-08-28 Give the 406 MCA model the same Windows launchers as 405 M22 and 449 M18
    run_eltec_406mca_esp32_tester.cmd and install_windows_launcher.ps1 adapted from the 405 M22 pair with the 406's own identities (Eltec 406MCA ESP32 Tester v6.1, %LOCALAPPDATA%\eltec-406mca-esp32-v6-1, Documents\Eltec_406MCA_Test_Results\v6_1_esp32), plus the .ico the shortcut needs and the Windows section in the README.
2026-09-01 Noise edge-context fix, bench viewer upgrades, emitter comparison tool
    Noise pipeline (405 M22, hand-ported to the dormant m449m18 copy):
    decimate_antialiased now takes real neighbour samples as filter history
    instead of reflection padding, which had let out-of-band interference into
    judged windows 0/19 at only ~11-21 dB. The tester streams 0.31 s extra and
    archives both slices as left_context_v/right_context_v so saved captures
    replay to the live verdict; replot_noise_capture.py honours them. Archived
    captures are unaffected (every no-context replay is bit-identical), but
    live captures now judge their edge windows differently - a bench re-run on
    a known part is due before trusting new edge-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
    [emitter_waveform_comparison.py, esp32_rig_readout.py, live_waveform.py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]
2026-09-02 Array rig: DAQ backend (ctypes AIOUSB), simulator, bench probe, tests
    array_rig/m40623/daq_backend.py wraps AIOUSB.dll: fixture geometry
    (row-col labels -> CH0-49), own counts-to-volts scaling per range code,
    the 21-byte ADC config block, bulk-stream de-interleaving with
    partial-scan carry-over and first-conversion drop, StreamDiagnostics with
    the 1 % rate rule and pool-exhausted flag, connect retries across the
    device's firmware re-enumeration, callback streaming with a consumer
    thread, a one-shot ADC_BulkAcquire fallback, and SimulatedDaq with a
    profiled tray and injectable stream faults. daq_bench_probe.py is the
    engineering CLI (info/selfcal/config/scan/slots/floor/stream/capture/
    crosst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
    [daq_backend.py]
2026-09-02 Array rig: numpy noise port, TP120 offset classes, provisional verdicts
    array_rig/m40623/array_analysis.py re-expresses the 405 M22 emitter-off
    noise pipeline (Kaiser anti-alias FIR, decimate 1000 -> 50 SPS, per-window
    detrend, windowed pk-pk with the raw-window clip rule) in numpy for fifty
    channels; tap values are identical to the pure-Python original and the
    rest agrees to ~1e-15. The original functions are frozen verbatim in
    tests/golden_noise_reference.py (from d7526b5) as the oracle, with a drift
    test against the live 405 module. TP120 constants (offset 0.3-1.2 V,
    0.05 V settle, legacy noise 10.0-37.9 mV recorded as DMM readings, pin
    limits None until the paired lot), enum-based verdic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
2026-09-02 Array rig: 40623 tester app, selector, launchers, tests, docs
    array_rig/m40623/eltec_40623_array_tester.py: Tk-free TrayController
    (connect/self-cal, live offset polling with fail-fast HO tiles, tray lock
    with row-major sensor numbering and immediate HO rows, TP120 stabilisation
    countdown, adaptive quiet wait, 60 s fifty-channel capture with edge
    contexts and integrity retries, settled-offset verdicts, CSV with
    header compatibility, raw .npz, grid .png, tray events, re-measure) and
    the Tk GUI (5x10 tile grid, legend, PENDING banner, disabled Sensitivity
    step, drive slot). Array selector + registry, tray_history, launchers
    and installers derived from the single rig's templates, READMEs.
    ELTEC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
2026-09-02 Array rig: bench spike numbers, parity tool, replot of tray captures
    Bench spike on the real USB-AIO16-64MA (DAQ alone): config round-trips,
    self-cal 0.3 s, timer exactly 1000.000 Hz, 60 s callback stream 60000
    scans / 60.00 s with 0 pool events and 0 leftover bytes at 0.4 % CPU,
    slot 0 unsettled on floating inputs (drop stays), cal-mode ground clips
    at code 0 on unipolar ranges so the probe's floor now uses the onboard
    full-scale reference (floor: 49 uV median / 79 uV worst pk-pk in the
    judged band). Numbers in CALIBRATION_RECORD section 6; -HG and
    crosstalk checks still need the PCB.
    engineer_tools/array_noise_parity.py derives the legacy chain factor and
    proposes the pin-level noise limi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
2026-09-02 Array rig: DAQ immediate-read trigger-byte fix, ESP32-style bench readout and live viewer
    Bench verification of the USB-AIO16-64MA (driver, enumeration, vendor DLL
    source vs backend assumptions) found one blocker: the DLL's ADC_GetScan /
    ADC_GetScanV rewrite the configuration block (trigger 0x05 -> 0x04, oversample
    >= 1) and never restore it, so the tester's order (offset polling, then the
    stream) delivered 0 scans. AiousbDaq now re-asserts its block after every
    immediate read and before every stream; the tester abandons a silent stream
    after 5 s into the retry / NOT MEASURED path; StreamDiagnostics.ended_early;
    the probe's "driver V" column is documented as arithmetic, not an -HG check.
    Ne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
    [daq_backend.py]
2026-09-03 Single-detector rigs: two buttons, stall attribution, settled 406 offset, Stop saves without asking
    Carries the uncommitted 2026-09-02/03 bench work. Each change already has
    its dated CHANGELOG entry; this commit is where they land.
    - Two-button action bar and earned sensor numbers: a number is only spent
    by a PASS, so the batch CSV holds one row per TEST (number_attempt says
    which try). Stop is live mid-capture (bumps measure_token, polled by the
    capture loops through cancelled=); no load step, no Skip, no Re-measure.
    The array rig keeps its own tray flow.
    - Stream stalls are attributed: the capture stops the stream FIRST and the
    STREAM,END numbers pick a tag ([host-stall] / [boa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
    [daq_backend.py, esp32_backend.py]
2026-09-09 feat: add adaptive testing and hardware design package
    [ESP32_test_board.kicad_pcb, ESP32_test_board.kicad_sch, adc_interface.kicad_sch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]
2026-09-09 fix: track KiCad history contents
